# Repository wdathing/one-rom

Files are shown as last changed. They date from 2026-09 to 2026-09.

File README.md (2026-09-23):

# One ROM






**[One ROM](https://onerom.org) - One ROM To Rule Them All**

The most flexible and powerful ROM replacement for your retro computer.  A single Raspberry Pi
RP2350-base board in the footprint of the original chip emulates 24, 28, 32 and
40 pin mask ROMs, EPROMs, EEPROMs, bipolar PROMs and some SRAM — and then does
things the original never could.  It serves several ROM sockets at once, switches
images at runtime, reprograms over USB without leaving the socket, talks back to
the machine it is installed in, and runs your own code as plugins.

Thousands of One ROMs are installed in Commodore 64s, VIC-20s, PETs, Amigas, BBCs, Ataris, TIs, Apple IIs,
disk drives, IBM PCs, pinball machines, drum machines, synthesizers and more.  It is
open source hardware and software, it is cheap to make, and it is actively
maintained and developed.

## New to One ROM?

**Start at [onerom.org](https://onerom.org).**  That is where the project is
explained and supported:

- [What One ROM is and why](https://onerom.org) — the overview, with pictures
- [Getting started](https://onerom.org/start/) — install it, program it, use it
- [Buy one](https://onerom.org/buy) — known vendors, if you'd rather not fab
  your own
- [Program from your browser](https://onerom.org/web) — no software to install

**The rest of this README is for people who want to build One ROM, hack on it,
or build things on top of it.**  If you just want a working ROM replacement, [onerom.org](https://onerom.org) will get you there faster.

## Ways in

One ROM is designed to be extended in many different ways.

| I want to… | Start here | Steps |
|---|---|---|
| Drive a device from scripts or my own tooling | [Programming a One ROM](#programming-a-one-rom), [CLI manual](docs/CLI-MANUAL.md) | Install and run the CLI |
| Fab and assemble existing boards | [hardware/pcb](hardware/pcb/README.md) | Upload gerbers and BOM/POS files to a fab |
| Build the firmware myself | [Building from source](#building-from-source) | Use `make` or the build container |
| Use the header pins as GPIOs — reset the host, drive a line | [Driving the host](#driving-the-host--gpio-and-reset) | One command, plus a wire for host reset |
| Add support for a chip type One ROM doesn't know | [Adding a chip type](docs/ADDING-CHIP-TYPES.md) | A JSON entry plus one line of Rust or a firmware and tooling update if no existing serving algorithm fits |
| Add support for a new board revision | [rust/config/json](rust/config/json/README.md) | A new JSON file once the board is designed |
| Write a plugin — from scratch, or from a working one | [Plugins](#plugins), [firmware/ora/examples](firmware/ora/examples) | C, against a stable API |
| Talk to the retro machine from the ROM socket | [RBCP](#rbcp--talking-to-the-host-system) | 6502 and 68000 host code provided |
| Build host-side tools of my own | [Rust crates](#rust-crates) | Rust, on published crates |
| Read and test real ROM chips | [One ROM Lab](#one-rom-lab) | Flash Lab to a spare Fire board |
| Add a serving algorithm, or change how serving works | [How the firmware works](#how-the-firmware-works) | Bare metal C, PIO and DMA, plus Rust tooling |
| Design a new board | [hardware/pcb](hardware/pcb/README.md) | KiCad |

## Hardware

One ROM comes in two families:

- **Fire** — RP2350, in 24, 28, 32 and 40 pin variants, latest boards include an
  RGB NeoPixel.  All development happens for these boards.
- **Ice** — STM32F4, 24 pin only.  Legacy: still supported with 0.6.x firmware,
  but it is not being enhanced.  The 0.7.x firmware and the CLI do not
  support it.

<div align="center">
    One ROM Fire 24, 28, 32 and 40 pin boards side by side
</div>

<div align="center">
    One ROM Fire 28 with its RGB NeoPixel lit
</div>

All the design files needed to manufacture your own are in
[hardware/pcb](hardware/pcb).  Start with the
[recommended revisions](hardware/pcb/README.md#recommended-revisions) and
read the fabrication notes in the same file before you order.  Boards can be
fabbed and assembled at JLCPCB and other manufacturers cheaply.

<div align="center">
    Three One ROM Fire 24 boards serving BASIC, KERNAL and character ROMs in a Commodore 64
</div>

<p align="center"><em>Three One ROM Fire 24s in a Commodore 64, serving BASIC,
KERNAL and the character ROM.</em></p>

## Programming a One ROM

There are three tools, all doing the same job over USB:

- **[One ROM Web](https://onerom.org/web)** — browser based, nothing to install,
  the best choice for most people.
- **[One ROM CLI](https://onerom.org/cli)** — the full device tool, and what the
  examples below use ([rust/cli](rust/cli)).
- **[One ROM Studio](https://onerom.org/studio)** — native desktop GUI for
  Windows, macOS and Linux ([rust/studio](rust/studio)).

The CLI is the complete interface: everything the device can do is reachable from
it.  Full reference in the [CLI manual](docs/CLI-MANUAL.md).

Find what is connected:

```bash
onerom scan
```

Build an image from a config file and flash it:

```bash
onerom program --config onerom-config/vic20-pal.json
```

Program chips straight from the command line, without a config file, adding the
USB plugin so the device stays on the bus while it serves:

```bash
onerom program --slot file=kernal.901227-03.bin,type=2364,cs1=active-low --plugin usb
```

Build a firmware binary without touching a device, and look inside one:

```bash
onerom firmware build --config onerom-config/vic20-pal.json --board fire-24-e --output /tmp/onerom.bin
onerom firmware inspect --firmware /tmp/onerom.bin
```

Read and write the ROM image live, while the host is running from it:

```bash
onerom peek live --address 0x100 --length 64
onerom poke live --address 0x100 --byte 0xEA
```

## Driving the host — GPIO and reset

The image select and X pads are not just jumpers.  They are GPIOs, and
One ROM will drive them for you — which means the ROM socket becomes a way to
manipulate the machine it is plugged into.

Run a wire from a pad to the host's reset line and you can reset the machine
after flashing a new image:

```bash
onerom control reset --pin sel_c
```

`sel_c` is the usual choice — more boards have it than have X pads, and it is 5V
tolerant where it exists.  Any pad works, named with `--pin`.

<div align="center">
    One ROM Fire 40 in an Amiga A500 ROM socket, with a wire from its Sel_C pad to the 68000's reset line
</div>

<p align="center"><em>A One ROM Fire 40 in an Amiga A500, with <code>Sel_C</code>
wired to the 68000's reset line.</em></p>

You can see what every pin is and what it is currently doing:

```bash
onerom inspect gpio --all
onerom inspect socket --chip-type 2364 --gpio
```

The same GPIOs are available to plugins, so a plugin can drive them
autonomously — hold the host in reset until something is ready, blink an
external LED on ROM activity, or drive whatever you have wired up.

## Plugins

Serving runs entirely on PIO and DMA, so both CPU cores are free.  Plugins are
separate binaries, written in C against a stable API in
[firmware/ora](firmware/ora), that run on those cores *while serving continues*.
Two run at once.  This is how One ROM gains functionality without needing to
fork the core firmware.

There are two types, **system** and **user**.  The difference is resources, not
authorship — each is built for a different flash slot with a different RAM and
stack allocation, and you can write either.  System is intended for official One
ROM plugins such as the USB stack, but nothing stops you replacing it with your
own.

| Plugin | Type | What it does |
|---|---|---|
| [usb](plugins/system/usb) | system | The device's own USB stack, so a running One ROM stays on the bus.  Exposes the ROM being served for live read and write, and the `picobootx` extended PICOBOOT interface. |
| [host-control](plugins/user/host-control) | user | A full [RBCP](#rbcp--talking-to-the-host-system) implementation. |
| [rgb](plugins/user/rgb) | user | Cycles the NeoPixel on RGB boards.  Superseded by the USB plugin's RGB support, reached with `onerom control rgb`. |
| [activity](plugins/user/activity) | user | Blinks the status LED when the host is reading the ROM. |
| [blink](plugins/user/blink) | user | Minimal example. |

The firmware passes each plugin a lookup function at startup.  The plugin calls
it with the ID of the facility it wants, and gets back a function pointer.
Available that way: status LED and GPIO control, device and firmware metadata,
logging, memory allocation, the ROM and RAM slots being served, and the address
monitor that reports what the host is reading — which is what RBCP is built on.
New IDs are only ever added, never changed, and each plugin declares the minimum
firmware version it needs, which the firmware enforces before launching it.

Start with [plugins/README.md](plugins/README.md) for how plugins are built and
configured, [firmware/ora/api.h](firmware/ora/api.h) for the API, and
[firmware/ora/examples](firmware/ora/examples) for worked examples — including
one that patches the C64 kernal live and one that drives an LED from character
ROM accesses.

## RBCP — talking to the host system

The [ROM Bus Control Protocol](https://github.com/piersfinlayson/rom-bus-control-protocol)
is bidirectional communication between a retro machine and the ROM emulator
installed in it, carried over nothing but the ROM's own address and data buses.
No extra wiring.  The machine reads and writes ROM addresses, and One ROM
interprets them.

That opens up things a ROM socket has no business being able to do:

- remote debugging of code running on real hardware
- ROM-based bootloaders — `grub` for the C64
- dynamic patching of games and demos as they run

The device side is the [host-control](plugins/user/host-control) plugin.  The
specification lives in the RBCP repository, along with reference host
implementations for 6502 and 68000 — generic routines plus sample C64 kernal and
Amiga Kickstart bootloaders.

## One ROM Lab

[One ROM Lab](rust/lab/README.md) is alternate firmware for a spare Fire board that turns
its ROM socket into a bus reader and tester.  Flash it, connect over USB, and you
get an interactive shell.

Read a real chip in the socket, as a checksum, a hexdump or Intel HEX.  Verify
that a One ROM under test serves the right bytes and tristates its data lines
when deselected.  Auto-detect chip select polarity on an unmarked mask ROM by
brute-forcing the combinations.  Dump the board's pin map, socket pin to signal
to GPIO.  It is what Fire 40 boards are tested with before they ship.

```bash
cd rust/lab && scripts/flash.sh
```
## Building from source

Dependencies are listed in [INSTALL.md](INSTALL.md), or use the
[build container](ci/docker/README.md).  The ARM and
Emscripten toolchain versions are pinned (`ci/arm-toolchain-version`,
`ci/emscripten-version`), as are the documentation tools that render the PDF
editions (`ci/pandoc-version`, `ci/weasyprint-version`), so a firmware binary is byte-identical wherever it is
built.

Build the base firmware:

```bash
make
```

That produces `firmware/build/onerom-rp235x.bin` — one binary, for every Fire
board.  The ROM images, chip configuration and plugins are composed onto it by
the host-side tools.  To flash *your* build rather than a downloaded release,
pass it explicitly:

```bash
onerom program --config onerom-config/vic20-pal.json --base-firmware firmware/build/onerom-rp235x.bin
```

## How the firmware works

Worth knowing before you go digging in [firmware/](firmware):

**It is fully bare metal.**  No SDK, no HAL — not pico-sdk, not a vendor library.
C with its own startup code and its own linker scripts to keep it lean.

**Serving runs on PIO and DMA.**  The RP2350's PIO state machines watch the
address and chip select lines and DMA the right byte onto the data pins.  The CPU
is not in the critical path, which is what leaves both cores free for plugins.

**The chip type is not compiled in.**  The firmware knows nothing about a 2364 or
a 27C400.  It has a small set of parameterised serving algorithms, and the
host-side generator works out which algorithm and what arguments a given chip on
a given board needs, then writes that into the firmware metadata.

**It is one binary for all boards.**  Board differences are metadata too.

**Bad configuration is visible, not silent.**  An image the firmware cannot make
sense of drops it into limp mode, with an special LED blink pattern.

**The PIO programs are assembled on the device, at boot.**  Which program is
needed depends on the chip, the board's pin mapping and the configuration in
flash, none of which are known at build time.
[apio](https://github.com/piersfinlayson/apio) assembles them in C at runtime,
and disassembles them so a generated program can be read back and checked.

## Regression tested off-hardware

Every push runs the **real firmware C** — the source that ships on devices, not a
model of it — compiled for the host and linked against
[epio](https://github.com/piersfinlayson/epio), a cycle-exact RP2350 PIO
emulator, then driven over emulated bus cycles.

The sweep is hundreds of test runs covering all Fire board revisions, all supported
chip types, every configuration shape the firmware offers — single, banked,
multi-chip, 16-bit — and every chip select polarity combination.  Every address
of every image is compared against an independent copy, which is 10s of
millions of byte-level comparisons, plus checks that the data bus tristates for every
non-selected control line combination.

The plugin API is covered down to all API IDs, and the host-control plugin's own C source is run against a full suite of
conformance tests whose basis is the protocol specification rather than the
implementation.

CS-to-data latency is asserted to the exact cycle in **both**
directions, so serving getting a cycle slower — or a cycle faster, which would
mean the check had stopped discriminating — fails the build.

What it does not do today is anything analogue — voltage levels, bus loading,
propagation delay at a real pin — or USB.  Those need a board, which is what
[One ROM Lab](#one-rom-lab) is for.

## Rust crates

The host-side tooling is a Cargo workspace in [rust/](rust).  The crates marked
published are on crates.io, for host-side Rust development.

| Crate | Published | What it is for |
|---|:---:|---|
| [`onerom-gen`](rust/gen) | ✓ | Generates ROM images and firmware metadata.  The heart of the toolchain — turns a config plus some ROM files into something flashable. |
| [`onerom-config`](rust/config) | ✓ | The config model: chip types, board definitions, pin maps, JSON schema. |
| [`onerom-fw`](rust/fw) | ✓ | Composes a complete firmware image, resolving and fetching base firmware from the release manifest. |
| [`onerom-fw-parser`](rust/fw-parser) | ✓ | Reads metadata back out of a firmware binary — what chips, what board, what version. |
| [`onerom-metadata`](rust/metadata) | ✓ | The embedded metadata schema itself. |
| [`onerom-cli`](rust/cli) | ✓ | Everything the CLI does, minus the command line parsing.  Build on it rather than reimplementing USB device logic. The CLI binary is released at [onerom.org/cli](https://onerom.org/cli). |
| [`onerom-app`](rust/app) | ✓ | Transport-free logic shared by the CLI, Studio and the web tools. |
| [`onerom-studio`](rust/studio) | | The desktop GUI, released at [onerom.org/studio](https://onerom.org/studio). |
| [`onerom-lab`](rust/lab) | | One ROM Lab, above. |
| [`onerom-lens`](rust/lens) | | One ROM Lens — compiles the firmware emulator to WebAssembly and draws PIO and DMA activity as waveforms in a browser, cycle by cycle. |
| [`onerom-fw-emulator`](rust/fw-emulator) | | Compiles and runs the real firmware C on a host, PIOs and all. |
| [`onerom-fw-tester`](rust/fw-tester) | | Drives the emulator with generated configurations and checks the results. |
| [`onerom-plugin-tester`](rust/plugin-tester) | | The harness a plugin tester is built from — runs a plugin's own C against the emulated firmware. |
| [`onerom-rbcp-tester`](rust/rbcp-tester) | | Drives the host-control plugin over emulated ROM bus cycles, as an RBCP host would. |
| [`onerom-usb-tester`](rust/usb-tester) | | Drives the USB system plugin's commands, log forwarding and GPIO control. |
| [`onerom-fw-driver`](rust/fw-driver), [`onerom-fw-geometry`](rust/fw-geometry) | | Pin geometry and GPIO bitmask helpers, shared and dependency-free by design. |
| [`fw-config-gen`](rust/fw-config-gen), [`schema-gen`](rust/schema-gen) | | Code and schema generators. |
| [`doc-gen`](rust/doc-gen) | | Checks the values `docs/` states against the sources that own them, assembles the markdown a multi-part PDF is rendered from, and fills in the fragment regions of the documents in `docs/`. |

For in-browser use, [one-rom-wasm](https://github.com/piersfinlayson/one-rom-wasm)
wraps `onerom-gen` as WASM, and is what the
[browser programmer](https://onerom.org/web) in
[one-rom-site](https://github.com/piersfinlayson/one-rom-site) is built on.

## What is in this repository

| Directory | Contents |
|---|---|
| [`firmware/`](firmware) | The core firmware: C and Thumb assembly, bare metal.  `ora/` is the plugin API. |
| [`plugins/`](plugins) | System and user plugins. |
| [`rust/`](rust) | The Cargo workspace — CLI, Studio, generators, emulator, Lab, Lens. |
| [`hardware/pcb/`](hardware/pcb) | KiCad designs, per board revision, verified and unverified. |
| [`onerom-config/`](onerom-config) | Ready-made JSON configs for some common systems, and the config schema. |
| [`docs/`](docs) | Documentation, including the generated chip and compatibility references. |
| [`ci/`](ci) | Build, test and lint scripts, and the reproducible build container. |
| [`images/`](images) | Test ROM images. |
| [`demo/`](demo) | Demonstration programs for the retro side. |

## Documentation

| Topic | Description |
|---|---|
| [CLI Manual](docs/CLI-MANUAL.md) | Complete reference for the `onerom` command line tool. |
| [Chip Types](docs/CHIP-TYPES.md) | Every chip type One ROM knows about, with pinouts and control lines. |
| [Compatibility](docs/COMPATIBILITY.md) | Which chips each hardware variant can emulate, and at what flash cost. |
| [Adding a Chip Type](docs/ADDING-CHIP-TYPES.md) | Teaching One ROM to emulate a chip it does not yet know. |
| [Image Selection](docs/IMAGE-SELECTION.md) | Telling One ROM which installed image to serve. |
| [Logging](docs/LOGGING.md) | Reading One ROM's log, over USB or with a debug probe. |
| [Image Sets](docs/MULTI-ROM-SETS.md) | Serving several ROMs at once, and dynamic bank switching. |
| [Plugins](plugins/README.md) | Building, configuring and writing plugins. |
| [Build Container](ci/docker/README.md) | Building the firmware reproducibly in Docker. |
| [ROMs Glorious ROMs](docs/ROMS-GLORIOUS-ROMS.md) | Everything you wanted to know about 23/27 series ROMs but were afraid to ask. |
| [Changelog](CHANGELOG.md) | What changed, and when. |

The CLI manual, chip type and compatibility references are also published as
PDFs, in A4 and US Letter, at [onerom.org/docs](https://onerom.org/docs/).

More in [docs/](docs) — flash layout, voltage levels, using a Pi Pico as
an SWD programmer — plus [INSTALL.md](INSTALL.md) for build dependencies and
[LICENSE.md](LICENSE.md).

## Videos

Why use One ROM:

10 reasons to use One ROM (https://www.youtube.com/watch?v=LjKZ0uKzLO4)

The hardware family:

One ROM hardware family (https://www.youtube.com/watch?v=GAh021jgGgs)

## Related repositories

| Repository | What it is |
|---|---|
| [rom-bus-control-protocol](https://github.com/piersfinlayson/rom-bus-control-protocol) | The RBCP specification, and 6502/68000 reference host implementations. |
| [one-rom-site](https://github.com/piersfinlayson/one-rom-site) | onerom.org, including the browser programmer. |
| [one-rom-images](https://github.com/piersfinlayson/one-rom-images) | images.onerom.org — firmware images, configs, plugin manifests. |
| [one-rom-wasm](https://github.com/piersfinlayson/one-rom-wasm) | WASM build of `onerom-gen`, for in-browser firmware generation. |
| [picoboot](https://github.com/piersfinlayson/picoboot) | Host-side Rust crate for the RP2350 PICOBOOT USB interface. |
| [picobootx](https://github.com/piersfinlayson/picobootx) | Device-side PICOBOOT extension, exposed by the USB plugin. |
| [apio](https://github.com/piersfinlayson/apio) | Runtime RP2350 PIO assembler and disassembler. |
| [epio](https://github.com/piersfinlayson/epio) | Cycle-exact RP2350 PIO emulator. |

## Problems

Raise an issue at the [project issues page](https://github.com/piersfinlayson/one-rom/issues)
or start a thread at [GitHub Discussions](https://github.com/piersfinlayson/one-rom/discussions).
Please include:

- your One ROM PCB type and revision (or a photo if you're unsure)
- the retro system you are using it with
- details of the problem.

## Contributing

Pull requests are welcome — firmware, tools, hardware and documentation.  If you
write a plugin you think others would want to use, consider contributing it
so it can be published.  The plugins publishing process is documented in
[plugins/CONTRIBUTIONS](plugins/CONTRIBUTIONS.md)

## License

See [LICENSE](LICENSE.md) for software and hardware licensing information, and
[ACKNOWLEDGEMENTS](ACKNOWLEDGEMENTS.md) for third party work One ROM builds on
or is compatible with.

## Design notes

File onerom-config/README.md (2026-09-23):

# ROM Configs

A config is a JSON file naming the ROM images a One ROM serves and, per set, any firmware settings that differ from the defaults.  Studio and the CLI build a complete flashable image from it, and the CLI and Web programmer use it internally to create firmware from per-slot configuration.

| Reader | Use |
| --- | --- |
| [One ROM Studio](https://onerom.org/studio) | Pick a published config or local config file, build, flash |
| `onerom` CLI | `onerom program --config <file>` and `onerom firmware build --config <file>`, see [CLI-MANUAL.md](/docs/CLI-MANUAL.md) |

The format is defined by [schema.json](schema.json), also published at https://images.onerom.org/configs/schema.json.  [json-schema.app](https://json-schema.app/view/%23?url=https%3A%2F%2Fimages.onerom.org%2Fconfigs%2Fschema.json) renders it readably.

## What is here

| Path | Contents |
| --- | --- |
| `*.json` | Published configs.  `set-` holds several jumper-selected sets, `bank-` bank-switched sets, `28-` targets 28-pin boards. |
| `blank.json` | No ROMs.  Flashes a One ROM that ships empty. |
| `test/` | Configs CI builds and tests on hardware (`ci/test-emu.sh`). |
| `user/` | Your own configs.  Git-ignored. |

## A config

```json
{
    "$schema": "https://images.onerom.org/configs/schema.json",
    "version": 1,
    "name": "Simple Config",
    "description": "Two 2364 ROMs, selected by jumper",
    "chip_sets": [
        {
            "type": "single",
            "chips": [
                {
                    "description": "ROM 1",
                    "file": "http://example.com/rom1.bin",
                    "type": "2364",
                    "cs1": "active_low"
                }
            ]
        },
        {
            "type": "single",
            "chips": [
                {
                    "description": "ROM 2",
                    "file": "http://example.com/rom2.bin",
                    "type": "2364",
                    "cs1": "active_low"
                }
            ]
        }
    ]
}
```

- Each set is one image-select jumper position, the first with all jumpers open: [IMAGE-SELECTION.md](/docs/IMAGE-SELECTION.md).
- `multi` and `banked` sets serve several chips at once: [MULTI-ROM-SETS.md](/docs/MULTI-ROM-SETS.md).  [set-vic20-pal.json](set-vic20-pal.json) and [bank-c64-char.json](bank-c64-char.json) are real examples.
- Chip types, 24 to 40 pins and RAM, and the select lines each takes: [CHIP-TYPES.md](/docs/CHIP-TYPES.md).  27-series EPROMs need no select lines.
- The older `rom_sets` and `roms` keys still parse.

### Top-level keys

| Key | Meaning |
| --- | --- |
| `version` | Format version, `1`. |
| `description` | Required.  Shown by the builder after `name`. |
| `name`, `detail`, `notes` | Optional text shown by the builder, `notes` after the set list. |
| `categories` | Tags Studio groups and searches on. |
| `instance_name` | A name for this One ROM. |
| `serial_override` | Replaces the USB serial number. |
| `turbo_boot` | Skip reading the jumpers and serve the first image. |
| `boot_logging` | Log boot over USB (with the USB plugin) or RTT. |
| `swd_enabled` | `false` shuts SWD off as ROM serving starts, so debug-port reads cannot steal cycles from the serving DMAs.  BOOTSEL and PICOBOOT are unaffected. |

### Per-set keys

| Key | Meaning |
| --- | --- |
| `type` | `single`, `multi` or `banked`. |
| `description` | Shown by the builder. |
| `chips` | The chips in the set.  Order sets the X-pin assignment in a `multi` set. |
| `firmware_overrides` | Firmware settings for this set, below. |

### Per-chip keys

| Key | Meaning |
| --- | --- |
| `file` | Path or URL. |
| `type` | Chip type, e.g. `2364`, `27256`, `6116`. |
| `cs1`..`cs4`, `ce`, `oe` | `active_low`, `active_high` or `ignore`, for the lines the chip type has.  `allow_cs_ignore: true` permits `ignore` where the chip type does not explicitly allow it. |
| `description`, `label` | `label` replaces the filename in the device metadata. |
| `license` | URL the builder asks the user to accept first. |
| `extract` | Path inside the archive when `file` is a zip or tar. |
| `location` | `start` and `length` of the image inside a larger file. |
| `format`, `load_address` | `ihex` decodes Intel HEX, `load_address` mapping to byte 0. |
| `transform` | Byte transforms applied in order, see [Image transforms](/docs/CLI-MANUAL.md#image-transforms). |
| `size_handling` | `duplicate`, `pad` or `truncate` when the image is not the chip's size. |

Windows paths take doubled backslashes (`"C:\\roms\\kernal.bin"`) or forward slashes.

## Firmware overrides

Fire (RP2350) boards only.  Each set carries its own, and a set without one uses the firmware defaults.

| Key | Meaning |
| --- | --- |
| `fire.cpu_freq` | Default `150MHz`.  Above that, set `overclock: true`. |
| `fire.overclock` | Permits a frequency above the rated maximum. |
| `fire.vreg` | Core voltage, e.g. `1.20V`.  Left out, the firmware picks a conservative value for the frequency. |
| `fire.force_16_bit` | Combined 8/16 bit ROM types.  Ignores `/BYTE` and serves 16 bits always, which reads the address lines a third more often. |
| `led.enabled` | `false` turns the status LED off while serving.  Limp mode still blinks it. |
| `swd.swd_enabled` | As the top-level key, for this set. |

```json
"firmware_overrides": {
    "fire": {
        "cpu_freq": "200MHz",
        "overclock": true,
        "vreg": "1.15V"
    },
    "led": {
        "enabled": false
    }
}
```

A frequency the PLL cannot hit is rounded to the nearest it can.  A setting the firmware cannot recover from puts the device in limp mode, blinking the status LED.  Change the setting and reflash, or read the boot log: [LOGGING.md](/docs/LOGGING.md).

## Checking a config

Build the image without a device attached:

```bash
onerom firmware build --config user/mine.json --board fire-24-e --out /tmp/onerom.bin
```

## Publishing a config

Studio lists every config in `configs.json` at [one-rom-images](https://github.com/piersfinlayson/one-rom-images), sorted by name with Blank first.

1. Add the file here and commit.
2. Copy it to `one-rom-images/configs/`.
3. Add `"configs/<name>.json"` to the `configs` list in `one-rom-images/configs.json`.
4. Push `one-rom-images` main.  GitHub Pages deploys it.

When `schema.json` changes, the copy in `one-rom-images/configs/` goes with the release.

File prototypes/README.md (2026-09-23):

# Prototypes

Apps built to answer a specific question. Nothing here is expected to ship, and
nothing in the tree depends on it.

Each is excluded from the `rust/` workspace by an empty `[workspace]` table in
its own `Cargo.toml`, so a workspace-wide `cargo` command does not build it.

- [`studiov2/`](studiov2) — Tackle One ROM Studio v2 on Iced questions.

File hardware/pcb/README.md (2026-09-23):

# PCB Files

Contains One ROM PCB design files.  These are organised into two directories:

- [`verified/`](verified/README.md) - Verified designs that have been tested and work.
- [`unverified/`](unverified/README.md) - Unverified designs that have not been tested.

Before using any of the designs, review the hardware [LICENSE](/LICENSE.md#cern-ohl-w-20-license) and [NOTICE](/hardware/NOTICE) files.

## Recommended Revisions

Last Updated 8th September 2026.

The following table lists the recommended verified designs.  Each design has been manufactured and assembled using JLCPCB's PCB assembly service, and verified to work correctly.

| Model | MCU | Pins | USB | SWD | Image Select Pins | X Pins | RGB | PCB |
|---|-----|---|-----|-----|---|---|-----|---|
| Fire  | RP2354A | 24 | C | ✓ | 4 | 2 | ✓ | [fire-24-f](./verified/fire-24-f/README.md) |
| Fire  | RP2354A | 24 | C (upright) | ✓ | 4 | 2 | ✓ | [fire-24-g](./verified/fire-24-g/README.md) |
| Fire  | RP2354B | 28 | C | ✓ | 4 | 2 | ✓ | [fire-28-c](./verified/fire-28-c/README.md) |
| Fire  | RP2354B | 28 | C (upright) | ✓ | 4 | 2 | ✓ | [fire-28-d](./verified/fire-28-d/README.md) |
| Fire  | RP2354B | 32 | C | ✓ | 4 | n/a | ✓ | [fire-32-b2](./verified/fire-32-b2/README.md) |
| Fire  | RP2354B | 32 | C (upright) | ✓ | 4 | n/a | ✓ | [fire-32-c](./verified/fire-32-c/README.md) |
| Fire  | RP2354B | 40 | C | ✓ | 4 | n/a | ✓ | [fire-40-b](./verified/fire-40-b/README.md) |
| Fire  | RP2354B | 40 | C (upright) | ✓ | 4 | n/a | ✓ | [fire-40-c](./verified/fire-40-c/README.md) |

**One ROM 28C onwards, 32 and 40 require components on the top and bottom of the PCB**

There may be later, unverified, revisions not in the list above.  These may have improvements over the recommended revisions, but they have not been verified to work.  If you want to use one of these later revisions, read the relevant README before ordering.

## Alternative Components

Sometimes your PCB manufacturer/assembler may be out of stock of a particular component.  This section lists some reasonable alternatives, using LCSC/JLC part numbers.

| Original Component | Original LCSC/JLC Part Number | Alternative Component | Alternative LCSC/JLC Part Number | Verified? | Notes |
|-|-|-|-|-|-|
| Diodes Inc AP2112K-3.3TRG1 | C51118 | Tech Public AP2112K-3.3TRG1 | C23380830 | Yes | Jelly bean part, same specs |
| Uniroyal 0201WMF1002TEE | C473048 | Yageo RC0201FR-0710KL | C106225 | No | Jelly bean part, same specs |
| Samsung CL03A104KO3NNNC | C307380 | Murata GRM033Z71C104KE14D | C668346 | Yes | 0.1uF decoupler.  X7R rather than X5R - this is the part used on all boards fabbed to date. |

The RP2354B can be replaced with the RP2350B _if the design supports external flash and it is populated with the correct resistors present/missing_.

Some designs, such as fire-40-c, have hardware support for both external flash plus an RP2354B, so two lots of flash.  Fabricating this option requires the correct 0R resistors to be populated/not populated.  See the board schematic for more details.

**The external flash option has not been tested on the current recommended designs.**

In some cases, alternative BOM/POS files are already provided for some alternative components.  In other cases, you may need to edit the BOM/POS files yourself to substitute the alternative component.  _Always_ double check component values, part numbers and placement before ordering.

## Notes on Fabrication

All recommended designs have been manufactured and assembled using JLCPCB's PCB assembly service.  The gerbers and BOM/POS files in each revision's `fab/` directory are compatible with JLCPCB's requirements.

Some variants offer multiple sets of BOM/POS files or different combinations of components.  Read the relevant revision's README for details.

You need to exercise care when submitting the order to ensure the correct options are selected.  In particular:

- Select economic assembly, not standard assembly, for cost reasons, if available for your choice of board.
- Use standard 1.6mm PCB thickness.  You probably want HASL with lead finish for cost reasons.
- You have to select the desired PCB colour as part of the PCB ordering process.  Red is recommended for Fire and blue for Ice.
- As of late 2025 you no longer need to remove JLC's order ID from the PCBs, but it is worth checking this is still the case when you place your order.
- When selecting assembly choose either top or top + bottom depending on whether your chosen design has parts on the bottom.
- After uploading the BOM and position files for assembly, you need to ensure all parts are available and checked.
- You must ensure JLC is showing the correct orientation for all components.  There are silkscreen markings for pin 1 on all ICs and polarized components - ensure this matches the pink dot of the component in the viewer.  Also ensure the USB connector is the correct orientation.
- ** Make sure you check the bottom if components are supposed to be there. **

Occasionally, some chosen parts are out of stock on JLCPCB.  One ROM has been designed with extremely common parts where possible, which JLC tend to hold large stocks of.  However, if a part is unavailable you may need to select an alternative part.  Ensure the alternative part has the same footprint and electrical characteristics (e.g. capacitance, voltage rating, etc) as the original part.  If in doubt, query within github discussions for advice. 

JLC may raise an issue with you after submitting your order.  Common issues include:
- JLC may ask to add side rails with stamp holes, to help with the PCB assembly process.  While One ROM has been successfully fabbed without these, if JLC recommends them it is best to accept this change, as otherwise they may not warrant the assembled boards.  The side rails can be snapped off using the "mouse bites" (stamp holes) after assembly.  JLC may or may not accept replacing stamp holes with v-score - as v-score is not available on their economic service.

If in doubt, query within github discussions for advice.

Assembly errors:
- Ice boards have rarely, if ever, experienced assembly errors.
- The first few batches of Fire boards experienced some assembly issues, particularly with respect to the RP2350 MCU solder pad fillets.  More recent boards and orders have been without issue.  It is unclear whether differences in the later PCBs or improvements in JLC's assembly process are responsible for this improvement.  If you do experience assembly issues, raise with JLC support.  It would also be interesting to hear on github discussions what issues you experienced, so others can be aware.

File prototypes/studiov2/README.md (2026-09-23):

# Studio v2 prototypes

Iced prototypes for a One ROM Studio v2: whether it would look right, whether
it can handle device log output, and how a growing app should be laid out.
They build against this tree's crates.

- [`slot-builder/`](slot-builder) — the website's multi-slot ROM image builder,
  rebuilt in Iced. Answers whether the design survives the toolkit.
- [`log-viewer/`](log-viewer) — log and console panes. Answers whether text can
  be selected and copied, and what a long log session costs.
- [`shell/`](shell) — both of the above in one window. Answers what state two
  screens genuinely share and what it costs where they meet.
- [`shared/`](shared) — the log store, the palette and the shared state types.
  Everything more than one screen reads.

[`REPORT.md`](REPORT.md) is the investigation these came out of — why Iced, what
each prototype proved, and what is still open.

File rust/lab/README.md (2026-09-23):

# One ROM Lab

Alternate firmware for a One ROM **Fire** (RP2350) board that turns its ROM
socket into a parallel bus reader and tester.  Flash it to a spare board, connect
over USB, and drive it from an interactive shell.

Two things it is used for:

- **Reading real chips** — mask ROMs, EPROMs and EEPROMs sitting in the socket,
  output as a checksum, a hex dump or Intel HEX.
- **Testing a One ROM under test** — checking it serves the right bytes at speed
  and tristates its data lines when deselected.  This is how Fire 40 boards are
  tested before shipping.

Fire only.  Lab refuses any board whose MCU is not an RP2350.

## Build and flash

The board is put into BOOTSEL, then `picotool` loads over USB:

```bash
scripts/flash.sh                # board set at runtime, with B:<board>
scripts/flash.sh fire-40-a      # bake in a default board
```

The argument is a **board** name, not a chip type.  A single binary reads every
chip type the board supports, so the only reason to bake in a board is
convenience.

The `z` command reboots back into BOOTSEL, so reflashing never needs the button.

## picotool

A running Lab answers `picotool`, so you can ask a board what it is and put it
where you want it without opening a terminal or touching the button.  Lab keeps
One ROM's vendor and product id, which picotool takes as arguments:

```bash
picotool info -a --vid 0x1209 --pid 0xf542
```

**Which board is this?**  On a bench with more than one, `info` names the
firmware and its version, and prints the chip id, package and revision of the
board you are pointed at, while Lab carries on running:

```text
Program Information
 name:          One ROM Lab
 version:       0.3.0
 description:   Use the One ROM hardware to read ROMs
```

**Reflash it.**  Two commands, no jumper and no button, and they work whether or
not the shell is answering:

```bash
picotool reboot -u --vid 0x1209 --pid 0xf542
picotool load -t elf ../target/thumbv8m.main-none-eabihf/release/onerom-lab-fire
```

The first drops the board into its bootloader, where the second finds it as a
stock RP2350 and needs no arguments.  This is the way back from a Lab whose
shell has stopped answering, where `z` cannot help.

A reboot asked for this way says so on the terminal before the board goes, so a
session that ends mid-sentence is explained rather than looking like a fault.

**Read what is on it.**  `picotool save` copies flash, SRAM or boot ROM off the
board — the same three regions its own bootloader serves — which is how you look
at what a running Lab is holding.

Writing flash, erasing flash and OTP are refused while Lab runs, so a host
pointed at the wrong board cannot overwrite it mid-measurement.  That is a guard
against accident, not against intent: the reboot above leaves the board in a
bootloader that serves all three.

## Connect

Lab presents a USB CDC serial port.  Connect at 115200:

```bash
scripts/serial.sh /dev/cu.usbmodem1103
```

Lab greets you as your terminal opens the port:

```text
----- One ROM Lab -----
One ROM Lab fire-40-a v0.3.0
Serial: 62CD9AE3C0771A7E
-----------------------
Type ? for help.
```

The board line appears once a board is set.  You then get a `> ` prompt, with
line editing, arrow keys and a 16 entry command history.

Any keystroke stops a running command, as does a break from your terminal.

Closing the terminal ends the session, and reopening it starts a new one and
greets you again — with the board, chip type and output format you had set still
in place.

A terminal configured not to raise DTR sees nothing on opening the port.  Press
Enter and the greeting follows.

## Commands

Each command is a single letter, optionally followed by colon-separated
arguments.  Give the command alone and it prompts for what it needs, remembering
your last answer.

```text
  B   Set One ROM Lab board type            B:<board>
  r   Read ROM                              r[:<chip>[:<start>[:<len>[:<fmt>[:<cs1>[:<cs2>[:<cs3>]]]]]]]
  b   Batch ROM read                        b[:<chip>[:<start>[:<len>[:<fmt>[:<secs>[:<cs1>[:<cs2>[:<cs3>]]]]]]]]
  i   Chip type information                 i[:<chip>]
  c   Set or change chip type               c:<chip>[:<cs1>[:<cs2>[:<cs3>]]]
  f   Set or change output format
  t   Toggle tri-state testing during checksum mode on and off
  q   Quick read (uses default chip, range and format)
  l   List chips supported by this board type
  v   Display One ROM Lab version and hardware information
  s   Display settings
  p   Show board pin map (socket pin -> GPIO)   p[:<chip>]
  T   List supported board types
  z   Reset to bootloader
  ?/h This help
```

Formats are `cs` (checksum and SHA1, the default), `hex` (hex dump), `ihex`
(Intel HEX) and `srec` (Motorola S-record).  Addresses are decimal unless
prefixed `0x`, `0X` or `$`, and `len=0` means to the end of the ROM.

Commands are case sensitive — `B` sets the board, `b` starts a batch read.

## Chip select polarity

Mask ROM chip selects are mask-programmed, so an unmarked chip may need any
combination.  Pass `0` for active low, `1` for active high, or **`?` to
auto-detect**:

```text
r:2364:0:0:cs:?
```

Lab then reads the chip once per combination and flags the ones that produced
something other than all `0x00` or all `0xFF` as `*** candidate ***`.

## Tri-state testing

In checksum mode, with `t` enabled, Lab drives each of `/OE` and `/CE` high
independently and checks the data lines float — detected via the reader board's
internal pull-downs.  The timing here is deliberately relaxed, to cope with weak
pulls and the capacitance of the test setup.  Failures should be zero.

For a 16-bit capable chip, Lab reads in both 8-bit and 16-bit modes and both the
SHA1 and the 32-bit summing checksum should match.

## Pin map

`p` prints the board's socket pin to signal to GPIO mapping, including the X
header, which is the fastest way to work out what is wired where when debugging
hardware.  On Fire 32 and 40 boards, where socket pins are twinned across two
GPIOs, `p` deliberately shows both even though the reader drives only the first.

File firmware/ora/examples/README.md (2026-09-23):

# Plugin Examples

This directory contains some simple example One ROM plugins.

| Example | What it does |
| --- | --- |
| [blink](blink) | Blinks One ROM's status LED |
| [hello](hello) | Logs a message in a loop |
| [log-write](log-write) | Claims a log channel and writes raw bytes to it |
| [c64-char-led](c64-char-led) | Watches C64 character ROM accesses and drives the status LED |
| [c64-kernal-mod](c64-kernal-mod) | Rewrites the C64 kernal boot banner in response to a knock sequence |

Plugins written to test the plugin API on a device, rather than to show how it
is used, live in [tests](../tests/README.md).

## Pre-requisites

### Linux

For Ubuntu/Debian:

```bash
sudo apt -y install build-essential gcc-arm-none-eabi
```

### macOS

Using [Homebrew](https://brew.sh/):

```zsh
brew install --cask gcc-arm-embedded
```

## Building

To build the examples as user plugins:

```bash
make
```

To build them as system plugins:

```bash
make PLUGIN_TYPE=SYSTEM
```

## Using

Once built, configure the plugins as One ROM slots.  For example:

```bash
onerom program --slot file=examples/hello/build/plugin_system.bin,type=system_plugin \
               --slot file=examples/blink/build/plugin_user.bin,type=user_plugin \
               --slot file=some-rom.bin,type=27128
```

The first plugin prints "Hello One ROM" to RTT logging once the system has booted, and the other blinks One ROM's status LED.

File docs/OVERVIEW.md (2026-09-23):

# One ROM Overview

## Background - ROM Replacements

ROM (Read-Only Memory) chips are used in a huge assortment of electronic
devices to supply those systems with pre-programmed data - Operating System
and BIOS images, character sets, programming languages, games, etc.  On old
systems these sometimes fail and need replacing, or users would like to
upgrade their system, by replacing with a ROM with newer data.  The original
ROM chip is removed from the system and a replacement is installed in its place.

Traditional ROM replacements are built around EPROMs, EEPROMs and flash chips.
Those are similar devices to the ROM being replaced - that is dumb devices
that have a persistent memory store and some control lines - but with higher capacity
than the original ROM and/or different chip select behaviour.  The chip
select logic is typically fixed with additional on-board logic.

## Introduction to One ROM

One ROM takes a different approach - it consists of a microcontroller paired
with flash and RAM, physically laid out on a PCB so that the original ROM's
address, data and chip select lines connect to the MCU's general-purpose
input/output (GPIO) pins.  This makes One ROM a ROM emulator, also known as a
Software Defined ROM.

Firmware is loaded to One ROM's flash, along with the ROM image(s) to be
served.  One ROM is installed in the system.  On power on, it boots and first
loads and runs its firmware, and then loads the ROM image(s) to be served into
RAM, and serves them from there.

Because One ROM is microcontroller based, it is controlled by software rather
than by hardwired, hardware-based logic.  This makes One ROM the most powerful
and flexible ROM replacement available.   Nearly any original ROM of a
particular form factor can be replaced by an equivalent One ROM.

One ROM's software is open source and has a modular architecture with a rich
plugin API.  This means One ROM is a platform that can be extended with new
capabilities, not just a ROM replacement.  Some examples of ways in which
people have extended One ROM include:

- A comprehensive USB stack and interface to allow One ROM to be managed
  while running, built on the public plugin API.
- Communication between a retro system and a PC using One ROM's USB port.
- A retro system controlling its own reset line using one of One ROM's header
  pins.
- Reprogramming One ROM dynamically as part of a car's ECU tuning process.

## Hardware

One ROM comes in multiple physical variants to support each supported ROM package
size - 24, 28, 32 and 40 pin.  All One ROMs replace original 600 mil (15.24mm)
wide DIP packages.  The supported ROM types are listed in
[COMPATIBILITY](/docs/COMPATIBILITY.md).  Each pin variant has multiple hardware
revisions, marked on the board.

One ROM Fire, based on the RP2350 microcontroller, is the current family and is
available in all four sizes.

One ROM Ice is a deprecated 24 pin only family based on an STM32F4.  It is
supported on Base Firmware v0.6.x.  New feature releases for One ROM Ice are not
anticipated.

## Important concepts

- **Base Firmware** - a binary including the core code that causes a One ROM to
  serve ROM images.  Does not include any information about the One ROM hardware
  variant or the ROM images to serve.  Should not be used on its own to program
  a One ROM device.

- **ROM image** - a binary blob that is the contents of a ROM to be served.  Can
  be supplied to the programming tool as a raw binary file, or in other formats,
  including Intel HEX and Motorola S-record.  The programming tool converts the
  ROM image to the format One ROM requires.

- **Slot** - a region of One ROM's flash holding a single ROM image, set of ROM
  images, or plugin.

- **Image selection** - the choice of which ROM image a One ROM serves.  A One
  ROM can hold multiple images, selected at boot using the image select jumpers
  on the board.

- **Configuration** - the description of what a One ROM should do, provided to
  the programmer.  It names the ROM images to serve, the chip type and chip
  select behaviour of each, and any settings.

- **Programmer** - a tool that composes ROM images, configuration, Base Firmware
  and metadata into a complete image, and flashes it to the device.  There are
  three - the [web programmer](https://onerom.org/web), the
  [CLI](https://onerom.org/cli) and [Studio](https://onerom.org/studio).

- **Metadata** - a binary block that describes the hardware properties of a
  physical One ROM device, and the properties of the ROM images to be served.
  The programmer generates this metadata from the configuration provided, and
  it is included in the firmware that is flashed to the device.

- **Bootloader** - a small program contained in One ROM's own read-only memory
  that allows One ROM to be reflashed with new firmware and metadata.  The
  bootloader is always accessible, even if the firmware and metadata are
  corrupted or missing and, because it is ROM based itself, it cannot be
  corrupted or erased.

- **Header pins** - pins on the One ROM board exposing power, ground, the image
  select lines, the debug interface and spare pins for expansion.  They allow
  One ROM to be wired to the system it is installed in, or to external hardware.

- **Plugin** - a binary blob consisting of code that extends One ROM's
  capabilities beyond those provided by the core firmware.  The most common
  plugin is the System Plugin.  A user chooses which plugins to include in
  their firmware (if any) at programming time.  Up to two plugins can be
  included with a single One ROM firmware image - the System Plugin, and a
  User Plugin.

- **System Plugin** - a plugin that provides a USB stack and other capabilities
  to One ROM.  One ROM's System Plugin is shipped alongside One ROM's Base
  Firmware.  Its use is recommended for all users, except those who want to
  replace it with their own custom, replacement plugin.

- **User Plugin** - a plugin installed alongside the System Plugin providing
  additional capabilities to One ROM.  User Plugins can be developed by anyone,
  and a number of them are shipped alongside Base Firmware and System Plugin.
  User Plugins require a System Plugin to be included.  An example User Plugin
  is One ROM's Host Control plugin, which allows One ROM to be controlled by the
  system it is installed in, with no extra wiring using the ROM Bus Control
  Protocol (RBCP).

- **Setting** - a named value that changes how a One ROM behaves rather than
  what it serves.  Settings are configured by the user and written by the
  programmer.  The status LED and the CPU frequency are example settings
  supported by the Base Firmware.  Plugins may have their own settings.

- **ROM Bus Control Protocol (RBCP)** - a
  [protocol](https://github.com/piersfinlayson/rom-bus-control-protocol) that
  allows ROM emulators like One ROM to be controlled by a system it is
  installed in, with no extra wiring.  Supported by One ROM's Host Control plugin.

- **Bricked One ROM** - a One ROM device that is non-functional because it has
  been flashed with corrupted firmware or metadata, metadata for a different
  physical One ROM device, no metadata, or firmware or metadata with some other
  issue.  Bricked One ROMs can be recovered by entering One ROM's bootloader
  and reflashing them with valid firmware and metadata.  It is very unlikely
  that a bricked One ROM cannot be recovered.

## Types of One ROM Deployments

### Minimal

Consists of:

- Base Firmware
- Metadata
- At least one ROM image

Contains no plugins.  Serves the ROM image(s) to the system it is installed in,
but cannot be managed while running.

In this deployment type, when One ROM is plugged in via USB it drops
automatically into its bootloader, allowing the device to be reprogrammed, and
simultaneously stops serving the ROM image(s) to the system it is installed in.

### Standard

A Minimal Deployment plus One ROM's System Plugin, which includes a USB stack
enabling comprehensive management of the device while it is running.

This is the recommended deployment type for most users.

### Extended

A Standard Deployment plus a User Plugin.  The User Plugin may be One ROM's own,
or one written by a third party.

### Custom

A Custom Deployment is one where one or more of the following holds:

- The physical One ROM device is not manufactured from a
  [published design](/hardware/pcb/README.md).  It may be a derivative, or a
  fully custom design.

- The Base Firmware is a fork of or replacement for One ROM's Base Firmware.

- The System Plugin is replaced with a fork of or replacement for One ROM's
  System Plugin.

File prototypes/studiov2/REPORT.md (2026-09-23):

# One ROM Studio v2 — decision and plan

Investigation of the CLI, Studio, Web and the desktop GUI toolkits, plus two
working prototypes. August 2026.

**Decision: build on Iced.** Native desktop, Mac/Windows/Linux with Linux first
class, offline, Rust throughout, signed and notarised as today. Day one replaces
what Studio does now over Fire USB — no Ice, no SWD — and adds a multi-slot
builder UI as the main programming path.

---

## H. What the investigation found

**H1. Studio does less than it appears, so day one is a small target.** Its whole
device vocabulary is three verbs: read flash words, flash an image, reboot.
Nothing in `rust/studio/src/` mentions picobootx, LEDs, GPIO, memory writes,
erase or CDC. The in-app config builder is unreachable — the entry that opens it
is commented out at `src/config.rs:150` — and its emitter writes
`"cs0" = "active_low"`, an `=` where JSON needs a `:` (`config.rs:401-418`).
Three screens work: analyse a device or file, build from someone else's config
JSON, view the log.

**H2. Studio's trouble was its own code, not Iced.** It calls `Task::none` 68
times and `Task::then`/`and_then` zero times — Iced's async composition goes
unused, and the app hand-builds state machines through the message loop. 31
functions, including the lowest-level USB reads, return the GUI's `AppMessage`,
so no device code is callable outside Iced. The whole model, up to a `Vec<u8>`
flash image, is deep-cloned on every message (`app/mod.rs:156`). The prototypes
avoided all three without fighting the framework.

**H3. The CLI's library already covers the device surface. The orchestration is
missing.** `onerom_cli`'s library is 7.3 kLOC across 18 modules and gives a GUI
`enumerate_devices`, `read_device_info`, `read_memory`, `write_memory`,
`flash_program`, `flash_program_read`, `flash_erase`, `reboot`, `set_led`,
`set_rgb`, `gpio_set`, `gpio_query`, `pulse`, CDC log streaming, the `--slot`
grammar with config-JSON generation, and plugin logic via `onerom-app`. Welded
into the binary: the compose-and-program pipeline (`src/firmware.rs`,
`src/program.rs`) and every interactive confirmation, which reads stdin inside
functions a GUI would call. Studio has this library and uses three items from it.

**H4. Sharing a frontend with Web buys little.** Of the site programmer's 4,033
lines of JS, about 10% survives as-is, 35% is deleted because Rust already does
it, and 40% is rewritten because it is `alert()`-and-DOM orchestration with no
state model. What survives is the CSS and markup. WebUSB does not port to any
webview except Electron's.

---

## K. Why the other toolkits are out

- **K2 Tauri.** WebKitGTK composites the whole webview through DMABUF/GBM/EGL, so
  when that path fails against a driver it renders nothing. Failures cluster by
  NVIDIA driver and Wayland, not by what the app draws. Tauri's own maintainer
  says he cannot recommend it for Linux. Closed on Linux risk.
- **K3 Electron.** Bundled Chromium removes the Linux problem and costs a Node
  tree, 150-200 MB idle, a packaging rewrite and a rebuild obligation driven by
  other people's OS releases. Closed on prior experience.
- **K4 Slint.** Own renderer, real accessibility, declarative markup. Closed on
  its licence lanes — GPLv3 binaries or royalty-free with attribution — and on
  adding a third language.
- **K5 cef-rs.** The only Rust-owns-the-process option with one engine
  everywhere. A binding, not a framework: no IPC, no updater, no installer
  generation, and macOS signing rewritten for CEF's helper-process bundles.
  Nobody ships a conventional desktop app on it.
- **Ruled out earlier.** egui, on a documented full re-layout of large scroll
  areas every frame. Dioxus, mid-migration to a beta renderer with no
  notarisation story. GTK4, no Windows accessibility. CXX-Qt, pre-1.0 with QML as
  a fourth language. Verso and Blitz, not ready. Sciter and Ultralight, closed
  source.

**Iced's own costs, accepted.** No accessibility at all, issue #552 open since
2020. No stylesheet, so every widget carries its style explicitly. No
letter-spacing. Upstream is effectively one maintainer, though the sub-crates do
get patches — `iced_widget` is at 0.14.2 against the facade's 0.14.0.

---

## Q. The two prototypes, and how to run them

Both live under `prototypes/studiov2/`, each kept out of the `rust/` workspace by
an empty `[workspace]` table in its own `Cargo.toml`. No tracked file was
changed to add them. Each carries a short README.

**Q1. Slot builder — `prototypes/studiov2/slot-builder/`**

```
cd prototypes/studiov2/slot-builder && cargo run
```

Reproduces the site's One ROM Builder tab: board picker, firmware version, the
board wireframe and jumper legend drawn on a canvas, slot cards with per-chip
control lines, the live flash usage bar, plugin pickers, build and save.

It is not a mock. Board list, jumper header geometry, chip types, chip sizes,
how many chip-select dropdowns each chip type gets, file formats and the flash
total all come from `onerom-config` and `onerom-gen`. Build runs through
`Builder::from_json` and produces metadata and ROM images with the real USB
plugin binary embedded.

Two gaps worth carrying forward. **Build output is metadata and ROM images — a
flashable image also needs the base firmware downloaded and padded to 48KB on
the front.** **ROM types come out in the crates' order, not the website's**,
because the website sorts them in `js/site/utils.js` with a hand-written size
table. That sort belongs in Rust, reachable from the apps and from WASM. It is
one visible case of a wider question — how much of that JS is logic that should
sit in Rust.

Also faked: firmware versions are a hardcoded list rather than a manifest fetch,
the plugin catalogue is read off disk so no `min_fw_version` check runs, and
there is no licence-acceptance step. No device I/O at all.

About 1,200 lines of UI and drawing, 300 of them the wireframe. The JS
equivalent is roughly 1,100 lines of JS plus 90 of HTML and 480 of CSS. Clean
build 58s, incremental 2.6s.

Against the HTML: Iced has no letter-spacing, so the small-caps group titles are
untracked, and there are no tooltips or transitions. Dropdowns and scrollbars are
Iced's rather than the platform's. Fonts are close but not exact.

For review without a screen-recording grant: `ONEROM_SPIKE_SHOT` is a path to
write a screenshot to, `ONEROM_SPIKE_SIZE` is `WIDTHxHEIGHT`, and
`ONEROM_SPIKE_SETUP` is a comma-separated script (`board:fire-28-d`, `add`,
`chip:0:23128`, `file:0:/path`, `nohelp`).

**Q2. Log and console panes — `prototypes/studiov2/log-viewer/`**

```
cd prototypes/studiov2/log-viewer && cargo run --release
```

`--help` lists the switches. `--selftest --quit-when-done` proves selection and
copy against the real system clipboard, and **overwrites the clipboard**.
`--console-demo` runs a scripted device session. `--bench 1000,9000,90000
--chunk 500` reproduces the append timings. `cargo test --release` runs seven
tests that drive the widget with real mouse and keyboard events and a recording
clipboard.

A drag selects exactly the right lines, Cmd+C puts them on the clipboard
byte-for-byte, and edits are refused without corrupting the buffer. The console
pane is a read-only editor for scrollback plus a text box for input, with
command history.

Two things it found. `iced_term` cannot serve a serial console — it hardcodes
spawning a PTY and its backend type is private, so feeding it device bytes means
forking 576 lines. And async tasks returned from separate updates have no
ordering between them, so several commands in flight reply out of order. One
command in flight fixes it, which is what a device shell wants anyway.

---

## R. Log output

**R1. The log keeps everything the device sends**, for the whole session, no cap.
The widget shows a window of about 120 lines over it. Its cost does not grow
with the log.

**R2. The log is not bounded by what the widget can hold.** How many lines fit
inside Iced's text widget before it stutters is a question about the widget, and
has no bearing on how much log a session keeps.

**R3. The windowed design works, on stock widgets, with no custom text widget.**
Built and measured in the prototype. The scrollbar represents the whole log and
its position is exact. Selection and copy work across ranges far larger than the
window — select-all on 120,000 lines while the widget holds 120, answered from
storage. Live tail slides correctly, and scrolling up holds position while the
log grows behind you. Search runs over the whole log off the update thread and
scrolls to the hit.

**R4. What a million lines costs.** On a 32GB M5 MacBook Air: about 20 MB of
memory over an empty app, jump anywhere in 15-18 ms, search the whole log in
51 ms. The same million lines held in the widget instead reaches 699 MB with
121 ms stalls, and can neither search nor jump.

**R5. Two things to know before building on it.** Every window move costs about
7 ms, nearly all of it Iced rebuilding text it is about to rebuild — comfortable
today with no headroom, and removable either by appending rather than rebuilding
or by a small addition to Iced itself. And Iced publishes no drag event once the
pointer leaves the widget, so dragging a selection past the edge needs its own
auto-scroll. That is 30 lines, and the prototype has it.

---

## T. How the app is structured

A shared crate at the bottom holds the shared state objects and the styling.
Each screen is a crate above it, independently buildable, with a small binary
that runs it standalone. The app orchestrates the screens and holds the shared
state. Built, not designed on paper: four crates (`shared`, `slot-builder`,
`log-viewer`, `shell`), three binaries, 24 passing tests, under
`prototypes/studiov2/`.

**T1. The shared crate exists for the palette.** One window has one theme, so a
palette owned by one screen is one the other cannot have. Screens-only means
duplicating it, or a sideways dependency.

**T2. The crate split buys compiler enforcement and costs almost nothing.** A
reach from the log screen into the builder is `E0433`, a hard error. In one
crate with several binaries it compiles with an unused-import warning. The split
cost 73 changed lines, every one a `use` statement. Clean build 41.1s against
34.2s, incremental 1.1s against 1.7s.

**T3. What turned out to be shared.** The log. The device selection, but not the
attached-device list. The built image, cut to a name, a description and bytes.
And, on nobody's list beforehand, 280 lines of styling. Nothing else wanted
sharing.

**T4. One `&Shared` per call, not a borrow per shared thing.** Studio's
`Create::view` takes four borrows and worsens as more is shared, because it
passes pieces. One `Shared` does not grow with what is in it.

**T5. Some work appears only at composition time.** Under one window the log
screen's stock buttons rendered gold against the One ROM palette. 11 buttons,
4 text inputs and a pick list needed explicit styles. Compose early.

**T6. Sharing the log forces a refactor, in any structure.** The log view owned
its store and can no longer, so 16 methods grew a `store: &Store` parameter,
across about 50 call sites.

**T7. Plumbing is per screen, not per message.** Two screens cost about 63 lines
of it, against 297 lines of shell and ~5,700 of screens. A standalone runner is
a miniature app owning the shared state, about 50 lines a screen.

**T8. Iced specifics.** Iced's `Component` trait is deprecated and was not
needed. Subscriptions map cleanly, but the app must keep a hidden screen's
subscription running or the log stops with no sign. Fonts and the window title
are application-level. A screen can call `iced::exit()`, so a screen can kill
the app.

**T9. Where these results hold.** They were measured with two screens. At twelve
the orchestrating `update` carries twelve arms and the shared state perhaps
fifteen fields, which is worth measuring again when it gets there. Every screen
sees the whole shared state, and the compiler guarantees one thing about it —
that a screen cannot reach another screen's code (T2). Which parts of the shared
state a screen reads is left to whoever writes it. Giving each screen a smaller
object holding only what that screen needs would let the compiler police that
too, at the price of the long parameter lists T4 avoids.

**T10. The shared crate stays dependency-light** — `iced` and `thiserror`. That
is what forced the image down to bytes rather than `onerom_gen::Built`, and the
board down to a string.

---

## J. Do this first

**Lift the compose-and-program pipeline out of the CLI binary into the library**,
with decisions separated from the asking, and a progress channel in place of
`println!`. Size: **M, ~2-3 kLOC**, mostly from `firmware.rs` and `program.rs`.
Its log-streaming interface should not assume USB, since SWD may return for
logging.

Its absence is why Studio and Web each grew their own half-built pipeline, and
why neither supports firmware overrides or licence acceptance. It makes CLI/GUI
parity structural rather than a discipline — both drive one library, so a new
capability lands once.

**Size of the rest: L, ~6-8 kLOC** on top of J.

---

## P. Generating the GUI from the CLI

**P1. Across all 44 shipping commands: 27% generate well, 61% generate badly,
11% cannot.** Judged, not measured. Section V built them and counted 49 leaf
commands and 173 options, and V1 has the real split. clap does not carry what a
good pane needs — of the options, five have a value set clap can see, and
`--board` is a bare string on fourteen commands. Colour, pin, chip type and
firmware version all sit behind opaque parsers, and the legal pin set depends on
the connected board.

The finding that decides this: **generation is strongest where a GUI adds least,
and weakest where it adds most.** It handles file-in, file-out image conversion
well — a command anyone would keep doing from the CLI. It handles pin control,
the socket and header drawings, LED colour and anything reading device state
badly, and those are the panes that justify a GUI existing.

**P2c. Generating from clap plus an annotation file pays for about a dozen
commands, and not for the rest.** clap can walk its own command tree, which is
how `clap_complete` and `clap_mangen` work, so a hidden `--dump-schema` could
feed the GUI's build script. For two-thirds of the commands the annotation
needed to rescue a generated pane would be longer than the clap definition it
annotates, which makes it a hand-written schema in disguise. Worse, the ranges
and defaults it would carry already live in `metadata_schema.toml`, so it would
be the second copy that the project's cross-project-constants rule exists to
prevent.

**P3. The gate is worth more than the generation, costs less, and does not
depend on it.** A build
failure when the CLI grows a capability the GUI does not expose delivers most of
the value on its own. `cli_assert` in `rust/cli/src/main.rs` already walks the
whole clap tree and already fails the build on a rule breach, so this is another
assertion in a mechanism that exists. Hand-written screens declare which commands
they cover, so the gate covers everything. One fork inside it stays open: whether
the gate is satisfied per command or per option. Per command lets a pane expose a
command while missing half its flags. Per option is real pressure and noisy at
first.

**P4. Wherever generation is used, hold the line deliberately.** `onerom-metadata` works because a struct
and a parser are right or wrong, never ugly. GUI panes have aesthetics, and the
failure mode is the first pane that must look different: either an escape hatch,
and the generator stops being the source of truth, or a schema contorted into a
worse GUI toolkit. Every individual exception will look reasonable.

---

## U. Possible next steps

Each is a prototype in the same style as the two that exist — small, runnable,
and built to answer one question that would otherwise be argued about.

**U1. Lift the compose-and-program pipeline into the CLI library (J).** Not a
prototype. It is the first piece of product work, and it is what lets the slot
builder produce a flashable image and put it on a device, the gap named in its
own README. It improves the CLI on its own.

**U2. A device screen, against real hardware.** Both prototypes are offline. The
builder does no I/O and the log viewer runs off a synthetic generator. Talking
to hardware is the app's reason for existing, and it is the part the existing
Studio got worst. Its device calls returned the GUI's message type, its
multi-step operations were hand-built state machines, and it waited for a
rebooting device with a fixed one-second sleep.

The screen does what `onerom scan --slots` does — every attached device with its
board, MCU, firmware version, state and serial, and each slot's chip type, size,
chip-select configuration, source and plugin name. It adds the full parse from
`onerom-fw-parser`, the whole metadata and runtime tree that `inspect info`
dumps as JSON.

That last part is where a GUI beats the CLI rather than matching it. Every byte
of device state is reachable by design, and today it arrives as a JSON dump few
people read. The same data as a tree a user can expand, search and copy out of
is usable.

What it tests beyond how it looks: enumeration while devices are plugged and
unplugged, the reboot where a device returns at a different USB address, a real
log stream rather than a generated one, and what a device in the wrong state
does to the screen. It fails if the async plumbing pushes the design back
towards Studio's shape.

**U3. Generated panes across the whole CLI. Built — section V has the answer.**
It asked for the real split rather than the judged one, what the generator costs
to write, and what an annotation file has to carry measured against the whole
surface. All three came back, along with a fourth thing nobody asked for: what it
would take to make a generated pane actually run its command.

**Order.** U2 does not need U1 — the device surface it wants is already in the
CLI library. U1 is the first piece of product work rather than a dependency.

---

## V. Generated panes across the whole CLI

The third prototype, answering U3. Two crates and a third tab in the shell.
`commands/`'s build script reads `rust/cli/src/args/` with `syn` and emits plain
data — 49 leaf commands, 167 command options, 6 globals — as `no_std` with
`alloc`, no clap and no iced, so a browser through WASM could read the same
description. `generated/` is an Iced screen that draws a pane from that data and
nothing else. **No line of GUI code names a command.**

```
cargo run -p studiov2-generated   # the panes alone, --list names them
cargo run -p studiov2-shell       # beside the builder and the log panes
```

fmt, clippy, tests and docs are all green. 103 tests across the workspace, 78 of
them here.

**V1. All 49 panes generate, and 45 of them have no field a user must type into
blind.** A command added to the CLI gets a pane on the next build with nobody
writing GUI code. 62 of the 173 options carry a value set, and every one of them
was a bare box before: 28 files and directories, 14 boards, 5 firmware versions,
5 colours, 4 pins, 3 chip types, a plugin type, a serial and a CLI release. 15
options stay a bare box, 6 of those genuinely free text — names and
descriptions. The four panes with a blind field are `program`, `firmware build`,
`image convert` and `self download`.

**V2. The annotation costs 38 lines, against about 330 lines of clap
definition.** P2c expected the opposite. Two tables, neither holding a value —
both name the crate to ask. 10 lines derive 36 options from the CLI's own
placeholders, and 28 lines name the other 26 one at a time.

`BOARD`, `COLOUR`, `PIN` and `CHIP` already say what the values are, because the
CLI author wrote the placeholder for a user. 25 of the 26 hand-named options are
`FILE`, the one placeholder covering two different things — a file to read has
to exist and a file to write must not. Only 5 of the 173 options have a value
set clap itself advertises, which is P1's point, and the placeholder recovers
most of what P1 thought was lost.

**V3. clap carries argument relationships, which was not expected.** 4 commands
declare an `ArgGroup`, and 16 say something of the kind once `conflicts_with`
and `requires` are counted, across 92 conflict names and 9 requirements. It is
the only grouping written down anywhere. `control erase` is the case to look at:
exactly one of `--all`, `--offset` and `--address` is required, `--offset` needs
`--length`, and `--stopped` and `--running` exclude each other. The pane draws
that as two labelled groups, and enforces it.

**V4. The three commands U3 named.**

| command | expected | came out |
| --- | --- | --- |
| `image convert` | well | two real value sets, two file pickers, runs for real — `--load-address` is the bare box |
| `control rgb on` | badly | swatch yes, brightness slider no, because no bound is written down |
| `inspect gpio` | decides it | pin, board and flag all real. The table it prints is guessed |

The pattern across all three: the **input** half of a pane generates well, and
the **output** half is where the description runs out.

**V5. Nothing outside the CLI binary can run a CLI command.** Four commands run
for real — the three under `image`, plus `firmware chips` — and they are **454
lines of re-implementation inside the GUI crate** calling `onerom-gen` and
`onerom-config`, not calls into the CLI. Every `cmd_*` lives in the binary
(`rust/cli/src/image.rs` and its siblings) and the dispatch is one match from
`rust/cli/src/main.rs:59` onwards. `rust/cli/src/lib/` holds device primitives,
not commands.

That is a limit of the prototype rather than of the approach. It cannot edit the
CLI, so it re-implemented four commands and found them by matching on the
options a command takes, to avoid writing a command's name down. Studio v2 moves
that dispatch and the `cmd_*` functions into `onerom-cli`'s library behind one
entry point, and a pane hands over the command it already holds — no per-command
GUI code, no name, all 49. It is the same lift as J and belongs with it.

**V6. What the description does not carry**, found by building the panes:

- **A bound on a number.** 22 of the 46 numeric options are milliseconds and 6 a
  percentage, so none of them can be a slider. The bounds exist as named
  firmware constants.
- **Which option belongs beside which.** V3's relationships cover the
  constraint. Nothing covers the layout.
- **Whether a command needs a device.** `requires_device()` is a trait
  implementation on the parsed arguments, invisible to anything walking the
  definitions.
- **What a command prints, and the prose it prints around it.** `firmware chips`
  prints a trailing note and a plugin-type list, and the pane drops both without
  a word. `stub::shape` guesses table, tree or drawing from the first and last
  word of a command's path, which is the one placeholder that reads command
  words at all.
- **That one option scopes another.** A chip-type list could narrow to the board
  chosen in `--board`.

**V7. Costs and limits.**

- **`program` (28 options) and `firmware build` (18) are the worst panes.**
  `program --slot` takes `file=…,type=23128,cs1=active-low` — a language inside
  one option — and will not generate however much the description carries. The
  slot builder is the hand-written answer to the same command, and the shell
  shows both.
- **A pane per leaf command is not obviously right**, which is S3 in the flesh.
  Six commands are a title and a Run button. `control rgb` is seven panes, four
  of them with the same four options.
- **Faked, and the screen says so.** Browse fills in a sample path rather than
  opening a dialog, the version lists are written out rather than fetched, and
  the device list is invented. 45 panes are stubbed, and every pane says which
  it is.

**V8. A pane is generated or hand-written, never both.** A generated pane is a
fair starting point for a hand-written one. Editing it moves that command onto
the list P3 already needs — the commands a hand-written screen declares it
covers — and it stops being generated.

That answers the first half of P4, the escape hatch that quietly stops the
generator being the source of truth. There is no half-generated pane to patch,
so an exception has to be a whole pane and is visible as one. P4's other half, a
description contorted to suit a GUI, is untouched by this, and V6 is where it
would show.

The cost is that a hand-written pane stops picking up a new CLI option for free,
where a generated one has it on the next build. P3's gate is what catches that.

**V9. A command should return its output rather than print it.** V6 records that
the description says nothing about what a command prints, so `stub::shape`
guesses from the words in a command's path. This is the answer to that bullet.

Today a `cmd_*` writes to stdout, so what it produced exists only as text on a
terminal. Return a value instead, and the CLI binary formats it for a terminal
while a GUI renders the same value its own way. The prototype's own model took
real output without changing:

```rust
enum Output {
    Line(String),
    Table { headers, body },   // body is flat rows, or rows under headings
    Drawing(String),           // fixed-pitch, a socket or a jumper header
    Tree(Node),                // a parsed firmware image
    Nothing,
}
```

Those five carried the four commands V5 runs for real. They do not carry the
prose a command prints around a table — `firmware chips` prints a trailing note
and a plugin-type list, and both are lost.

It is not annotation. It falls out of the signature, `cmd_chips(...) ->
Result<Output, Error>`, so the compiler holds it to what the command does. It is
the same lift V5 describes rather than work beside it, because a `cmd_*` cannot
move into the library while it prints and prompts. The CLI gains on its own too:
every command could answer in JSON, where `inspect telemetry` is the only one
that does today.

Two of the design questions below moved during this work. **S2** was answered by
running these panes in the shell, and **S4** was found here.

---

## Design questions found, not answered

Recorded so they are not lost. P2c and S2 have since been answered and say
where. The rest still stand.

- **P2c** — answered by V2. The annotation is 38 lines against about 330 lines
  of clap definition, and it covers the whole CLI rather than the dozen commands
  this expected. Most of it derives from the placeholders the CLI already
  writes, so the file names a source and never carries a value.
- **P3** — whether the CI gate is satisfied per command or per option. Per
  command lets a pane expose a command while missing half its flags.
- **S1** — the ROM-type sort order belongs in Rust, reachable from the apps and
  from WASM, rather than in `js/site/utils.js`. It is the visible end of a wider
  question: what else in that JS is logic that should sit in Rust.
- **S2** — answered, and it was worse than stated. The log pane rebuilt its
  whole 120-line window on every tick, and the slot builder its 200-line tail,
  each shaping every line twice. That cost the same at 20 lines a second as at
  5,000, and left no headroom for macOS App Nap, which demotes a background
  window to an efficiency core after about 30 seconds and runs it four times
  slower. The shell pinned a core and stopped drawing. Sliding the window
  instead of rebuilding it holds 22% where it used to pin at 99%, and the cost
  now tracks the lines arriving.
- **S3** — whether the twelve LED and RGB commands become two panes with a mode
  selector. They are twelve of the CLI's 49 leaves, so the answer generalises.
  V7 has them on screen.
- **S4** — 11 of the CLI's 173 help texts name another option in CLI spelling,
  e.g. `--length` reads "paired with --offset or --address". A generated pane
  labels its controls `Offset` and `Address`, so the pane shows two spellings
  of the same thing. Closing it means rewording those doc comments in
  `rust/cli/src/args/`, which changes what `--help` prints — and a CLI reader
  may want the dashes. Not all 11 are the same case: one quotes a whole command
  line a user would type, where the spelling is right. Production needs this
  settled. The U3 prototype carries it as a known rough edge.

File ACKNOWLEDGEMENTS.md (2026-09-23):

# Acknowledgements

Third party work One ROM builds on, or is compatible with, where the code
itself is not part of this repository. Dependencies vendored into the tree
carry their own licence files alongside their sources; this file covers work
that has shaped One ROM without being redistributed here.

For One ROM's own licensing, see [LICENSE.md](LICENSE.md).

## SEGGER RTT

One ROM's real time transfer logging — [`firmware/src/rtt.c`](firmware/src/rtt.c)
and [`firmware/include/rtt.h`](firmware/include/rtt.h) — is a One ROM
implementation that is **binary compatible** with SEGGER RTT, so that
probe-rs, OpenOCD, pyOCD and Black Magic Probe can find and drain One ROM's
log with no host side change.

The implementation is One ROM's own. What is retained from SEGGER is the
interface a debug probe expects: the control block and channel descriptor
layouts, the `_SEGGER_RTT` symbol name a probe resolves, and the
`"SEGGER RTT"` identifier string a probe scans memory for. Earlier releases
built against SEGGER's own `SEGGER_RTT.c` and `SEGGER_RTT_printf.c`, which
were cloned at build time; they are no longer part of the build.

    Copyright (c) 2026 SEGGER Microcontroller GmbH
    All rights reserved.

    Redistribution and use in source and binary forms, with or without
    modification, are permitted provided that the following condition is met:

    1. Redistributions of source code must retain the above copyright notice,
       this condition and the following disclaimer.

    THIS SOFTWARE IS PROVIDED BY THE COPYRIGHT HOLDERS AND CONTRIBUTORS "AS
    IS" AND ANY EXPRESS OR IMPLIED WARRANTIES, INCLUDING, BUT NOT LIMITED TO,
    THE IMPLIED WARRANTIES OF MERCHANTABILITY AND FITNESS FOR A PARTICULAR
    PURPOSE ARE DISCLAIMED. IN NO EVENT SHALL THE COPYRIGHT HOLDERS AND
    CONTRIBUTORS BE LIABLE FOR ANY DIRECT, INDIRECT, INCIDENTAL, SPECIAL,
    EXEMPLARY, OR CONSEQUENTIAL DAMAGES (INCLUDING, BUT NOT LIMITED TO,
    PROCUREMENT OF SUBSTITUTE GOODS OR SERVICES; LOSS OF USE, DATA, OR
    PROFITS; OR BUSINESS INTERRUPTION) HOWEVER CAUSED AND ON ANY THEORY OF
    LIABILITY, WHETHER IN CONTRACT, STRICT LIABILITY, OR TORT (INCLUDING
    NEGLIGENCE OR OTHERWISE) ARISING IN ANY WAY OUT OF THE USE OF THIS
    SOFTWARE, EVEN IF ADVISED OF THE POSSIBILITY OF SUCH DAMAGE.

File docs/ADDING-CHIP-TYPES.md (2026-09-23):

# Adding a Chip Type

How to teach One ROM to emulate a chip it does not yet know about.

This describes the **v2** path — firmware v0.7.0 and later, which is Fire
(RP2350) hardware.  V2 derives how to serve a chip from the chip's pinout and
the board's routing, so a new chip type is usually a data change plus a one-line
declaration.  The pre-v0.7.0 (v1) path is closed to new chip types, and its
per-chip code in [`rust/gen/src/image.rs`](/rust/gen/src/image.rs)
(`chip_type_c_enum_val`, `handle_snowflake_chip_types`) is not part of this.

## The short version

1. Add the chip to [`rust/config/json/chip-types.json`](/rust/config/json/chip-types.json).
2. Add its `ChipType` to `SUPPORTED_CHIP_TYPES` in [`rust/gen/src/v2/builder.rs`](/rust/gen/src/v2/builder.rs).
3. Run the generators.
4. Look for the chip in [`docs/COMPATIBILITY.md`](/docs/COMPATIBILITY.md).  If it is there, it serves.
5. If it is not, find out why with the `layout` tool — and only then consider firmware work.
6. Add it to the emulator test sweep, so it stays working.

## 1. The JSON entry

Everything One ROM knows about a chip comes from this one file.  The
`onerom-config` build script reads it, validates it, and generates the
`ChipType` enum and [`docs/CHIP-TYPES.md`](/docs/CHIP-TYPES.md).  The
`onerom-metadata` build script generates the firmware's `onerom_rom_type_t` C
enum and chip-size array from the same data.  Nothing is written twice.

Here is the 2364 entry — about as simple as an entry gets — with its arrays
compacted onto single lines:

```json
"2364": {
    "description": "8KB mask ROM with 1 configurable CS line",
    "function": "ROM",
    "rbcp_chip_type": 2,
    "supported": "0.4.4",
    "aliases": ["4764", "MCM68764", "MCM68A764", "MM52164", "MK36000"],
    "bit_modes": [8],
    "pins": 24,
    "size": 8192,
    "address": [8, 7, 6, 5, 4, 3, 2, 1, 23, 22, 19, 18, 21],
    "data": [9, 10, 11, 13, 14, 15, 16, 17],
    "control": {
        "cs1": { "pin": 20, "type": "configurable" }
    },
    "power": [
        { "name": "VCC", "pin": 24, "voltage": "+5V" },
        { "name": "GND", "pin": 12, "voltage": "0V" }
    ]
}
```

- **The key** is the chip's primary name.  Unless the chip is RAM it must start
  with `23`, `27`, `28`, `SST39SF` or `HM76`, or the build panics with
  `Unsupported chip type X - needs adding to chip_family()`.  A part number
  outside those conventions needs an arm in
  [`rust/config/build/chip/mod.rs`](/rust/config/build/chip/mod.rs).
- **`rbcp_chip_type`** is the wire value: unique, and permanent once shipped.
  Take the next free number.  The firmware's C enum and chip-size array are
  generated from it.  It is also part of the
  [ROM Bus Control Protocol](https://github.com/piersfinlayson/rom-bus-control-protocol),
  so a new chip type needs a matching pull request against that repository — the
  value has to mean the same thing on both sides of the bus.
- **`supported`** is the firmware version the chip first ships in — the
  in-development version from the [`Makefile`](/Makefile).  Omit it and the chip
  is known but unsupported: absent from `COMPATIBILITY.md` and from
  `onerom firmware chips`, and marked `✗` in `CHIP-TYPES.md`.
- **`aliases`** are other names for the same silicon.  Every alias becomes
  selectable everywhere a chip type can be named — the CLI, the web programmer
  and Studio, as well as its own row in `COMPATIBILITY.md` — so a user can pick
  the number actually stamped on their chip rather than having to know it is the
  same part as something else.  Be generous with them.
- **`address`** lists the address lines in bit order, lowest first, as physical
  pin numbers, and **`data`** does the same for the data lines from D0.  `size`
  must equal `2^address.len()` (the 48KB 23QL384 is the sole exception).
- **`bit_modes`** is `[8]`, `[8, 16]` for a 16-bit part with a `/BYTE` line,
  or `[16]` for one without a `/BYTE` line, always served 16-bit.
  On a 16-bit part the lowest address line is **A-1**, not A0 — it selects which
  half of the word a byte-mode read returns, and it shares a pin with the top
  data line.  So the 27C400's 19 entries are A-1 to A18, and `2^19` is still its
  512KB.  Nothing keys off the chip name: anything that needs to know works it
  out from `bit_modes` containing 16.
- **`control`** names the enables.  `cs1`-`cs4` may be `configurable` (polarity
  mask-programmed, so the user supplies it), `fixed_active_low` or
  `fixed_active_high`.  `ce` and `oe` carry the JEDEC convention and must be
  `fixed_active_low`.  Mixing CS with CE/OE needs `"allow_mixed_control": true`.

[`rust/config/build/chip/validation.rs`](/rust/config/build/chip/validation.rs)
enforces the pin, size and control-line rules, and fails the build on a bad
entry.

## 2. Declare it servable

`SUPPORTED_CHIP_TYPES` in
[`rust/gen/src/v2/builder.rs`](/rust/gen/src/v2/builder.rs) is the list of chip
types v2 firmware serves.  Add the variant and bump the array length together:

```rust
pub const SUPPORTED_CHIP_TYPES: &[ChipType; 36] = &[
    ...
    ChipType::Chip2532,
];
```

Nothing else in the tooling or the firmware C needs touching for an ordinary ROM
chip type.  A **RAM** type also needs an arm in `rom_slot_type`
([`rust/gen/src/v2/rom_info.rs`](/rust/gen/src/v2/rom_info.rs)) — and no v2
firmware serves RAM yet, which is why `Chip6116` sits commented out of the list.

## 3. Run the generators

From `rust/`:

```bash
cargo run -p onerom-gen --bin compat                     # docs/COMPATIBILITY.md
cargo run -p schema-gen --bin schema-gen                 # onerom-config/schema.json
cargo run -p onerom-gen --bin layout -- --write-baseline # ci/layout-baseline.txt
```

`docs/CHIP-TYPES.md` needs no command — the `onerom-config` build script
rewrites it on any build.  All four are checked in and all four are a CI gate.
`ci/rust-tests.sh` regenerates them and fails if the committed copy differs, so
commit them with the change.

## 4. Did it work?

Look for the chip in [`docs/COMPATIBILITY.md`](/docs/COMPATIBILITY.md), or ask
the CLI — `cargo run -p onerom-cli --bin onerom -- firmware chips --board
fire-24-e`.  If it is listed, that is the whole job.  Check the flash cost while
you are there with `layout --check`: an image several times the chip's own size
is normal where a board's routing puts an unrelated signal inside the chip's
address range, but it is worth knowing.

## 5. When it does not appear

`cargo run -p onerom-gen --bin layout -- --board fire-24-e` says why.  An
unservable chip has `-` in every size column and the reason in the `blocked by`
column at the end of its row.  The three you will see:

- *"physical pin N has no GPIO mapping on this board"* — the chip is bigger than
  the socket and that pin cannot be reached.  Expected, not a fault — the chip is
  still listed for boards that can reach it.
- *"does not support chip type X with this firmware version"* — step 2 was
  missed, or the chip is deliberately excluded.
- *"select/control GPIOs [10, 11, 16] are not contiguous on this board; Multi
  and Banked sets require all select, commoned, and X-pin GPIOs to form a
  contiguous range within a single PIO window"* — the chip's enables land on
  GPIOs no existing chip-select algorithm can express.

Only the last needs firmware work, and it is a serving-algorithm change rather
than a chip-type change.  A new algorithm is:

- a variant and a `NUM_*_ALGS` bump in
  [`rust/metadata/metadata_schema.toml`](/rust/metadata/metadata_schema.toml),
  with its parameter fields and `ALG_*_PARAMS_LEN` constant — that generates
  both the C header and the Rust serialiser,
- a `case` in [`firmware/src/piodma/piorom2.c`](/firmware/src/piodma/piorom2.c)
  emitting the PIO program,
- a preference variant in
  [`rust/gen/src/v2/alg_preference.rs`](/rust/gen/src/v2/alg_preference.rs), plus
  the derivation that selects it in `alg_cs.rs`, `cs_data_layout.rs` or
  `addr_layout.rs`,
- a CS-to-data cycle cost in
  [`rust/fw-tester/src/cs_timing.rs`](/rust/fw-tester/src/cs_timing.rs), which
  asserts against the firmware's own `NUM_*_ALGS` and so will not compile until
  the new algorithm has one.

That is a much bigger piece of work than adding a chip type — and it benefits
every chip that can use the new algorithm, not just the one that prompted it.

## 6. Add it to the test sweep

A chip that serves today but is not tested will break quietly later.
[`ci/test-emu.sh`](/ci/test-emu.sh) lists its chips explicitly, one line each, so
a new type is covered only once you add it.  Put it with the others for its pin
count, with a test image of the right size from [`images/test`](/images/test):

```sh
run_test   $board images/test/rand_16KB.rom  type=23128  3
run_no_cs  $board images/test/rand_8KB.rom   type=2764
```

`run_test` takes the number of configurable chip select lines and sweeps **every
polarity combination** — 3 means all 8 are tested.  `run_no_cs` is for chips
whose enables have a polarity fixed by the silicon, so there is nothing to sweep.

Run just your pin count while iterating — `ci/test-emu.sh 24` — as the full sweep
takes hours, and only one can run in a given working tree at a time.

## Folding it back in

If you want your chip type in One ROM proper rather than kept in your own tree,
please do — that is how the supported list has grown, and a chip somebody has
actually got in front of them is worth more than one added speculatively.  Open
an issue or a pull request, and talk to the maintainer early if the chip needs a
new serving algorithm, since that is a change with consequences beyond your chip
and is better designed together than reviewed after the fact.

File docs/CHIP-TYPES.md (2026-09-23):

# Chip Type Specifications

This document provides detailed specifications for the different Chip types One ROM supports, and aims to support in future, including pinouts, control lines, and programming requirements.

The document is auto-generated from the [json/chip-types.json](/rust/config/json/chip-types.json) configuration file.  That file was created by researching datasheets for the various Chip types.

Some of the pin names have been modified from the datasheet values for consistency beween Chip types:

- /OE on 2704/2408 is called Program, but serves as /OE when in read mode.  Other 27xx ROMs use /OE for that pin, hence the /OE name is used here. 
- Similarly /CE on 2704/2708 ROMs is called /CS, but is called /CE for consistency with other ROM types.
- 23256/23512 chip select lines are often called CE/OE on datasheets, but are mask programmable to be active high or low, hence these are referred to within this doc as CS lines, like the other 23xx ROMs.
- Chips whose enables have a polarity fixed by the silicon use CE/OE where every enable is active low (the JEDEC convention followed by the 27xx and 28xx families).  Where the enables are not all active low, CS lines are used instead: the HM7641 has CS1 and CS2 fixed active low, and CS3 and CS4 fixed active high.  A leading `/` in the tables below indicates an active low line.

There are also some other inconsistencies between types:

- 2332's CS2 is pin 21 and pin 18 is A11.  On the 2316, CS2 is pin 18, and CS3 pin 21.
- The 2332's A11 is pin18, but the 2732's A11 is pin 21.

## Contents

- [24-pin Mask ROM Family (23xx)](#24-pin-mask-rom-family-23xx)
- [28-pin Mask ROM Family (23xx)](#28-pin-mask-rom-family-23xx)
- [32-pin Mask ROM Family (23xx)](#32-pin-mask-rom-family-23xx)
- [24-pin EPROM Family (27xx)](#24-pin-eprom-family-27xx)
- [28-pin EPROM Family (27xx)](#28-pin-eprom-family-27xx)
- [32-pin EPROM Family (27xx)](#32-pin-eprom-family-27xx)
- [40-pin EPROM Family (27xx)](#40-pin-eprom-family-27xx)
- [24-pin EEPROM Family (28Cxx)](#24-pin-eeprom-family-28cxx)
- [28-pin EEPROM Family (28Cxx)](#28-pin-eeprom-family-28cxx)
- [32-pin EEPROM Family (28Cxx)](#32-pin-eeprom-family-28cxx)
- [24-pin Bipolar PROM Family (HM76xx)](#24-pin-bipolar-prom-family-hm76xx)
- [RAM Chips](#ram-chips)
- [Pin Function Comparison](#pin-function-comparison)
- [Detailed Pinouts](#detailed-pinouts)

## 24-pin Mask ROM Family (23xx)

| Chip Type | Aliases | Size | Address Lines | Control Lines | Programming | Supported |
|---|---|---|---|---|---|---|
| 2316 | 9316, 9316A | 2KB | 11 (A0-A10) | CS1 (pin 20), CS2 (pin 18), CS3 (pin 21) | None | ✓ |
| 2332 | 9332, 4732 | 4KB | 12 (A0-A11) | CS1 (pin 20), CS2 (pin 21) | None | ✓ |
| 2364 | 4764, MCM68764, MCM68A764, MCM68364, MCM68A364, MM52164, MK36000 | 8KB | 13 (A0-A12) | CS1 (pin 20) | None | ✓ |

## 28-pin Mask ROM Family (23xx)

| Chip Type | Aliases | Size | Address Lines | Control Lines | Programming | Supported |
|---|---|---|---|---|---|---|
| 23128 | HN613128P | 16KB | 14 (A0-A13) | CS1 (pin 20), CS2 (pin 22), CS3 (pin 27) | None | ✓ |
| 23256 |  | 32KB | 15 (A0-A14) | CS1 (pin 20), CS2 (pin 22) | None | ✓ |
| 23QL384 |  | 48KB | 16 (A0-A15) | CS1 (pin 22) | None | ✓ |
| 23512 |  | 64KB | 16 (A0-A15) | CS1 (pin 20), CS2 (pin 22) | None | ✓ |
| 23QL512 |  | 64KB | 16 (A0-A15) | CS1 (pin 22) | None | ✓ |
| 231024 | TC531000, 23C1000, 23C1000A, MX23C1000 | 128KB | 17 (A0-A16) | CS1 (pin 20) | None | ✓ |

## 32-pin Mask ROM Family (23xx)

| Chip Type | Aliases | Size | Address Lines | Control Lines | Programming | Supported |
|---|---|---|---|---|---|---|
| 23C1001 | D23C1001 | 128KB | 17 (A0-A16) | /CE (pin 22), CS1 (pin 31), CS2 (pin 30), /OE (pin 24) | None | ✓ |
| 23C1010 |  | 128KB | 17 (A0-A16) | /CE (pin 22), /OE (pin 24) | None | ✓ |

## 24-pin EPROM Family (27xx)

| Chip Type | Aliases | Size | Address Lines | Control Lines | Programming | Supported |
|---|---|---|---|---|---|---|
| 2704 |  | 512B | 9 (A0-A8) | /CE (pin 18), /OE (pin 20) | VPP: pin 18 (Low during read); PE: pin 20 (Low during read) | ✓ |
| 2708 |  | 1KB | 10 (A0-A9) | /CE (pin 18), /OE (pin 20) | VPP: pin 18 (Low during read); PE: pin 20 (Low during read) | ✓ |
| 2716 |  | 2KB | 11 (A0-A10) | /CE (pin 18), /OE (pin 20) | VPP: pin 21 (VCC during read); PE: pin 20 (Low during read) | ✓ |
| 2732 | 27C32 | 4KB | 12 (A0-A11) | /CE (pin 18), /OE (pin 20) | VPP: pin 20 (Acts as /OE); PE: pin 18 (Low during read) | ✓ |

## 28-pin EPROM Family (27xx)

| Chip Type | Aliases | Size | Address Lines | Control Lines | Programming | Supported |
|---|---|---|---|---|---|---|
| 2764 | 27C64, 27LC64 | 8KB | 13 (A0-A12) | /CE (pin 20), /OE (pin 22) | VPP: pin 1 (VCC during read); /PGM: pin 27 (High during read) | ✓ |
| 27128 | 27C128, 27LC128 | 16KB | 14 (A0-A13) | /CE (pin 20), /OE (pin 22) | VPP: pin 1 (VCC during read); /PGM: pin 27 (High during read) | ✓ |
| 27256 | 27C256, 27LC256, 27SF256 | 32KB | 15 (A0-A14) | /CE (pin 20), /OE (pin 22) | VPP: pin 1 (VCC during read); PE: pin 22 (Low during read) | ✓ |
| 27512 | 27C512, 27LC512, 27SF512 | 64KB | 16 (A0-A15) | /CE (pin 20), /OE (pin 22) | VPP: pin 22 (VCC during read); PE: pin 20 (Low during read) | ✓ |

## 32-pin EPROM Family (27xx)

| Chip Type | Aliases | Size | Address Lines | Control Lines | Programming | Supported |
|---|---|---|---|---|---|---|
| 27C010 | 27C1001, 27C1000A, 29F010, 39SF010, SST39SF010 | 128KB | 17 (A0-A16) | /CE (pin 22), /OE (pin 24) | VPP: pin 1 (Don't care during read); /PGM: pin 31 (Don't care during read) | ✓ |
| 27C301 | 27C1000, 27C100 | 128KB | 17 (A0-A16) | /CE (pin 22), /OE (pin 2) | VPP: pin 1 (Don't care during read); /PGM: pin 31 (Don't care during read) | ✓ |
| 27C020 | 27C2001, 39SF020, 29F020, SST39SF020 | 256KB | 18 (A0-A17) | /CE (pin 22), /OE (pin 24) | VPP: pin 1 (Don't care during read); /PGM: pin 31 (Don't care during read) | ✓ |
| 27C040 | 27C4001 | 512KB | 19 (A0-A18) | /CE (pin 22), /OE (pin 24) | VPP: pin 1 (Don't care during read); /PGM: pin 22 (Acts as /OE) | ✓ |
| SST39SF040 | 39SF040, 29F040 | 512KB | 19 (A0-A18) | /CE (pin 22), /OE (pin 24), /WRITE (pin 31) | None | ✓ |
| 27C080 | 27C801 | 1MB | 20 (A0-A19) | /CE (pin 22), /OE (pin 24) | VPP: pin 24 (Acts as /OE); /PGM: pin 22 (Acts as /OE) | ✓ |

## 40-pin EPROM Family (27xx)

| Chip Type | Aliases | Size | Address Lines | Control Lines | Programming | Supported |
|---|---|---|---|---|---|---|
| 27C200 | HN62402 | 256KB | 18 (A0-A17) | /BYTE (pin 31), /CE (pin 10), /OE (pin 12) | None | ✓ |
| 27C200Pin31NC |  | 256KB | 18 (A0-A17) | /CE (pin 10), /OE (pin 12) | None | ✓ |
| 27C400 | AT27C400, M27C400, 23C4100, MX23C4100, TCS534200, 27C4100, MX27C4100, HN62404, HN62424, MB834200 | 512KB | 19 (A0-A18) | /BYTE (pin 31), /CE (pin 10), /OE (pin 12) | VPP: pin 31 (Selects word size during read); /PGM: pin 10 (Acts as /OE) | ✓ |
| 27C400Pin31A17 |  | 512KB | 19 (A0-A18) | /CE (pin 10), /OE (pin 12) | None | ✓ |

## 24-pin EEPROM Family (28Cxx)

| Chip Type | Aliases | Size | Address Lines | Control Lines | Programming | Supported |
|---|---|---|---|---|---|---|
| 28C16 |  | 2KB | 11 (A0-A10) | /CE (pin 18), /OE (pin 20), /WRITE (pin 21) | None | ✓ |

## 28-pin EEPROM Family (28Cxx)

| Chip Type | Aliases | Size | Address Lines | Control Lines | Programming | Supported |
|---|---|---|---|---|---|---|
| 28C64 |  | 8KB | 13 (A0-A12) | /BUSY (pin 1), /CE (pin 20), /OE (pin 22), /WRITE (pin 27) | None | ✓ |
| 28C256 |  | 32KB | 15 (A0-A14) | /CE (pin 20), /OE (pin 22), /WRITE (pin 27) | None | ✓ |

## 32-pin EEPROM Family (28Cxx)

| Chip Type | Aliases | Size | Address Lines | Control Lines | Programming | Supported |
|---|---|---|---|---|---|---|
| 28C512 |  | 64KB | 16 (A0-A15) | /CE (pin 22), /OE (pin 24), /WRITE (pin 30) | None | ✓ |

## 24-pin Bipolar PROM Family (HM76xx)

| Chip Type | Aliases | Size | Address Lines | Control Lines | Programming | Supported |
|---|---|---|---|---|---|---|
| HM7641 |  | 512B | 9 (A0-A8) | /CS1 (pin 21), /CS2 (pin 20), CS3 (pin 19), CS4 (pin 18) | None | ✓ |

## RAM Chips

| Chip Type | Aliases | Size | Address Lines | Control Lines | Programming | Supported |
|---|---|---|---|---|---|---|
| 6116 | 2016 | 2KB | 11 (A0-A10) | /CE (pin 18), /OE (pin 20), /WRITE (pin 21) | None | ✓ |
| 62256 |  | 32KB | 15 (A0-A14) | /CE (pin 20), /OE (pin 22), /WRITE (pin 27) | None | ✗ |

## Pin Function Comparison

### 24-pin Package

| Pin | 2316 | 2332 | 2364 | 2704 | HM7641 | 2708 | 2716 | 28C16 | 6116 | 2732 |
|-----|---|---|---|---|---|---|---|---|---|---|
| 1 | A7 | A7 | A7 | A7 | A7 | A7 | A7 | A7 | A7 | A7 |
| 2 | A6 | A6 | A6 | A6 | A6 | A6 | A6 | A6 | A6 | A6 |
| 3 | A5 | A5 | A5 | A5 | A5 | A5 | A5 | A5 | A5 | A5 |
| 4 | A4 | A4 | A4 | A4 | A4 | A4 | A4 | A4 | A4 | A4 |
| 5 | A3 | A3 | A3 | A3 | A3 | A3 | A3 | A3 | A3 | A3 |
| 6 | A2 | A2 | A2 | A2 | A2 | A2 | A2 | A2 | A2 | A2 |
| 7 | A1 | A1 | A1 | A1 | A1 | A1 | A1 | A1 | A1 | A1 |
| 8 | A0 | A0 | A0 | A0 | A0 | A0 | A0 | A0 | A0 | A0 |
| 9 | D0 | D0 | D0 | D0 | D0 | D0 | D0 | D0 | D0 | D0 |
| 10 | D1 | D1 | D1 | D1 | D1 | D1 | D1 | D1 | D1 | D1 |
| 11 | D2 | D2 | D2 | D2 | D2 | D2 | D2 | D2 | D2 | D2 |
| 12 | GND | GND | GND | GND | GND | GND | GND | GND | GND | GND |
| 13 | D3 | D3 | D3 | D3 | D3 | D3 | D3 | D3 | D3 | D3 |
| 14 | D4 | D4 | D4 | D4 | D4 | D4 | D4 | D4 | D4 | D4 |
| 15 | D5 | D5 | D5 | D5 | D5 | D5 | D5 | D5 | D5 | D5 |
| 16 | D6 | D6 | D6 | D6 | D6 | D6 | D6 | D6 | D6 | D6 |
| 17 | D7 | D7 | D7 | D7 | D7 | D7 | D7 | D7 | D7 | D7 |
| 18 | CS2 | A11 | A11 | /CE+VPP | CS4 | /CE+VPP | /CE | /CE | /CE | /CE+PE |
| 19 | A10 | A10 | A10 | VDD | CS3 | VDD | A10 | A10 | A10 | A10 |
| 20 | CS1 | CS1 | CS1 | /OE+PE | /CS2 | /OE+PE | /OE+PE | /OE | /OE | /OE+VPP |
| 21 | CS3 | CS2 | A12 | VBB | /CS1 | VBB | VPP | /WRITE | /WRITE | A11 |
| 22 | A9 | A9 | A9 | GND | NC | A9 | A9 | A9 | A9 | A9 |
| 23 | A8 | A8 | A8 | A8 | A8 | A8 | A8 | A8 | A8 | A8 |
| 24 | VCC | VCC | VCC | VCC | VCC | VCC | VCC | VCC | VCC | VCC |

### 28-pin Package

| Pin | 23128 | 23256 | 23QL384 | 23512 | 23QL512 | 231024 | 2764 | 28C64 | 27128 | 27256 | 28C256 | 62256 | 27512 |
|-----|---|---|---|---|---|---|---|---|---|---|---|---|---|
| 1 | NC | NC | NC | A15 | NC | A15 | VPP | /BUSY | VPP | VPP | A14 | A14 | A15 |
| 2 | A12 | A12 | A12 | A12 | A12 | A12 | A12 | A12 | A12 | A12 | A12 | A12 | A12 |
| 3 | A7 | A7 | A7 | A7 | A7 | A7 | A7 | A7 | A7 | A7 | A7 | A7 | A7 |
| 4 | A6 | A6 | A6 | A6 | A6 | A6 | A6 | A6 | A6 | A6 | A6 | A6 | A6 |
| 5 | A5 | A5 | A5 | A5 | A5 | A5 | A5 | A5 | A5 | A5 | A5 | A5 | A5 |
| 6 | A4 | A4 | A4 | A4 | A4 | A4 | A4 | A4 | A4 | A4 | A4 | A4 | A4 |
| 7 | A3 | A3 | A3 | A3 | A3 | A3 | A3 | A3 | A3 | A3 | A3 | A3 | A3 |
| 8 | A2 | A2 | A2 | A2 | A2 | A2 | A2 | A2 | A2 | A2 | A2 | A2 | A2 |
| 9 | A1 | A1 | A1 | A1 | A1 | A1 | A1 | A1 | A1 | A1 | A1 | A1 | A1 |
| 10 | A0 | A0 | A0 | A0 | A0 | A0 | A0 | A0 | A0 | A0 | A0 | A0 | A0 |
| 11 | D0 | D0 | D0 | D0 | D0 | D0 | D0 | D0 | D0 | D0 | D0 | D0 | D0 |
| 12 | D1 | D1 | D1 | D1 | D1 | D1 | D1 | D1 | D1 | D1 | D1 | D1 | D1 |
| 13 | D2 | D2 | D2 | D2 | D2 | D2 | D2 | D2 | D2 | D2 | D2 | D2 | D2 |
| 14 | GND | GND | GND | GND | GND | GND | GND | GND | GND | GND | GND | GND | GND |
| 15 | D3 | D3 | D3 | D3 | D3 | D3 | D3 | D3 | D3 | D3 | D3 | D3 | D3 |
| 16 | D4 | D4 | D4 | D4 | D4 | D4 | D4 | D4 | D4 | D4 | D4 | D4 | D4 |
| 17 | D5 | D5 | D5 | D5 | D5 | D5 | D5 | D5 | D5 | D5 | D5 | D5 | D5 |
| 18 | D6 | D6 | D6 | D6 | D6 | D6 | D6 | D6 | D6 | D6 | D6 | D6 | D6 |
| 19 | D7 | D7 | D7 | D7 | D7 | D7 | D7 | D7 | D7 | D7 | D7 | D7 | D7 |
| 20 | CS1 | CS1 | A15 | CS1 | A15 | CS1 | /CE | /CE | /CE | /CE | /CE | /CE | /CE+PE |
| 21 | A10 | A10 | A10 | A10 | A10 | A10 | A10 | A10 | A10 | A10 | A10 | A10 | A10 |
| 22 | CS2 | CS2 | CS1 | CS2 | CS1 | A16 | /OE | /OE | /OE | /OE+PE | /OE | /OE | /OE+VPP |
| 23 | A11 | A11 | A11 | A11 | A11 | A11 | A11 | A11 | A11 | A11 | A11 | A11 | A11 |
| 24 | A9 | A9 | A9 | A9 | A9 | A9 | A9 | A9 | A9 | A9 | A9 | A9 | A9 |
| 25 | A8 | A8 | A8 | A8 | A8 | A8 | A8 | A8 | A8 | A8 | A8 | A8 | A8 |
| 26 | A13 | A13 | A13 | A13 | A13 | A13 | NC | NC | A13 | A13 | A13 | A13 | A13 |
| 27 | CS3 | A14 | A14 | A14 | A14 | A14 | /PGM | /WRITE | /PGM | A14 | /WRITE | /WRITE | A14 |
| 28 | VCC | VCC | VCC | VCC | VCC | VCC | VCC | VCC | VCC | VCC | VCC | VCC | VCC |

### 32-pin Package

| Pin | 23C1001 | 23C1010 | 28C512 | 27C010 | 27C301 | 27C020 | 27C040 | SST39SF040 | 27C080 |
|-----|---|---|---|---|---|---|---|---|---|
| 1 | NC | NC | NC | VPP | VPP | VPP | VPP | A18 | A19 |
| 2 | A16 | A16 | NC | A16 | /OE | A16 | A16 | A16 | A16 |
| 3 | A15 | A15 | A15 | A15 | A15 | A15 | A15 | A15 | A15 |
| 4 | A12 | A12 | A12 | A12 | A12 | A12 | A12 | A12 | A12 |
| 5 | A7 | A7 | A7 | A7 | A7 | A7 | A7 | A7 | A7 |
| 6 | A6 | A6 | A6 | A6 | A6 | A6 | A6 | A6 | A6 |
| 7 | A5 | A5 | A5 | A5 | A5 | A5 | A5 | A5 | A5 |
| 8 | A4 | A4 | A4 | A4 | A4 | A4 | A4 | A4 | A4 |
| 9 | A3 | A3 | A3 | A3 | A3 | A3 | A3 | A3 | A3 |
| 10 | A2 | A2 | A2 | A2 | A2 | A2 | A2 | A2 | A2 |
| 11 | A1 | A1 | A1 | A1 | A1 | A1 | A1 | A1 | A1 |
| 12 | A0 | A0 | A0 | A0 | A0 | A0 | A0 | A0 | A0 |
| 13 | D0 | D0 | D0 | D0 | D0 | D0 | D0 | D0 | D0 |
| 14 | D1 | D1 | D1 | D1 | D1 | D1 | D1 | D1 | D1 |
| 15 | D2 | D2 | D2 | D2 | D2 | D2 | D2 | D2 | D2 |
| 16 | GND | GND | GND | GND | GND | GND | GND | GND | GND |
| 17 | D3 | D3 | D3 | D3 | D3 | D3 | D3 | D3 | D3 |
| 18 | D4 | D4 | D4 | D4 | D4 | D4 | D4 | D4 | D4 |
| 19 | D5 | D5 | D5 | D5 | D5 | D5 | D5 | D5 | D5 |
| 20 | D6 | D6 | D6 | D6 | D6 | D6 | D6 | D6 | D6 |
| 21 | D7 | D7 | D7 | D7 | D7 | D7 | D7 | D7 | D7 |
| 22 | /CE | /CE | /CE | /CE | /CE | /CE | /CE+/PGM | /CE | /CE+/PGM |
| 23 | A10 | A10 | A10 | A10 | A10 | A10 | A10 | A10 | A10 |
| 24 | /OE | /OE | /OE | /OE | A16 | /OE | /OE | /OE | /OE+VPP |
| 25 | A11 | A11 | A11 | A11 | A11 | A11 | A11 | A11 | A11 |
| 26 | A9 | A9 | A9 | A9 | A9 | A9 | A9 | A9 | A9 |
| 27 | A8 | A8 | A8 | A8 | A8 | A8 | A8 | A8 | A8 |
| 28 | A13 | A13 | A13 | A13 | A13 | A13 | A13 | A13 | A13 |
| 29 | A14 | A14 | A14 | A14 | A14 | A14 | A14 | A14 | A14 |
| 30 | CS2 | NC | /WRITE | NC | NC | A17 | A17 | A17 | A17 |
| 31 | CS1 | NC | NC | /PGM | /PGM | /PGM | A18 | /WRITE | A18 |
| 32 | VCC | VCC | VCC | VCC | VCC | VCC | VCC | VCC | VCC |

### 40-pin Package

| Pin | 27C200 | 27C200Pin31NC | 27C400 | 27C400Pin31A17 |
|-----|---|---|---|---|
| 1 | NC | NC | A18 | NC |
| 2 | A8 | A8 | A8 | A8 |
| 3 | A7 | A7 | A7 | A7 |
| 4 | A6 | A6 | A6 | A6 |
| 5 | A5 | A5 | A5 | A5 |
| 6 | A4 | A4 | A4 | A4 |
| 7 | A3 | A3 | A3 | A3 |
| 8 | A2 | A2 | A2 | A2 |
| 9 | A1 | A1 | A1 | A1 |
| 10 | /CE | /CE | /CE+/PGM | /CE |
| 11 | GND | GND | GND | GND |
| 12 | /OE | /OE | /OE | /OE |
| 13 | D0 | D0 | D0 | D0 |
| 14 | D8 | D8 | D8 | D8 |
| 15 | D1 | D1 | D1 | D1 |
| 16 | D9 | D9 | D9 | D9 |
| 17 | D2 | D2 | D2 | D2 |
| 18 | D10 | D10 | D10 | D10 |
| 19 | D3 | D3 | D3 | D3 |
| 20 | D11 | D11 | D11 | D11 |
| 21 | VCC | VCC | VCC | VCC |
| 22 | D4 | D4 | D4 | D4 |
| 23 | D12 | D12 | D12 | D12 |
| 24 | D5 | D5 | D5 | D5 |
| 25 | D13 | D13 | D13 | D13 |
| 26 | D6 | D6 | D6 | D6 |
| 27 | D14 | D14 | D14 | D14 |
| 28 | D7 | D7 | D7 | D7 |
| 29 | A0+D15 | A0+D15 | A0+D15 | A0+D15 |
| 30 | GND | GND | GND | GND |
| 31 | /BYTE | NC | /BYTE+VPP | A18 |
| 32 | A17 | A17 | A17 | A17 |
| 33 | A16 | A16 | A16 | A16 |
| 34 | A15 | A15 | A15 | A15 |
| 35 | A14 | A14 | A14 | A14 |
| 36 | A13 | A13 | A13 | A13 |
| 37 | A12 | A12 | A12 | A12 |
| 38 | A11 | A11 | A11 | A11 |
| 39 | A10 | A10 | A10 | A10 |
| 40 | A9 | A9 | A9 | A9 |

## Detailed Pinouts

### 2316 - 2KB mask ROM with 3 configurable CS lines

**Package:** 24-pin DIP  
**Capacity:** 2048 bytes  
**Control:** 3 configurable CS lines  

| Function | Pins | Notes |
|---|---|---|
| Address (A0-A10) | 8,7,6,5,4,3,2,1,23,22,19 | 11 address lines |
| Data (D0-D7) | 9,10,11,13,14,15,16,17 | 8 data lines |
| CS1 | 20 | Configurable polarity |
| CS2 | 18 | Configurable polarity |
| CS3 | 21 | Configurable polarity |
| VCC | 24 | +5V |
| GND | 12 | 0V |

### 2332 - 4KB mask ROM with 2 configurable CS lines

**Package:** 24-pin DIP  
**Capacity:** 4096 bytes  
**Control:** 2 configurable CS lines  

| Function | Pins | Notes |
|---|---|---|
| Address (A0-A11) | 8,7,6,5,4,3,2,1,23,22,19,18 | 12 address lines |
| Data (D0-D7) | 9,10,11,13,14,15,16,17 | 8 data lines |
| CS1 | 20 | Configurable polarity |
| CS2 | 21 | Configurable polarity |
| VCC | 24 | +5V |
| GND | 12 | 0V |

### 2364 - 8KB mask ROM with 1 configurable CS line

**Package:** 24-pin DIP  
**Capacity:** 8192 bytes  
**Control:** 1 configurable CS line  

| Function | Pins | Notes |
|---|---|---|
| Address (A0-A12) | 8,7,6,5,4,3,2,1,23,22,19,18,21 | 13 address lines |
| Data (D0-D7) | 9,10,11,13,14,15,16,17 | 8 data lines |
| CS1 | 20 | Configurable polarity |
| VCC | 24 | +5V |
| GND | 12 | 0V |

### 23128 - 16KB mask ROM with 3 configurable CS lines

**Package:** 28-pin DIP  
**Capacity:** 16384 bytes  
**Control:** 3 configurable CS lines  

| Function | Pins | Notes |
|---|---|---|
| Address (A0-A13) | 10,9,8,7,6,5,4,3,25,24,21,23,2,26 | 14 address lines |
| Data (D0-D7) | 11,12,13,15,16,17,18,19 | 8 data lines |
| CS1 | 20 | Configurable polarity |
| CS2 | 22 | Configurable polarity |
| CS3 | 27 | Configurable polarity |
| VCC | 28 | +5V |
| GND | 14 | 0V |

### 23256 - 32KB mask ROM with 2 configurable CS lines

**Package:** 28-pin DIP  
**Capacity:** 32768 bytes  
**Control:** 2 configurable CS lines  

| Function | Pins | Notes |
|---|---|---|
| Address (A0-A14) | 10,9,8,7,6,5,4,3,25,24,21,23,2,26,27 | 15 address lines |
| Data (D0-D7) | 11,12,13,15,16,17,18,19 | 8 data lines |
| CS1 | 20 | Configurable polarity |
| CS2 | 22 | Configurable polarity |
| VCC | 28 | +5V |
| GND | 14 | 0V |

### 23QL384 - A composite ROM type, serving a combined 23256 and 23128 for the Sinclair QL, with a single configured CS line and is de-selected when A14 & A15 are both high

**Package:** 28-pin DIP  
**Capacity:** 49152 bytes  
**Control:** 1 configurable CS line  

| Function | Pins | Notes |
|---|---|---|
| Address (A0-A15) | 10,9,8,7,6,5,4,3,25,24,21,23,2,26,27,20 | 16 address lines |
| Data (D0-D7) | 11,12,13,15,16,17,18,19 | 8 data lines |
| CS1 | 22 | Configurable polarity |
| VCC | 28 | +5V |
| GND | 14 | 0V |

### 23512 - 64KB mask ROM with 2 configurable CS lines

**Package:** 28-pin DIP  
**Capacity:** 65536 bytes  
**Control:** 2 configurable CS lines  

| Function | Pins | Notes |
|---|---|---|
| Address (A0-A15) | 10,9,8,7,6,5,4,3,25,24,21,23,2,26,27,1 | 16 address lines |
| Data (D0-D7) | 11,12,13,15,16,17,18,19 | 8 data lines |
| CS1 | 20 | Configurable polarity |
| CS2 | 22 | Configurable polarity |
| VCC | 28 | +5V |
| GND | 14 | 0V |

### 23QL512 - A composite ROM type, serving two combined 23256s for the Sinclair QL, with a single configured CS line at pin 22, and A15 at pin 20 instead of pin 1

**Package:** 28-pin DIP  
**Capacity:** 65536 bytes  
**Control:** 1 configurable CS line  

| Function | Pins | Notes |
|---|---|---|
| Address (A0-A15) | 10,9,8,7,6,5,4,3,25,24,21,23,2,26,27,20 | 16 address lines |
| Data (D0-D7) | 11,12,13,15,16,17,18,19 | 8 data lines |
| CS1 | 22 | Configurable polarity |
| VCC | 28 | +5V |
| GND | 14 | 0V |

### 231024 - 128KB mask ROM with 1 configurable CS line

**Package:** 28-pin DIP  
**Capacity:** 131072 bytes  
**Control:** 1 configurable CS line  

| Function | Pins | Notes |
|---|---|---|
| Address (A0-A16) | 10,9,8,7,6,5,4,3,25,24,21,23,2,26,27,1,22 | 17 address lines |
| Data (D0-D7) | 11,12,13,15,16,17,18,19 | 8 data lines |
| CS1 | 20 | Configurable polarity |
| VCC | 28 | +5V |
| GND | 14 | 0V |

### 23C1001 - 128KB mask programmed ROM with fixed active-low CE/OE, plus 2 programmable CS lines

**Package:** 32-pin DIP  
**Capacity:** 131072 bytes  
**Control:** 2 configurable CS lines, /CE, /OE  

| Function | Pins | Notes |
|---|---|---|
| Address (A0-A16) | 12,11,10,9,8,7,6,5,27,26,23,25,4,28,29,3,2 | 17 address lines |
| Data (D0-D7) | 13,14,15,17,18,19,20,21 | 8 data lines |
| /CE | 22 | Active low |
| CS1 | 31 | Configurable polarity |
| CS2 | 30 | Configurable polarity |
| /OE | 24 | Active low |
| VCC | 32 | +5V |
| GND | 16 | 0V |

### 23C1010 - 128KB mask ROM with fixed active-low CE/OE

**Package:** 32-pin DIP  
**Capacity:** 131072 bytes  
**Control:** /CE, /OE  

| Function | Pins | Notes |
|---|---|---|
| Address (A0-A16) | 12,11,10,9,8,7,6,5,27,26,23,25,4,28,29,3,2 | 17 address lines |
| Data (D0-D7) | 13,14,15,17,18,19,20,21 | 8 data lines |
| /CE | 22 | Active low |
| /OE | 24 | Active low |
| VCC | 32 | +5V |
| GND | 16 | 0V |

### 2704 - 512B EPROM with multiple supply voltages

**Package:** 24-pin DIP  
**Capacity:** 512 bytes  
**Control:** /CE, /OE  

| Function | Pins | Notes |
|---|---|---|
| Address (A0-A8) | 8,7,6,5,4,3,2,1,23 | 9 address lines |
| Data (D0-D7) | 9,10,11,13,14,15,16,17 | 8 data lines |
| /CE | 18 | Active low |
| /OE | 20 | Active low |
| VPP | 18 | Low during read during read |
| PE | 20 | Low during read during read |
| VCC | 24 | +5V |
| VDD | 19 | +12V |
| VBB | 21 | -5V |
| GND | 12 | 0V |
| GND | 22 | 0V |

### HM7641 - 512B bipolar PROM with three-state outputs and four fixed-polarity chip selects

**Package:** 24-pin DIP  
**Capacity:** 512 bytes  
**Control:** /CS1, /CS2, CS3, CS4  

| Function | Pins | Notes |
|---|---|---|
| Address (A0-A8) | 8,7,6,5,4,3,2,1,23 | 9 address lines |
| Data (D0-D7) | 9,10,11,13,14,15,16,17 | 8 data lines |
| /CS1 | 21 | Active low |
| /CS2 | 20 | Active low |
| CS3 | 19 | Active high |
| CS4 | 18 | Active high |
| VCC | 24 | +5V |
| GND | 12 | 0V |

### 2708 - 1KB EPROM with multiple supply voltages

**Package:** 24-pin DIP  
**Capacity:** 1024 bytes  
**Control:** /CE, /OE  

| Function | Pins | Notes |
|---|---|---|
| Address (A0-A9) | 8,7,6,5,4,3,2,1,23,22 | 10 address lines |
| Data (D0-D7) | 9,10,11,13,14,15,16,17 | 8 data lines |
| /CE | 18 | Active low |
| /OE | 20 | Active low |
| VPP | 18 | Low during read during read |
| PE | 20 | Low during read during read |
| VCC | 24 | +5V |
| VDD | 19 | +12V |
| VBB | 21 | -5V |
| GND | 12 | 0V |

### 2716 - 2KB EPROM with fixed active-low CE/OE

**Package:** 24-pin DIP  
**Capacity:** 2048 bytes  
**Control:** /CE, /OE  

| Function | Pins | Notes |
|---|---|---|
| Address (A0-A10) | 8,7,6,5,4,3,2,1,23,22,19 | 11 address lines |
| Data (D0-D7) | 9,10,11,13,14,15,16,17 | 8 data lines |
| /CE | 18 | Active low |
| /OE | 20 | Active low |
| VPP | 21 | VCC during read during read |
| PE | 20 | Low during read during read |
| VCC | 24 | +5V |
| GND | 12 | 0V |

### 28C16 - 2KB EEPROM with fixed active-low CE/OE

**Package:** 24-pin DIP  
**Capacity:** 2048 bytes  
**Control:** /CE, /OE, /WRITE  

| Function | Pins | Notes |
|---|---|---|
| Address (A0-A10) | 8,7,6,5,4,3,2,1,23,22,19 | 11 address lines |
| Data (D0-D7) | 9,10,11,13,14,15,16,17 | 8 data lines |
| /CE | 18 | Active low |
| /OE | 20 | Active low |
| /WRITE | 21 | Active low |
| VCC | 24 | +5V |
| GND | 12 | 0V |

### 6116 - 2KB (2048 x 8-bit) Static RAM with fixed active-low CE/OE/WE

**Package:** 24-pin DIP  
**Capacity:** 2048 bytes  
**Control:** /CE, /OE, /WRITE  

| Function | Pins | Notes |
|---|---|---|
| Address (A0-A10) | 8,7,6,5,4,3,2,1,23,22,19 | 11 address lines |
| Data (D0-D7) | 9,10,11,13,14,15,16,17 | 8 data lines |
| /CE | 18 | Active low |
| /OE | 20 | Active low |
| /WRITE | 21 | Active low |
| VCC | 24 | +5V |
| GND | 12 | 0V |

### 2732 - 4KB EPROM with fixed active-low CE and shared OE/VPP

**Package:** 24-pin DIP  
**Capacity:** 4096 bytes  
**Control:** /CE, /OE  

| Function | Pins | Notes |
|---|---|---|
| Address (A0-A11) | 8,7,6,5,4,3,2,1,23,22,19,21 | 12 address lines |
| Data (D0-D7) | 9,10,11,13,14,15,16,17 | 8 data lines |
| /CE | 18 | Active low |
| /OE | 20 | Active low |
| VPP | 20 | Acts as /OE during read |
| PE | 18 | Low during read during read |
| VCC | 24 | +5V |
| GND | 12 | 0V |

### 2764 - 8KB EPROM with fixed active-low CE/OE

**Package:** 28-pin DIP  
**Capacity:** 8192 bytes  
**Control:** /CE, /OE  

| Function | Pins | Notes |
|---|---|---|
| Address (A0-A12) | 10,9,8,7,6,5,4,3,25,24,21,23,2 | 13 address lines |
| Data (D0-D7) | 11,12,13,15,16,17,18,19 | 8 data lines |
| /CE | 20 | Active low |
| /OE | 22 | Active low |
| VPP | 1 | VCC during read during read |
| /PGM | 27 | High during read during read |
| VCC | 28 | +5V |
| GND | 14 | 0V |

### 28C64 - 8KB EEPROM with fixed active-low CE/OE

**Package:** 28-pin DIP  
**Capacity:** 8192 bytes  
**Control:** /BUSY, /CE, /OE, /WRITE  

| Function | Pins | Notes |
|---|---|---|
| Address (A0-A12) | 10,9,8,7,6,5,4,3,25,24,21,23,2 | 13 address lines |
| Data (D0-D7) | 11,12,13,15,16,17,18,19 | 8 data lines |
| /BUSY | 1 | Active low |
| /CE | 20 | Active low |
| /OE | 22 | Active low |
| /WRITE | 27 | Active low |
| VCC | 28 | +5V |
| GND | 14 | 0V |

### 27128 - 16KB EPROM with fixed active-low CE/OE

**Package:** 28-pin DIP  
**Capacity:** 16384 bytes  
**Control:** /CE, /OE  

| Function | Pins | Notes |
|---|---|---|
| Address (A0-A13) | 10,9,8,7,6,5,4,3,25,24,21,23,2,26 | 14 address lines |
| Data (D0-D7) | 11,12,13,15,16,17,18,19 | 8 data lines |
| /CE | 20 | Active low |
| /OE | 22 | Active low |
| VPP | 1 | VCC during read during read |
| /PGM | 27 | High during read during read |
| VCC | 28 | +5V |
| GND | 14 | 0V |

### 27256 - 32KB EPROM with fixed active-low CE/OE

**Package:** 28-pin DIP  
**Capacity:** 32768 bytes  
**Control:** /CE, /OE  

| Function | Pins | Notes |
|---|---|---|
| Address (A0-A14) | 10,9,8,7,6,5,4,3,25,24,21,23,2,26,27 | 15 address lines |
| Data (D0-D7) | 11,12,13,15,16,17,18,19 | 8 data lines |
| /CE | 20 | Active low |
| /OE | 22 | Active low |
| VPP | 1 | VCC during read during read |
| PE | 22 | Low during read during read |
| VCC | 28 | +5V |
| GND | 14 | 0V |

### 28C256 - 32KB EEPROM with fixed active-low CE/OE

**Package:** 28-pin DIP  
**Capacity:** 32768 bytes  
**Control:** /CE, /OE, /WRITE  

| Function | Pins | Notes |
|---|---|---|
| Address (A0-A14) | 10,9,8,7,6,5,4,3,25,24,21,23,2,26,1 | 15 address lines |
| Data (D0-D7) | 11,12,13,15,16,17,18,19 | 8 data lines |
| /CE | 20 | Active low |
| /OE | 22 | Active low |
| /WRITE | 27 | Active low |
| VCC | 28 | +5V |
| GND | 14 | 0V |

### 62256 - 32KB (32768 x 8-bit) Static RAM with fixed active-low CE/OE/WE

**Package:** 28-pin DIP  
**Capacity:** 32768 bytes  
**Control:** /CE, /OE, /WRITE  

| Function | Pins | Notes |
|---|---|---|
| Address (A0-A14) | 10,9,8,7,6,5,4,3,25,24,21,23,2,26,1 | 15 address lines |
| Data (D0-D7) | 11,12,13,15,16,17,18,19 | 8 data lines |
| /CE | 20 | Active low |
| /OE | 22 | Active low |
| /WRITE | 27 | Active low |
| VCC | 28 | +5V |
| GND | 14 | 0V |

### 27512 - 64KB EPROM with fixed active-low CE/OE

**Package:** 28-pin DIP  
**Capacity:** 65536 bytes  
**Control:** /CE, /OE  

| Function | Pins | Notes |
|---|---|---|
| Address (A0-A15) | 10,9,8,7,6,5,4,3,25,24,21,23,2,26,27,1 | 16 address lines |
| Data (D0-D7) | 11,12,13,15,16,17,18,19 | 8 data lines |
| /CE | 20 | Active low |
| /OE | 22 | Active low |
| VPP | 22 | VCC during read during read |
| PE | 20 | Low during read during read |
| VCC | 28 | +5V |
| GND | 14 | 0V |

### 28C512 - 64KB EEPROM with fixed active-low CE/OE

**Package:** 32-pin DIP  
**Capacity:** 65536 bytes  
**Control:** /CE, /OE, /WRITE  

| Function | Pins | Notes |
|---|---|---|
| Address (A0-A15) | 12,11,10,9,8,7,6,5,27,26,23,25,4,28,29,3 | 16 address lines |
| Data (D0-D7) | 13,14,15,17,18,19,20,21 | 8 data lines |
| /CE | 22 | Active low |
| /OE | 24 | Active low |
| /WRITE | 30 | Active low |
| VCC | 32 | +5V |
| GND | 16 | 0V |

### 27C010 - 128KB EPROM with fixed active-low CE/OE

**Package:** 32-pin DIP  
**Capacity:** 131072 bytes  
**Control:** /CE, /OE  

| Function | Pins | Notes |
|---|---|---|
| Address (A0-A16) | 12,11,10,9,8,7,6,5,27,26,23,25,4,28,29,3,2 | 17 address lines |
| Data (D0-D7) | 13,14,15,17,18,19,20,21 | 8 data lines |
| /CE | 22 | Active low |
| /OE | 24 | Active low |
| VPP | 1 | Don't care during read during read |
| /PGM | 31 | Don't care during read during read |
| VCC | 32 | +5V |
| GND | 16 | 0V |

### 27C301 - 128KB EPROM with fixed active-low CE/OE

**Package:** 32-pin DIP  
**Capacity:** 131072 bytes  
**Control:** /CE, /OE  

| Function | Pins | Notes |
|---|---|---|
| Address (A0-A16) | 12,11,10,9,8,7,6,5,27,26,23,25,4,28,29,3,24 | 17 address lines |
| Data (D0-D7) | 13,14,15,17,18,19,20,21 | 8 data lines |
| /CE | 22 | Active low |
| /OE | 2 | Active low |
| VPP | 1 | Don't care during read during read |
| /PGM | 31 | Don't care during read during read |
| VCC | 32 | +5V |
| GND | 16 | 0V |
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

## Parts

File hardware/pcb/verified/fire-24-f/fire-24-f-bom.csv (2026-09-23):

Reference | Qty | Value | DNP | Exclude from BOM | Exclude from Board | Footprint | Datasheet | LCSC
C1,C2,C7,C13,C15,C16,C17 | 7 | 4.7uF |  |  |  | Capacitor_SMD:C_0402_1005Metric | ~ | C23733
C3,C4,C5,C6,C8,C9,C10,C11,C12,C14 | 10 | 0.1uF |  |  |  | Capacitor_SMD:C_0201_0603Metric | ~ | C307380
C18,C19 | 2 | 15pF |  |  |  | Capacitor_SMD:C_0201_0603Metric | ~ | C85891
D1 | 1 | LED_Small |  |  |  | LED_SMD:LED_0402_1005Metric | ~ | C25503345
D2,D3 | 2 | 1N5819WS |  |  |  | Diode_SMD:D_SOD-323 |  | C191023
D4 | 1 | XL-1010RGBC-WS2812B |  |  |  | piers retro:XL-1010RGBC-2812B | https://jlcpcb.com/partdetail/XINGLIGHT-XL_1010RGBC2812B/C5349953 | C5349953
J4 | 1 | USB_C_Receptacle_USB2.0_16P |  |  |  | piers retro:USB_C_connector_c2765186 | https://www.usb.org/sites/default/files/documents/usb_type-c.zip | C2765186
L1 | 1 | 3.3u |  |  |  | RP2350_60QFN_minimal:L_pol_2016 | ~ | C42411119
R1,R3,R7,R8 | 4 | 10K |  |  |  | Resistor_SMD:R_0201_0603Metric | ~ | C473048
R2,R5,R6,R11 | 4 | 1K |  |  |  | Resistor_SMD:R_0201_0603Metric | ~ | C270365
R4 | 1 | 33R |  |  |  | Resistor_SMD:R_0402_1005Metric | ~ | C25105
R9,R10 | 2 | 5K1 |  |  |  | Resistor_SMD:R_0201_0603Metric | ~ | C270344
U1 | 1 | RP2350_60QFN |  |  |  | RP2350_60QFN_minimal:RP2350-QFN-60-1EP_7x7_P0.4mm_EP3.4x3.4mm_ThermalVias |  | C41378174
U3 | 1 | AP2112K-3.3 |  |  |  | Package_TO_SOT_SMD:SOT-23-5 |  | C51118
U4 | 1 | USBLC6-2P6 |  |  |  | Package_TO_SOT_SMD:SOT-666 | https://www.st.com/resource/en/datasheet/usblc6-2.pdf | C15999
Y1 | 1 | Crystal_GND24 |  |  |  | Crystal:Crystal_SMD_Abracon_ABM8G-4Pin_3.2x2.5mm | ~ | C20625731

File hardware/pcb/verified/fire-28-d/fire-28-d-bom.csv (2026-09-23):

Reference | Qty | Value | DNP | Exclude from BOM | Exclude from Board | Footprint | Datasheet | LCSC
C1,C2,C3,C7,C13,C14,C15,C16,C17 | 9 | 4.7uF |  |  |  | Capacitor_SMD:C_0402_1005Metric | ~ | C23733
C4,C5,C6,C8,C9,C10,C11,C12,C20,C21,C22 | 11 | 0.1uF |  |  |  | Capacitor_SMD:C_0402_1005Metric | ~ | C1525
C18,C19 | 2 | 15pF |  |  |  | Capacitor_SMD:C_0402_1005Metric | ~ | C1548
D1 | 1 | LED_Small |  |  |  | LED_SMD:LED_0402_1005Metric | ~ | C25503345
D2,D3 | 2 | 1N5819WS |  |  |  | Diode_SMD:D_SOD-323 |  | C191023
D4 | 1 | XL-1010RGBC-WS2812B |  |  |  | piers retro:XL-1010RGBC-2812B | https://jlcpcb.com/partdetail/XINGLIGHT-XL_1010RGBC2812B/C5349953 | C5349953
J1 | 1 | MC-118LD-H65 |  |  |  | piers retro:USB-C-upright-C6332304-hanbo-MC-118LD-H65 | https://jlcpcb.com/api/file/downloadByFileSystemAccessId/8590905213601456128 | C6332304
L1 | 1 | 3.3u |  |  |  | RP2350_60QFN_minimal:L_pol_2016 | ~ | C42411119
R1,R7,R8 | 3 | 10K |  |  |  | Resistor_SMD:R_0402_1005Metric | ~ | C25744
R2,R3,R5,R6 | 4 | 1K |  |  |  | Resistor_SMD:R_0402_1005Metric | ~ | C11702
R4 | 1 | 33R |  |  |  | Resistor_SMD:R_0402_1005Metric | ~ | C25105
R9,R10 | 2 | 5K1 |  |  |  | Resistor_SMD:R_0402_1005Metric | ~ | C25905
U1 | 1 | RP2354B |  |  |  | RP2350B:RP2350-QFN-80-1EP_10x10_P0.4mm_EP3.4x3.4mm_ThermalVias |  | C39843328
U3 | 1 | AP2112K-3.3 |  |  |  | Package_TO_SOT_SMD:SOT-23-5 |  | C51118
U4 | 1 | USBLC6-2P6 |  |  |  | Package_TO_SOT_SMD:SOT-666 | https://www.st.com/resource/en/datasheet/usblc6-2.pdf | C15999
Y1 | 1 | Crystal_GND24 |  |  |  | Crystal:Crystal_SMD_Abracon_ABM8G-4Pin_3.2x2.5mm | ~ | C20625731

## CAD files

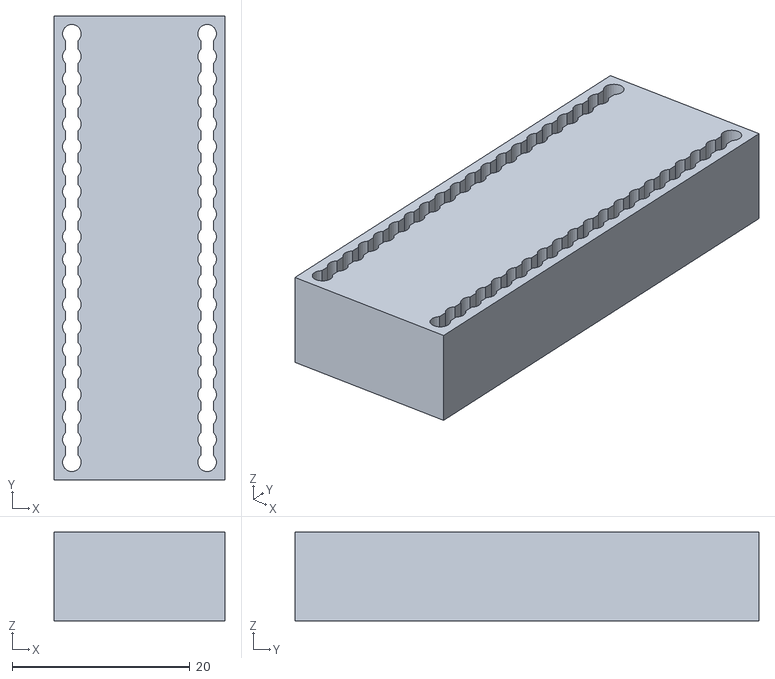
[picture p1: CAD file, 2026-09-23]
hardware/3d/tools/one-rom-pogo-pin-jig-40.stl
19.2 x 52.3 x 10.0

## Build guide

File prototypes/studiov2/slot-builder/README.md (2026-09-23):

# Slot builder prototype

The website's One ROM Builder tab, rebuilt in Iced 0.14.

**Question.** Does the web builder's design survive the move to a Rust GUI
toolkit, and how much work is it?

**Answer. Yes, at about the same size as the web version.** Roughly 1,200 lines
of UI and drawing, 300 of it the board wireframe on a canvas, against the
website's 1,100 of JS plus 90 of HTML and 480 of CSS. Clean build 58s,
incremental 2.6s.

## Run

```bash
cargo run
```

## Driven by the real crates

Board list, jumper header geometry, chip types per board, chip sizes, the number
of chip-select dropdowns each chip type needs, file formats and the flash total
all come from `onerom-config` and `onerom-gen`. Build runs the real
`onerom_gen::Builder` pipeline with the tree's own plugin binaries from
`plugins/dist/`.

## Not done

- **Build output is metadata and ROM images.** A flashable image also needs the
  base firmware downloaded and padded to 48KB on the front.
- **ROM types come out in the crates' order, not the website's.** The website
  sorts them in `js/site/utils.js`, which carries a hand-written size table.
  That sort belongs in Rust, reachable from the apps and from WASM.
- Firmware versions are a hardcoded list rather than a manifest fetch.
- The plugin catalogue is read off disk, so no `min_fw_version` check runs.
- No licence acceptance, no tooltips, no device I/O.

## Against the web original

Iced has no letter-spacing, so the small-caps group titles are untracked, and
there are no transitions. Dropdowns and scrollbars are Iced's rather than the
platform's. Fonts are the same Inter and Michroma the website uses, embedded
from copies already in this repo.

## Screenshots without a screen-recording grant

`ONEROM_PROTO_SHOT` is a path to write a PNG to, `ONEROM_PROTO_SIZE` is
`WIDTHxHEIGHT`, and `ONEROM_PROTO_SETUP` is a comma-separated script —
`nohelp`, `board:fire-28-d`, `add`, `chip:0:23128`, `file:0:/path/to.bin`.

```bash
ONEROM_PROTO_SHOT=/tmp/shot.png ONEROM_PROTO_SETUP=nohelp,board:fire-28-d cargo run
```

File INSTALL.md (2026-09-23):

# INSTALL

One ROM requires a fairly involved toolchain to build, due to the extent of the project (embedded firmware, extensive RUST tooling, desktop application, webassembly, etc).

You are _strongly_ recommended to use the [Docker container](ci/docker/README.md#building-one-rom) to build the One ROM firmware, as this contains a pre-configured build environment that works across multiple host platforms.

If you'd like to build the toolchain and dependencies locally, read on.

This document covers installing the toolchain and dependencies on linux (primarily focusing on an x86_64 Debian-based distribution, although notes are also provided for an ARM64 based host).

Other hosts (Mac, Windows) are possible, and it is recommended to use macOS for building One ROM Studio for Mac, and Windows for building Windows installers.

However, we strongly recommend sticking to a *nix based host (Linux or macOS) for building the One ROM firmware itself, and instructions for settig up a full Windows build host are not included below.

If you need to do Windows builds of the CLI or Studio, see [Setting up a Windows build machine](/docs/SETUP-WINDOWS-BUILD-MACHINE.md).

0. Install pre-requisites

    ```bash
    sudo apt -y install git build-essential curl pkg-config
    ```

1. Clone the repository:

    ```bash
    git clone https://github.com/piersfinlayson/one-rom.git
    cd one-rom
    ```

2. Install the required ARM GNU toolchain.  You have options here.

    - Install it [from ARM's website](https://developer.arm.com/downloads/-/arm-gnu-toolchain-downloads) for AArch32 bare-metal target (arm-none-eabi).

        Recommended approach - download the toolchain from ARM's developer site (this is quite large, so may take a while) - this is for x86_64 linux hosts::

        ```bash
        wget https://developer.arm.com/-/media/Files/downloads/gnu/14.3.rel1/binrel/arm-gnu-toolchain-14.3.rel1-x86_64-arm-none-eabi.tar.xz
        tar -xvf arm-gnu-toolchain-14.3.rel1-x86_64-arm-none-eabi.tar.xz
        sudo mv arm-gnu-toolchain-14.3.rel1-x86_64-arm-none-eabi /opt/
        ```

        If you are on ARM64 linux, or a Mac (Intel or ARM), select the correct version from ARM's site.  Again update TOOLCHAIN.

    - Install it via your package manager, e.g., on Debian/Ubuntu:

        ```bash
        sudo apt -y install gcc-arm-none-eabi
        ```

    Now you will need to update the `TOOLCHAIN` environment variable in your shell or variable in the [Makefile](firmware/Makefile) to point to the correct compiler binary directory.  It should probably `/usr/bin` or `/opt/arm-gnu-toolchain-14.3.rel1-darwin-arm64-arm-none-eabi/bin` or similar.

    If on an ARM64 host you will also need x86_64-linux-gnu cross tools:

    ```bash
    sudo apt -y install gcc-x86-64-linux-gnu
    ```

3. Install the following packages required for building and testing.  `vice` is optional.  (`vice` is used to build some Commodore demo programs.):

    ```bash
    sudo apt -y install jq libcurl4-openssl-dev libzip-dev libjson-c-dev vice
    ```

    If you are using a different package manager, the package name may vary slightly, e.g., `libcurl-devel` on Fedora.

    On macOS you would be using [Homebrew](https://brew.sh/).

4. Install [Rust](https://www.rust-lang.org/tools/install) - this will take a while:

    ```bash
    curl --proto '=https' --tlsv1.2 -sSf https://sh.rustup.rs | sh
    source $HOME/.cargo/env
    cargo install cross
    cargo install wasm-pack   # Only required to build one-rom-wasm
    cargo install cargo-dist  # Only required to build One ROM Studio installers
    ```

    The One ROM hardware tester (`onerom-lab`) runs on the RP2350 and is built
    with the nightly toolchain (pinned by its `rust-toolchain.toml`).  You only
    need this if you are building the tester:

    ```bash
    rustup toolchain install nightly --component clippy,rustfmt --target thumbv8m.main-none-eabihf
    ```

    If planning to build One ROM Studio for all possible targets (you likely only want to build a subset!) you will also need to install additional Rust targets and the mingw-w64 toolchain for Windows targets.  If you just want to build the One ROM firmware you do not need to do this step.
    
    ```bash
    rustup target install \
        x86_64-unknown-linux-gnu \
        aarch64-unknown-linux-gnu \
        x86_64-pc-windows-gnu \
        aarch64-pc-windows-gnullvm \
        x86_64-pc-windows-msvc \
        aarch64-pc-windows-msvc \
        x86_64-apple-darwin \
        aarch64-apple-darwin
    sudo apt -y install mingw-w64
    ```

5. Install [probe-rs](https://probe.rs/) for flashing the firmware to One ROM using an SWD programmer.  This is optional if you want to just build the firmware and use another tool to flash it.

    ```bash
    curl --proto '=https' --tlsv1.2 -LsSf https://github.com/probe-rs/probe-rs/releases/latest/download/probe-rs-tools-installer.sh | sh
    probe-rs complete install
    ```

6. Give yourself access to a One ROM over USB.  Without this the CLI and Studio
   find your device but cannot open it, reporting `could not be opened`, and
   `onerom monitor log` loses One ROM's boot log to ModemManager.

    ```bash
    sudo cp rust/cli/scripts/69-onerom-cli.rules /etc/udev/rules.d/
    sudo udevadm control --reload
    sudo usermod -aG plugdev $USER
    ```

    The rule applies to a device node as it is created, so unplug and replug the
    One ROM afterwards.  Group membership is picked up by a new login, so start
    a new session too - over SSH that means dropping any multiplexed connection
    first, or `newgrp plugdev` in the shell you have.

    The packaged Studio installs this rule for you, so this step is for building
    from source.

7. Connect up One ROM to your [programmer](README.md#programmer).

At this point you can follow the instructions below to build and flash the firmware.

## Building the Firmware

To build the base firmware, run `make` from the repo root.  Add `DEBUG_LOGGING=1` for debug logging.

To build a firmware image to flash to a One ROM, you use the CLI tool, which you can build from `rust/cli` or download from [One ROM CLI](https://onerom.org/cli).  For example:

```bash
onerom firmware build --base-firmware firmware/build/onerom-rp235x.bin --config onerom-config/vic20-pal.json /tmp/firmware.bin
```

## Programming the Firmware

### USB

USB is the simplest way to program One ROM if your hardware revision supports.

After building the firmware as above, use the binary from `firmware/build/onerom-rp235x.bin` and one of the following tools to update the firmware of your device.  You have two official One ROM options:
- [One ROM CLI](https://onerom.org/cli)
- [One ROM Studio](https://onerom.org/studio)
- [One ROM Web](https://onerom.org/web)

If all cases, you need to select the option to upload a local firmware binary, and then program it.

You also have board specific, third-party, options:

#### Fire Boards

- [pico⚡flash](https://picoflash.org) - A web based RP2040/RP2350 flash by One ROM's author. 
- [picotool](https://github.com/raspberrypi/picotool) - A command line tool from Raspberry Pi for programming Raspberry Pi RP2040/RP2350-based boards.

As well as `firmware/build/onerom-rp235x.bin`, if you have [picotool](https://github.com/raspberrypi/picotool) installed and in your path, a UF2 file is created as part of the build for Fire boards at `firmware/build/onerom-rp235x.uf2`.

For a factory fresh Fire board, you can copy this UF2 to the RP2350 filesystem that mounts when you plug in the Fire board to program it.

Note that the RP2350 filesystem is not automatically mounted when plugged into USB once you have One ROM firmware v0.6.0+ installed, but you can access it by pulling BOOT to GND on power up to enter this mode.

### SWD Programmer

Using SWD has an advantage over USB of being able to view debug logs from One ROM after re-programming.

However, you will need to find some way to power One ROM while programming, as, unlike USB, SWD does not provide power.  You can power One ROM by installing it in your retro system and powering that on, or by providing 5V and GND to the appropriate pins on One ROM directly.  ⚠️ If you are powering One ROM directly, **do not** install it in a retro system at the same time, as this may damage your One ROM, programmer, or retro system.

There are many tools that can be used to program One ROM via an SWD programmer.  We use [probe-rs](https://probe.rs/), which you may have installed already.

If you installed `probe-rs`, you can a command like this to build and flash the firmware using an SWD programmer in a single step - replace XXX with the appropriate build config for your hardware revision, MCU and ROM set configuration:

```bash
XXX make run
```

Note that as well as `firmware/build/onerom-rp235x.bin`, an ELF file is created at `firmware/build/onerom-rp235x.elf` which can be used with other SWD programming tools, as it contains build symbols.  This is particularly useful for attaching to One ROM with the programmer, after it has been programmed, to view logs. 

See [Pi-PICO-PROGRAMMER](/docs/PI-PICO-PROGRAMMER.md) for details of using a Raspberry Pi Pico as an inexpensive SWD programmer.  Many other SWD programmers are available, like the Raspberry Pi Debug Probe, generic DAPLink, ST-Link, etc. 

If you cannot detect your One ROM, it may be bricked.  See [Recovering a bricked One ROM](/docs/CLI-MANUAL.md#recovering-a-bricked-one-rom).

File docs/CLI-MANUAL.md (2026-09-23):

<!--
Conventions of this manual, for whoever edits it.  These are invisible to a
reader: HTML comments survive pandoc into the PDF unrendered.

* Example output is a verbatim run, pasted from the command.  Hand-written
  examples drift and quietly become wrong.

* A value this manual states that something else owns sits inside a marker
  naming that source, rather than bare:

      The device's own limit is <!==[const:GPIO_MAX_HOLD_MS:seconds]==>60 seconds<!==[/]==>.

  (written there with `=` in place of `-`, so this note is not itself a
  marker).  `cargo run -p doc-gen` checks every one of them and fails naming
  the file, line, expected and found.  It writes nothing.  The sources, the
  formats and the syntax for naming several constants at once are documented in
  `rust/doc-gen/src/main.rs` and its `marker` and `format` modules.

  A number inside a quoted run is the exception and stays a plain literal: it
  records what the command printed rather than claiming what is true today.  A
  marker inside a fenced code block is refused for that reason.

* Breaking changes are carried in two sections, and a change that breaks an
  existing command line updates both.  `# New Breaking Changes`, near the top,
  lists the release in development alone.  `# Appendix: Breaking Change
  History`, at the end, keeps every release, newest first.  At release time the
  top section's entries move down under a new version heading in the appendix,
  and the top section empties for the next cycle.

* Both sections are present in every release.  Where a release has no breaking
  changes, `# New Breaking Changes` says so, so a reader who has learned to
  look there finds an answer.

* Every top-level section is preceded by `---`, which `docs/pdf/docs.css`
  renders as a page break.  A new section needs one.
-->

# One ROM CLI Manual

# Introduction

`onerom` (`onerom.exe` on Windows) is the command-line tool for managing One ROM
ROM emulators: discovering connected devices, building and flashing firmware,
inspecting device state, and manipulating ROM image files.

## About This Document

This One ROM CLI manual covers:

- **One ROM Overview** — what One ROM is, its hardware, and the vocabulary the
  rest of this manual uses.
- **CLI Guide** — installation and the common workflows.
- **CLI Reference** — every command, subcommand and option.
- **Problems** — symptoms and their fixes, including [recovering a bricked One
  ROM](#recovering-a-bricked-one-rom).

> This manual documents the `onerom` CLI as of release v<!--[version:cli]-->0.4.1<!--[/]-->. Board,
> chip and plugin lists shown in examples are illustrative — the set your build
> supports may differ. Run `onerom --version` to check your version, and
> `onerom board list` / `onerom chips` for the definitive lists your build knows
> about. Commands marked **(not yet supported)** are present in the CLI surface
> but not yet functional.

---

# New Breaking Changes

These change what an existing command line does, so a script written against an
earlier release is worth checking before upgrading.

The CLI is versioned `MAJOR.MINOR.PATCH`. While it is pre-v1.0.0, a change that
breaks an existing command line lands in a minor release — v0.3.0 to v0.4.0 —
and never in a patch. From v1.0.0 onwards such a change lands in a major
release, and never in a minor or a patch.

- **`--name` now names the One ROM, not the configuration.** It is an alias for
  `--instance-name` on `program` and `firmware build`, where it was an alias for
  `--config-name`. A command line using `--name` still runs, and names the
  device instead of the configuration it is building. Spell `--config-name` in
  full for the old meaning.

Every release's breaking changes are collected in
[Appendix: Breaking Change History](#appendix-breaking-change-history), at the
end of this manual.

---

<!--[fragment:docs/OVERVIEW.md:peer]-->
# One ROM Overview

## Background - ROM Replacements

ROM (Read-Only Memory) chips are used in a huge assortment of electronic
devices to supply those systems with pre-programmed data - Operating System
and BIOS images, character sets, programming languages, games, etc.  On old
systems these sometimes fail and need replacing, or users would like to
upgrade their system, by replacing with a ROM with newer data.  The original
ROM chip is removed from the system and a replacement is installed in its place.

Traditional ROM replacements are built around EPROMs, EEPROMs and flash chips.
Those are similar devices to the ROM being replaced - that is dumb devices
that have a persistent memory store and some control lines - but with higher capacity
than the original ROM and/or different chip select behaviour.  The chip
select logic is typically fixed with additional on-board logic.

## Introduction to One ROM

One ROM takes a different approach - it consists of a microcontroller paired
with flash and RAM, physically laid out on a PCB so that the original ROM's
address, data and chip select lines connect to the MCU's general-purpose
input/output (GPIO) pins.  This makes One ROM a ROM emulator, also known as a
Software Defined ROM.

Firmware is loaded to One ROM's flash, along with the ROM image(s) to be
served.  One ROM is installed in the system.  On power on, it boots and first
loads and runs its firmware, and then loads the ROM image(s) to be served into
RAM, and serves them from there.

Because One ROM is microcontroller based, it is controlled by software rather
than by hardwired, hardware-based logic.  This makes One ROM the most powerful
and flexible ROM replacement available.   Nearly any original ROM of a
particular form factor can be replaced by an equivalent One ROM.

One ROM's software is open source and has a modular architecture with a rich
plugin API.  This means One ROM is a platform that can be extended with new
capabilities, not just a ROM replacement.  Some examples of ways in which
people have extended One ROM include:

- A comprehensive USB stack and interface to allow One ROM to be managed
  while running, built on the public plugin API.
- Communication between a retro system and a PC using One ROM's USB port.
- A retro system controlling its own reset line using one of One ROM's header
  pins.
- Reprogramming One ROM dynamically as part of a car's ECU tuning process.

## Hardware

One ROM comes in multiple physical variants to support each supported ROM package
size - 24, 28, 32 and 40 pin.  All One ROMs replace original 600 mil (15.24mm)
wide DIP packages.  The supported ROM types are listed in
[COMPATIBILITY](/docs/COMPATIBILITY.md).  Each pin variant has multiple hardware
revisions, marked on the board.

One ROM Fire, based on the RP2350 microcontroller, is the current family and is
available in all four sizes.

One ROM Ice is a deprecated 24 pin only family based on an STM32F4.  It is
supported on Base Firmware v0.6.x.  New feature releases for One ROM Ice are not
anticipated.

## Important concepts

- **Base Firmware** - a binary including the core code that causes a One ROM to
  serve ROM images.  Does not include any information about the One ROM hardware
  variant or the ROM images to serve.  Should not be used on its own to program
  a One ROM device.

- **ROM image** - a binary blob that is the contents of a ROM to be served.  Can
  be supplied to the programming tool as a raw binary file, or in other formats,
  including Intel HEX and Motorola S-record.  The programming tool converts the
  ROM image to the format One ROM requires.

- **Slot** - a region of One ROM's flash holding a single ROM image, set of ROM
  images, or plugin.

- **Image selection** - the choice of which ROM image a One ROM serves.  A One
  ROM can hold multiple images, selected at boot using the image select jumpers
  on the board.

- **Configuration** - the description of what a One ROM should do, provided to
  the programmer.  It names the ROM images to serve, the chip type and chip
  select behaviour of each, and any settings.

- **Programmer** - a tool that composes ROM images, configuration, Base Firmware
  and metadata into a complete image, and flashes it to the device.  There are
  three - the [web programmer](https://onerom.org/web), the
  [CLI](https://onerom.org/cli) and [Studio](https://onerom.org/studio).

- **Metadata** - a binary block that describes the hardware properties of a
  physical One ROM device, and the properties of the ROM images to be served.
  The programmer generates this metadata from the configuration provided, and
  it is included in the firmware that is flashed to the device.

- **Bootloader** - a small program contained in One ROM's own read-only memory
  that allows One ROM to be reflashed with new firmware and metadata.  The
  bootloader is always accessible, even if the firmware and metadata are
  corrupted or missing and, because it is ROM based itself, it cannot be
  corrupted or erased.

- **Header pins** - pins on the One ROM board exposing power, ground, the image
  select lines, the debug interface and spare pins for expansion.  They allow
  One ROM to be wired to the system it is installed in, or to external hardware.

- **Plugin** - a binary blob consisting of code that extends One ROM's
  capabilities beyond those provided by the core firmware.  The most common
  plugin is the System Plugin.  A user chooses which plugins to include in
  their firmware (if any) at programming time.  Up to two plugins can be
  included with a single One ROM firmware image - the System Plugin, and a
  User Plugin.

- **System Plugin** - a plugin that provides a USB stack and other capabilities
  to One ROM.  One ROM's System Plugin is shipped alongside One ROM's Base
  Firmware.  Its use is recommended for all users, except those who want to
  replace it with their own custom, replacement plugin.

- **User Plugin** - a plugin installed alongside the System Plugin providing
  additional capabilities to One ROM.  User Plugins can be developed by anyone,
  and a number of them are shipped alongside Base Firmware and System Plugin.
  User Plugins require a System Plugin to be included.  An example User Plugin
  is One ROM's Host Control plugin, which allows One ROM to be controlled by the
  system it is installed in, with no extra wiring using the ROM Bus Control
  Protocol (RBCP).

- **Setting** - a named value that changes how a One ROM behaves rather than
  what it serves.  Settings are configured by the user and written by the
  programmer.  The status LED and the CPU frequency are example settings
  supported by the Base Firmware.  Plugins may have their own settings.

- **ROM Bus Control Protocol (RBCP)** - a
  [protocol](https://github.com/piersfinlayson/rom-bus-control-protocol) that
  allows ROM emulators like One ROM to be controlled by a system it is
  installed in, with no extra wiring.  Supported by One ROM's Host Control plugin.

- **Bricked One ROM** - a One ROM device that is non-functional because it has
  been flashed with corrupted firmware or metadata, metadata for a different
  physical One ROM device, no metadata, or firmware or metadata with some other
  issue.  Bricked One ROMs can be recovered by entering One ROM's bootloader
  and reflashing them with valid firmware and metadata.  It is very unlikely
  that a bricked One ROM cannot be recovered.

## Types of One ROM Deployments

### Minimal

Consists of:

- Base Firmware
- Metadata
- At least one ROM image

Contains no plugins.  Serves the ROM image(s) to the system it is installed in,
but cannot be managed while running.

In this deployment type, when One ROM is plugged in via USB it drops
automatically into its bootloader, allowing the device to be reprogrammed, and
simultaneously stops serving the ROM image(s) to the system it is installed in.

### Standard

A Minimal Deployment plus One ROM's System Plugin, which includes a USB stack
enabling comprehensive management of the device while it is running.

This is the recommended deployment type for most users.

### Extended

A Standard Deployment plus a User Plugin.  The User Plugin may be One ROM's own,
or one written by a third party.

### Custom

A Custom Deployment is one where one or more of the following holds:

- The physical One ROM device is not manufactured from a
  [published design](/hardware/pcb/README.md).  It may be a derivative, or a
  fully custom design.

- The Base Firmware is a fork of or replacement for One ROM's Base Firmware.

- The System Plugin is replaced with a fork of or replacement for One ROM's
  System Plugin.
<!--[/]-->

---

# CLI Guide

## Installation

Download the CLI from **<https://onerom.org/cli>**. Builds are provided for:

- Windows — x86 64-bit and ARM 64-bit
- macOS - a single universal build for Intel and Apple Silicon
- Ubuntu/Debian — x86 64-bit, and ARM 64-bit (also for Raspberry Pi)

The Windows and macOS builds are digitally signed. A sha256 checksum is published
alongside every download so you can verify what you fetched.

**Windows / macOS** — unzip the archive and place the `onerom` (`onerom.exe`)
executable in a folder on your `PATH`.

**Linux** — install the `.deb` as usual, which places `onerom` on your `PATH`:

```
sudo dpkg -i onerom-cli-x.y.z-1_amd64.deb
```

(replace `x.y.z` with the version, e.g. `0.1.10`, and `amd64` with `arm64` for
the ARM/Pi build).

**Windows SmartScreen** — as a relatively new publisher, the first run may raise
a *"Windows protected your PC"* dialog. Click **More info**, confirm the
publisher reads *"Open Source Developer, Piers Finlayson"*, then **Run anyway**.

Verify it runs:

```
onerom --version
```

## Keeping the CLI up to date

The CLI does not check for updates on its own.
[`onerom self check`](#self-check) compares the current build
against the newest release published for your platform, and
[`onerom self download`](#self-download) fetches it:

```
onerom self check
onerom self download
```

`self download` saves the same artifact you would get from
<https://onerom.org/cli> — a `.deb` on Linux, a zip on Windows and macOS —
verifies it against the SHA-256 published alongside it, and prints the install
step for what it downloaded. You must install the new version.

## How One ROM talks to the CLI

The CLI communicates with a One ROM over USB using picoboot (the Raspberry Pi
bootloader protocol, extended by
[picobootx](https://github.com/piersfinlayson/picobootx)). A One ROM is reachable in two
situations:

- **Running** — normal firmware is running and serving ROMs; its USB stack
  (provided by the system USB plugin) exposes the picobootx interface.
- **Stopped** — the device is in One ROM's bootloader (BOOTSEL). A bare RP2350
  bootloader is also reachable here, which is how unprogrammed or bricked units
  are [recovered](#recovering-a-bricked-one-rom).

Some commands work in either state; some require one specifically. Each
reference entry notes when a device connection is required, and the state model
is summarised under [Device states](#device-states).

## Identifying your device

With **exactly one** One ROM connected that the CLI recognises, you don't need
to identify it — commands find it automatically, and the board type is inferred
from the device.

With **multiple** devices connected, select one with `--serial` (`-s`). It
accepts `*` and `?` wildcards:

```
onerom --serial 'A1B2*' inspect info
```

`--serial` is **global**: it can appear at any level of the command line.

A device programmed with a serial override (`program --serial-override`) reports
and is matched by that overridden serial while **Running**. When **Stopped** its
USB stack comes from the RP2350 bootrom, so it falls back to reporting its chip
ID — match it by chip ID (or reboot it to running) in that state.

Discover what's attached:

```
onerom scan
onerom scan --slots        # also list each device's ROM slots
```

Two situations need extra flags:

- **Unrecognised / unprogrammed / bricked** units: add `--unrecognised` (`-u`)
  and supply `--board`, since the board type can't be inferred. The unit must
  still answer on its picoboot USB interface — one that answers nothing is
  ignored either way, since it cannot be programmed. It reports no serial at
  all, so `--serial` cannot pick between two of them — attach one at a time,
  and see [Recovering a bricked One ROM](#recovering-a-bricked-one-rom).
- **Non-standard USB IDs**: add `--vid-pid <VID:PID>` (hex), repeatable. When
  supplied, only the given VID/PID pairs are matched.

`--board` (`-b`) can also be given on most commands to **override** the detected
board type.

## Common workflows

### Program a device from a config file

The primary workflow. Build firmware from a JSON config and flash it in one
step:

```
onerom program --config c64.json
```

`program` builds *and* flashes. To build a firmware binary **without** flashing,
use [`firmware build`](#firmware-build) instead. To build and also keep the
binary while flashing, add `--output`:

```
onerom program --config c64.json --out firmware.bin
```

### Program from `--slot` specifications

Instead of a config file, describe each ROM slot inline. Repeat `--slot` per
slot. The required chip-select lines depend on the chip type (e.g. a 2332 needs
`cs1` and `cs2`):

```
onerom program --board fire-24-e \
    --slot file=kernal.bin,type=2364,cs1=active-low \
    --slot file=basic.bin,type=2364,cs1=active-low
```

The full slot spec grammar is documented under [ROM slot
specification](#rom-slot-specification) — it covers CS polarity, size handling,
per-slot CPU frequency/voltage, the status LED and 16-bit forcing.

### Program with a plugin

Plugins masquerade as ROMs. At most one system plugin and one user plugin are
supported; a user plugin requires a system plugin. The system plugin lands in
slot 0, the user plugin in slot 1:

```
onerom program --board fire-24-e \
    --slot file=kernal.bin,type=2364,cs1=active-low \
    --plugin usb
```

`--plugin` may also be combined with `--config`. The plugins are inserted
ahead of the config's ROM slots (which shift up accordingly), so you can add a
plugin to a stock config without editing it:

```
onerom program --config c64.json --plugin usb
```

It is an error if the config already defines a plugin of its own — remove it
from the config, or drop `--plugin`.

Plugin spec forms are listed under [Plugin
specification](#plugin-specification).

### Plugin compatibility

Every plugin going into an image is checked against the compatibility window
published on the images server, whether it arrived via `--plugin` or was named
by the config's own slots. A plugin the target firmware falls outside the
window of is refused, and no image is written or flashed:

```
$ onerom firmware build --config usb-0.1.2.json --board fire-24-a --output fw.bin
Failed to execute command.
Plugin 'usb' version '0.1.2' is not compatible with firmware 0.7.0 or later.
  The selected firmware version is 0.7.1.
  Plugin version 0.2.1 supports it: https://images.onerom.org/plugins/system/usb/v0.2.1/plugin.bin
```

The last line names the newest release that does support the firmware being
built for, and the URL to point the config's plugin slot at. If no release of
that plugin supports it, the message says so instead. A pinned `--plugin
usb,version=0.1.2` is refused the same way, with the same suggestion.

The check is worth having because a plugin binary declares only the *minimum*
firmware it needs. A release withdrawn for some *newer* firmware — One ROM USB
v0.1.2, which hard faults on firmware v0.7.0 — is recorded only in the manifest,
so this is the one place it can be caught before the device stops booting.

`--verbose` reports a plugin that passed:

```
Plugin 'usb' v0.2.1 is compatible with firmware
```

A plugin loaded from a local path, or from any URL that is not an official
images-server one, has no published compatibility to check against and is built
in as-is. Under `--verbose`:

```
Plugin /home/me/my-plugin.bin is not an official One ROM plugin - no published compatibility to check
```

If the images server cannot be reached the build is not blocked — an offline
build of an otherwise valid config still works — but a `Warning:` line naming
the plugin says the check was skipped.

### Build firmware without flashing

```
onerom firmware build --config c64.json --board fire-24-e --out firmware.bin
```

### Inspect a device

```
onerom inspect info      # serial, name, board, MCU, firmware version, hw revision
onerom inspect slots     # ROM slots, with the active one marked
```

### Read the live ROM image

Read what the device would serve for a given logical ROM address (device must be
running). The top-level `peek` is an alias for `inspect peek live`:

```
onerom peek --address 0x100 --length 64
onerom peek --address 0 --length 8192 --output rom-image.bin
```

### Patch a running image

`poke live` writes to the ROM image currently being served, at a logical ROM
offset. Changes are transient — lost on reboot. The top-level `poke` is an alias
for `control poke live`:

```
onerom poke --address 0x100 --byte 0xEA
onerom poke --address 0 --input patch.bin
```

For file patches you can write only the differing bytes, and preview first:

```
onerom poke --input patch.bin --delta --dry-run
onerom poke --input patch.bin --delta
```

### Identify a physical unit

Make the status LED beacon so you can spot which board is which:

```
onerom control led beacon
```

### Reset the host system after programming

If you have run a wire from a One ROM header pad to the reset line of the
machine One ROM is installed in, One ROM can pulse that pad low and then release
it — resetting the host so it picks up the image you just flashed. Name the pad,
or the MCU GPIO behind it — `onerom inspect header` shows which that is:

```
onerom program --config c64.json --reset-host sel_c
```

`--reset-host` waits for the One ROM to come back on the USB bus and then sends
the pulse, so programming and resetting are one command. To reset a host without
programming it, or to choose the length of the pulse, use `control reset`:

```
onerom control reset --pin sel_c
onerom control reset --pin sel_c --hold 500
```

The pad is typically an image-select pad whose jumper you have removed, usually
`sel_c`, or an `X1`/`X2` pad. The device times the pulse, so an interrupted CLI
cannot leave the host held in reset. See [`control reset`](#control-reset), and
[`control pin`](#control-pin) for driving a GPIO to an arbitrary state.

### See what One ROM is doing with its GPIOs

```
onerom inspect gpio
```

One row per MCU GPIO: everything that GPIO is — its ROM socket signal under the
image being served, the board peripheral it drives, the header pad it surfaces
on — plus direction, level, 5V tolerance, and what One ROM itself is using it
for. GPIOs connected to nothing are omitted unless you pass `--all`. Useful
before driving a pin — see [`inspect gpio`](#inspect-gpio).

### Watch a device's log

```
onerom monitor log
```

Prints the One ROM's firmware and plugin logging as it is written, and starts
with whatever it has logged since anything last listened — so the boot log is
still there when you attach. Needs a running One ROM with the USB system
plugin. Add `--output <FILE>` to keep a transcript, or use
`onerom program --config c64.json --follow` to go straight from programming to
watching. See [`monitor log`](#monitor-log).

### Erase a device

Erase flash. This is best done while stopped; by default the command reboots the
device into the required state first. A fully erased unit falls back to One
ROM's bootloader and is then reprogrammed with `--unrecognised` + `--board`, as
[Recovering a bricked One ROM](#recovering-a-bricked-one-rom) describes:

```
onerom control erase --all
onerom control erase --offset 0x20000 --length 0x1000
```

Read [`control erase`](#control-erase) before using it while the device is
running — erasing the core firmware or system plugin will take down the USB
stack.

### Prepare a 16-bit ROM image

16-bit ROM types (e.g. 27C400) may need their byte pairs swapped to match the
order One ROM expects. Either rewrite the file first:

```
onerom image swap-bytes --input kick.bin --output kick-swapped.bin
```

or let the build do it, leaving the source file untouched:

```
onerom program --slot file=kick.bin,type=27C400,transform=swap_bytes
```

If your image interleaves several devices in one file — a 32-bit ROM set, say —
`deinterleave` extracts a single lane. See
[Image transforms](#image-transforms) for the full set and how they compose.

## Device states

Many commands reboot the device and, by default, pause briefly afterwards to let
it re-enumerate on the USB bus.

- **Running** (default reboot target) — firmware active, serving ROMs.
- **Stopped** — One ROM/RP2350 bootloader (BOOTSEL), required for some flash
  operations.

Common controls, where a command supports them:

- `--running` (`-r`) / `--stopped` (`-p`) — choose the post-operation state.
- `--no-reboot` — leave the device as-is.
- `--fast` — skip the re-enumeration pause.
- `--msd` (`-m`) — mount the mass-storage device when rebooting into stopped
  mode.

## Global behaviour worth knowing

- `--yes` (`-y`) auto-confirms all prompts (non-interactive use). It also
  suppresses the confirmation otherwise required for CPU frequencies above
  150 MHz and voltages above 1.10 V in slot specs. Use with care.
- `--verbose` (`-v`) prints device-selection progress and other detail.
- `--log-level <LEVEL>` sets log verbosity; defaults to `warn`. Run
  `onerom --help` for the accepted levels.

---

# CLI Reference

## Synopsis

```
onerom [GLOBAL OPTIONS] <COMMAND> [ARGS]
```

## Global options

Available on every command (they are `global` in clap terms and may appear at
any level).

| Option | Description |
|---|---|
| `--serial, -s <DEVICE>` | Select a One ROM by serial number. Required when multiple are connected; auto-selected when exactly one is present. Accepts `*` and `?` wildcards. |
| `--vid-pid <VID:PID>` (alias `--id`) | USB vendor/product ID pair in hex (e.g. `1234:abcd`). Repeatable; when given, only these pairs are matched. Use with `--unrecognised`. |
| `--unrecognised, -u` (alias `--unrecognized`) | Allow management of unrecognised/unprogrammed/bricked RP2350 boards. The unit must still answer on its picoboot USB interface — a device that answers nothing is ignored either way. Use with caution — permits programming any attached RP2350 board. See [Recovering a bricked One ROM](#recovering-a-bricked-one-rom). |
| `--yes, -y` | Auto-confirm all prompts. Also suppresses the over-limit CPU frequency/voltage confirmations. |
| `--verbose, -v` | Enable verbose output. |
| `--log-level <LEVEL>` | Set log level. Defaults to `warn`. |
| `--version, -V` | Print version. |
| `--help, -h` | Print help. Works on any subcommand. |

Most commands accept `--board` (`-b`) to identify or override the board type,
and rely on `--serial` (global) to pick a specific device.

Ice (STM32) boards are recognised, but the CLI cannot scan, program or build
firmware for them. Where `--board` reaches a device or builds an image, naming
an Ice board is an error rather than a later failure. Commands that only report
hardware take them; each command's own entry below states what it accepts, and
[`board list`](#board-list) shows which boards are which.

## Command summary

| Command | Purpose | Device required |
|---|---|---|
| [`scan`](#scan) | Discover connected One ROMs | No |
| [`program`](#program) | Build and flash firmware to a One ROM | Yes |
| [`inspect`](#inspect) | Read-only device state and information | Yes |
| [`monitor`](#monitor) | Watch a running One ROM as it works | Yes |
| [`console`](#console) | Send data to and receive data from the machine One ROM is fitted in | Yes |
| [`control`](#control) | Transient (non-persistent) device actions | Yes |
| [`update`](#update) | Persistent device modifications | Yes |
| [`image`](#image) | ROM image file manipulation | No |
| [`firmware`](#firmware) | Build, inspect and manage firmware binaries | Varies |
| [`plugin`](#plugin) | List available plugins | No |
| [`chips`](#chips) | List supported chip types and their flash usage | No |
| [`board`](#board) | List board types, or draw a board's pin header / socket | No |
| [`self`](#self) | Check for and download new releases of the CLI itself | No |
| [`peek`](#peek-top-level-alias) | Alias for `inspect peek live` | Yes |
| [`poke`](#poke-top-level-alias) | Alias for `control poke live` | Yes |
| [`reboot`](#reboot-top-level-alias) | Alias for `control reboot` | Yes |

---

## scan

Discover and list connected One ROMs — serial, USB location, name, board type,
MCU and loaded firmware version. With `--verbose` (`-v`), each device also
shows its MCU variant and chip ID.

```
onerom scan
onerom scan --board fire-24-e
onerom scan --slots
```

| Option | Description |
|---|---|
| `--board <BOARD>` | Only show devices matching this board type. Conflicts with `--list-boards`. Must be a Fire board — a scan cannot find an Ice board. |
| `--list-boards` | List the known board types, the same listing as [`board list`](#board-list). |
| `--slots` (alias `--slot`) | Also show the ROM slot contents for each device found. Conflicts with `--list-boards`. |

Example output:

```
Scanning ... 
found 1 connected device:
  One ROM Fire 28 C - Firmware: v0.7.2 State: Running Serial: FC9D67248E8E8023
```

Device required: no.

---

## program

Build a firmware image (from a config file, inline `--slot` specs, or a supplied
binary) and flash it to a connected One ROM. This is the primary workflow.
`onerom firmware program` is an alias for this command.

```
onerom program --config c64.json
onerom program --serial '5*' --config c64.json
onerom program --board fire-24-e \
    --slot file=kernal.bin,type=2364,cs1=active-low \
    --slot file=basic.bin,type=2364,cs1=active-low
onerom program --firmware firmware.bin
onerom program --config c64.json --out firmware.bin
```

### Source of the firmware (mutually exclusive groups)

| Option | Description |
|---|---|
| `--config, -j <FILE>` (aliases `--config-file`, `--config-json`, `--json`) | ROM configuration JSON file. Conflicts with `--slot`, `--config-name`, `--config-description`, `--save-config`, `--no-config`, `--firmware`. |
| `--slot <SPEC>` (alias `--rom`) | ROM slot specification; repeatable. See [ROM slot specification](#rom-slot-specification). Conflicts with `--config`, `--no-config`, `--firmware`. |
| `--firmware <FILE>` (alias `--fw`) | Flash a pre-built complete firmware binary directly. Conflicts with `--config`, `--slot`, `--base-firmware` and `--plugin` because a pre-built firmware already contains all ROMs/plugins. Also conflicts with `--version`. |
| `--base-firmware <FILE>` | Use a local minimal firmware instead of downloading. With `--slot`, ROMs are built into it; alone, requires `--no-config`. Must be built with `EXCLUDE_METADATA=1` and `ROM_CONFIGS=`. Conflicts with `--firmware`, `--version`. |
| `--no-config` | Confirm flashing a base firmware with no ROM configuration. Only valid with `--config-name` and/or `--config-description`. Conflicts with `--config`, `--slot`, `--firmware`, and the config-override options below. |

### Configuration metadata

| Option | Description |
|---|---|
| `--plugin <SPEC>` | Plugin specification; repeatable. See [Plugin specification](#plugin-specification). May be combined with `--config`: the plugins are inserted ahead of the config's ROM slots (which shift up), and it is an error if the config already defines a plugin of its own. Conflicts with `--firmware`. |
| `--config-name <NAME>` | Name for the generated ROM configuration. Conflicts with `--config`. |
| `--config-description <DESC>` (aliases `--desc`, `--description`) | Description for the generated configuration. Defaults to *"Created by the One ROM CLI"*. Conflicts with `--config`. |
| `--save-config <FILE>` | Save the generated configuration to JSON. Only valid with `--slot` or `--no-config`. Conflicts with `--config`. |

### Per-device overrides

These are rejected with `--no-config`.

| Option | Description |
|---|---|
| `--instance-name <NAME>` (aliases `--name`, `--onerom`, `--one-rom`, `--onerom-name`, `--one-rom-name`, `--instance_name`) | Give this One ROM a name. |
| `--serial-override <SERIAL>` | Override the device's reported serial number. |
| `--logging [BOOL]` (aliases `--boot-logging`) | Enable boot logging. Takes an optional boolean; bare flag means `true`. |
| `--disable-swd [BOOL]` (aliases `--swd-disable`) | Shut SWD down before ROM serving starts, so debug port accesses to SRAM don't steal cycles from the serving DMAs. SWD is available for the whole of boot — including boot logging — and goes off until the next reset. Nothing is logged past that point, and plugins get no logging. This is not a debug lockout: the boot ROM runs before the One ROM firmware does, and BOOTSEL/PICOBOOT are unaffected. Optional boolean; bare flag means `true`. |
| `--turbo-boot [BOOL]` | Enable turbo boot — starts serving faster by not reading the image select jumpers, so the first non-plugin slot is always the one served. More than one non-plugin slot is refused unless `--force` is given. Optional boolean; bare flag means `true`. |

### Board, version and output

| Option | Description |
|---|---|
| `--board, -b <BOARD>` | Target board type. Inferred from the connected device if omitted. |
| `--version <VERSION>` | Firmware version to build against. Defaults to the latest release. Conflicts with `--firmware`, `--base-firmware`. |
| `--output, -o <FILE>` (alias `--out`) | Also write the built firmware to this file while flashing. |

### Reboot and flashing behaviour

| Option | Description |
|---|---|
| `--stopped, -p` | After flashing, reboot into stopped (bootloader) mode. Conflicts with `--running`. |
| `--running, -r` | After flashing, reboot into running mode (the default). Conflicts with `--stopped`. |
| `--no-reboot` | Do not reboot after flashing. Conflicts with `--stopped`. |
| `--fast` | Skip the re-enumeration pause after the final reboot. Conflicts with `--no-reboot`. |
| `--msd, -m` | Mount mass storage when rebooting into stopped mode. |
| `--verify` | Verify flash by reading back after programming. |
| `--force, -f` | Continue despite non-fatal problems: assembled firmware parse errors, a board type mismatch, and config warnings such as turbo boot with more than one non-plugin ROM slot. Each is reported as a warning instead. |
| `--batch` (aliases `--multiple`, `--multi`) | Program multiple devices, pausing for confirmation between each. Every board is programmed with the same configuration as the first. |
| `--scan-slots` | After programming, run `onerom scan --slots` to show the result. Conflicts with `--fast`. |
| `--follow` | After programming, monitor the One ROM's log, as [`monitor log`](#monitor-log) does. Runs after `--scan-slots`, and only once the One ROM is back on the USB bus, so it shows the boot log of the firmware just flashed. Refused before anything is flashed if the image has no USB system plugin, since such a One ROM leaves the bus as soon as it serves. Conflicts with `--fast`, `--stopped`, `--no-reboot` and `--batch`. |
| `--reset-host <PIN>` (alias `--host-reset`) | After programming, pulse this pin low to reset the host system, as [`control reset`](#control-reset) does. Named as `gpio<N>` or as a header pad (see [Pin values](#pin-values)). Runs after `--scan-slots` and before `--follow`, once the One ROM is back on the USB bus, and for each device in a `--batch`. The pulse is <!--[const:GPIO_RESET_DEFAULT_HOLD_MS:ms]-->100ms<!--[/]-->; use `control reset` for a different hold. Conflicts with `--fast`, `--stopped` and `--no-reboot`. |

Device required: yes.

---

## inspect

Read-only inspection of a connected One ROM.

```
onerom inspect <COMMAND>
```

| Subcommand | Purpose | Device required |
|---|---|---|
| [`info`](#inspect-info) | Identity and configuration | Yes |
| [`telemetry`](#inspect-telemetry) | Runtime telemetry **(not yet supported)** | Yes |
| [`slots`](#inspect-slots) | List ROM slots | Yes |
| [`image`](#inspect-image) | Read a slot's ROM image **(not yet supported)** | Yes |
| [`peek`](#inspect-peek) | Read SRAM or the live ROM image | Yes |
| [`gpio`](#inspect-gpio) | Show what each GPIO is and what it is doing | Yes (running) |
| [`header`](#inspect-header) | Draw the device board's pin header | Yes |
| [`socket`](#inspect-socket) | Draw the device board's ROM socket pinout | Yes |

### inspect info

Show the device's serial number, user-assigned name, board type, MCU, firmware
version and hardware revision. With `--verbose` (`-v`), also shows the MCU
variant and chip ID.

```
onerom inspect info
onerom --serial 1234abcd inspect info
```

### inspect telemetry

Access counts, timing statistics and other runtime metrics. **(not yet
supported)**

| Option | Description |
|---|---|
| `--json` | Output telemetry as JSON. |

### inspect slots

List the ROM image slots stored on the device — index, ROM type, size and
description — marking the active slot. No options.

### inspect image

Read (or save) the ROM image from a slot. **(not yet supported)**

| Option | Description |
|---|---|
| `--slot <INDEX>` | Slot index to read. Reads the active slot if omitted. |
| `--output, -o <FILE>` (alias `--out`) | Save the image data to this file. |

### inspect peek

Read device memory. `peek memory` reads SRAM (and, in stopped state,
page-aligned flash); `peek live` reads the ROM image currently being served.

```
onerom inspect peek <COMMAND>
```

#### inspect peek live

Read from the live ROM image at a **logical** ROM offset (starting at 0). The
device must be running. Also reachable as the top-level [`peek`](#peek-top-level-alias).

```
onerom inspect peek live --address 0x100 --length 64
onerom inspect peek live --address 0 --length 8192 --output rom-image.bin
```

| Option | Description |
|---|---|
| `--address, -a <ADDRESS>` (alias `--addr`) | Logical ROM address to read from, starting at 0. Decimal or `0x` hex. Default `0`. |
| `--length, -l <LENGTH>` (aliases `--len`, `--size`) | Number of bytes to read. Decimal or hex. If omitted, reads to the end of the live image. |
| `--output, -o <FILE>` (alias `--out`) | Save the data to this file. |

#### inspect peek memory

Read One ROM's SRAM. Most addresses reachable via PICOBOOT can be queried. In
stopped state, SRAM holds no meaningful data, and flash reads must be aligned to
flash page boundaries.

```
onerom inspect peek memory --address 0x20000000 --length 128
onerom inspect peek memory --address 0x10000000 --length 8192 --output flash-start.bin
```

| Option | Description |
|---|---|
| `--address, -a <ADDRESS>` (alias `--addr`) | Address to read from. Decimal or `0x` hex. |
| `--length, -l <LENGTH>` (aliases `--len`, `--size`) | Number of bytes to read. Decimal or hex. |
| `--output, -o <FILE>` (alias `--out`) | Save the data to this file. |

### inspect gpio

Show, one row per MCU GPIO, what that GPIO is on this board and what One ROM is
currently doing with it.

The device must be **running** with the USB system plugin: One ROM's own
command handler lives in that plugin, and a stopped device is in the RP2350
bootloader where it does not exist. See [Device states](#device-states).

```
onerom inspect gpio
onerom inspect gpio --all
onerom inspect gpio --pin gpio9
onerom inspect gpio --pin x1
```

| Option | Description |
|---|---|
| `--pin <PIN>` | Show only this pin, named as `gpio<N>` or as a header pad (see [Pin values](#pin-values)). Conflicts with `--all`. |
| `--board <BOARD>` | Board type, overriding what the device reports. Only needed to resolve a `--pin` pad name on a board this build does not recognise. |
| `--all` | Also list GPIOs with no function at all. By default only GPIOs connected to something are shown. |

By default the table lists only the GPIOs connected to **something** — a ROM
socket signal, a board peripheral or a header pad. On a 48-GPIO board a quarter
of the GPIOs are connected to nothing, and listing them buries the rows worth
reading; a line beneath the table says how many were omitted. `--all` lists
every GPIO. Note the filter is on what the GPIO *is*, not on what the device
reports using it for: the `X1`/`X2` and image-select pads report `free` and are
exactly what you read this table to find, so they always appear.

The number of GPIOs the device has is its own — 30 on an RP2350A, 48 on an
RP2350B.

Columns:

| Column | Meaning |
|---|---|
| `GPIO` | MCU GPIO number. |
| `Function` | Everything this GPIO is, comma-separated in a fixed order: its ROM socket signal under the image being served (`A5`, `D3`, `CS1`, `BYTE/VPP`), then the board peripheral (`Status LED`, `RGB LED`, `USB VBUS`, `ext flash CS`), then the header pad (`X1`, `X2`, `SEL_A`). `-` if the GPIO is connected to nothing. |
| `Dir` | `out` if the pin's output driver is enabled, `in` if not. |
| `Level` | The GPIO's level, `0` or `1`: what an `out` pin is driving, what an `in` pin reads. |
| `Max V` | `5V` if the GPIO is 5V-tolerant, `3V3` if it is an RP2350 ADC pin and therefore 3.3V-only, `?` if the board is not characterised. |
| `One ROM use` | What One ROM itself is using the GPIO for: `free`, `serving (read)`, `serving (driven)` or `system`. |

`Function` lists everything that applies rather than stopping at the first
match, so a GPIO that is genuinely two things says so: on a `fire-24-f` the
Status LED and the RGB LED are the same GPIO, and it reads `Status LED,
RGB LED`. Names that would repeat are shown once — on a 32-pin board a high
address line is both the socket's `A17` and the `A17` header pad, which is one
net.

`Function` names only what a **GPIO** is. A header pad may carry more than the
GPIO behind it — on a Fire 24/28 board the `SEL_C` and `SEL_D` pads sit on the
SWCLK and SWDIO nets — but SWCLK and SWDIO are dedicated RP2350 pins with no
GPIO of their own, so they do not appear here. Run
[`inspect header`](#inspect-header) for the pad-by-pad view, which shows every
role each pad carries.

Only `Dir`, `Level` and `One ROM use` come from the device. `Function` is
derived by the CLI from the board's pin map and the chip type being served: the
device deliberately reports what taking a pin over would *cost*, never what the
pin *is*. `serving (read)` pins (address, chip-select, `/BYTE`) can be driven and
released; `serving (driven)` pins (the data pins) cannot be given back without a
reboot — see [`control pin`](#control-pin).

With `--verbose` (`-v`) the table is followed by a legend restating where each
column comes from, what `Dir` and `Level` mean and what the `3V3`/`5V` tags
mean. Nothing is lost without it: the cost of taking a serving pin over is
stated at the point of action by `control pin` itself.

A board revision or ROM type this build does not recognise costs the derived
names, not the listing: `Function` falls back to `-` (or, for a socket pin whose
chip type is unknown, `socket pin <N>`), and with no recognised board at all
nothing is filtered out, since nothing can be ruled out. On a board with no
pin-header descriptor, pad names come from the board's pin assignments alone and
`--verbose` says so beneath the table.

On a Fire 28 (rev C) serving a 27512:

```
One ROM Fire 28 C - Firmware: v0.7.2 State: Running Serial: 2E4A671D1C92AE5C

GPIO state  ·  One ROM Fire 28 (rev C)  ·  RP235xB  ·  serving 27512

  GPIO  Function    Dir  Level  Max V  Current use
  ----  ----------  ---  -----  -----  ----------------
  0     D0          out  0      5V     serving (driven)
  1     D1          out  0      5V     serving (driven)
  2     D2          out  1      5V     serving (driven)
  3     D3          out  1      5V     serving (driven)
  4     D4          out  1      5V     serving (driven)
  5     D5          out  1      5V     serving (driven)
  6     D6          out  1      5V     serving (driven)
  7     D7          out  0      5V     serving (driven)
  8     X2          in   0      5V     free
  9     X1          in   0      5V     free
  10    CE/PE       in   0      5V     serving (read)
  11    OE/VPP      in   0      5V     serving (read)
  12    A14         in   0      5V     serving (read)
  13    A10         in   0      5V     serving (read)
  14    A11         in   0      5V     serving (read)
  15    A9          in   0      5V     serving (read)
  16    A8          in   0      5V     serving (read)
  17    A13         in   0      5V     serving (read)
  18    A15         in   0      5V     serving (read)
  19    A12         in   0      5V     serving (read)
  20    A7          in   0      5V     serving (read)
  21    A6          in   0      5V     serving (read)
  22    A5          in   0      5V     serving (read)
  23    A4          in   0      5V     serving (read)
  24    A3          in   0      5V     serving (read)
  25    A2          in   0      5V     serving (read)
  26    A1          in   0      5V     serving (read)
  27    A0          in   0      5V     serving (read)
  38    SEL_C       in   1      5V     free
  39    SEL_D       in   1      5V     free
  40    SEL_A       in   0      3V3    free
  41    SEL_B       in   0      3V3    free
  44    RGB LED     out  0      3V3    system
  45    Status LED  out  0      3V3    system
  46    USB VBUS    in   1      3V3    system

  13 GPIOs with no function are hidden - use --all to show them.
```

### inspect led

Show what the status LED is doing now — the mode it is in, how fast it is
running, and which GPIO it is on. Use [`inspect rgb`](#inspect-rgb) for the RGB
LED some models carry.

```
onerom inspect led
```

On a `fire-28-c` running `onerom control led flame --period 900`:

```
Status LED:
  Mode:       flame
  Period:     900ms
```

`Period` appears only for the modes that repeat.

`--verbose` adds the GPIO the LED is on, and says so where the board wires both
LEDs to one pin — a `fire-24-f` does, a `fire-28-c` does not.

No options. Device required: yes, and it must be running with the USB system
plugin.

Needs One ROM firmware v0.7.2 or later with the v0.2.2 or later USB system
plugin. An older One ROM says so rather than reporting something invented.

### inspect rgb

Show what the RGB LED is doing now — the mode, the colour, the brightness, how
fast it is running, and which GPIO it is on.

```
onerom inspect rgb
```

On a `fire-28-c` running
`onerom control rgb breathe --colour cyan --brightness 60 --period 4000`:

```
RGB LED:
  Mode:       breathe
  Colour:     #00FFFF (cyan)
  Brightness: 60%
  Period:     4000ms
```

A colour is named where it is one of the names `--colour` accepts. One that is
not prints as hex alone — `#7F3C22`.

Each repeating mode has a shortest period it can run at, and a shorter one is
refused rather than quietly run at the minimum:

| Mode | Shortest period |
|---|---|
| `cycle`, `breathe` | <!--[const:LED_CYCLE_MIN_PERIOD_MS+LED_BREATHE_MIN_PERIOD_MS:ms]-->1000ms<!--[/]--> |
| `flame` | <!--[const:LED_FLAME_MIN_PERIOD_MS:ms]-->500ms<!--[/]--> |
| `beacon`, `blink` | <!--[const:LED_BEACON_MIN_PERIOD_MS+LED_BLINK_MIN_PERIOD_MS:ms]-->50ms<!--[/]--> |

`cycle` walks the hues itself rather than showing a colour you set, so no
`Colour` is reported while it runs:

```
RGB LED:
  Mode:       cycle
  Brightness: 25%
  Period:     3000ms
```

`--verbose` adds the GPIO:

```
RGB LED:
  Mode:       cycle
  Brightness: 25%
  Period:     3000ms
  GPIO:       44
```

Only some One ROM models have an RGB LED. On a board without one this reports:

```
RGB LED: this board does not have one
```

Where the RGB LED and the status LED share a GPIO — as they do on a
`fire-24-f` — both commands report the same pin and say that it is shared. Both
LEDs still work, and no mode is restricted.

No options. Device required: yes, and it must be running with the USB system
plugin.

Needs One ROM firmware v0.7.2 or later with the v0.2.2 or later USB system
plugin.

### inspect header

Draw the connected device's pin (jumper / programming) header as ASCII. The
board is inferred from the device. This is the device-oriented form of
[`board header`](#board-header); see there for what the diagram shows.

```
onerom inspect header [--board <board>]
```

| Option | Description |
|---|---|
| `--board`, `-b` | Board type, overriding what the connected One ROM reports. Only needed on a One ROM whose board type this build does not recognise. |

`--board` is an override, not a substitute for the device: this command draws
the board of a *connected* One ROM, so one must still be present. To draw a
board by name with nothing connected, use
[`board header`](#board-header).

### inspect socket

Draw the connected device's ROM socket pinout as ASCII. The board is inferred
from the device. This is the device-oriented form of
[`board socket`](#board-socket).

```
onerom inspect socket [--board <board>] [--chip-type <chip>] [--gpio]
```

| Option | Description |
|---|---|
| `--board`, `-b` | Board type, overriding what the connected One ROM reports. |
| `--chip-type <chip>`, `-c` | Label pins with this ROM type's functions instead of GPIOs, and report the chip's image size on this board. |
| `--gpio` | Overlay the GPIO(s) onto the `--chip-type` function view (requires `--chip-type`). |

As with [`inspect header`](#inspect-header), `--board` overrides the connected
One ROM's reported board type rather than standing in for the device.

---

## monitor

Watch a running One ROM as it works.

```
onerom monitor <COMMAND>
```

| Subcommand | Purpose | Device required |
|---|---|---|
| [`log`](#monitor-log) | Show the One ROM's log as it is written | Yes |

### monitor log

Attach to the One ROM's USB serial port and print the firmware and plugin
logging it sends, until the One ROM is disconnected, rebooted or stopped, or you
press Ctrl-C.

Every attach opens with the One ROM naming itself, in a block headed
`----- One ROM USB log -----`. What it has logged since anything last listened
arrives after that, so attaching after a reboot still shows the boot log, which
opens with a `-----` divider of its own:

```
Monitoring log - press Ctrl-C to stop
----- One ROM USB log -----
One ROM fire-28-c v0.7.2
Serial: 2E4A671D1C92AE5C
Logging: boot, plugin-internal, error, plugin-application
---------------------------
-----
One ROM v0.7.2.1 https://onerom.org
Copyright (c) 2026 Piers Finlayson <piers@piers.rocks>
Built: Aug 15 2026 14:09:53
Commit: 5db495a
-----
RP235XB
RAM: 520KB
Flash: 2048KB
Freq: 150MHz
```

`Name:` appears only when the One ROM has an instance name set, and `Logging:`
lists the kinds of output switched on — see
[Logging](/docs/LOGGING.md#over-usb). A One ROM that cannot forward its log says
so there, rather than leaving you watching a silent port.

```
onerom monitor log
onerom --serial 1234abcd monitor log
onerom monitor log --output boot.txt
```

| Option | Description |
|---|---|
| `--output, -o <FILE>` (alias `--out`) | Also write the One ROM's output to this file, replacing its contents. The file receives what the One ROM sends and nothing else, so it is a transcript of the device rather than of this command. The output still appears on screen as well. |

The One ROM's output goes to stdout and everything this command says about
itself goes to stderr, so `onerom monitor log > boot.txt` captures the log on
its own. `--verbose` adds a line naming the serial port, for when you want to
point another tool at it.

What this command needs, and what it cannot do:

- The One ROM must be **running**, and must have been programmed with the USB
  system plugin. That plugin provides the serial port and forwards the log into
  it.
- Nothing is forwarded until this command — or another terminal — opens the
  port. A One ROM nothing is listening to accumulates its log rather than
  discarding it, which is why the boot log is still there when you attach.
- A debug probe reading the log over SWD consumes the same bytes. With both
  running the stream is split arbitrarily between them and neither sees all of
  it, so use one at a time.
- If nothing arrives within two seconds the command fails. Since every attach
  begins with the banner above, a One ROM with a current USB plugin always sends
  something — so a timeout points at a plugin too old to forward the log at all.

Device required: yes.

---

## console

Talk to the host system through One ROM's USB port.

```
onerom console [OPTIONS]
```

This command displays what One ROM sends, like [`monitor log`](#monitor-log),
and additionally sends what you type to the retro system. Whether and how the
retro system receives the input depends on the plugin(s) used.

By default you type a line, edit it, and press Enter to send it.  `--raw` sends
each key as you press it, for programs that read single keys.  Ctrl-C exits and
is never sent to the retro system.

```
onerom console
onerom console --raw
onerom console --line-ending crlf --output session.txt
echo 'LOAD "*",8' | onerom console
```

| Option | Description |
|---|---|
| `--output, -o <FILE>` (alias `--out`) | Also write One ROM's output to this file, replacing its contents.  The file contains only what One ROM sends.  Output is still displayed. |
| `--line-ending <ENDING>` | What Enter sends: `cr`, `lf` or `crlf`.  Default `cr`, which retro systems expect. |
| `--raw` | Send each key as you press it, not a line at a time.  No line editing.  Enter sends the line ending.  Ctrl-C exits. |
| `--no-echo` | Don't display what you type.  Use when the retro system echoes what it receives back.  Only applies with `--raw`.  In line mode the terminal displays the line as you edit it. |

If stdin is not a terminal, its contents are sent unchanged, and the command
then keeps displaying output until One ROM disconnects or you press Ctrl-C.
This can be used to send a file.

If the retro system is not reading the input pipe, typed input waits.  Once One ROM's
buffer is full, the command reports this on stderr after a second:

```
One ROM is not reading the input data
```

Input is sent, in order, once the retro system reads, and the command reports `Input resumed`.

Requirements:

- Firmware v0.7.3 or later.
- One ROM running, with both the USB and host-control plugins.
- The notes under [`monitor log`](#monitor-log) about the port, the banner,
  debug probes and the silence timeout also apply.

Device required: yes.

---

## control

Transient actions on a connected One ROM. These affect current state but do not
persist across power cycles.

```
onerom control <COMMAND>
```

| Subcommand | Purpose | Device required |
|---|---|---|
| [`reboot`](#control-reboot) | Reboot the device | Yes |
| [`led`](#control-led) | Control the status LED | Yes |
| [`poke`](#control-poke) | Write to SRAM or the live ROM image | Yes |
| [`reset`](#control-reset) | Pulse a GPIO low to reset the host system | Yes (running) |
| [`select`](#control-select) | Select the active ROM slot **(not yet supported)** | Yes |
| [`pin`](#control-pin) | Drive a pin high, low or high-impedance | Yes (running) |
| [`erase`](#control-erase) | Erase flash memory | Yes |

### control reboot

Restart the firmware; the device re-initialises and resumes serving. By default
pauses afterwards for re-enumeration. Also reachable as the top-level
[`reboot`](#reboot-top-level-alias).

```
onerom control reboot
```

| Option | Description |
|---|---|
| `--stopped, -p` | Reboot into stopped (bootloader) state. |
| `--running, -r` | Reboot into running (serving) state. Default. |
| `--fast` | Don't pause for re-enumeration. |
| `--msd, -m` | Mount mass storage when rebooting into stopped mode. Conflicts with `--running`. |

`--stopped` and `--running` are mutually exclusive.

### control led

Control the status LED — the single-colour LED every One ROM has. The RGB LED
that some models carry is driven by `control rgb` instead.

```
onerom control led on
onerom control led off
onerom control led beacon --hold 10000
onerom control led flame --period 1200
onerom control led blink
```

| Subcommand | Description |
|---|---|
| `on` | Turn the status LED on. |
| `off` | Turn the status LED off. |
| `beacon` | Beacon the LED to identify a physical unit. |
| `flame` | Flame effect on the LED. |
| `blink` | Blink the LED on and off until something changes it. |

| Option | Description | Subcommands |
|---|---|---|
| `--hold <MS>` | Stay in this mode for this many milliseconds, then go back to what the LED was doing before. The device times it, so it completes even if the command does not. Maximum <!--[const:LED_MAX_HOLD_MS]-->60000<!--[/]-->. | all |
| `--period <MS>` | Milliseconds for one repetition — one blink for `beacon` and `blink`, one pass of the flicker for `flame`. Defaults to <!--[const:LED_BEACON_DEFAULT_PERIOD_MS]-->100<!--[/]-->, <!--[const:LED_BLINK_DEFAULT_PERIOD_MS]-->1000<!--[/]--> and <!--[const:LED_FLAME_DEFAULT_PERIOD_MS]-->575<!--[/]--> respectively. Minimum <!--[const:LED_BEACON_MIN_PERIOD_MS+LED_BLINK_MIN_PERIOD_MS]-->50<!--[/]--> for `beacon` and `blink`, <!--[const:LED_FLAME_MIN_PERIOD_MS]-->500<!--[/]--> for `flame`. | `beacon`, `blink`, `flame` |

`beacon` ends by itself after <!--[const:LED_BEACON_DEFAULT_DURATION_MS:ms]-->2500ms<!--[/]--> unless `--hold` says otherwise. `blink` is
the same on-and-off toggle but slower and unbounded — it runs until something
changes it, or until a `--hold` you give it expires.

The status LED is lit or dark, so it takes no colour and no brightness. `cycle`
and `breathe` are built out of a colour and are the two modes it cannot do.

`--hold` and `--period` need One ROM firmware v0.7.2 or later with the v0.2.2 or
later USB system plugin. The CLI checks before sending, and says so rather than
reporting success on a device that would ignore them. A plain `on`, `off`,
`beacon` or `flame` works on any One ROM and costs no extra exchange with the
device.

Device required: yes.

### control rgb

Control the RGB LED that some One ROM models carry. For the single-colour status
LED every model has, see [`control led`](#control-led).

```
onerom control rgb on --colour red
onerom control rgb on --colour #FF8000 --brightness 40
onerom control rgb cycle --period 3000
onerom control rgb off
```

| Subcommand | Description |
|---|---|
| `on` | Light the LED at a colour. |
| `off` | Turn the LED off. |
| `beacon` | Beacon the LED to identify a physical unit. Ends by itself after <!--[const:LED_BEACON_DEFAULT_DURATION_MS:ms]-->2500ms<!--[/]-->. |
| `flame` | Flame effect on the LED. |
| `cycle` | Rotate through the hues. |
| `breathe` | Fade the colour up and down. |
| `blink` | Alternate the colour with dark. |

| Option | Description | Subcommands |
|---|---|---|
| `--colour <COLOUR>` (alias `--color`) | A name, or hex written `#RRGGBB` or `0xRRGGBB`. Defaults to red. | all but `off` and `cycle` |
| `--brightness <PERCENT>` | 1 to 100. Omit for the device's default, which is deliberately modest — an RGB LED at full output is uncomfortable at desk distance. | all but `off` |
| `--period <MS>` | Milliseconds for one repetition. | `beacon`, `flame`, `cycle`, `breathe`, `blink` |
| `--hold <MS>` | Stay in this mode for this many milliseconds, then go back to what the LED was doing before. The device times it, so it completes even if the command does not. Maximum <!--[const:LED_MAX_HOLD_MS]-->60000<!--[/]-->. | all |

The named colours are `red`, `green`, `blue`, `white`, `yellow`, `cyan`,
`magenta`, `orange`, `purple` and `pink`.

`cycle` chooses its own colours, so it takes no `--colour`.

Each repeating mode has a shortest period it can run at, and a shorter one is
refused rather than quietly run at the minimum:

| Mode | Default period | Shortest period |
|---|---|---|
| `cycle`, `breathe` | <!--[const:LED_CYCLE_DEFAULT_PERIOD_MS+LED_BREATHE_DEFAULT_PERIOD_MS:ms]-->5000ms<!--[/]--> | <!--[const:LED_CYCLE_MIN_PERIOD_MS+LED_BREATHE_MIN_PERIOD_MS:ms]-->1000ms<!--[/]--> |
| `flame` | <!--[const:LED_FLAME_DEFAULT_PERIOD_MS:ms]-->575ms<!--[/]--> | <!--[const:LED_FLAME_MIN_PERIOD_MS:ms]-->500ms<!--[/]--> |
| `blink` | <!--[const:LED_BLINK_DEFAULT_PERIOD_MS:ms]-->1000ms<!--[/]--> | <!--[const:LED_BLINK_MIN_PERIOD_MS:ms]-->50ms<!--[/]--> |
| `beacon` | <!--[const:LED_BEACON_DEFAULT_PERIOD_MS:ms]-->100ms<!--[/]--> | <!--[const:LED_BEACON_MIN_PERIOD_MS:ms]-->50ms<!--[/]--> |

Nothing is printed unless the CLI is verbose:

```
$ onerom --verbose control rgb on --colour orange --brightness 40
RGB LED on
```

Read back what the LED is doing with [`inspect rgb`](#inspect-rgb):

```
RGB LED:
  Mode:       on
  Colour:     #FF6000 (orange)
  Brightness: 40%
```

Only some One ROM models have an RGB LED. On a board without one, these commands
say so rather than appearing to work. Needs One ROM firmware v0.7.2 or later
with the v0.2.2 or later USB system plugin.

Device required: yes, and it must be running with the USB system plugin.

### control poke

Transient writes to device memory — changes are lost on reboot. Use
[`update`](#update) for persistent flash writes.

```
onerom control poke <COMMAND>
```

#### control poke memory

Write a single byte or a binary file to SRAM at a given address. When the device
is running, virtual addresses are available (e.g. `0x90000000` is the start of
the live ROM image — though prefer `poke live` for that). Writing arbitrary SRAM
can corrupt firmware state.

```
onerom control poke memory --address 0x20000010 --byte 0xFF
onerom control poke memory --address 0x20000000 --input patch.bin
```

| Option | Description |
|---|---|
| `--address, -a <ADDRESS>` (alias `--addr`) | Address to write to. Decimal or `0x` hex. |
| `--byte <BYTE>` (alias `--value`) | Single byte value to write. Decimal or hex. |
| `--input, -i <FILE>` (alias `--in`) | Write the contents of this binary file. |

Exactly one of `--byte` / `--input` is required.

#### control poke live

Write a single byte or a binary file to the live ROM image at a **logical** ROM
offset (starting at 0). Useful for patching a running ROM without reflashing.
Also reachable as the top-level [`poke`](#poke-top-level-alias).

```
onerom control poke live --address 0x100 --byte 0xEA
onerom control poke live --address 0 --input patch.bin
```

| Option | Description |
|---|---|
| `--address, -a <ADDRESS>` (alias `--addr`) | Logical ROM address, starting at 0. Decimal or `0x` hex. Default `0`. |
| `--byte <BYTE>` (alias `--value`) | Single byte value to write. Decimal or hex. |
| `--input, -i <FILE>` (alias `--in`) | Write the contents of this binary file. |
| `--delta` (alias `--deltas`) | Only write bytes that differ from current device content. Requires `--input`. |
| `--dry-run` (alias `--dryrun`) | Show what would be written without writing. Requires `--delta`. |

Exactly one of `--byte` / `--input` is required.

### control reset

Pulse a GPIO low, then release it, to reset the host system One ROM is installed
in — useful in scripted workflows after programming a new image.
[`program --reset-host`](#program) does the same thing as the last step of
programming, and is the shorter way to say it.

`--pin` is the pin your reset wire is soldered to, typically an image-select pad
whose jumper has been removed — `sel_c` is the usual choice, as more boards have
it than have X pads and it is 5V tolerant where it exists — or an `X1`/`X2` pad.
Name it by pad (`sel_c`, `x1`) or by MCU GPIO (`gpio9`) — see
[Pin values](#pin-values). [`inspect header`](#inspect-header) shows which GPIO
is behind each pad.

The line is only ever **driven low and then released to high impedance**. A reset
net has its own pull-up and may have other drivers on it, so there is
deliberately no way to drive it high. Use [`control pin`](#control-pin) if you
need arbitrary states.

The **device** times the pulse, not the CLI: if this command is interrupted, the
terminal closes or the cable is pulled mid-pulse, the device still releases the
pin. The device's own limit is <!--[const:GPIO_MAX_HOLD_MS:seconds]-->60 seconds<!--[/]-->.

The device must be **running** with the USB system plugin — see
[Device states](#device-states).

```
onerom control reset --pin sel_c
onerom control reset --pin gpio9
onerom control reset --pin gpio9 --hold 500
```

| Option | Description |
|---|---|
| `--pin <PIN>` | Pin the reset wire is connected to, named as `gpio<N>` or as a header pad (see [Pin values](#pin-values)). Required. |
| `--board <BOARD>` | Board type, overriding what the device reports. Only needed to resolve a `--pin` pad name on a board this build does not recognise. |
| `--hold <MS>` | Milliseconds to hold reset asserted. Decimal or `0x` hex. Default <!--[const:GPIO_RESET_DEFAULT_HOLD_MS:code]-->`100`<!--[/]-->; `0` is rejected, because a reset pulse with no end is not a reset. |

If One ROM is itself using the GPIO the command is refused, naming what it is
doing; `control reset` has no `--force` of its own, and the message points at
`control pin --force` for the case where that is genuinely what you want. If the
GPIO is not 5V-tolerant the command warns and asks for confirmation, which
`--yes` answers.

The pulse counts toward the device's limit on pins under a timed hold at once —
see [`control pin`](#control-pin).

```
$ onerom control reset --pin x1
Asserted reset on x1 (gpio9) for 100ms - the device times the pulse and releases the pin
```

### control select

Switch the device to serving the specified slot immediately (not persistent).
**(not yet supported)**

| Option | Description |
|---|---|
| `--slot <INDEX>` | Slot index to activate. Required. |

### control pin

Drive a One ROM pin high, low or high-impedance, optionally for a bounded
period.

`--pin` names an MCU GPIO or a header pad (see [Pin values](#pin-values)); the
command is named for what is being addressed rather than for any one spelling.

Without `--hold` the state is latched until something else changes it. With
`--hold` the **device** holds the state for that many milliseconds and then
applies `--then` — high impedance unless you say otherwise. As with
[`control reset`](#control-reset), the hold is timed on the device, so an
interrupted CLI cannot leave a pin latched.

A limited number of pins can have a timed `--hold` at once. A pin driven without
`--hold` is latched indefinitely and is not included in that limit. One ROM
rejects a hold on a further pin once the limit is reached.

The device must be **running** with the USB system plugin — see
[Device states](#device-states). [`inspect gpio`](#inspect-gpio) shows what each
GPIO is and what One ROM is using it for.

```
onerom control pin --pin gpio9 --state high
onerom control pin --pin gpio9 --state low --hold 250
onerom control pin --pin gpio9 --state low --hold 250 --then high
onerom control pin --pin x1 --state 0 --hold 250
onerom control pin --pin sel_a --state z
```

| Option | Description |
|---|---|
| `--pin <PIN>` | Pin to drive, named as `gpio<N>` or as a header pad (see [Pin values](#pin-values)). Required. |
| `--board <BOARD>` | Board type, overriding what the device reports. Only needed to resolve a `--pin` pad name on a board this build does not recognise. |
| `--state <STATE>` | `high`, `low`, or `z` (high-impedance). `1` and `0` are accepted for `high` and `low`. Required. |
| `--hold <MS>` | Hold `--state` for this many milliseconds, then apply `--then`. Decimal or `0x` hex. Omit to latch indefinitely. The device's own limit is <!--[const:GPIO_MAX_HOLD_MS:seconds]-->60 seconds<!--[/]-->. |
| `--then <STATE>` | State to apply when `--hold` expires: `high`, `low` or `z` (or `1`/`0`). Default `z`. Requires `--hold`. |
| `--force` | Drive the GPIO even though One ROM is using it for serving. |

**Refusals and warnings.** If One ROM is itself using the GPIO, the command is
refused and names what it is doing. `--force` overrides, and prints what that
costs:

- a pin serving **reads** (address, chip-select, `/BYTE`) is reversible — serving
  keeps reading it, and `--state z` puts it back;
- a pin serving **drives** (a data pin) is not — forcing it takes the pin away
  from the PIO that drives it, and serving stays broken until the device is
  rebooted.

If the GPIO is not 5V-tolerant — an RP2350 ADC pin, per the board metadata, not
a measurement — the command warns and asks for confirmation, which `--yes` or
`--force` answers. Nothing else about the pad is checked: what is wired to it,
whether a jumper is fitted and what voltage the far end sits at are yours to
know.

```
$ onerom control pin --pin x1 --state low --hold 2000
Set x1 (gpio9) low for 2000ms - the device times the hold and then sets it high impedance
```

### control erase

Permanently erase flash contents — firmware, metadata and ROM images. A fully
erased unit boots into One ROM's bootloader and is reprogrammed with
`--unrecognised` + `--board`.

Best performed while stopped; by default the command reboots into the required
state first. Erasing the core firmware or the system plugin while **running**
takes down the USB stack (requiring
[manual BOOTSEL](#recovering-a-bricked-one-rom)), and large erases
may cause a temporary USB drop and re-enumerate — in which case the erase likely
succeeded and can be checked with `inspect peek memory`. Anything
else running from flash (e.g. a user plugin) may crash during an erase.

Offsets are relative to the flash base `0x10000000`. Ranges must be 4096-aligned.
Multiple ranges may be erased in one operation.

```
onerom control erase --all
onerom control erase --offset 0x20000 --length 0x1000
```

| Option | Description |
|---|---|
| `--all, -a` | Erase all flash contents. |
| `--offset <OFFSET>` | Erase at offset(s) from the flash base. 4096-aligned; pair each with a `--length`; repeatable. Conflicts with `--address`. |
| `--address <ADDRESS>` (alias `--addr`) | Erase at absolute address(es). 4096-aligned; pair each with a `--length`; repeatable. Conflicts with `--offset`. |
| `--length <LENGTH>` (aliases `--len`, `--size`) | Length of each range. 4096-aligned; specify once per `--offset`/`--address`; repeatable. Conflicts with `--all`. |
| `--no-reboot, -n` | Don't reboot before or after erasing. Risky if One ROM is accessing the range. |
| `--stopped, -p` | Reboot into stopped mode after erasing. |
| `--running, -r` | Reboot into running mode after erasing. |
| `--msd, -m` | Mount mass storage when rebooting into stopped mode. Requires `--stopped`. |
| `--fast` | Don't pause for re-enumeration. Requires a reboot mode. |

One of `--all` / `--offset` / `--address` is required. `--stopped` and
`--running` are mutually exclusive, and both conflict with `--no-reboot`.

---

## update

Persistent modifications — these write to flash and survive power cycles.

```
onerom update <COMMAND>
```

| Subcommand | Purpose | Device required |
|---|---|---|
| [`slot`](#update-slot) | Write a ROM image to a flash slot **(not yet supported)** | Yes |
| [`commit`](#update-commit) | Commit the live image to flash **(not yet supported)** | Yes |
| [`otp`](#update-otp) | Read/write OTP memory **(not yet supported, hidden)** | Yes |

### update slot

Write a ROM image to a flash slot; persists across power cycles. The ROM type
and chip-select configuration must match the slot's existing configuration, or
the slot must be empty. **(not yet supported)**

```
onerom update slot --slot 2 --image kernal.bin
```

| Option | Description |
|---|---|
| `--slot <INDEX>` | Flash slot index to write. Required. |
| `--image <FILE>` | ROM image file to write. Required. |

### update commit

Persist the currently active RAM image to its corresponding flash slot. **(not
yet supported)**

```
onerom update commit
onerom update commit --slot 2
```

| Option | Description |
|---|---|
| `--slot <INDEX>` | Slot to commit. Commits the active slot if omitted. |

### update otp

Read or write RP2350 OTP memory, including One ROM-specific USB configuration and
identity data. Hidden, advanced. **OTP writes are irreversible.** **(not yet
supported)**

| Option | Description |
|---|---|
| `--read` | Read and display OTP contents. Conflicts with `--write`. |
| `--write <ROW=VALUE>` | Write a value to an OTP row. Conflicts with `--read`. |

---

## image

ROM image file manipulation. No device connection required.

```
onerom image <COMMAND>
```

### image swap-bytes

Swap adjacent byte pairs — reverses byte order within each 16-bit word
throughout the image. Required for 16-bit ROM types (e.g. 27C400) when the source
has the opposite byte order to what One ROM expects. The input must have an even
number of bytes.

```
onerom image swap-bytes --input kick.bin --output kick-swapped.bin
```

| Option | Description |
|---|---|
| `--input, -i <FILE>` (alias `--in`) | Input ROM image file. |
| `--output, -o <FILE>` (alias `--out`) | Output file path. |

The same operation is available during a build as
`--slot transform=swap_bytes`; see [Image transforms](#image-transforms).

Before writing, the input is checked against a list of known 16-bit ROM
headers. Where it is recognised and swapping it would be incorrect to program
with One ROM, a warning is printed and the swap still goes ahead:

```
$ onerom image swap-bytes --input kick-swapped.bin --output out.bin
Warning: kick-swapped.bin starts with an Amiga ROM header, low byte of each pair first.
  It is already the way One ROM needs it, and swapping the bytes will stop it
  working with One ROM.
Written to out.bin
```

See [16-bit ROM image byte ordering](#16-bit-rom-image-byte-ordering).

Device required: no.

### image deinterleave

Extract one lane from an interleaved ROM image. The image contains `--stride`
interleaved lanes of `--bytes` bytes each; lane `--offset` is kept and the rest
discarded. Used to split a wide ROM image, distributed as a single interleaved
file, into the narrower images each device needs.

The input length must be a multiple of `--bytes × --stride`; the output is
`1/--stride` of the input length.

```
# odd bytes of a 16-bit interleaved image
onerom image deinterleave --input rom16.bin --output odd.bin --offset 1 --stride 2

# byte 2 of a 32-bit interleaved image
onerom image deinterleave --input rom32.bin --output b2.bin --offset 2 --stride 4

# the upper 16-bit half of each 32-bit word
onerom image deinterleave --input rom32.bin --output hi.bin --offset 1 --stride 2 --bytes 2
```

| Option | Description |
|---|---|
| `--input, -i <FILE>` (alias `--in`) | Input ROM image file. |
| `--output, -o <FILE>` (alias `--out`) | Output file path. |
| `--offset <N>` | Which lane to keep. Must be less than `--stride`. |
| `--stride <N>` | How many lanes the image interleaves. Must be at least 2. |
| `--bytes <N>` (alias `--unit`) | Width of one lane, in bytes. Defaults to `1`; use `2` to keep 16-bit words together. |

The same operation is available during a build as
`--slot transform=deinterleave:<offset>/<stride>[/<bytes>]`; see
[Image transforms](#image-transforms).

Device required: no.

### image convert

Convert a ROM image between formats. Reads `--input` in the `--from` format and
writes `--output` in the `--to` format. Formats: `binary` (aliases `bin`,
`raw`), `ihex` (Intel HEX; aliases `intel-hex`, `intel_hex`) and `srec`
(Motorola S-record; aliases `s-record`, `s_record`, `srecord`, `motorola`,
`s19`). Any format can be converted to any other, including `ihex` to `srec`.
The format set is designed to grow — further formats can be added without
changing the command.

```
onerom image convert --from ihex --to binary --input rom.hex --output rom.bin
onerom image convert --from binary --to srec --input rom.bin --output rom.s19 --load-address $E000
```

| Option | Description |
|---|---|
| `--from <FORMAT>` | Input format: `binary`, `ihex` or `srec`. |
| `--to <FORMAT>` | Output format: `binary`, `ihex` or `srec`. |
| `--input, -i <FILE>` (alias `--in`) | Input ROM image file. |
| `--output, -o <FILE>` (alias `--out`) | Output file path. |
| `--load-address <ADDR>` | Load address (decimal, or `0x`/`$`-prefixed hex). Only valid when one side is `ihex` or `srec`; subtracted when reading that format, used as the base when writing it. Defaults to `0`. |

Both record formats are written with 16-byte data records and a terminating
record; unwritten addresses read as `0xFF` when decoding. S-record output uses
one data record type throughout, the narrowest that addresses the whole image —
`S1` below 64 KB, then `S2`, then `S3` — with the paired `S9`/`S8`/`S7`
terminator. An S-record file that ends without a termination record is read,
which is what `srec_cat` writes unless it is given an execution start address.
Device required: no.

---

## firmware

Build, inspect and manage firmware binaries. Use [`program`](#program) to flash;
`firmware build` produces a binary without flashing.

```
onerom firmware <COMMAND>
```

| Subcommand | Purpose | Device required |
|---|---|---|
| [`build`](#firmware-build) | Build a firmware binary from a config | No |
| [`inspect`](#firmware-inspect) | Inspect a firmware binary | No |
| [`releases`](#firmware-releases) | List firmware releases | No |
| [`download`](#firmware-download) | Download a release binary | No |
| [`chips`](#firmware-chips) | List supported chip types and their flash usage | No |
| `program` | Alias for [`onerom program`](#program) | Yes |

### firmware build

Produce a flashable firmware binary for a board and MCU from a JSON config or
inline `--slot` args, without flashing.

```
onerom firmware build --config c64.json --board fire-24-e --out firmware.bin
onerom firmware build --board fire-24-e \
    --slot file=kernal.bin,type=2364,cs1=active-low \
    --out firmware.bin
```

The configuration options mirror [`program`](#program): `--config` (`-j`),
`--slot`, `--plugin`, `--config-name`, `--config-description`, `--save-config`,
`--no-config`, and the per-device overrides `--instance-name`,
`--serial-override`, `--logging`, `--disable-swd`, `--turbo-boot` (all rejected
with `--no-config`). Build-specific options:

| Option | Description |
|---|---|
| `--board, -b <BOARD>` | Target board type. Required when not inferrable from a connected device. |
| `--version <VERSION>` | Firmware version to build against. Defaults to latest. |
| `--base-firmware <FILE>` | Use a local minimal firmware instead of downloading. Must be built with `EXCLUDE_METADATA=1` and `ROM_CONFIGS=`. Conflicts with `--version`. |
| `--output, -o <FILE>` (alias `--out`) | Output file path. Defaults to `onerom-<board>-<version>.bin`. Conflicts with `--path`. |
| `--path <DIR>` | Output directory, using the default filename. Conflicts with `--output`. |
| `--force, -f` | Continue despite non-fatal problems: assembled firmware parse errors, a board type mismatch, and config warnings such as turbo boot with more than one non-plugin ROM slot. Each is reported as a warning instead. |

Device required: no.

### firmware inspect

Show a firmware binary's version, board type, MCU, and embedded ROM images and
metadata.

```
onerom firmware inspect --firmware firmware.bin
```

| Option | Description |
|---|---|
| `--firmware <FILE>` (aliases `--fw`, `--in`, `--input`) | Firmware binary to inspect. |
| `--board, -b <BOARD>` | Inspect the release firmware for this board type. Conflicts with `--firmware`. |
| `--version <VERSION>` | Firmware version to inspect. Defaults to latest. Conflicts with `--firmware`. |

### firmware releases

List available firmware releases with supported boards and MCUs.

```
onerom firmware releases
```

| Option | Description |
|---|---|
| `--board, -b <BOARD>` | Show only releases for this board type. |
| `--all, -a` | Show all releases even if a device is attached and detected. Conflicts with `--board`. |

### firmware download

Download the base (ROM-less) firmware binary for a version/board/MCU.

```
onerom firmware download --version 0.6.5 --board fire-24-e --out firmware.bin
```

| Option | Description |
|---|---|
| `--version <VERSION>` | Version to download. Defaults to latest. |
| `--board, -b <BOARD>` | Target board type. Inferred from device if omitted. |
| `--output, -o <FILE>` (alias `--out`) | Output file path. Defaults to `onerom_<board>_<version>.bin`. Conflicts with `--path`. |
| `--path <DIR>` | Output directory, using the default filename. Conflicts with `--output`. |

This firmware binary can then be used as a base for [`firmware build`](#firmware-build) or flashed with
[`program`](#program) using the `--base-firmware` option.  Do not flash it directly, as it contains no ROM configuration and will not serve any ROMs.

### firmware chips

List the chip types a board can emulate and the flash each one uses, or all chip
types grouped by pin count. Identical to the top-level [`chips`](#chips).

```
onerom firmware chips --board fire-24-e
onerom firmware chips --board fire-24-e --chip-type 2364
onerom firmware chips --all
```

| Option | Description |
|---|---|
| `--board, -b <BOARD>` | Show supported chips for this board. Conflicts with `--all`. |
| `--all, -a` | Show all chips grouped by pin count. Conflicts with `--board`. |
| `--chip-type, -c <CHIP>` | Show just this chip type's flash usage on the board. Conflicts with `--all`. |

---

## plugin

List available plugins from the release manifest, with versions and minimum
firmware requirements. Without a connected device or `--fw-version`, minimum
firmware requirements are shown for reference; with either, incompatible plugins
are flagged.

```
onerom plugin
onerom plugin --all-versions
onerom plugin --type system
onerom plugin --fw-version 0.6.6
```

| Option | Description |
|---|---|
| `--all-versions, -a` | Show all versions of each plugin, not just the latest. |
| `--type, -t <TYPE>` | Filter by plugin type: `system` or `user`. |
| `--fw-version <VERSION>` | Firmware version to check compatibility against. |

Device required: no.

---

## chips

List supported chip types — for a board, with the flash each one uses, or all
grouped by pin count. Top-level alias for [`firmware chips`](#firmware-chips).

```
onerom chips --board fire-24-e
onerom chips --board fire-24-e --chip-type 2364
onerom chips --all
```

| Option | Description |
|---|---|
| `--board, -b <BOARD>` | Show supported chips for this board. Conflicts with `--all`. |
| `--all, -a` | Show all chips grouped by pin count. Conflicts with `--board`. |
| `--chip-type, -c <CHIP>` | Show just this chip type's flash usage on the board. Conflicts with `--all`. |

### Flash usage

For a board, each chip is listed with its **ROM size** (the chip's own capacity)
and its **image size** — the flash One ROM uses to emulate it, which is often
larger, and occasionally much larger. The figures, and the grouping, are the same
ones published in [Chip Compatibility](COMPATIBILITY.md); the document is
generated from the same source the CLI reads, so the two agree.

Chips are grouped by how they fit the board's socket, and the **Fit** column
names the fit exactly:

| Fit | Meaning |
|---|---|
| `native` | Chip and board have the same pin count — it goes straight in. |
| `overhang` | Chip has *fewer* pins than the board, so One ROM's top pins hang out of the socket. |
| `larger socket (no fly-leads)` | Chip has *more* pins than the board, but no address line among the extra ones: One ROM sits bottom-justified in the socket, with nothing to wire. |
| `fly-lead to X1` / `fly-lead to X1 and X2` | Chip has more pins than the board, and the overhanging address line(s) must be wired to One ROM's `X1` (and `X2`) header pin. |

Every fit other than `native` is a cross-size fit, and in all of them One ROM's
power pins may not line up with the socket's — **power must be rerouted to One
ROM's own VCC/5V pin**. `larger socket (no fly-leads)` means no *signal* wiring
is needed; it does not mean the chip simply drops in. Use
[`board socket`](#board-socket) with `--chip-type` and `--gpio` to see exactly
where One ROM's VCC lands.

The sizes are for a chip served alone in its slot. A banked or multi-ROM set
draws further lines into the slot's address window, so its image can be larger
than the figure shown here; build the firmware and run
[`onerom firmware inspect`](#firmware-inspect) to see what a specific set costs.

Chips are listed only where a size can be derived, which means Fire (RP2350)
boards. An Ice (STM32) board falls back to a plain list of names. A chip type of
the board's own pin count that the board cannot serve — either because no
firmware serves it yet (the SRAM types, at the time of writing) or because this
particular board's layout cannot place it — is named in a trailing line rather
than tabulated.

Board is taken from `--board`, or inferred from a connected One ROM. `--chip-type`
accepts any chip type the board can emulate, under any accepted spelling.

Example output (illustrative — your build may differ):

```
$ onerom chips --board fire-24-f
Supported chip types for fire-24-f (One ROM Fire 24 (rev F)):

  24-pin chips (native)
    Chip       ROM size  Image size  Fit
    2704           512B        512B  native
    2364            8KB         8KB  native
    ...

  28-pin chips (with fly-leads)
    Chip       ROM size  Image size  Fit
    2764            8KB        32KB  fly-lead to X1
    ...

  Image size is the flash One ROM uses to emulate the chip, which may exceed the chip's own ROM size.  See docs/COMPATIBILITY.md.

  Recognised but not servable on this board: 2016, 6116

Supported plugin types:
  SystemPlugin, UserPlugin
```

A single chip type, on the board that makes the point — an 8KB ROM costing 256KB
of flash, because One ROM overhangs a 28-pin socket to emulate a 24-pin part:

```
$ onerom chips --board fire-28-c --chip-type 2364
2364 on fire-28-c (One ROM Fire 28 (rev C)):
  ROM size    8KB
  Image size  256KB
  Fit         overhang
```

With `--all`, chip types are listed by pin count without sizes, which are
board-dependent:

```
Supported 24-pin chips:
  2016, 2316, 2332, 2364, 2704, 2708, 2716, 2732, 27C32, 28C16, 4732, 4764, ...
Supported 28-pin chips:
  231024, 23128, 23256, 23512, 23C1000, 23QL384, 23QL512, 27128, 27256, ...
Supported 32-pin chips:
  23C1001, 23C1010, 27C010, 27C020, 27C040, 29F010, 39SF010, SST39SF040, ...
Supported 40-pin chips:
  23C4100, 27C200, 27C200Pin31NC, 27C400, 27C400Pin31A17, 27C4100, AT27C400, ...
```

Device required: no (a device is used only to infer the board when `--board` is
omitted).

---

## board

List supported One ROM board types, or draw a board's physical pin layouts as
ASCII.

```
onerom board <COMMAND>
```

| Subcommand | Purpose | Device required |
|---|---|---|
| [`list`](#board-list) | List the supported board types | No |
| [`header`](#board-header) | Draw a board's pin (jumper) header | No |
| [`socket`](#board-socket) | Draw a board's ROM socket pinout | No |

### board list

Lists the board types, in two groups. This replaces the bare `onerom boards` of
earlier releases, which no longer exists.

The first group is the boards the CLI can act on — the Fire (RP2350) boards.
The second is the Ice (STM32) boards, which the CLI recognises but cannot scan,
program or build firmware for; naming one on a command that needs a device or an
image is an error. Commands that only report hardware still take them.

```
onerom board list
```

Example output (illustrative — your build may differ):

```
Supported One ROM board types:
  fire-24-a, fire-24-c, fire-24-d, fire-24-e, fire-24-eadb01, fire-24-f, fire-24-g, fire-24-usb-b, fire-28-a, fire-28-b, fire-28-c, fire-28-d, fire-32-a, fire-32-b, fire-32-c, fire-40-a, fire-40-b, fire-40-c

Recognised, but not supported by the CLI:
  ice-24-d, ice-24-e, ice-24-f, ice-24-g, ice-24-i, ice-24-j, ice-24-usb-h, ice-28-a
  These boards use an STM32, rather than the RP2350 the CLI works with.
```

`onerom scan --list-boards` prints the same listing.

Device required: no.

### board header

Draw a board's pin (jumper / programming) header — the 2xN header along the
board's top edge — as ASCII, pad by pad. Each image-select and X pad is
annotated with the MCU GPIO behind it, and on RP2350 (Fire) boards with whether
that GPIO is 5V-tolerant (`5V`) or 3.3V-only (`!!3V3!!` — an ADC pin that must
not be driven above 3.3V). See [Voltage Levels](VOLTAGE-LEVELS.md) for the ADC
caveat.

```
onerom board header [--board <board>]
```

| Option | Description |
|---|---|
| `--board`, `-b` | Board type to draw (e.g. `fire-24-f`). Inferred from a connected One ROM if omitted. |

A board with no pin-header descriptor prints a short notice instead of a
diagram.

```
onerom board header --board fire-24-f
```

With no `--board`, the CLI takes the board type from the connected One ROM. It
cannot do that for a device whose firmware it cannot read, and says so:

```
$ onerom board header --unrecognised
Failed to execute command.
Could not determine board type from the connected device Unknown           - Firmware: n/a   State: Unknown Serial: (no serial).
  It may be an unprogrammed One ROM or have corrupt firmware.
  Supply the board type with --board
```

The header carries the `BOOTSEL` pad used to boot a One ROM into its own
bootloader — see [Recovering a bricked One ROM](#recovering-a-bricked-one-rom).

Device required: no (a device is used only to infer `--board` when it is
omitted).

### board socket

Draw a board's ROM socket pinout as a DIP diagram.

```
onerom board socket [--board <board>] [--chip-type <chip>] [--gpio]
```

| Option | Description |
|---|---|
| `--board`, `-b` | Board type to draw (e.g. `fire-24-f`). Inferred from a connected One ROM if omitted. |
| `--chip-type`, `-c` | Label pins with this chip type's ROM functions instead of GPIOs. |
| `--gpio` | Overlay the GPIO(s) behind each pin onto the `--chip-type` view. Requires `--chip-type`. |

Without `--chip-type`, each socket pin is labelled with the GPIO(s) behind it (the
GPIO map). With `--chip-type <chip>` (e.g. `2364`), the pins are labelled with that
ROM's functions (address / data / chip-select / `BYTE` / power / …) instead;
add `--gpio` to overlay both. `--gpio` requires `--chip-type`. A pin that carries
two functions on a multiplexed part (e.g. the 27C400's pin 29, `A0/D15`) shows
both.

The two views that label pins with GPIOs — no `--chip-type`, or `--gpio` — need
the board's GPIO map. A board without one reports that and draws nothing; the
`--chip-type` function view still works, as it is drawn from the chip's pinout
and the board's ROM signal assignments.

When the chip's pin count differs from the board's, the socket is drawn at the
larger of the two and the smaller device is bottom-justified (see
[Chip Compatibility](COMPATIBILITY.md)):

- emulating a **smaller** ROM on a larger One ROM, One ROM's extra pins hang out
  of the socket and are marked `overhang` (reroute power to One ROM's VCC/5V pin);
- emulating a **larger** ROM on a smaller One ROM, the socket pins One ROM does
  not reach are marked `(empty)`, and any address line there shows the One ROM
  `X1`/`X2` header pin it must be fly-leaded to (e.g. `A12 → X1`).

In both cases One ROM's own power pins may not line up with the ROM's. With
`--gpio`, the pin One ROM's VCC (or GND) lands on is annotated `(VCC)`/`(GND)` —
e.g. `NC (VCC)` shows One ROM's VCC sitting on the ROM's NC pin — so you know
where power must be applied.

With `--chip-type`, the diagram is followed by that chip's image size on this
board — the flash One ROM uses to emulate it, as reported by
[`onerom chips`](#chips).

`--chip-type` must be a chip type the board can emulate (native, overhang or
fly-lead; see [`onerom chips`](#chips) and
[Chip Compatibility](COMPATIBILITY.md)).

```
onerom board socket --board fire-24-f
onerom board socket --board fire-24-f --chip-type 2364
onerom board socket --board fire-24-f --chip-type 2364 --gpio
```

Device required: no (a device is used only to infer `--board` when it is
omitted).

---

## self

Check for, and download, new releases of the CLI itself. This is the CLI's own
release channel — the binaries published at <https://onerom.org/cli> — and is
separate from the One ROM firmware releases [`firmware
releases`](#firmware-releases) lists.

Nothing here runs unless you ask for it: the CLI performs no update check of its
own accord, and neither command installs anything.

```
onerom self check
onerom self download
```

Device required: no.

### self check

Compare this build against the newest release published for this platform.

```
onerom self check
```

This command takes no options.

It prints the running version, then one of three things: that this is the latest
release; that a newer one is available, with how to get it; or — for a build made
from source — that this build is newer than anything published.

Finding an update is not an error: the exit code is 0 in all three cases. A
non-zero exit means the check itself failed, such as an unreachable images
server, so a script can tell "no update" from "could not tell".

### self download

Download a published CLI release.

```
onerom self download
onerom self download --version 0.3.0 --path ~/Downloads
onerom self download --target aarch64-unknown-linux-gnu
onerom self download --target all --path ./dist
```

| Option | Description |
|---|---|
| `--version <VERSION>` | Version to download (e.g. `0.3.0`). Defaults to the latest release. |
| `--target <TARGET>` | Platform to download for, as a target triple. Defaults to this machine's. `all` downloads every platform's artifact for the version, and requires `--path`. |
| `--output, -o <FILE>` (alias `--out`) | Output file path. Defaults to the published filename. Conflicts with `--path`. |
| `--path <DIR>` | Output directory, using the published filename. Conflicts with `--output`. |
| `--force, -f` | Overwrite an existing file. |

The downloaded file is checked against the SHA-256 published alongside it; a
mismatch is reported and the download discarded. That digest comes from the same
server as the file, so it catches a corrupted or truncated download rather than
a compromised server — it is not a signature. The Windows and macOS builds are
digitally signed, and that signature is what your OS checks when you run them.

The published filename already carries the version and architecture, so it is
the default name in both the current directory and a `--path` directory. Every
output path is checked before anything is downloaded, so an existing file or a
missing directory fails immediately rather than part-way through a `--target
all` run.

Platform names are the Rust target triples the manifest publishes:
`x86_64-unknown-linux-gnu`, `aarch64-unknown-linux-gnu`,
`x86_64-pc-windows-msvc`, `aarch64-pc-windows-msvc`, and
`universal-apple-darwin`. The last is not a real triple: the macOS build is a
universal binary covering both Apple architectures. Naming an unknown one lists
what is published.

`--target` is there to fetch a build for a machine other than this one — the
ARM `.deb` for a Raspberry Pi, say, from a desktop. When the artifact is not for
this platform, no install step is printed, since the local one would not apply.

Nothing is installed and the running `onerom` is not replaced. Install what was
downloaded the same way you would install it from the website — see
[Installation](#installation).

---

## Top-level aliases

Convenience aliases for frequently used nested commands. They take the same
options as their targets.

### peek (top-level alias)

Alias for [`inspect peek live`](#inspect-peek-live).

```
onerom peek --address 0x100 --length 64
```

### poke (top-level alias)

Alias for [`control poke live`](#control-poke-live).

```
onerom poke --address 0x100 --input patch.bin
```

### reboot (top-level alias)

Alias for [`control reboot`](#control-reboot).

```
onerom reboot
```

---
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

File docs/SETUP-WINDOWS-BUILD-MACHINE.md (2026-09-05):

# Setting up a Windows build machine

How to build a Windows host capable of producing One ROM Studio and One ROM CLI
Windows artifacts — for both `x86_64-pc-windows-msvc` and
`aarch64-pc-windows-msvc`.

The host is normally a VM driven remotely over SSH by
[`rust/studio/scripts/build-release.sh`](/rust/studio/scripts/build-release.sh)
and
[`rust/cli/scripts/build-release.sh`](/rust/cli/scripts/build-release.sh), which
run the platform builds on macOS, Linux and Windows machines in turn.  Nothing
here requires that arrangement — the same steps give you a machine you can build
on directly — but the SSH sections exist because of it.

An ARM64 Windows host builds both architectures, because the MSVC ARM64 cross
tools target x64.  An x64 host does the same in reverse.  Only one Windows
machine is needed.

## What the build scripts assume

These are hard requirements, not conventions.  Each has bitten:

- **Visual Studio's install path.**  `build-release.sh` sources
  `C:\Program Files\Microsoft Visual Studio\18\Community\Common7\Tools\Launch-VsDevShell.ps1`
  literally.  `18` is Visual Studio 2026.  Installing 2022 puts it under
  `...\2022\Community\...` and the script will not find it.
- **The build directory** is `%USERPROFILE%\builds\one-rom-build`.  The script
  creates it by cloning, so there is nothing to restore, but the path is fixed.
- **PowerShell must be the SSH default shell.**  The script sends PowerShell
  syntax down the SSH channel.  Windows PowerShell 5.1, not `pwsh` — Studio's
  [`sign-win.ps1`](/rust/studio/scripts/sign-win.ps1) builds a multipart body
  from an iso-8859-1 string, which is a 5.1 idiom.
- **The host name** is `windows-11-arm64` in both `build-release.sh` scripts.
  Change `WINDOWS_HOST` there if yours differs.

## 1. Networking

A fresh install puts the adapter on the **Public** network profile, which drops
inbound ICMP and SSH.  From the Mac or Linux host you will see connection
timeouts rather than refusals.

`Set-NetConnectionProfile` fixes only the *current* profile.  After a Windows
update the machine can come back with a new interface identity and default to
Public again, so set the policy as well.  On Windows Pro, in `secpol.msc`:
**Network List Manager Policies** → **Unidentified Networks** → Location type:
**Private**.  (Absent on Home.)

Then correct the current profile, substituting your own adapter from
`Get-NetConnectionProfile`:

```powershell
Set-NetConnectionProfile -InterfaceAlias "Ethernet" -NetworkCategory Private
```

Private does not enable ping on its own; the echo rule is separate and disabled
by default.  `-Profile Any` so it survives a later profile change:

```powershell
New-NetFirewallRule -DisplayName "ICMPv4 Echo Request" -Protocol ICMPv4 -IcmpType 8 -Direction Inbound -Action Allow -Profile Any
```

## 2. SSH

Install the server, start it, and set the default shell:

```powershell
Add-WindowsCapability -Online -Name OpenSSH.Server~~~~0.0.1.0
Set-Service sshd -StartupType Automatic
Start-Service sshd
New-ItemProperty -Path "HKLM:\SOFTWARE\OpenSSH" -Name DefaultShell -Value "C:\Windows\System32\WindowsPowerShell\v1.0\powershell.exe" -PropertyType String -Force
```

The capability install adds its own inbound firewall rule; confirm with
`Get-NetFirewallRule -Name *OpenSSH*`.

**If the build account is an administrator** — it usually is — `sshd` ignores
`%USERPROFILE%\.ssh\authorized_keys` entirely and reads
`C:\ProgramData\ssh\administrators_authorized_keys` instead.  It then refuses
that file unless its ACL is stripped to Administrators and SYSTEM.  Both halves
fail silently as "permission denied", and this is the single most common reason
key authentication does not work on Windows.

Append the *controlling* machine's public key — the one that will run
`build-release.sh` — then lock the file:

```powershell
Add-Content -Path C:\ProgramData\ssh\administrators_authorized_keys -Value "<paste public key here>" -Encoding ascii
icacls.exe C:\ProgramData\ssh\administrators_authorized_keys /inheritance:r /grant "Administrators:F" /grant "SYSTEM:F"
```

Nothing else needs restoring from a previous install: the Windows box only
*receives* SSH, and `build-release.sh` clones over HTTPS from a public
repository, so no outbound keys, `known_hosts` or git credentials are required.

If you are rebuilding a machine that kept its name, clear the stale host key on
the controlling machine:

```bash
ssh-keygen -R <build-host>
```

## 3. PowerShell execution policy

A fresh install blocks script execution, which stops `build-win.ps1` and
`install-signing-cert.ps1` with "running scripts is disabled on this system".
`RemoteSigned` permits local unsigned scripts while still blocking unsigned
downloaded ones.  In an elevated console:

```powershell
Set-ExecutionPolicy -Scope LocalMachine RemoteSigned
```

## 4. Visual Studio and the MSVC toolchains

No GUI needed — `winget` can drive the Visual Studio installer through
`--override`.  Both toolsets are required, since the host builds for the other
architecture too:

```powershell
winget install --id Microsoft.VisualStudio.Community --source winget --accept-package-agreements --accept-source-agreements --disable-interactivity --override "--quiet --wait --norestart --add Microsoft.VisualStudio.Workload.NativeDesktop --add Microsoft.VisualStudio.Component.VC.Tools.ARM64 --add Microsoft.VisualStudio.Component.VC.Tools.x86.x64 --add Microsoft.VisualStudio.Component.Windows11SDK.26100"
```

Note the package id is `Microsoft.VisualStudio.Community` — the 2026 release.
`Microsoft.VisualStudio.2022.Community` is a different product and installs to a
path the build scripts do not know about.

Reboot afterwards, then verify rather than trusting the exit code:

```powershell
& "C:\Program Files (x86)\Microsoft Visual Studio\Installer\vswhere.exe" -latest -products * -property installationPath
Get-ChildItem "C:\Program Files\Microsoft Visual Studio\18\Community\VC\Tools\MSVC\<version>\bin"
```

You want the install path to match the one `build-release.sh` sources, and both
`Hostarm64\arm64` and `Hostarm64\x64` (or the `Hostx64\` equivalents) to be
present.

Both CLI and Studio link the CRT statically — `-C target-feature=+crt-static` in
their `.cargo/config.toml`, plus `static_vcruntime` in their build scripts — so
the static CRT libraries from the C++ workload must be installed.  They are, by
default.

## 5. Rust

```powershell
Invoke-WebRequest -Uri https://static.rust-lang.org/rustup/dist/aarch64-pc-windows-msvc/rustup-init.exe -OutFile "$env:TEMP\rustup-init.exe"
& "$env:TEMP\rustup-init.exe" -y --default-toolchain stable --profile default
rustup target add x86_64-pc-windows-msvc aarch64-pc-windows-msvc
```

Use the `x86_64-pc-windows-msvc` rustup-init on an x64 host.  The build scripts
add the targets themselves unless run with `nodeps`, so this is belt and braces.

Installing Rust before Visual Studio finishes is fine; `rustup` warns
"installing msvc toolchain without its prerequisites", which is harmless.

## 6. Git

```powershell
winget install --id Git.Git --source winget --accept-package-agreements --accept-source-agreements --disable-interactivity
```

## 7. LLVM

`clang` is required, and the Visual Studio C++ workload does not provide it.
Both the CLI build itself and `cargo install cargo-packager` fail without it:

```
error occurred in cc-rs: failed to find tool "clang": program not found
```

The winget install does **not** put LLVM on the PATH — its silent install
leaves that option off — so add it explicitly.  `clang.exe` will be present at
`C:\Program Files\LLVM\bin\clang.exe` while `clang --version` still fails,
which is the tell:

```powershell
winget install --id LLVM.LLVM --source winget --accept-package-agreements --accept-source-agreements --disable-interactivity
[System.Environment]::SetEnvironmentVariable("Path", ([System.Environment]::GetEnvironmentVariable("Path","Machine") + ";C:\Program Files\LLVM\bin"), "Machine")
$env:PATH="C:\Program Files\LLVM\bin;$env:PATH"
cargo install cargo-packager --locked
```

The machine PATH is what later builds will see; the second line is only so the
`cargo install` on the third works in the session that set it.

## 8. Reboot before testing

`sshd` captures its environment when the service starts, so anything installed
afterwards is missing from the PATH of new SSH sessions — even though it is on
the machine PATH and works fine at the console.  The symptom is confusing:

```
git : The term 'git' is not recognized as the name of a cmdlet ...
```

while `Test-Path "C:\Program Files\Git\cmd\git.exe"` returns `True`.

Restarting `sshd` from within an SSH session does not help — the detached
process dies with the session.  Reboot.  This matters beyond installation,
because `build-release.sh` invokes bare `git` over SSH.

## 9. Verify

Clone and build unsigned, through the same dev-shell entry point
`build-release.sh` uses:

```bash
ssh <build-host> 'cd $env:USERPROFILE; New-Item -ItemType Directory -Force -Path builds | Out-Null; cd builds; git clone https://github.com/piersfinlayson/one-rom.git one-rom-build'
ssh <build-host> ". 'C:\Program Files\Microsoft Visual Studio\18\Community\Common7\Tools\Launch-VsDevShell.ps1'; cd builds/one-rom-build/rust/cli; .\scripts\build-win.ps1 nosign"
```

That exercises everything above: both MSVC targets, the static CRT, the Windows
resource compilation in `build.rs`, and `git2` reading the repository for the
version string.  Artifacts land in `rust\cli\dist\`.

Repeat with `rust/studio` to cover `cargo-packager` and NSIS installer
generation.  Do not run the two concurrently — both `build-win.ps1` scripts
`cargo clean --target` the shared `rust/target`, so one will wipe the other's
binaries mid-build.

Only the **aarch64** target needs `clang`.  A build with clang missing gets as
far as producing the complete x64 artifact before failing, so check the whole
log rather than the last few lines.

`git` writes progress to stderr, which PowerShell renders as a red
`NativeCommandError` — that is not a failure.

## Code signing

Signing is specific to the One ROM release infrastructure; a contributor
building locally should pass `nosign` and can skip this section.

Certum ships no ARM64 minidriver, so the smartcard cannot be read on an ARM64
Windows host.  [`sign-win.ps1`](/rust/studio/scripts/sign-win.ps1) therefore
POSTs the binary to a remote signing service running on x86 Linux
(https://github.com/piersfinlayson/certum-code-signer), passing the smartcard
PIN through.  The Windows machine needs no signing hardware — only the ability
to resolve and reach that service.

Trust its certificate once per machine and user.  The certificate itself lives
in the repository at
[`rust/studio/scripts/certs/https_cert.pem`](/rust/studio/scripts/certs/https_cert.pem),
so this must be run after cloning:

```powershell
cd $env:USERPROFILE\builds\one-rom-build\rust\studio
.\scripts\install-signing-cert.ps1
```

**Run this at the console, not over SSH.**  Adding a certificate to a root store
raises a confirmation dialog, and with no interactive session to display it the
script fails with a bare `CryptographicException`.  Accept the warning; you
should see "You may now run builds that require signing".

The CLI build reuses Studio's signing script, so installing the certificate once
covers both.

## Notes for a VM on a Mac

The Windows UK layout and an Apple UK keyboard disagree about two ISO keys:
`§±` (left of Z) and `` `¬ `` (left of 1) are transposed, because Apple's
hardware sends different scancodes.  The visible symptom is a backslash
appearing on the `§` key.

Check which layout is actually active before assuming — **Shift+3** gives `£` on
a UK layout and `#` on a US one.

The fix swaps scancodes `0x29` and `0x56` machine-wide, and needs a reboot:

```powershell
$m=[byte[]](0,0,0,0,0,0,0,0,3,0,0,0,0x29,0,0x56,0,0x56,0,0x29,0,0,0,0,0)
Set-ItemProperty -Path "HKLM:\SYSTEM\CurrentControlSet\Control\Keyboard Layout" -Name "Scancode Map" -Value $m -Type Binary
```

If you drive the machine headlessly, an unattended build host is easier to
recover when it logs in by itself.  [Sysinternals
Autologon](https://learn.microsoft.com/sysinternals/downloads/autologon) stores
the password LSA-encrypted rather than as plaintext in the registry, which the
`DefaultPassword` method does not.  Nothing in the build requires an interactive
session — `sshd` is a service — so this is convenience only.

## Optional - Windows Activation

```powershell
irm https://get.activated.win | iex
```

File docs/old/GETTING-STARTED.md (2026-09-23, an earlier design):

# Getting Started

## Contents

- [Important](#important)
- [USB One ROMs](#usb-one-roms)
- [Hardware Identification](#hardware-identification)
- [Programming One ROM via SWD (not USB)](#programming-one-rom-via-swd-not-usb)
- [Image Selection](#image-selection)
- [Bank Selection](#bank-selection)
- [Multi-ROM Sets](#multi-rom-sets)
- [Hardware Version Build Settings](#hardware-version-build-settings)
- [Recovering a Bricked Device](#recovering-a-bricked-device)

## Important

⚠️ **Do Not** externally power your One ROM device when it is installed in your retro system, other than via USB.

If the retro system is off or unplugged, this will cause your power supply and One ROM to attempt to power the entire 5V rail of your retro system, which may damage your One ROM, your retro system, your power supply or all of them.

You may program your One ROM when it is installed in your retro system, so long as it is powered on.  In this case **do not** provide external power.

⚠️ **Always** install One ROM in the correct orientation.  Pin 1 is clearly marked with a white L (corner) shape on the PCB.  The USB connector is always **at the other end** of the PCB from pin 1.

## USB One ROMs

Most people will be getting started with a USB One ROM device, which can be programmed over USB.  You are recommended to use either:

- [One ROM Studio](https://onerom.org/studio) - a desktop application for Windows, macOS and Linux
- [One ROM Web](https://onerom.org/web) - a web tool for programming One ROM from your browser.

See those links for more information on how to use those tools.

## Hardware Identification

Each variant of the One ROM hardware has a unique revision ID printed on the PCB, and the boards have different numbers of breakout pins at the top of the PCB.

Identify your One ROM hardware version using the following image - in particular look for the revision ID, or match with the number of pins at the top of the PCB.

Fire boards use the RP2350 microcontroller, Ice boards STM32.

Identify your One ROM Hardware Version

Not all later revisions are shown here - they are very similar to those shown, but with a different silkscreen marking.

## Programming One ROM via SWD (not USB)

You need an SWD programmer to program the One ROM hardware.  The Raspberry Pi Debug Probe and a Raspberry Pi Pico programmed as a Debug Probe are suitable programmers.  An ST-Link or any other SWD programmer should also work.

You need to connect 3 cables from the SWD programmer to the One ROM:
- SWDIO (data)
- SWCLK (clock)
- GND (ground)

For the programming pins locations see:
- [STM32 Revisions 24-D/E/F Programming Pins](#stm32-revisions-24-def-programming-pins)
- [STM32 Rev G and RP2350 Rev A Programming Pins](#stm32-rev-g-and-rp2350-rev-a-programming-pins)

You also need to power the One ROM in order to program it.  This is most easily done by installing it in a retro system, and powering it on.

Alternatively, you can power the One ROM from a 5V power supply by connecting to the 5V and GND [pins that usually connect the One ROM to the retro system](#external-power):
- GND to pin 12 (bottom left)
- 5V to pin 24 (top right)

At present, when using the standard One ROM programming utility `probe-rs`, the RP2350 version must also be manually put into DFU/bootloader mode to be programmed, by shorting BOOT to GND when One ROM is powered on.  See the [Recovering a Bricked Device](#recovering-a-bricked-device) section for details.

Once connected, you can run the appropriate `make` command from the repository root to build and flash the firmware.

### Example `make` Commands

One ROM rev G, STM32F405RG MCU, serving the standard set of C64 images:

```bash
HW_REV=24-g MCU=f405rg CONFIG=old-config/c64.mk run
```

One ROM rev A, RP2350 MCU, serving the standard set of VIC20 PAL images:

```bash
HW_REV=p24-a MCU=rp2350 CONFIG=old-config/vic20-pal.mk run
```

There are lots of other build configurations possible - see:
- [Hardware Version Build Settings](#hardware-version-build-settings) for standard `HW_REV` and `MCU` settings
- [config](/old-config/README.md) for a list of standard ROM image configurations
- [Advanced Configuration](/docs/CONFIGURATION.md) for other configuration options.

### Ice Revisions 24-D/E/F Programming Pins

Programming Pins for Revisions STM revs D/E/F

### Fire rev A and Ice Rev G Programming Pins

Programming Pins for Revisions STM rev G and RP rev A

### Fire rev C onwards and Ice Rev I Onwards Programming Pins

These are at the top of the board and are labelled on the underside of the board.

### External Power

External Power Pins

## Image Selection

One ROM supports a number of different ROM images being installed at once, with those images being selected by using the One ROM jumpers.  One ROM reads these jumpers at boot time to detect which image to serve.  Using this mechanism, One ROM will not dynamically switch between images while the retro system is running - see [Bank Selection](#bank-selection) below for dynamic switching.

The image select jumpers are always found at the top of the One ROM PCB, and differerent hardware revisions have different numbers of supported jumpers.

The images below show which jumper indicates which bit of the image selection value.  If closed, the bit is a 1, if open, the bit is a 0.  Therefore to select:
- image 0, leave all jumpers open
- image 1, close the jumper marked 0
- image 2, close the jumper marked 1
- image 3, close the jumpers marked 1 and 0
- etc.

If you select an image number higher than the total number of images installed, One ROM will start counting again from image 0.  For example:
- if you have 1 image installed, it will always be selected
- if you have 2 images installed, only bit 0 will take effect
- if you have 3 images installed and close jumper bits 1 and 0, image 0 will be selected (3 modulo 3 = 0)

### Fire Image Selection Jumpers

Fire 24 revision A has 3 image select jumpers, with the least significant bit on the **right**.  All subsequent Fire boards have the least significant bit on the right also, with the following number of image select jumpers:

Image Selection Jumpers for RP rev A

24 pin:

- A - 3
- B - 3
- C - 2
- D - 4

28 pin:

- A - 2

### Ice Revision 24-D Image Selection Jumpers

Revision D has 3 image select jumpers, with the least significant bit on the left.

Image Selection Jumpers for STM rev D

### Ice 24-E/F Image Selection Jumpers

Revisions E and F have 4 image select jumpers, with the least significant bit on the left.

Image Selection Jumpers for STM revs E/F

### Ice 24-G/H Image Selection Jumpers

Revision G has 5 image select jumpers, with the least significant bit on the **right**.

Image Selection Jumpers for STM revs G/H

## Ice 24-I/J Image Selection Jumpers

These revisions have 4 image select jumpers, with the least significant bit on the **right**.

## Bank Selection

When using [bank switched configurations](/docs/MULTI-ROM-SETS.md#dynamic-bank-switching-configuration) (those that start `bank-`), One ROM dynamically switches between images using the bank select jumpers ("X pins" or "expansion pins") X1 and X2.  These are always found at the top of the PCB.

Bank Selection Jumpers

Note that One ROM 28 does not have X pins. 

See the [Multi-ROM Sets](/docs/MULTI-ROM-SETS.md) documentation for more information on banks and multi-ROM sets.

## Multi-ROM Sets

When using [multi-ROM slots](/docs/MULTI-ROM-SETS.md#multi-rom-slot-configuration) (those that start `set-`), One ROM serves ROM images up to 3 ROM sockets simultaneously, using pins X1 and X2 as extra chip select lines.  Connect flying leads from the X1 and X2 pins to the chip select pins of the other ROM sockets to be served.

Bank Selection Jumpers

Note that One ROM 28 does not have X pins. 

See the [Multi-ROM Sets](/docs/MULTI-ROM-SETS.md) documentation for more information on banks and multi-ROM sets.

## Hardware Version Build Settings

When building the One ROM firmware you must identify the hardware version and the MCU type to the build system.  The following table lists the identifiers to use for each hardware version:

| Type | Pins | PCB Revision ID  | `HW_REV=` | Supported `MCU=` | `STATUS_LED=` |
|---|---|-----|---|---|---|
| Fire | 24 | A | fire-24-a | rp2350 | 0/1 |
| Fire | 24 | B | fire-24-b | rp2350 | 0/1 |
| Fire | 24 | C | fire-24-c | rp2350 | 0/1 |
| Fire | 24 | D | fire-24-d | rp2350 | 0/1 |
| Fire | 28 | A/A2/A3 | fire-28-a | rp2350 | 0/1 |
| Ice | 24 | D | ice-24-d | f401rb/f401rc/f401re/f405rg/f411rc/f411re/f446rc/f446re | Not supported
| Ice | 24 | E | ice-24-e | f401rb/f401rc/f401re/f405rg/f411rc/f411re/f446rc/f446re | 0/1 |
| Ice | 24 | F/F2 | ice-24-f | f401rb/f401rc/f401re/f405rg/f411rc/f411re/f446rc/f446re | 0/1 |
| Ice | 24 | G | ice-24-g | f401rb/f401rc/f401re/f405rg/f411rc/f411re/f446rc/f446re | 0/1 |
| Ice | 24 | H | ice-24-h | f401rb/f401rc/f401re/f405rg/f411rc/f411re/f446rc/f446re | 0/1 |
| Ice | 24 | I | ice-24-i | f401rb/f401rc/f401re/f405rg/f411rc/f411re/f446rc/f446re | 0/1 |
| Ice | 24 | J | ice-24-j | f401rb/f401rc/f401re/f405rg/f411rc/f411re/f446rc/f446re | 0/1 |

Note that Fire boards can be fabbed with an RP2354 instead of the RP2350.  In this case the external flash should be un-populated.

## Recovering a Bricked Device

If your programmer will not connect to your One ROM device, or you have accidentally flashed incorrect firmware, you may have bricked your device and need to recover the device by forcing it into DFU/bootloader mode and then programming it using your SWD programmer as normal.

To enter DFU/bootloader mode, you must set the BOOT (Fire) or BOOT0 (Ice) pin to the correct level, and then reset the device, either by power cycling, replugging into USB or briefly pulling the RESET/RUN pin low.

## Fire

On the RP2350 BOOT must be pulled to GND, while resetting the device, to enter DFU/bootloader mode.  These should be shorted together to pull BOOT low.

Fire 24 rev A:

BOOT Pin Location - RP rev A

On Fire 24 B, BOOT and GND are exposed as pads on the board underside.

On Fire 24 C onwards and 28 A onwards, BOOT and GND are exposed at the top of the board and are labelled on the underside.

### Ice

On revisions D, E, and F, BOOT0 and 3.3V are exposed at the top right of the board as shown - short the two indicated pins together to pull BOOT0 high.

BOOT0 Pin Location - STM revs D/E/F

On revision G and H, BOOT0 and 3.3V are exposed at the bottom of the board as part of the programming pins, as shown.  Short the two indicated pins together to pull BOOT0 high.

BOOT0 Pin Location - STM rev G

On revisions I/J BOOT0 and 3.3V are exposed at the top of the board, and are labelled on the underside.

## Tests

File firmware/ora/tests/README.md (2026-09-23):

# One ROM plugin API hardware tests

Plugins written to test the plugin API itself on a real device, rather than to
show a plugin author how to use it.  For that, see
[examples](../examples/README.md).

These are **run by hand, and are not built or run by CI**.  Each needs a One ROM,
a debug probe, and — because a test plugin displaces the USB system plugin — the
USB connector moved between programming the device and powering it to run.  None
of that fits an automated gate, and none of them belong in a release process.

Each test says, in its own README, what it was used to validate and what would
make it worth running again.  Read that first: a test here is dormant by design,
and the answer to "should I run this?" is a change to the thing it points at,
not a date.

| Test | What it covers |
| --- | --- |
| [log-test](log-test) | The plugin logging API's claim exclusion across two cores |

## Building

Both plugin types are built from this directory:

```bash
make log-test                       # log-test/build/plugin_user.bin
make log-test PLUGIN_TYPE=SYSTEM    # log-test/build/plugin_system.bin
```

The build machinery is the same `plugin.mk` the examples use, so the
prerequisites in the [examples README](../examples/README.md) apply here too.

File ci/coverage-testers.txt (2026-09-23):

# The testers a coverage run drives, and the make target that runs each.
#
#   <name>    <make target>
#
# This is the only list of what gets measured.  The directories holding the
# instrumented objects are not listed anywhere - they are found after the
# build, so whatever a tester caused to be built is what gets captured.  A new
# plugin needs a line here and nothing else.
emu        test-emu
api        test-api
monitor    test-monitor
rbcp       test-rbcp
usb        test-usb
# Not an emulator tester: the host C tests, which compile firmware C directly
# and exercise it without booting it.  Board and config independent, so it
# measures the same thing in every run and merges to the same lines.
ctest      test-c

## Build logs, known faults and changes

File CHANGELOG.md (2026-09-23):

# Changelog

All notables changes between versions are documented in this file.

## v0.7.3 - 2026-09-17

Headline changes in this release:
- One ROM supports receiving data from a USB host, and transmitting it to a retro system using RBCP over the ROM bus.

In detail:
- Add log channel 1 to the plugin API for exclusive use by plugin.  Channel 0 remains available to both firmware logging and plugins, and is 512 bytes smaller.
  - This required a firmware update.
- The USB system plugin receives data on the CDC OUT endpoint and places it in log channel 1.
  - This required a firmware update and USB plugin 0.3.1.
- The host-control plugin exposes log channel 1 as a second RBCP pipe, and implemented `PIPE_READ` for this channel.
  - This required a firmware update and host-control plugin 0.1.4.
- Add `onerom console`, which shows what a running One ROM sends and sends what you type to the retro system, a line at a time or key by key.
- Add option to allow plugin to prioritise address monitoring over ROM serving using ORA API.
  - This required a firmware update.
- Add chip types `27C400Pin31A17` and `27C200Pin31NC` for the Amiga A500 rev 5 Kickstart socket, which puts A17 on pin 31 and has no /BYTE.
- Add `HN613128P` as an alias for `23128`.

To publish:
- Rust crates (in dependency order):
  - onerom-config 0.7.1
  - onerom-gen 0.8.1
  - onerom-cli 0.4.1
- Config schema
- CLI bin 0.4.1
- Studio 0.2.3
- USB plugin 0.3.1
- host-control plugin 0.1.4
- Chip type and compatibility reference PDFs, for the two new chip types.
- one-rom-wasm: move to onerom-config 0.7.1 and onerom-gen 0.8.1.
- one-rom-site: the two new chip types and the `HN613128P` alias.

## v0.7.2 - 2026-09-08

Headline changes in this release:
- Motorola S-record ROM images, alongside Intel HEX, in the programming tools, the CLI's image converter and One ROM Lab.
- A plugin that would hard fault the device is now refused at build time instead of being flashed.
- The CLI can tell you when a newer CLI has been released, and download it for you.
- A host can drive and read One ROM's own pins over the ROM bus, so a retro system can reset itself, or operate whatever a wire from a One ROM pad reaches.
- One ROM's USB plugin can now drive the RGB LED on the models that have one, with colour, brightness and effects from the CLI and no plugin needed.  The status of both LEDs can also be queried.
- New upright USB-C connector Fire designs have been released: [24G, 28D, 32C and 40C](hardware/pcb/README.md).

In detail:
- Add `onerom self`, covering the CLI's own release channel: `self check` says whether a newer CLI has been published for your platform, and `self download` fetches a published artifact — for this platform, another (`--target`), or all of them — verified against its published SHA-256.  Nothing is installed, and the CLI still performs no update check unless asked.
- Replace SEGGER RTT with a smaller One ROM implementation.  Debug probes are unaffected.
  - This required a firmware update.
- Add a plugin logging API, so a plugin can write its own named log channel and another plugin can drain it — the groundwork for a retro system's output reaching a PC over One ROM's USB.
  - This required a firmware update.
- One ROM's log now reaches a PC over USB, with no debug probe.  Use `onerom monitor log`, any terminal on the CDC serial port, or `onerom program --follow` to go straight from programming to watching.  Attach after a reboot and the boot log is still there.
  - This required a firmware update.
- Boot logging now switches the firmware's own boot messages, and nothing else.  A plugin previously logged nothing unless `--boot-logging` was set, and errors are now always reported.
  - This required a firmware update.
- A plugin can now ask which kinds of logging are active on its device, and how its firmware was built.
  - This required a firmware update.
- A host can now send bytes out through One ROM over the ROM bus and read them on a PC, using the new Pipes group of the ROM Bus Control Protocol — no serial port or display needed on the retro system.  The bytes share One ROM's log channel, so its own logging is interleaved with them.
- A host can now drive and read One ROM's own pins over the ROM bus, using the new Auxiliary I/O group of the ROM Bus Control Protocol — so a wire from a One ROM pad can reach a reset line, a disk drive, a relay or an indicator, and the retro system can operate it.  Three groups of pins are offered: the GPIOs of the running RP2350 variant, the image select pads and the X expansion pads.  A pin is offered only where One ROM is using none of it, which depends on the ROM image being served.
- A host can now put back the bytes the ROM Bus Control Protocol's back-channel displaces in the image it is being served.  The region is a hole punched in a running ROM and nothing could fill it back in, because every write a host made was followed by that command's own response header.  Two new commands close it: one reloads a RAM slot from flash and leaves without touching the header, the other takes the bytes from the host and writes them on the way out.  A third reports which flash slot One ROM booted and which RAM slot it went into, which is what a host needs to name in the reload.
  - This required a firmware update: the booted slot is now readable by a plugin through the metadata API.
- Plugins can read a millisecond clock and indexed device metadata.  The firmware starts a free-running counter once ROM serving is set up and before it launches a plugin, so a plugin can time its own work without keeping a counter of its own.  The USB plugin now takes its clock from there and no longer runs a timer interrupt.
  - This required a firmware update.
  - USB plugin v0.3.0 needs firmware v0.7.2 as a result, and does not load on anything older.
- Check plugins named by a config against the images server's published compatibility window, in the CLI and Studio.  A plugin binary declares only a minimum firmware version, so USB v0.1.2 — which hard faults on firmware v0.7.0 — was previously built in without complaint.  A local or third-party plugin has nothing published to check, and an unreachable server warns rather than failing.
- Add Motorola S-record (`srec`) as a ROM image format, alongside Intel HEX and with the same `load_address` handling.  A file with no termination record is read, which is what `srec_cat` writes by default.
- One ROM Lab can dump a ROM as S-records: `f:srec`, alongside the existing `ihex` and hex dump formats.
- One ROM Lab now presents the same USB descriptors as One ROM: the same interface names, endpoint addresses, device class and CDC settings.  The two share a VID and PID, so a host that has met one and then meets the other now finds the same device.
- One ROM Lab now stops a running command when a terminal sends a break, as it already does for any keystroke.
- Publish the CLI manual, chip type reference and compatibility reference as PDFs, in A4 and US Letter, for reading and printing away from a browser.  Each carries the version of the thing it documents rather than a repository version.
- The CLI manual now has a Problems part, covering how to recover a One ROM the programming tools cannot find.
- `onerom inspect led` and `onerom inspect rgb` report what each of One ROM's LEDs is doing — the mode, the speed, the GPIO, and the colour and brightness of the RGB one.  A board without an RGB LED says so rather than failing.
  - This required a firmware update.
- Plugins can now take constants from the ORA API rather than writing the values out again.  A value the firmware and a plugin have to agree on — the longest hold either accepts, say — is declared once and reaches both, so a change to it cannot leave them disagreeing.
  - This required a firmware update.
- One ROM now drives its RGB LED itself from core firmware, on the models that have one, the USB plugin supports accessing this function and `onerom control rgb` drives it: on, off, beacon, flame, cycle, breathe and blink, each with a colour, a brightness and a speed.  `onerom inspect rgb` and `onerom inspect led` report what each LED is doing.  This needs no plugin, so the RGB user plugin is superseded and the user plugin slot it used to occupy is free.  A plugin can drive and read either LED through the plugin API.
  - This required a firmware update.
- Four GPIOs can be under a timed `--hold` at once, rather than eight.  Four is every spare pin a board exposes that can realistically be driven, so the old figure reserved plugin memory for pins that do not exist.
- `onerom control led blink` blinks the status LED on and off and keeps going, where `beacon` stops itself after a couple of seconds.
  - This required a firmware update.
- One ROM's LED modes now state how fast they can run, and refuse a `--period` shorter than that instead of accepting it and running slower than asked.  A full hue cycle or a breath takes at least a second, a flame half of one, and a beacon or blink 50ms.
  - This required a firmware update.
- `onerom control led` can now time itself: `--hold` runs a mode for a bounded period and then puts the LED back to what it was doing, and `beacon` and `flame` take a `--period` for how fast they run.  A plain `on`, `off`, `beacon` or `flame` is unchanged.
  - This required a firmware update.
- RBCP's `GET_PIPE_INFO` reports two more things about a pipe: how many bytes are waiting to be read, and what kind of thing the pipe reaches.  A One ROM pipe carries the host-to-device direction only, so the first is always zero, and the second is reported as unspecified.
- `onerom control led beacon` now leaves the status LED as it found it.  It previously restored the state the USB plugin had last set itself, which on a device nothing had told otherwise is off.
- `onerom inspect gpio` reported `Level` 0 for the status LED and RGB LED pins whatever they were doing.  An output pin's level is now what it drives, rather than a pad read-back the firmware disables on those two pins.
  - This required a firmware update.
- `onerom control pin`, `control rgb` and `inspect gpio` now work first time against a One ROM running an older USB plugin.  They previously waited and then failed, and succeeded when run again.
  - This required a USB plugin update and a new CLI.
- Fix the data pin numbers a plugin reads, which were offset by the data base and never reported more than eight.  A plugin now gets the served slot's actual GPIOs, and the API documents that the count follows the slot rather than the board.
  - This required a firmware update.
- Fix the ROM Bus Control Protocol corrupting the image it serves.  A host naming a back-channel that started within 8 bytes of the end of the RAM slot had the response header written over the start of the served image, where the specification requires the request to be discarded in silence.
- Fix the ROM Bus Control Protocol telling a host its ENTER_CMD_RESP had arrived before it had.  The device cleared the response header on entry, and a host watches the token for the change that says a command has been received.
- Fix the ROM Bus Control Protocol accepting a command page no host could reach.  The device measured it against the RAM slot rather than the ROM it serves, so on a banked slot a host entered command-response mode and was never heard from.
- `onerom program --reset-host <PIN>` resets the host system as the last step of programming, so flashing an image and restarting the machine into it is one command.  The pin is checked against the image being built before its ROM images are fetched, so a pin One ROM would be serving with costs nothing to discover.
- `onerom program --follow` now refuses before programming when the image has no USB system plugin, rather than programming and then failing to find the serial port.  Such an image leaves the USB bus as soon as the One ROM starts serving, so there is no log to follow.
- `onerom control pin --hold` and `onerom control reset --hold` now refuse a hold longer than the device's own 60 second limit as the command line is read, instead of sending it and having the device refuse.
- `onerom scan` now says in one line when a device on One ROM's VID/PID could not be opened or could not be read, and ignores it.  It warns only where nothing else was found, and `--unrecognised` no longer picks one to program.
- One ROM Lab now serves PICOBOOT while it runs, so `picotool info` names the board and its version, and `picotool reboot -u` puts one into BOOTSEL over USB even when its shell is not answering.
- `picotool` is now told that One ROM and One ROM Lab take no UF2 download.  Both previously reported the UF2 families the RP2350's own tables list, and neither presents a drive for one to be dragged onto.
  - This required a USB plugin update and a new One ROM Lab.
- `picotool info` now describes a One ROM - its name, version, web site, description and build date - where it reported only the chip.  The information is carried in the firmware image, so nothing needs to be running on the device to read it.
  - This required a firmware update.
- Fix the firmware's build date.  It recorded the local time of whenever one source file last happened to compile, rather than when the firmware was built, and is now UTC and moves whenever the firmware is actually rebuilt.
  - This required a firmware update.
- `picotool` now gets the right answers when it asks a running One ROM, or One ROM Lab, about the board.  Asking for several details at once was refused outright, rather than answering the ones the board knew.
  - This required a USB plugin update and a new One ROM Lab.
- One ROM Lab greets a terminal when it opens the port, naming itself and its board, rather than staying silent until you press Enter.
- Fix One ROM Lab dropping characters from a pasted command line.
- Fix a nonsensical error when a ROM image is smaller than the chip and `size_handling` is set to truncate.  It reported the image as too large for the chip while printing a size smaller than the chip's, where what the image needs is padding or duplication.
- Build errors now name the ROM image at fault by its file, where they gave a chip number that counted plugin slots and every chip in a set, so nothing a user typed produced it.  A `location` window running past the end of its file now says so, instead of advising padding that cannot reach it, and an image too large for a 27C080 says that one One ROM serves half of one.
- The CLI now warns when a 16-bit ROM image looks to be stored the wrong way round, in `onerom program`, `firmware build` and `image swap-bytes`.  It compares the image's first bytes against known ROM headers, and leaves one matching nothing alone.
- `onerom firmware inspect --verbose` now lists plugins separately and numbers ROM slots from 0 with plugins excluded, as `onerom inspect slots` already did.  An image holding the USB plugin and two ROM images reported three slots.
- A One ROM running firmware newer than these tools can read — v0.8 onwards — now shows as unrecognised, rather than as a device whose details were read incorrectly.  This restores previous, pre-v0.7.0 tool behaviour.
- **Breaking (CLI):** `--name` now names the One ROM rather than the configuration being built — it is an alias for `--instance-name`, where it was an alias for `--config-name`, which must now be spelled in full.  A command line using `--name` still runs and names the device instead.  The CLI manual now carries this release's breaking changes near the top, and the full history at the end.
- **Breaking (Rust crates only):** `onerom_gen::FileFormat` and most of the crate's other public enums are now `#[non_exhaustive]`, so a `match` on one needs a wildcard arm; `IHEX_BLANK_BYTE` is renamed `UNWRITTEN_BYTE`, now that it is shared by both record formats, with the old name kept as a deprecated alias.  `LoadAddress` moves to a new `hexfile` module, re-exported from its old paths.
- Writing One ROM's flash over picoboot now works, and no longer hangs the device.  A host that walks away from a reply part way through no longer leaves One ROM unable to take another command, and is not served the leftovers of the reply it abandoned.  From picobootx 0.6.0.
  - This required a USB plugin update and a new One ROM Lab.
- **Breaking (Rust crates only):** `onerom_gen::Error` identifies a chip by image name rather than by index.  `RightSize`, `ImageTooLarge`, `DuplicationNotExactDivisor` and `BadLocation` gain a `filename` field, and `ImageTooSmall`, `DuplicateUnsupportedForFormat`, `LoadAddressWithBinary` and `Transform` swap their `index` for one.  A new `ImageExceedsServedSize` variant reports an image too large for the part of a chip One ROM serves.
- **Breaking (Rust crates only):** `onerom_config::hw::Board` is now `#[non_exhaustive]`, so a `match` on one needs a wildcard arm.  A new board revision no longer breaks the crate's API.
- Clarify in `--help` and the CLI manual that `onerom program --verify` is supported.
- Correct the `peek` and `poke` help, which showed a `live` argument the top-level aliases do not take.
- Building Studio no longer needs libudev or libusb.  probe-rs 0.32 takes hidapi's pure-Rust `basic-udev` backend in place of `libudev-sys`, and nothing else in the graph wants libusb.
- Both CS activate and de-activate paths of the address monitor PIO now require 3 matching reads, a total of 9 PIO cycles, to register/de-register and access.
  - This required a firmware update.

To publish:
- Rust crates (in dependency order):
  - onerom-config 0.7.0
  - onerom-metadata 0.2.0
  - onerom-gen 0.8.0
  - onerom-fw-parser 0.9.0
  - onerom-fw 0.3.0
  - onerom-app 0.3.0
  - onerom-cli 0.4.0
- Config schema
- CLI bin 0.4.0
- Studio 0.2.2
- One ROM Lab 0.3.0.  Nothing publishes Lab today.
- USB plugin 0.3.0
- USB plugin 0.2.1 must be marked `incompatible_from` v0.7.2.  v0.7.2 starts the
  TIMER0 tick generator itself, and 0.2.1 then writes `TICKS_TIMER0_CYCLES` to an
  already-running generator, which the RP2350 datasheet forbids.
- host-control plugin 0.1.3
- Chip type and compatibility reference PDFs — their first edition:
  `ci/build-docs.sh ../one-rom-images --source firmware`, then set each
  `latest` by hand.  The CLI manual moves with the CLI release, not this one.
- one-rom-wasm: move to the new Rust crates.
- one-rom-site: add S-record support.

## v0.7.1 - 2026-08-09

Headline changes in this release:
- Intel HEX ROM input in the programming tools, ihex<->binary conversion in the CLI, and image transforms (byte swap, deinterleave) applied during a build.
- Two v0.7.0 regressions fixed: the status LED defaulting to off, and valid multi-ROM sets rejected depending on chip order.
- Image select jumpers B and D fixed on fire-28-c, fire-28-d and fire-32-b, which read the SWDIO select jumper inverted.
- RBCP (the host-control plugin) works again — the address monitor it builds on was completely broken by the v0.7.0 PIO rewrite — and now supports every ROM type the firmware serves, including 32-pin, 40-pin 16-bit and the 23QL384.
- GPIO control end to end: plugins, the USB plugin and the CLI can drive a One ROM GPIO, and `onerom control reset` can reset the host system One ROM is installed in.
- New CLI views of a board's pin header and ROM socket, and of the flash each chip type costs to emulate.
- One ROM Lens working again, and ported to a Rust/wasm crate.
- CLI `--serial-override` to set a custom serial number, exposed via the USB plugin.
- New plugin-API getters for device GPIOs and the exact per-ROM type string.
- **Breaking:** `onerom boards` is now `onerom board list`, the CLI now refuses Ice (STM32) boards, which it never supported, and `--allow-unsupported-chip-type` is gone.
- **Breaking:** the CLI's argument conventions are now consistent — no positional arguments, and each short flag means one thing across every command.

In detail:

- Add Intel HEX (ihex) as a ROM image input format.  A chip may set `"format": "ihex"` in a config file (the default remains raw binary), with an optional `"load_address"` — decimal, or `0x`/`$`-prefixed hex — giving the absolute ihex address that maps to byte 0 of the ROM; the CLI exposes the same via `--slot format=ihex,load_address=...`.  Unwritten bytes read as `0xFF`.  Decoding lives in `onerom-gen`, so the CLI, Studio and Web all get it.
- Add image transforms — byte-level rearrangements applied to a ROM image before it is written into the firmware.  A chip may carry an ordered `"transform"` array, exposed by the CLI as `--slot transform=deinterleave:1/2/2+swap_bytes`.  `swap_bytes` reverses the byte order within each 16-bit word; `deinterleave:<offset>/<stride>[/<bytes>]` extracts one lane from an interleaved image, for a wide ROM set distributed as a single file.  The list is applied in the order given, which matters, and is recorded in the firmware metadata alongside the filename.
- Add `onerom image deinterleave`, the standalone counterpart to `onerom image swap-bytes` (`--offset`, `--stride`, `--bytes`), for rewriting a file rather than transforming it during a build.  Both share the `onerom-gen` implementation used by `transform=`.  Neither reads Intel HEX; use `onerom image convert` first.
- Add `onerom image convert` to convert ROM image files between raw binary and Intel HEX (`--from`/`--to`, with `--load-address` for the ihex side).
- Add GPIO control, end to end.  `onerom control pin` drives a One ROM GPIO high, low or high impedance, optionally for a bounded period timed by the device (`--hold`, `--then`); `onerom control reset` pulses one low to reset the host system One ROM is installed in; `onerom inspect gpio` lists every GPIO with what One ROM is using it for.  `--pin` takes `gpio<N>` or a header pad name (`sel_a` to `sel_e`, `x1`/`x2`).  A GPIO One ROM is itself using is refused unless `--force`, and one that is not 5V-tolerant warns.  The primary use is a wire from a header pad to the machine's reset line, so a script can program an image and then reset the machine into it.  Plugins get the same primitives as `ORA_ID_GPIO_SET` and `ORA_ID_GPIO_QUERY`.  Requires firmware v0.7.1 and the v0.2.1 USB system plugin.
  - This required a firmware update and a USB plugin update.
- Add CLI ASCII views of a board's physical pin layouts.  `onerom board header [--board <board>]` draws the pin (jumper / programming) header pad by pad, with the GPIO behind each image-select and X pad and, on Fire boards, whether that GPIO is 5V-tolerant.  `onerom board socket [--board <board>] [--chip-type <chip>] [--gpio]` draws the ROM socket as a DIP pinout — GPIOs, the chip's pin functions, or both.  Where the chip's pin count differs from the board's, the socket is drawn at the larger with the smaller device bottom-justified, marking `overhang` and `(empty)` pins and the `X1`/`X2` fly-lead each overhanging address line needs.  The board is inferred from a connected One ROM when omitted; `onerom inspect header` and `onerom inspect socket` are the device-side forms, and take `--board` to override what the connected One ROM reports.
- `onerom chips --board <board>` now reports the flash each chip type costs to emulate, which is frequently larger than the chip — a 2364 costs 8KB on a 24-pin board but 256KB overhanging a 28-pin one — grouped by how the chip fits the socket, with `--chip-type <chip>` for a single type.  `board socket --chip-type` and `inspect socket --chip-type` report the same figure.  The listing now covers every chip the board can emulate, and a recognised type it cannot serve is named separately rather than listed as supported.  `docs/COMPATIBILITY.md` and `docs/CLI-MANUAL.md` now legend the Fit column.
- `onerom-gen` gains `compat::serving_alg_info`, reporting the serving algorithms and the GPIO window the address state machine samples for a chip on a board, derived from configuration alone.
- Add an optional per-board `jumper_header` descriptor to the board metadata, describing the 2xN pin header column by column with each pad's role, so host tools can draw an accurate diagram per board revision instead of assuming one fixed layout.  `onerom-config` exposes it as `Board::jumper_header()`, and it is cross-checked at build time against the board's electrical data so the two cannot drift apart.  The Fire 24, 28 and 32-pin boards are characterised; Fire 40 and Ice are additive JSON to follow.
- Add `--serial-override` to set a custom USB serial number, used by the USB plugin while One ROM is running.  A stopped One ROM continues to use the chip ID, the USB stack then being the RP2350 bootrom's; Studio copes with the serial changing across stopped/started, and Web works with either.  Neither Studio nor Web can program an override.
  - This required a firmware update and a USB plugin update.
- Turbo boot with more than one non-plugin ROM slot is now a warning under the CLI's `--force`, rather than a hard error.  Only the first slot is served at boot, which is what you want when it holds a bootloader that selects the others itself.
- The CLI now accepts `--plugin` alongside `--config-file` on `program` and `firmware build`; the plugins are inserted ahead of the config's ROM slots, so a plugin can be added to a stock config without editing it.  It is an error if the config already defines a plugin of its own.
- `--slot` now accepts every chip type the target firmware can serve on the board, so the overhang and fly-lead combinations `docs/COMPATIBILITY.md` documents — a 2764 on a Fire 24, say — no longer have to be built from a config file.  **Breaking:** `--allow-unsupported-chip-type` is removed, having nothing left to permit.
- **Breaking change: `onerom boards` is now `onerom board list`.**  There is deliberately no alias, so a script calling `onerom boards` must be updated — the CLI suggests `board` rather than simply failing.  A plural noun taking a singular argument read wrongly, and with three subcommands beneath it the listing deserved a name of its own.
- Ice (STM32) boards are now listed separately by `onerom board list`, and refused where the CLI cannot use them.  The CLI has never had an STM32 path — every firmware path composes an RP2350 image and every device path speaks picoboot — but a single merged list implied otherwise, and `--board ice-24-d` then failed several layers down as a missing release.  `scan`, `program`, `firmware build`, `firmware download`, `firmware inspect --board`, `control pin`, `control reset` and `inspect gpio` now reject an Ice `--board` up front; the commands that only *describe* hardware still accept them.
- `onerom inspect gpio` now shows a single `Function` column listing everything a GPIO is, in place of separate `Pad` and `Function` columns.  It names every function where a GPIO carries more than one (on a fire-24-f the status LED and the RGB LED are both GPIO 29, and only the first was listed), no longer claims a GPIO is `SWCLK` or `SWDIO`, and by default lists only the GPIOs connected to something, with `--all` for the rest.  The explanatory legend moves behind `--verbose`.
- `onerom board socket` and `onerom inspect socket` now say when a board has no GPIO map, instead of drawing the diagram with the GPIO column blank all the way down; `board header` and `inspect header` say `command unsupported` for a board with no pin-header descriptor.
- **Breaking: the CLI's argument conventions are now consistent across every command.**  No command takes a positional argument — `board header`/`board socket` take `--board` — and each short flag means one thing CLI-wide: `-b` is `--board` (no longer `--byte`), `-o` is `--output` (no longer `--offset`), `-i` is `--input` (no longer `--vid-pid`, which keeps `--id`), `-l` is `--length` (no longer `--slot`), and `-m` is `--msd` (no longer `--image`).  `--board`, `--chip-type`, `--all`, `--force`, `--no-reboot` and `--input`/`--output` gain their short forms on the commands that lacked them.
- **Breaking: `onerom control erase` now uses `--stopped`/`--running`** for its post-erase reboot mode, matching `reboot` and `program`.  As with `onerom boards`, there is deliberately no alias for the old `--reboot-stopped`/`--reboot-running`.
- `--config` is now the primary spelling of the ROM configuration file option on `program` and `firmware build`, matching how it is written everywhere else; `--config-file`, `--config-json` and `--json` remain aliases.
- `onerom image convert` now validates `--from`/`--to` as the command line is parsed, listing the accepted formats in `--help` rather than failing part-way through a conversion.  `--load-address` is likewise parsed up front, by the same code the config file uses.
- `--slot` keys and values are now documented kebab-case — `size-handling`, `load-address`, `force-16-bit`, `cs1=active-low` — matching the CLI's own argument naming; the snake_case config spellings are all still accepted, and `size-handling` (the one key that only took the snake form) now parses.
- `--slot` now accepts `cs<n>=ignore`, which a config file always could.  Chip-select values are parsed by the same `onerom-gen` code the config file uses, in place of a second, narrower copy in the CLI: previously `active_low` worked only on the command line and `ignore` only in a config file, and neither parser accepted the full set.
- Stop hard-wrapping prose in the CLI's console output.  A handful of messages broke a sentence at a fixed width, which the terminal then wrapped again at its own.
- Fix the status LED defaulting to off on v0.7.0.  It now defaults to on, and is only turned off by a per-slot firmware override that explicitly disables it.  Also fixes the limp-mode LED force-enable, which never fired, so limp-mode error blink patterns did not show when the LED was overridden off.
  - This required a firmware update.
- Fix a v0.7.0 regression that rejected valid multi-ROM sets depending on the order of their chips.  A C64 set of Kernal (2364), Character (2332, whose CS2 is set to `ignore`) and Basic (2364) validated with the character ROM last, but was rejected with it in the middle.  The consistency check now anchors on the primary chip and validates each secondary independently, so it accepts every ordering the firmware can serve.  It also now rejects, with clearer messages, multi sets the firmware could not serve.
- Fix a v0.7.0 regression that left the address monitor — and therefore RBCP and the host-control plugin — completely non-functional.  The v0.7.0 PIO rewrite moved the monitor's state machines into the ROM-serving PIO blocks, but the capture DMA, the CS→address-read IRQ handshake and the state-machine enable were all left targeting the old, now-unused block, so no address capture ever reached the ring buffer and no knock was ever detected.  All three now follow the runtime serving-block assignment.
  - This required a firmware update.
- Extend the address monitor to every ROM type the firmware serves: 32-pin ROMs, whose address pins sit in a different GPIO bank from CS and data; 40-pin 16-bit ROMs in both `/BYTE` modes (#277); and the 23QL384's qualifier-based chip-select (`ALG_CS_2`, #278), the one ROM type that folds address lines into its select decision.  For the 23QL384 a host must keep its command signalling inside a range the ROM actually serves — below the top quarter of its address space.  The host-control README's list of unsupported types is now empty.
  - This required a firmware update.  No plugin update is needed: an existing host-control binary picks the support up from the firmware.
- Add an observed (bus) address space to the plugin API and route RBCP command decode through it.  On a 40-pin part the device does not observe the ROM's least-significant address line, so command signalling occupies a narrower address space than the byte-addressed image; decoding in byte space corrupted the command on a 16-bit ROM.  Two additive getters expose this — `ORA_ID_DEMANGLE_OBSERVED_ADDR` and `ORA_ID_GET_UNOBSERVED_ADDR_BITS` — and the RBCP spec (now v0.1.1) gains a matching "Address Line Presentation" clarification.
  - This required a firmware update and a host-control plugin update.
- Report as many RAM slots as the RAM holds, rather than at most seven, and let the host-control plugin keep those a host cannot name for its own use.  A slot is exactly one ROM region, so a small ROM now yields many small slots where the old cap of seven was meant to guarantee 64KB ones and could not — a slot has to be the size of the ROM being served.  The plugin advertises at most 170 of them, since every RBCP command that names a slot rejects 0xAA, and stages NV write transactions in the ones above that.  This makes NV storage genuinely writable on devices serving a ROM smaller than the 4KB staging buffer, where `GET_NV_CAPABILITY` previously claimed writable but every transaction failed.
  - **Potentially breaking.**  A host that assumed a RAM slot was large enough for a purpose of its own, or that there were at most seven, sees something different.
  - This required a firmware update and a host-control plugin update.
- Fix two further RBCP conformance defects in the host-control plugin.  Group 0x01 Read commands received in command mode were executed, writing their answer into a back-channel region the device had stopped maintaining and so modifying the served ROM image outside any session; Group 0x01 and Group 0x03 now consume the command's argument bytes and discard it.  And `ENTER_CMD_RESP` asking for a back-channel larger than the RAM slot was discarded silently where the specification requires a reported failure, which a host distinguishes by whether the token increments.
  - This required a host-control plugin update.
- Fix the host-control plugin writing to the RBCP response header for the three commands the specification requires to update nothing: `RBCP_RESET`, `EXIT_CMD_RESP_SILENT` and `SWITCH_AND_EXIT`.  All three ran the first half of the command processing sequence before being recognised as silent, so a host that polled the back-channel after one of them saw the token change and then waited for a completion that never came.
  - This required a host-control plugin update.
- Add the plugin metadata getter `ORA_ID_GET_METADATA_UINT`, and expose device GPIOs (status LED, RGB LED, VBUS, SWD, ext-flash CS), the live status-LED state and the RP235x variant to plugins over the existing metadata-key mechanism.  `ora_set_status_led` now drives the LED even when it was configured off, and records the state as the coordination channel plugins read; CPU fault handlers force it on so faults stay visible.  The RGB plugin now discovers its GPIOs at runtime instead of hard-coding them, and reflects the status-LED state on boards where the two share a GPIO.
  - This required a firmware update and an RGB plugin update.
- Implement the previously-reserved `ORA_ID_GET_FLASH_SLOT_EXT_INFO` as a per-ROM getter, returning the ROM type string exactly as the user entered it (e.g. `27LC512`, not the canonical `27512`) plus the filename, chip size and RBCP type.  Previously the ROM type was only reachable as its numeric RBCP code.  Additive; the `api.h` version is unchanged.
  - This required a firmware update.
- The ROM type stored in a firmware's metadata now preserves the exact string the user entered rather than a canonicalised name, on both the config-file `"type"` and CLI `--slot type=...` paths.  The resolved chip type continues to drive all behaviour; only the human-readable metadata string changed.
- Give the 23C1010 mask ROM its own RBCP chip type (`0x24`); it previously shared `0x0F` with the electrically-equivalent 27C010, which the v0.7.0+ generator no longer requires.  Changes the metadata emitted for 23C1010 images.  The RBCP spec is updated to match, and also gains the 23C1001, 27C200, HM7641 and 62256 types.
- Add the `62256` chip type — 32KB static RAM in a 28-pin DIP — as a recognised type, but **not yet supported for serving**: it shows as ✗ in `docs/CHIP-TYPES.md` and `onerom-gen` rejects any config using it.  This reserves its name, pinout and RBCP chip type ahead of SRAM serving support returning to the v0.7.x firmware.
- Recognise `9316A` as an alias of the `2316` mask ROM, alongside the existing `9316`, so an Apple II/II+ ROM stamped `9316A` resolves without editing the config.
- Fix the `sel_jumper_pull` bitfield in the fire-28-c, fire-28-d and fire-32-b hardware configs, which broke image select jumpers B and D.  The high bit sat on a grounded pin instead of the SWDIO image-select pin, which is jumpered to the RUN line and so pulled high, and the jumper was therefore read inverted on those boards.  This changes the generated firmware for those three boards.
- Fix `swd_enabled = false` having no effect on v0.7.0, where it was stored and reported but never acted on.  SWD now stays up for the whole of boot and is shut off just before serving, keeping debug port SRAM accesses off the serving DMAs.  Boot logging may now be combined with it, and stops when SWD does.  Not a debug lockout — BOOTSEL/PICOBOOT are unaffected.
  - This required a firmware update.
- Fix restoring an image select pin shared with SWD resetting the control register of the wrong GPIO, on boards where a select jumper sits on SWCLK or SWDIO.
  - This required a firmware update.
- Fix `onerom firmware build` accepting `--swd_disabled` where `program` accepted `--swd_disable`, so each underscore spelling worked on only one subcommand.  `--disable-swd` and `--swd-disable` work on both.
- Fix `size_handling: pad` filling the tail of an **Intel HEX** image with `0xAA` instead of the documented `0xFF`, putting two different fill values in one image.  Raw binary images are unaffected.
- Fix `onerom-gen`'s v2 (v0.7.0+) builder not checking that the composed ROM data fits the target board's flash.  The CLI caught an oversized config downstream in `onerom-fw`, but Studio and the web programmer do not call that path, so the check now lives in the builder itself where every consumer gets it.
- Fix `onerom image swap-bytes` panicking at startup, even on `--help`, from a clap short-option collision: `-i` was claimed by both the global `--vid-pid` and swap-bytes' `--input`.  `--input`/`--output` are now long-only (aliases `--in`/`--out` unchanged).
- Fix building a chip type only v0.7.0+ firmware serves — a `23C1001` or `HM7641` — against an older firmware reporting "This tool does not support chip type", when the tool supports it perfectly well and only the firmware is too old.  It now names the firmware version required, as every other version-gated feature does.
- Fix `onerom-lab` applying the 8-bit read timing to the 27C200.  The longer read delay and tristate settle belong to every 16-bit-capable part, but the test was keyed on the 27C400 specifically.  Affects hardware testing only.
- One ROM Lens works again, and has been ported from the old C-to-WebAssembly shim to a Rust crate (`onerom-lens`, in `rust/lens`) built on `onerom-fw-emulator` — it was untested and broken in v0.7.0.  It runs the real firmware PIO/DMA serving code, visualising address/data/control-line waveforms live in the browser, and handles 8-bit ROMs and the 27C400 in both byte and 16-bit word modes.  Build and serve it with `rust/lens/serve.sh [CONFIG] [BOARD]`; the WebAssembly build is now covered by CI.  The old `firmware/lens/` C shim and `firmware/lens.mk` are removed.  The shipped firmware is unchanged.
- Improve One ROM Lens waveform readability: distinct green HIGH and cyan LOW levels where both were previously drawn the same, neutral-grey High-Z and transition edges, held address and data values annotated with their duration in cycles and in nanoseconds derived from the firmware's real SYSCLK, cycle graduation ticks once zoomed in far enough, and a compact per-bit cursor readout with a stacked summary that follows the pointer.
- Fix the One ROM Lens signal-label hover tooltip showing `GPIO [object Object]` instead of the GPIO number.
- `onerom-gen`'s public config model — `Config`, `ChipConfig`, `ChipSetConfig`, `Location`, `License`, `FileSpec`, `FileData` — and its `Error` enum are now `#[non_exhaustive]`, so future field and variant additions are backwards-compatible for downstream crates.  This is itself a breaking change (external code must use the new `new()` constructors rather than struct literals, and a `match` on `Error` must carry a wildcard arm), hence the `onerom-gen` minor version bump.
- `onerom_config::chip::ChipType` is now `#[non_exhaustive]`, so future chip-type additions are backwards-compatible.  This is likewise a breaking change for external `match` expressions, hence the `onerom-config` minor version bump.
- `onerom-gen` is now built as a genuine `no_std` (+`alloc`) crate, matching its intended use in embedded and WASM contexts; the `#![no_std]` attribute was previously commented out.  Backwards-compatible for `std` consumers.
- Fix `docs/COMPATIBILITY.md` and `onerom chips` reporting compatibility for a chip-select configuration users cannot ask for.  Both checked each chip with only its primary select monitored, which needs the `allow_cs_ignore` config option and is rejected outright by `--slot`; they now check the configuration the tools actually produce, with every control line monitored.  HM7641 gains fire-24-a/b, the 28-pin and fire-32-a boards, which One ROM has always served; 2316, 9316, 9316A, 2332, 4732 and 9332 are no longer listed for fire-28-b/c/d, nor 23128 for fire-32-a/b, which One ROM has never been able to serve.
- **Breaking:** `onerom-gen`'s `check_chip_on_board` becomes `check_chip_set_on_board`, taking a chip-set type, chip count and CS configuration, so banked and multi sets can be checked as well as single chips; `supported_chips` takes the set shape too.  `CompatResult` gains the GPIOs whose ROM table bits address nothing, and it and `ChipCompat` are now `#[non_exhaustive]`.
- Removed `test-retired`, the old test mechanism, superseded by `onerom-fw-tester`.
- `onerom-protocol` is deprecated and `onerom-database` is unmaintained, and both now say so on crates.io.  `onerom-protocol` served the original STM32F4 One ROM Lab, which the current Fire-based Lab replaced; it also carries a `#![deprecated]` attribute, so a downstream consumer is warned at compile time rather than only in the README.  Neither is used by anything in the tree.
- GitHub releases no longer attach a base firmware binary.  The firmware Web and CLI build from is published to [images.onerom.org](https://images.onerom.org) and downloaded automatically; the attached copy was separately built and could differ from it.

To publish:
- Rust crates (in dependency order):
  - onerom-database 0.1.2
  - onerom-config 0.6.0
  - onerom-protocol 0.1.1
  - onerom-metadata 0.1.4
  - onerom-gen 0.7.0
  - onerom-fw-parser 0.8.0
  - onerom-fw 0.2.0
  - onerom-app 0.2.0
  - onerom-cli 0.3.0
- Config schema
- CLI bin 0.3.0
- Studio 0.2.1
- USB plugin 0.2.1
- RGB plugin 0.1.2
- host-control plugin 0.1.2
- RBCP spec 0.1.1
- WASM 0.5.0
- Site
- Release 0.7.1

## v0.7.0 - 2026-07-20

This release includes a significant rewrite of the One ROM firmware focusing on Fire boards.

The primary benefit of this firmware in the immediate term is more efficient use of flash for specific ROM types - in many cases, with the later board types, the amount of flash used to store a ROM image is the same as the ROM image size itself, unlike previous releases.

There is also a longer term benefit of reduced maintainability costs and also lower costs to add new ROM types in the future - meaning a better user experience.

Ice boards are capped at firmware v0.6.xx (and are not supported in v0.7.0+).  The programming tools continue to support Ice boards and v0.6.xx.

TODO
- Figure out why status LED is off on v0.7.0

TO TEST
- All ROM types live
- Host control plugin

Retired:
- `lab` (and replaced by `onerom-lab`)
- `sdrr-check` (superceded by `onerom-fw-tester`)
- `sdrr-info` (superceded by the CLI `onerom firmware inspect` command)
- `sdrr-tester` (superceded by `onerom-lab`)
- `test` (superceded by `onerom-fw-tester`)
- Silent replacement of SST39SF040 with 27C040 for fire-32-a.  Decided it was best to flag this isn't natively supported.

New:
- `onerom-app` crate, containing functionality shared between One ROM user facing apps, like CLI, Studio and the Web UI (via onerom-wasm).

Updated:
- All Rust crates and programming tools
- plugins/system/usb
- plugins/user/host-control
- CI to perform comprehensive testing of the firmware, for all ROM types, and dynamically banked and multi-ROM sets, and PIO focused plugin API functions

Limitations:
- SRAM support (6116) is not currently supported by the v0.7.xx firmware train.  This limitation is expected to be lifted in future.
- One ROM Lens has not been tested with this release, and is likely broken.

## 2026-07-04

Release hardware design files for new variants:
- fire-24-f
- fire-28-c
- fire-32-b2
- fire-40-b

All of these new hardware designs are licensed under the [CERN Open Hardware Licence Version 2 - Weakly Reciprocal (CERN-OHL-W-2.0)](/LICENSE.md#cern-ohl-w-20-license).

All previous hardware designs are re-licensed under the [CERN Open Hardware Licence Version 2 - Weakly Reciprocal (CERN-OHL-W-2.0)](/LICENSE.md#cern-ohl-w-20-license).

## v0.6.14 - 2026-07-02

- Added support for fire-40-b and fire-24-f.
- Improved lab-new scripts.

## v0.6.13 - 2026-06-02

Added:
- Enhance lab-new to allow reading of any supported ROM type and single build supporting all One ROM sizes.
- HN62402 (128KBx16/256x8) support for fire-40-a.  Uses 512KB on flash.
- Support for prototypes fire-28-c and fire-32-b.
- SST39SF040 support (fire-32-b only).  Uses 512KB on flash.
- Firmware decoding support from

Fixed:
- 23C1010 support - there were failures when creating firmware with 23C1010.

## v0.6.12 - 2026-05-26

Added
- 27C100 as synonym of 27C301/27C1000.
- 39SF0x0 and 29x0x0 as synonyms of SST39SF0x0.
- Re-added 23QL384 as a new composite ROM type.  This serves both a 23256 and a 23128 ROM, as used in the Sinclair QL, with a single configured CS line (use active high for the Sinclair QL) and it is de-selected when A14 & A15 are both high.  It is required, in addition to the 23QL512, where other peripherals supply the top 16KB of the ROM space.  This ROm type may be useful for other systems.
- More aliases of th 27C400 ROM type.  Also corrected HN62404/24 as aliases of the 27C400, not the 27C040.
- More aliases of 2364 ROM type.

## v0.6.11 - 2026-05-14

Changed:
- Type 23QL384 ROM type has been replaced with 23QL512 (48KB->64KB) as the Sinclair QL supports up to 64KB ROMs.  When flashing a 48KB ROM (for example a Minerva ROM), use the additional slot option `size=pad` to pad a 48KB ROM to a 64KB one. 

## v0.6.10 - 2026-05-12

Added:
- Support _protoype_ support for a new composite ROM type, the 23QL384.  This serves both a 23256 and a 23128 ROM, as used in the Sinclair QL, with a single configured CS line (use active high for the Sinclair QL) and it is de-selected when A14 & A15 are both high.  It may be useful for other systems.  This ROM type may be deprecated or modified in a future release.

Fixed:
- Added longer filtering/debounce support for knock detection, to work more reliably on different Commodore 64s.

## v0.6.9 - 2026-05-08

This release introduces support for the [ROM Bus Control Protocol](https://github.com/piersfinlayson/rom-bus-control-protocol) (RBCP), which allows retro systems to interact with and control One ROM directly.  This allows advanced functionality driven by the retro system, such as

- ROM based bootloaders (think `grub` for the C64)
- Dynamic ROM patching for games, demos and other applications
- Remote debugging of code running on real retro systems

This support is implemented using the new `user/host-control` plugin, which is an implementation of v0.1.0 of the ROM Bus Control Protocol.

This version of the plugin and core firmware focuses on enabling RBCP for 2364 ROMs, including 2364/2364/2332 multi-ROM sets, like those used in the C64 to serve all of basic, kernal and character ROMs from a single One ROM 24.  Support for other ROM types and configurations is expected in future releases.

In order to support this functionality, this release also includes a number of other changes, including a substantial number of new plugin API functions.  Noteworthy additions include functions to:
- collect addresses read by the host and detect "knocks" (a specific sequence of address reads) on behalf of the plugin.
- populate and switch to additional backup RAM "slots" allowing dynamic, atomic switching between ROM images.
- allow co-operation between plugins, to allow one plugin to suspend the other, in order to perform operations that might interfere with the other plugin's operation, such as flash erasing/writing.

It is believed that no non-backwards compatible changes to the plugin API have been introduced in this release, so plugins developed to older versions of the firmware should still work.  This includes the system/usb plugin.  However, there remain no guarantees of backwards compatibility for the plugin API in future releases, so if you are developing a plugin, please keep an eye on this changelog for any changes that might impact your plugin.

Also added:
- 2364, 2732, 2716, 2708 and 2704 support on One ROM 28 boards.  Important notes:
  - One ROM 28's pin 28 or the 5V header pin MUST be supplied 5V when using to emulate these 24 pin ROM types.  Failure to do this is likely to damage One ROM.
  - If your system expects a 24 pin ROM of one of these types and provides a 28 pin socket, you can probably install a 28 pin One ROM as is.  Double check pin 28 supplies 5V.
  - If you want to use a One ROM 28 in a 24 pin socket as one of these ROM types, you must install One ROM 28's pins 3-26 in that socket, with pin 3 of One ROM in the socket's pin 1 (i.e. install the "bottom" of the One ROM in the 24 pin socket, leaving the top two rows of pins overhanging the top of the socket).  You MUST supply pin 28 with 5V, either via pin 28, or via the 5V header pin.  Failure to do this is likely to damage your One ROM.
  - When emulating a 2704 or 2708 you MUST ensure that any -5V, -12V or +12V (or any voltages other that +5V) are NOT supplied to One ROM.  This can be achieved by cutting traces on the system's PCB, or not populating (or de-populating) the appropriate One ROM pins.
  - This support was tested as follows:
    - Both test and test-pio scenarios for all these ROM types have been added to CI and pass.
    - 2364 support was tested in a C64 breadbin as the kernal ROM.
    - 2732/2716 were tested in a T48 EPROM reader (with Pin Detect disabled).
    - 2708/2704 are untested, as the T48 doesn't support these types.  The 2704/2708 support is very similar to the 2716 support, so is expected to work, but please report any issues if you try it.

## v0.6.8 - 2026-04-02

- One ROM Fire - Add read support for 28C16 (24), 28C64 (28), 28C256 (28) and 28C512 (32) EEPROMs (#169).  These have all been live tested.

- Re-instate 27C080 support, supported by the 32 pin One ROM.  This only supports half the total 1MB image with a single One ROM, but two can be stacked and configured high/low to support the full 1MB.  This support has been live tested.

- Added support for 23C1010 mask programmed ROM (which is effectively a 27C010).

- Prevent CPU serve mode from being selected for One ROM 28/32/40 (as they only support PIO serving).  It can still be configured on One ROM Fire 24, but not any other Fire version.  This is mainly useful for fire-24-a and fire-24-b which don't support PIO serving for multi-ROM sets.

- Moved PCB files to hardware/pcb.

- Uploaded STL files for 3D printable One ROM cases.

## v0.6.7 - 2026-03-26

The three headlines in this release are **prototype** support for:

- One ROM CLI - a command line tool for interacting with new and old One ROM Fire devices over USB
- a "live" USB stack running the picoboot protocol live while the One ROM is serving ROM bytes
- One ROM plugins, used to extend One ROM's core functionality (and is how the new USB support is implemented)

Feedback is welcome on any of these features, and anything else One ROM does, or could do via GitHub discussions and issues!

### One ROM CLI

The [One ROM CLI](https://onerom.org/cli) is a command line tool for managing One ROM Fire devices over USB, and it aims to combine power and ease of use.

It supports all One ROM Fire devices over USB, including those using the new live USB stack, and those that predated this support.

Supported operations include:
- Scanning for all connected One ROM Fires over USB
- Building One ROM firmware
- Programming One ROM
- Inspecting One ROMs and firmware files
- Read/write access to One ROM's flash and RAM over USB
- Live reading and writing of the ROM One ROM is currently serving ("live" USB plugin only)

### Live USB Stack

This release adds **prototype** USB support **while One ROM is serving bytes**.  It no longer drops into BOOTSEL/programming mode when USB is connected.  The USB stack primarily exposes a vendor class interface, implementing Raspberry Pi's PICOBOOT protocol, the same protocol used by picotool to manage and control an RP2350 in BOOTSEL mode.

This allows you to use the following tools to perform RAM and flash operations on One ROM while One ROM is serving bytes:

- [One ROM CLI](https://onerom.org/cli) - Comprehensive command line tool for managing One ROM Fire devices over USB.
- `picotool` - Raspberry Pi's command line tool for managing RP2350 devices in BOOTSEL mode.  It can be used to read and write flash and RAM, and to reset the device.
- [pico⚡flash](https://picoflash.org) - a WebUSB PICOBOOT implementation offering the same primary primitives as picotool.

Some notes on this support:

- The plugin must be explicitly included in the config.  You can do this with a JSON config file One ROM Studio and the CLI, or, most easily with the `--plugin usb` flag when using the CLI to build firmware or program One ROM.

- There is currently no guarantee that the USB interface will be stable or remain the same in future releases.  In fact, the USB stack, as a plugin, has its own versioning and release train, may change VID/PID (the current value of 1209:f542 has not yet been approved by pid.codes).

- SRAM is directly available via PICOBOOT at 0x2000_0000.  The ROM image being served is located at this address.  However, both address bytes and data bits are mangled for ROM serving.  A "logical" image of the ROM being served is available for reading **and writing** live at 0x9000_0000.  For example, for an 8KB 2364 ROM, the actualy ROM image byte 0 is available at 0x9000_0000, byte 1 at 0x9000_0001, etc.  This allows reading **and changing** the ROM image almost instantly at runtime.  Bytes are updated in the ROM image being served in the order they come in over the PICOBOOT protocol.

  - `picotool` has a limitation that it does not support reading/writing addresses that it thinks are invalid, such as 0x9000_0000.  You will probably need to use picoflash for the time being if you don't want to use One ROM tools.

- Flash erase is **not** supported in this release.  While the ROM byte serving is entirely autonomous, erasing the flash that the plugins execute from would cause the MCU cores to fault, and break the USB stack.  Some thought needs to be applied before implementing live flash erase (and hence flash write).

- Reprogramming the image(s) stored on flash is currently only supported as part of a full firmware update, which causes One ROM to stop serving bytes while it is updated.  Updatig stored ROM images on flash is expected in a future release.

- The USB stack includes a CDC interface, which is currently unused, but may be used in the future for debugging, logging and other purposes.

- More USB functionality is expected in future releases - including live flash erase/writing, controling the image select pins (for example, to drive external devices).

### Plugins

This release adds **prototype** support for One ROM plugins, which are custom binary modules, separately built and then added to One ROM's configuration.  One ROM executes the plugins once ROM serving has been started.

Plugins can provide a massive variety of functionality and are hugely flexible - as they are effectively full microprocessor firmware in their own right.

While the RAM available to plugins varies between copious and extremely limited depending on the One ROM model, a plugin gets a full RP2350 core at its disposal, clocked at the current RP2350 clock speed, and full hardware access.  With great power comes great responsibility, and plugins can interfere with ROM serving if they do not avoid operations that might conflict - in particularly PIO/DMA operations and GPIO usage.

There is currently **no** guarantee of the [One ROM plugin API](sdrr/ora/api.h) remaining backwards compatible in any future One ROM release.  However, the general plugin concept is expected to be here to stay.

Limited stack space and static RAM is available to each plugin type - each core is allocated 1KB of stack, including the stack used to launch the plugin.  The system stack gets static RAM in addition to this whereas the user plugin has to allocate static RAM out of its 1KB stack.  There is no policing of the stack, nor any other sandboxes of plugins.

The only supported IRQs for plugins in this release are TIMER0_IRQ_0 and USBCTRL_IRQ, both of which are used by the USB system plugin.

A future concept of PIO plugin is under consideration, which would allow an optional third plugin type which would replace the main firmware's loading of its PIO and DMA byte serving algorithm - allowing the plugin to substitue its own.  This could be combined with a custom user (or system) plugin with the two operating in tandem to provide some very powerful capabilities.

### Other Changes

- A new version of [One ROM Lab](rust/lab-new/README.md) has been started and is used to test One ROM Fire 40 boards prior to shipping.  This is expected to replace other testers soon, and completely supercede the old version of One ROM Lab over time.

- Introduced fire-24-eadb01 as a possibly temporary workaround for a single fire-24-e board, as featured on Adrian's Digital Basement.  Do not rely on this hardware version, as it may be removed without warning in future.

### Fixes

- Disabling the status LED using firmware overrides didn't work for CPU serving mode for fire-24-a and fire-24-usb-b.  This has been fixed.

## v0.6.6 - 2026-02-25

The headline for this release is "bug fixes and other improvements".

There are also a significant number of fixes and improvements to the remainder of the One ROM fold, including some changes to existing behaviour, listed first:

- Improved regular (not 16 bit forced) /BYTE serving algorithm for 40 pin ROM, #153.

  This algorithm is marginally slower than previously but more robust.  If a faster algorithm is required, sacrifice /BYTE low handling with firmware_overrides->fire->force_16_bit = true in the ROM config.

- Resolved deficiencies in fire-24-a and fire-24-b PIO serving modes, #94.  All function is now supported on these boards, except for dynamic bank switching, which will likely remain unimplemented on these boards due to the lack of contiguity between X1/X2 and the CS pins.

  As a result fire-24-a and fire-24-b now default to PIO serving.  If CPU is desired (for example, for dynamic bank switching support), use firmware_overrides in the JSON config file.

- Changed default HW_REV/MCU in Makefile to fire-24-e/rp2350 (from ice-24-f/f401rc).  This only impacts using the old style `make` builds, not `scripts/onerom.sh` builds.

- All supported ROM types and CS configurations are now fully PIO tested as part of automated (CI) regression testing, for all Fire hardware revisions, #149.

- Fixed support for 2 ROM multi-ROM sets, for Fire boards in PIO mode, #110.  This impacted all Fire revisions in PIO mode - in particular the provided 1541 multi-ROM config did not work (and now does). 

- Forced unused address lines to appear driven low to the MCU for appropriate ROM types, to fix #154.

  This probably doesn't have any external impact, but if so it would be to 27 series ROMs and/or 2 set multi-ROM sets (24 pin only).  All supported 27 series ROM types have been tested manually with this change, as has 2 ROM multi-ROM sets on 24 pin boards.

- Implemented 2704 and 2708 ROM support on all existing Ice and Fire 24 pin boards, #156.

  2704/2708 support was tested on a T48 EPROM reader (with Pin Detect disabled), as a 2716 (as the T48 software doesn't support 2704/2708).  The 2704 image was correctly duplicaetd 4 times in the 2716 space and the 2708 twice.  Support for 2704/2708/2716 and 2732 was tested on fire-24-a and fire-24-e, both with PIO serving, and ice-24-j.

- This releases adds _prototype_ support for One ROM 32 #131 including:
  - Hardware revision fire-32-a
  - EPROM types 27C010, 27C020, 27C040 and 27C301
  - Support for 27C080 is included allowing two physically stacked One ROMs to be configured, each to serve half of the 27C080.  The one serving the lower 512KB should have cs1 set active low and the other one should have cs1 active high in their respective ROM configs.
  This support has been tested using the PIO emulator, but has not been tested with real hardware.  It is expected that bug fixes will be required when testing is done with real hardware, and One ROM 32 will be formally supported in a later release.

## v0.6.5 - 2026-02-22

The big new feature in this release is support for One ROM 40, hardware revision fire-40-a.  This emulates a 27C400 found in the Amiga A500, and other 16-bit systems.  I have successfully tested it on my Amiga, serving Kickstart ROM 1.3 and [DiagROMV2](https://www.diagrom.com/).

One ROM Lens is also included.  This is a web-based tool that runs the real One ROM serving algorithm within your web browser using a cycle exact PIO emulator.  It emulates One ROM's operation, allowing you to inspecting the GPIOs on a cycle by cycle basis using the logic analyzer style interface.  This is a great tool for understanding how One ROM (or any parallel ROM) works, for debugging firmware issues and interatively testing algorithm changes. To use, there are two steps:

1. Build the One ROM firmware, using an "old-style" config, with the emulated hardware type and image you want One ROM to serve: e.g. `HW_REV=fire-40-a MCU=rp2350 CONFIG=old-config/test/40-random.mk make`.
2. Build and run One ROM Lens: `make -C sdrr -f lens.mk serve`.

    Then point a browser at http://localhost:8000/index.html.

    It is likely that simpler commands will be added to the future to make this easier.

This release also introduces extensive automated regression testing for the Fire PIO serving algorithm (#134), for 24 and 28 pin boards.  As a result, a number of Fire PIO serving bugs have been fixed, including #110 and #94.

## v0.6.4 - 2026-02-07

- Fixed [#133](https://github.com/piersfinlayson/one-rom/issues/133), a complex issue where Studio v0.10 and earlier fail to build 28 pin v0.6.3 firmware images correctly.  This stemmed from 0.6.3 incorrectly including a non-backwards compatible change in order to support 231024 ROM types. As part of this:
  - v0.6.4 reverts that non-backwards compatible change, but retains 231024 support.  Specifically non-231204 ROM images use 64KB on flash, with only 231024 requiring 256KB.
  - v0.6.4 also introduces checking that the ROM image type is as expected and enters limp mode if not - rather than pretending to be OK and serving garbage.
  - Studio has been enhanced so it can be configured at runtime (via the manifest) with a maximum firmware version it can support - which overrides onerom-gen's maximum version, if the version Studio is allowed to build is lower.  Had this been in place earlier it could have been used to prevent pre-v0.1.11 version of Studio building bugged v0.6.3 firmwares, when #133 was found.

## v0.6.3 - 2026-02-03

- Added 231024 mask programmed ROM support.  Used by BBC Master and Apple IIgs.  (Only tested on BBC Master.)
- Add some Studio keyboard shortcuts (r for rescan, f for flash).

## v0.6.2 - 2026-01-27

This release of One ROM introduces RAM support - for 6116 and 2016 2KB 24-pin static RAM chips, using Fire 24 C and onwards hardware revisions.

For a demonstation of RAM support, and an explanation of how it works, see: https://youtu.be/o7dMY6p6OJU

One ROM's JSON [config file format](onerom-config/README.md) now uses "chip_sets" instead of "rom_sets" and "chips" instead of "roms".  However, the old strings will continue to work for backwards compatibility.

Other changes:
- The ability to execute the main loop from RAM has been removed, to allow 512KB to be used for ROM RAM image on RP2350.  It would be possible to add this back where the image size to be held in RAM is under 512KB, and for Ice boards, but as executing from RAM is currently unused, it has been removed for now to save development and test effort.
- fire-24-e revision added as **unverified**.  This adds USB-C, and is intended for production quantities of Fire 24 - as it required JLC's standard assembly service to be used, rather than economic, due to the use of 0201 passives.  The MCU has also been changed to the RP235A, to take advantage of the on-board flash, saving on cost (and space).
- Rename directories `config/` -> `old-config` and `rom-config` -> `onerom-config`.
- The new recommended by to build One ROM firmware is using [`scripts/onerom.sh`](scripts/onerom.sh).  This builds an empty firmware image, adds the chip metadata, and adds the ROM/RAM images in one command.  It even flashes the firmware if desired.  Images are output to [`builds/fw`](builds/fw).

## v0.6.1 - 2026-01-22

### Added

- Prototype RAM support for 24 pin RAM chips, which use the same pin-out as the 6116/2016 RAM.  See PR #98 and discussion #70. Requires building from command line using make and EXTRA_C_FLAGS=-DONE_RAM
- Support for Fire boards (fire-24-d specifically) to use image select pins that are shared with SWD pins.  Note that this means that having an SWD programmer connected at boot will tend to change the image select value to an unexpected one, as the pins will be pulled by the programmer.  In v0.6.0 only 2 image select jumpers were supported on fire-24-d.
- Support for Ice boards (ice-24-j specifically) to use image select pins that are shared with SWD pins.  Note that this means that having an SWD programmer connected at boot may change the image select value to an unexpected one, as the pins will be pulled by the programmer.  In v0.6.0 only 2 image select jumpers were supported on ice-24-j.  Also, unlike the Fire boards, the ice-24-j (and similar) boards will disconnect from the debug probe during boot because of this function, so reconnecting will be necessary.
- Check in Studio/onerom-gen that firmware version is not too new (next major release) when building firmware images.
- Promote fire-24-d and ice-24-j to verified hardware revisions.

### Fixed

- Fixed #90 in v0.6.0 when older (pre v0.1.8) versions of One ROM Studio are used to build firmware images with more than one ROM set, One ROM will not boot on any ROM set other than ROM set 0.
- 2732 ROM type serving was broken - the top 2K replicated the bottom 2K.  Fixed (#103).  This included fixing the testing, which had also not caught this issue.

### Fixed

- 2732 ROM type serving was broken - the top 2K replicated the bottom 2K.  Fixed (#103).  This included fixing the testing, which had also not caught this issue.

## v0.6.0 - 2026-01-14

**EXPERIMENTAL RELEASE** - may contain bugs, use with caution.  If you hit problems, report them as issues and revert to v0.5.10 or earlier.  See [#87](https://github.com/piersfinlayson/one-rom/pull/87) for details of testing done.

This major release of the One ROM firmware adds support for low-level One ROM firmware configuration from the ROM config files, allowing per-ROM image configuration of processor clock speed, status LED behaviour, and other low-level capabilities from One ROM Studio, and other tools.

As a major firmware release, there are some non-backwards compatible changes in this release:

- The ROM config JSON schema has changed - `sel_jumper_pull` is now a Vec<u8>, to allow per-pin SEL jumper pull direction.
- The default PIO configuration is now SLOW_CHAR_CHAR, to improve ROM serving compatibility.  PIO configuration can be overriden on a per ROM set basis using `serve_alg_params` firmware overrides.

### Added

- Support for per-ROM image low-level configuration, including processor clock speed, status LED behaviour, and other low-level capabilities.  See the ROM Config [README](rom-config/README.md) for details.
- Support for fire-24-d and ice-24-j hardware revisions.
- Enhanced onerom-fw CLI tool to receive a local firmware file.
- One ROM Studio v0.1.8.
- Firmware v0.6.0.

### Changed

- ROM config JSON schema change - `sel_jumper_pull` is now a Vec<u8>, to allow per-pin SEL jumper pull direction.
- PIO support is now built into all RP2350 firmwares, and is enabled/disabled by default using RP_PIO build flag.
- RP2350 no longer enters filesystem mode when USB connected - only PICOBOOT protocol supported.

### Known Limitations

- The firmware does not support image select pins shared with SWD pins.  At present image select pins shared with SWD pins are ignored.
  - This is expected to be added in a future release.
  - It is relevant for `fire-24-d` and `ice-24-j` hardware revisions.
  In additon, the configurable per-pin jumper sel behaviour has not been explicitly tested.
- `swd_enabled`: false is not yet functional.  (It is not clear that this is a good idea anyway, as it would make a non-USB board more difficult to reprogram.)  This setting may be removed in a future release.

## v0.5.10 - 2026-01-03

Promote fire-24-c to verified and recommended 24-pin Fire version.

### Added

- issue #77 - Support for serving multi-ROM sets using Fire PIO algorithm.
- ROM types for 32 and 40 pin ROMs

### Changed

- issue #78 - Move RAM ROM image to 0x2000_0000 to prepare for 40 pin versions.

### Fixes

- issue #76 - fire-24-c PIO algorithm fixes.

## v0.5.9 - 2026-01-01

This release adds new One ROM hardware revisions and ROM type support.

### Added

- 231024 (28 pin) ROM type support.
- Hardware revision ice-24-i - Combined Pro (SWD) and USB 24 pin Ice version.
- Hardware revision fire-24-c - Combined Pro (SWD) and USB 24 pin Fire version.
- Hardware revisions fire-28-a2 and fire-28-a3 - Combined Pro (SWD) and USB 28 pin Fire versions.

### Crates

- onerom-config 0.2.5, 0.2.6
- onerom-fw 0.1.5, 0.1.6
- onerom-gen 0.2.3, 0.2.4
- sdrr-fw-parser 0.5.7, 0.5.8

## v0.5.8 - 2025-12-12

This release adds 28 pin ROM support for the new One ROM Fire 28-pin version, fire-28-a.

### Added

- Support for 28 pin ROM types using fire-28-a.  23128 has been tested in a C64C. with 2764, 27128, 27256 and 27512 tested in an EEPROM reader.  It is STRONGLY recommended NOT to use an EEPROM reader to read One ROM, as it may apply 12V to pin A9.

## v0.5.7 - 2025-12-09

### Fixed

- Erroneous CE/OE pin numbers for 2716/2732 ROMs.

## v0.5.6 - 2025-12-09

### Added

- Support for 2716/2732 ROMs (2716 tested).
- PIO support for 2316/2716/2732 ROMs (untested)
- Studio 0.1.4

### Fixed

- Comment in Makefile - B is now default serving algorithm.

## v0.5.5 - 2025-11-18

This release adds support for the RP2350 One ROM serving ROMs using the RP2350's PIO/DIO peripheral, allowing fully autonomous ROM serving without any CPU involvement.  A VIC-20 kernal can be served successfully with the RP2350 clocked at just 22MHz, the C64 kernal at 41MHz and the both systems' character ROMs at 51MHz.  There are some limitations, meaning this is not yet the default Fire algorithm:
- Dynamically bank switched ROMs _are_ supported.
- Only CS lines which are contiguous are supported - hence the 2316 is _not_ supported on either rev A or USB rev B.
- Multi-ROM sets, via X1/X2, are _not_ supported, as they are not contiguous with the CS lines in current hardware.

For full support a hardware revision must order the CS lines contiguously either:
- X2/X1/CS1/A12/A11 or
- A11/A12/CS1/X1/X2

To build use `EXTRA_C_FLAGS=-DRP_PIO` when running `make`.  See `sdrr/src/piorom.c` for further details of the PIO/DMA algorithm, and configuration options.

### Fixed

- Enabled FP extensions on both Ice and Fire to avoid hard fault if floating point instructions are used by the compiler.

## v0.5.4 - 2025-11-12

This release adds support for the One ROM Fire (RP2350) USB version, via hardware revision `fire-24-usb-b`.  Current USB support is per Ice - plugging in USB disables ROM serving, and puts the RP2350 into DFU mode to allow firmware updates.  A future release is expected to add Fire USB support in parallel to ROM serving. 

### Added

- Added first RP2350 USB version, [Fire 24 USB B](sdrr-pcb/unverified/fire-24-24-b/README.md), as unverified.
- Added [Ice 24 USB H3](sdrr-pcb/unverified/one-rom-ice-usb-h3-24-pin/README.md) as unverified.
- Moved [Ice 24 USB H2](sdrr-pcb/verified/one-rom-ice-usb-h2-24-pin/README.md) to verified.

### Added

- `onerom-config` 0.2.2 - Added method to query ROM power pins.
- Studio:
    - See [rust/studio/CHANGELOG.md](rust/studio/CHANGELOG.md) for details.
    - Studio is released independently of firmware - see `studio-*` github tags.
- ROM Configs:
    - Blank ROM config (for manufacturing/testing) - /rom-configs/blank.json
    - Added pincoder 2021 version system 3, 5, 6 and 7 ROM configs (2332 ROMs)
- Allow `sdrr-fw-parser` to parse up to v0.5.999 firmware versions. 

### Fixes

- [#43](https://github.com/piersfinlayson/one-rom/issues/43) - Let sdrr-fw-parser parse later versions of fw. Supports up to v0.5.999 with no code/wasm/site changes required.
- Allow multi-ROM sets to be built in One ROM Studio.  Unsure when this was regressed

## v0.5.3 - 2025-10-24

The major addition in this release is the companion desktop application, One ROM Studio, which provides a native GUI for creating One ROM firmware images, and analysing and flashing One ROM devices.

One ROM Studio on Windows

Features include:
- Supported platforms: Windows, Mac, Linux (Ubuntu, Debian and Raspberry Pi OS)
- Supported One ROMs: all variants including Ice/Fire and Pro/USB
- Program One ROMs with a choice of ROM images
- Generate and save One ROM firmware files
- Analyse One ROM devices and firmware files
- Automatic debug probe and One ROM USB detection

One ROM Studio can be downloaded from https://onerom.org/studio/.

### Added

- Added "limp mode" support to detect when an incompatible firmware has been flashed to an Ice One ROM.  It blinks fast in this state and, if it is a USB model, allows the device to drop into DFU mode when USB is connected, to allow flashing of a compatible firmware.  Note that "slower" MCU firmwares are permitted by "faster" MCUs - but not the other way around.  See #37 for details.

### Fixes

## v0.5.2 - 2025-10-14

New in this release is a command line firmware image creation tool `rust/fw`.  This dynamically creates a custom One ROM firmware image from a specified:
- set of ROM images (specified as a JSON config file)
- model, board and MCU type (specified as command line arguments)
- optional firmware version (defaults to the latest version available)

To build:
```bash
cd rust/fw
cargo build --release --bin onerom-fw
# Binary is located at /rust/target/release/onerom-fw
```

This is a precursor to simplifying the CI builds to avoid having to create every combination of hardware/ROM config as build artifacts.  The hardware combinations can be pre-built with empty metadata and ROM image data, and this tool then composes a complete firmware image, ready for flashing.

As v0.5.1, and empty firmware image can also be flashed - One ROM then blinks its status LED slowly, and can have metadata and ROM images flashed to it later.

The complete list of available "empty" hardware configuration firmwares can be found at https://images.onerom.org/releases.json.

This command line tool may also be augmented with a native GUI, in parallel to the web-based tool at https://onerom.org/prog/.

### Changes

- Improved `onerom-gen` testing, and improved `onerom-config` and `onerom-gen` validation.

### Fixes

- Fix rust/gen/tests for boards with address lines all >=8.
- Fix `sdrr-info` processing of firmware from v0.5.1 onwards with detailed metadata content in a valid, but unexpected, order.

## v0.5.1 - 2025-10-13

For the average user, there are no particularly notable changes in this release, except the addition of the [Atari 800XL BASIC ROM config](/config/atari800xl.mk).

The firmware generator process underwent a major overhaul in this release:
- Support ROM types and hardware (PCB) revisions are now parsed at build time, which can be included in Web Assembly code.
- `sdrr-common` has been retired and mostly replaced with `onerom-config`
- Much of `sdrr-gen` has been moved out to `onerom-gen` crate, which can be used in other Rust projects, including Web Assembly.
- There is a new `onerom-wasm` crate at https://github.com/piersfinlayson/one-rom-wasm, which can be used to build Web Assembly code to generate One ROM firmware images in the browser.  Web Assembly packages, documentation and examples are located at https://wasm.onerom.org/.
- A metadata and ROM-less firmware can be built with `EXCLUDE_METADATA=1`.  When flashed with ths firmware, One ROM blinks its status LED slowly.  It can subsequently have metadata and ROM image fragments flashed, and, when reset, serves the newly flashed images.  This is expected to be useful for release artifacts and manufacturing, as a single firmware per hardware variant per release can be built, with metadata and ROM images added later, rather than the current need to build a firmware per hardware variant **per configuration** per release.

There is more work planned to the firmware upgrade process, including multi-stage USB device updates using the new capabilities, but this release has laid the groundwork and enabled some exciting new web-based features.

Also, the first, prototype 28 pin ROM support using hardware revision `ice-28-a` is in this release.  It successfully emulates a 27128 ROM (i.e. without the 3rd CS line on a 23128).  It has been tested successfully on a C64C, replacing the combined KERNAL/BASIC ROM with a One ROM Ice 28 A, clocked at just 55MHz using an STM32F446RCT6. This hardware revision is unlikely to be taken forwards - a different hardware layout is required to support 23128 with the 3rd CS line being used, as well as 32KB and 64KB ROMs.

Some default firmware configuration has been changed:
- BOOT_LOGGING is now disabled by default to improve boot times.

### New

- [Atari 800XL BASIC ROM config](/config/atari800xl.mk) included (and tested and working!)

### Changes

- Call out from sdrr-gen to wget to retrieve images located on sourceforge, as cloudfare seems to spot and block Rust TLS.
- Moved the PCB config/property files from `/hw-config` to `/rust/config/json`.

### Fixes

- Make "no ROMs installed" LED blink pattern slower, to be more visible.  Now on for 0.5s, off for 2.5s.  Previously flashed much too fast to be used properly.

## v0.5.0 - 2025-10-07

This release adds a bunch of hardware revisions, plus a modified flash and firmware format, to ease future device re-programming.

As a consequence of the new flash/firmware format, some of the STM32 variants (F401RB/RC, F411RC, F446RC) support 2 fewer ROM images than before.

### New

- New flash/firmware format, with firmware code, followed by ROM metadata, followed by ROM images. 
- Added One ROM Ice USB H2 (unverified).
- Added One Rom Ice USB H (verified) kicad files.
- Added One ROM Fire USB B (unverified)

### Changes

Moved USB programmer site to https://github.com/piersfinlayson/one-rom-site repo.

## v0.4.4 - 2025-09-30

This is a point release that changes the release artifact generation, to set up the One ROM USB programmer to be able to offer to flash pre-built firmware images from the release artifacts.

Release artifact change summary:
- Include additional hardware variants
- Only include .bin files (not .elf, .dis, .map) in the release artifacts.
- Remove some of the less common STM32 variants from the release artifacts (to save build time and space)
- Include a build artifact manifest JSON file. 

If the particular release artifact you want is no longer included, you can build it yourself from source.

### Changes

Updated:
- USB One ROM site (onerom.piers.rocks):
  - Added the ability to select a local file as the firmware source, in addition to a URL.
  - Add check to prevent non-USB firmware being flashed.
  - Add check to ensure the MCU the firmware was build for matches the MCU the user selected.
- CI build process, to create release artifacts:
  - Now only creates .bin files (not .elf, .dis, .map) - if you want the other types, build them yourself.
  - Creates images for multiple different hardware revisions.

## v0.4.3 - 2025-09-29

Added USB DFU support for firmware updates over USB, along with STM32 24-pin rev H hardware (24-h) which includes a micro-USB connector.  One ROM detects when USB is connected, disables ROM serving, and enters STM32 DFU mode to allow the firmware to be updated.

There is also a new web-based programmer for One ROM USB, at https://onerom.piers.rocks/.  This can be used on Chrome or Chromium based browsers on Windows, Linux, or MacOS to program an attached One ROM USB.

### Changes

Updated:
- sdrr
- sdrr-hw-config
- sdrr-pcb
- sdrr-common
- sdrr-fw-parser
- sdrr-gen
- sdrr-info

### Fixes

## v0.4.2 - 2025-09-06

Added [One ROM Lab](rust/lab/README.md) support, which allows a One ROM to be used as a ROM reader.

### Changes

- Added fw-parser for One ROM Lab
- Modify sdrr-info/parser to support Airfrog custom firmware changes

### Fixes

- Probably a few here and there.

## v0.4.1 - 2025-08-28

### Changes

- Move STM32F4 hardware rev G to verified.
- Add KiCad design files for RP2350 rev A and STM32F4 rev G.

### Fixes

- #8 - reduce severity of VOS not ready warning, as it appears to be benign.
- Include RP2350 images in github release.
- Add RP2350 build commands to README.md and generally update the docs to refer to One ROM/RP2350.

## v0.4.0 - 2025-08-24

**The RP2350 release.**

This version contains the first RP2350 PCB revision, and mostly complete firmware support.

Should you use the new RP2350 hardware revision A?  Only limited testing of the RP2350 One ROM has been done so far, but it has generally performed well.

There is one outstanding, known issue - when using the RP2350 One ROM a character ROM on a PAL VIC-20 occasionally the machine boots to a black screen background - that is the machine boots to BASIC and shows the expected text, but the screen is black, not white.  This may be a boot timing issue - that perhaps One ROM RP2350 is not booting fast enough for the VIC chip, which is getting corrupted somehow.  This issue does not appear on a C64 (which has a different video bus architecture).

You may want to order and test small quantities of RP2350 based boards for now, as there is some risk of a hardware design issue coming to light.  However, the hardware appears solid in early testing, so it is likely most issues can be overcome by firmware changes - and it is expected that the RP2350 revision A will continue to be supported in future releases, even should another variant be released.

Other notable changes:

- Instead of building with `STM=<mcu variant> make`, you now need to use `MCU`:

  ```bash
  MCU=<mcu_variant> make
  ```

### Changes

- Added RP2350 support.
  - Hardware rev A.
  - Includes single ROM images, dynamically bank switched, and multi-ROM sets.
  - Includes image select jumpers, status LED, overclocking.
  - Features not supported include: C main loop, MCO output.
  - For the gory details of supporting the RP2350, see [RP2350](docs/RP2350.md).
- Added STM32F4 24-pin PCB rev G hardware configuration.  This adds a different programming header and one more image select jumper (so 5 in total, plus X1/2).
- Added hardware and firmware configuration to specify whether the image select jumpers and X1/X2 pins are pulled high or low when the PCB jumper is closed, to allow for different PCB designs.
- Added firmware support for up to 7 image select jumpers.
- Change STM32 MCO (and MCO2) divider to be /5 (previous value was /4).  Makes it easier to measure the clock speed of an overclocked STM32F4.
- Substantially refactored platform specific code to break out platform agnostic code - significant work to `sdrr/src/main.c`, `utils.c` and `rom_impl.c`.
- Tested overclocking and various STM32 clones.

### Fixes

- It is likely that the 4th image select pin on revs E/F didn't work properly - this has been fixed.

## v0.3.1 - 2025-08-16

The project has been renamed One ROM (To Rule Them All).

This release is a few odds and ends including some hardware improvements:
- One ROM hardware revision [F2](/sdrr-pcb/verified/stm32f4-24-pin-rev-f2/README.md) is currently recommended.
- An **unverified** hardware revision [G](/sdrr-pcb/unverified/stm32f4-24-pin-rev-g/README.md) is in testing.  This brings mostly layout improvements and slightly reduced manufacturing costs.
- The fastest STM32F4 MCU, the STM32F446 has been verified to work.   This brings a max supported clock speed of 180MHz, and has run stably up to 300MHz in testing.
- The STM32F405 has provided slower than expected (more details below).  It is supported and a decent choice, but the GigaDevices GD32F405 appears to be more performant.

### Changes

- Speed up STM32F405 support:
  - The STM32F405 is under-performant vs the other devices at the same clock speed - needs around 30-40% faster clock speed.
  - Added CCM RAM support for the F405, bringing the uplift in clock speed down to around 15-20%.
  - To disable CCM RAM set `C_EXTRA_FLAGS=-DDISABLE_CCM=1` when building.
  - The STM32F405 is still a decent MCU choice for One ROM, as its max clock speed is 168MHz compared with the F411's 100MHz.  However, users may wish to use the GigaDevices clone GD32F405, which appears to have no performance penalty. 
- Hardware revision 24-f2 is now verified.  JLC have successfully fabbed using the hardware files both STM32F411 and STM32F405 variants.
- Allow more aggressive overclocking (up to 400MHz).
- Validated STM32F446RCT6 (STM32F446RET6 highly likely to work as well).  Successfully tested as C64 char ROM, and verified clock speed of 180MHz (via MCO1 showing 45MHz = SYSCLK/4).  Also overclocked to 300MHz, ran stably.
- Added **unverified** hardware revision 24-g.

### Fixes

- Explicitly prevent COUNT_ROM_ACCESS and C_MAIN_LOOP being configured together, as they are incompatible.
- Fixed ability to run main loop from RAM (this tends to be slower than from flash, so isn't recommended).

## v0.3.0 - 2025-08-12

The main user facing change in this release is the addition of support for remote analysis and co-processing alongside the SDRR device via plug-ins, such as [Airfrog](https://piers.rocks/u/airfrog) - **a tiny $3 probe for ARM devices**.  This allows you to inspect the firmware and runtime state of the SDRR device, and change its configuration and ROM data - **while it is serving ROMs**.

There is also new ROM access counting feature, which causes SDRR to count how times the CS line(s) go active.  This can be extracted and visualised using [Airfrog](https://piers.rocks/u/airfrog) and other SWD probes, to determine how often the ROMs are accessed based on host activity.

ROM Access Graph

The Rust tooling has been substantially refactored to easier to integrate SDRR support in third-party tooling, such as [Airfrog](https://piers.rocks/u/airfrog).  In particular there is [Firmware Parser](rust/sdrr-fw-parser/README.md) crate, which can be used to parse the firmware from a file or running SDRR, and extract information about the configuration, ROM images, and to extract ROM images from the firmware.

### Changes

- TI-99/4A and CoCo2 configurations have been added to the [third-party configs](config/third-party/README.md) directory.  Thanks to [@keronian](https://github.com/keronian) for contributing these.
- Added a C main loop implementation for which GCC produces the assembly/machine code.  This requires a roughly 25% faster clock speed.  Use `EXTRA_C_FLAGS=-DC_MAIN_LOOP` when running `make` to use this version.
- Stored off image files used to create the firmware in `output/images/`.  This allows post build inspection of the images used.  It also enables additional tests - `sdrr-info` can be now be used as an additional automated check (along with `test`), to ensure the images in the firmware are correct, and validate the behaviour of `sdrr-info` and `test` to be compared.
- Substantial refactoring of `sdrr-gen`, to make it more maintainable.
- Substantial refactoring of `sdrr-fw-parser` in order to make it suitable for airfrog integration.
- Added ROM access counting behind COUNT_ROM_ACCESS feature flag.  When enabled, the firmware updates a u32 counter at RAM address 0x20000008 every time the chip select line(s) go active - i.e. the ROM is selected.  This can be read by an SWD probe, such as [Airfrog](https://piers.rocks/u/sdrr). 
- Changed default Makefile configuration to HW_REV=24-f COUNT_ROM_ACCESS=1 STATUS_LED=1.
- Added a manufacturing test tool [`sdrr-check`](rust/sdrr-check/README.md).
- Changed default build config:
  - HW_REV=24-f
  - STATUS_LED=1
  - COUNT_ROM_ACCESS=1
- Added retrieval of mangled ROM images from firmware.  This can be used to compare the embedded images between different firmwares and to collect a pre-mangled ROM images in order to overwrite a running SDRR's RAM image with it.
- Added new "One ROM To Rule Them All" BASIC program for upcoming video. 

### Fixes

- Probably a few here and there.

## v0.2.1 - 2025-07-22

The main new feature in this version of SDRR is the addition of dynamic [bank switching](docs/MULTI-ROM-SETS.md#dynamic-bank-switching) of ROM images.  This allows SDRR to hold up to 4 different ROM images in RAM, and to switch between them **while the host is running** by using the X1/X2 pins (hardware revision F and later) to switch between them.  Some fun [C64](config/bank-c64-char-fun.mk) and [VIC-20](config/bank-vic20-char-fun.mk) character ROM configurations that support bank switching are included.

In other news:
- The default ROM serving algorithm has been improved, leading to better performance, and hence the ability to support more systems with lower powered STM32F4 devices than before.  Check out [STM32 Selection](docs/STM32-SELECTION.md). The current price/performance sweet spot is the F411.
- [Hardware revision E](sdrr-pcb/verified/stm32f4-24-pin-rev-e/README.md) is now fully verified, so manufacture these with confidence.
- If you'd rather use [revision F](sdrr-pcb/unverified/stm32f4-24-pin-rev-f/README.md) (required for multi-ROM and bank switching support), at least once user has reported getting these manufactured and working with his NTSC VIC-20 - although they did not testing either multi-ROM or bank switching support.

### Changes

- Added pull-up/downs to X1/X2 in multi-ROM cases, so that when a multi-set ROM is configured, but X1/X2 are not connected, the other ROMs in the set still serve properly.
- Improved serving algorithm `B` in the CS active low case.
- Moved to algorithm `B` by default.
- Measured performance of both algorithm on all targets.
- Refactor `rom_impl.c`, breaking out assembly code to `rom_asm.h` to make the main_loop easier to read, and commonalising a bunch of the code for greater maintainability.
- Added detection of hardware reported STM32F4 device and flash size at runtime, and comparison to firmware values - warning logs are produced in event of a mismatch.
- Verified [hw revision e](/sdrr-pcb/verified/stm32f4-24-pin-rev-e/) - supports STM32F4x5 variants in addition to F401/F411, all passives are now 0603, contains a status LED and a 4th image select jumper.
- Added [documentation](/docs/STM32-CLONES.md) on STM32 clones.
- Moved firmware parsing to [`rust/sdrr-fw-parser`](/rust/sdrr-fw-parser/README.md) crate, which can be used to parse the firmware and extract information about the configuration, ROM images, and to extract ROM images from the firmware.  Done in preparation for using the same code from a separate MCU.
- Moved Rust code to [`rust/`](/rust/) directory to declutter the repo a bit.
- Added experimenta; [build containers](/ci/docker/README.md) to assist with building SDRR, and doing so with the recommended build environment.
- Added dynamic [bank switchable](docs/MULTI-ROM-SETS.md#dynamic-bank-switching) ROM image support, using X1/X2 (you can use __either__ multi-ROM __or__ bank switching in a particular set).
- Added fun banked character ROM configs.
- Added VIC-20 NTSC config.
- Added retry in [ci/build.sh](ci/build.sh) to allow for intermittent network issues when downloading dependencies.
- Added [demo programs](demo/README.md) for C64 and VIC-20 to list SDRR features and other information/

### Fixes

- Fixed status LED behaviour, by placing outside of MAIN_LOOP_ONE_SHOT, and using the configured pin.
- Got `sdrr` firmware working on STM32F401RB/RC variants.  These have 64KB RAM, so can only support individual ROM images (quantity limited by flash) and do not support banked or multi-set ROMs.

## v0.2.0 - 2025-07-13

This version brings substantial improvements to the SDRR project, including:

- A single SDRR can be used to replace multiple ROM chips simultaneously.
- New [`sdrr-info`] tool to extract details and ROM images from firmware.
- Add your own hardware configurations, by adding a simple JSON file.
- New STM32F4 variants supported.
- Comprehensive testing of compiled in images to ensure veracity.

Care has been taken to avoid non-backwards compatible interface (such as CLI) changes, but some may may have been missed.  If you find any, please report them as issues.

### New Features

- Added support for ROM sets, allowing SDRR to serve multiple ROM images simultaneously, for certain combinations of ROM types.  This is done by connecting just the chip selects from other, empty sockets to be served, to pins X1/X2 (hardware revision 24-f onwards).  Currently tested only on VIC-20 (PAL) and C64 (PAL), serving kernal and BASIC ROMs simultaneously on VIC-20 and kernal/BASIC/character ROMs simultaneously on the C64.  See [Multi-ROM Sets](/docs/MULTI-ROM-SETS.md) for more details.
- Added [`sdrr-info`](/rust/sdrr-info/README.md) tool to parse the firmware and extract information about the configuration, ROM images, and to extract ROM images from the firmware.  In particular this allows
  - listing which STM32F4 device the firmware was built for
  - extraction of ROM images from the firmware, for checksumming and/or comparing with the originals.
- Moved hardware configuration to a dynamic model, where the supported hardware configurations are defined in configuration files, and the desired version is selected at build time.  Users can easily add configurations for their own PCB layouts, and either submit pull requests to include them in the main repository, or keep them locally.  For more details see [Custom Hardware](/docs/CUSTOM-HARDWARE.md).
- Added support F446 STM32F446R C/E variants - max clock speed 180 MHz (in excess of the F405's 168 MHz).  Currently untested.
- Added [`test`](/test/README.md), to verify the images source code files which are built into the firmware image, output the correct bytes, given the mangling that has taken place.

### Changes

- Updated VIC-20 PAL config to use VIC-20 dead-test v1.1.01.
- 24-pin PCB rev E/F gerbers provided (as yet unverified).
- Many previously compile time features now moved to runtime.
- Makefile produces more consistent and less verbose output.
- Added `sddr_info` struct to main firmware, containing firmware properties, for use at runtime, and later extraction.  This should also allow querying the firmware of a running system via SWD in future.

### Fixed

- Moved to fast speed outputs for data lines, instead of high speed, to ensure VOL is 0.4V, within the 6502's 0.8V requirement.  With high speed outputs, the VOL can be as high as 1.3V, which is beyond the 6502's 0.8V requirement.

## v0.1.0 - 2025-06-29

First release of SDRR.

- Supports F401, F411, and F405 STM32F4xxR variants.
- Includes configurations and pre-built firmware for C64, VIC-20 PAL, PET, 1541 disk drive, and IEEE disk drives.
- PCB rev D design included.
- Release binaries

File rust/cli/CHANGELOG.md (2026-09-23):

# CLI Changelog

## v0.4.1 - 2026-09-17

- **Add `onerom console`.**  Displays what One ROM sends, like `monitor log`,
  and sends what you type to the retro system, which reads it with RBCP
  `PIPE_READ`.  Requires firmware v0.7.3 with the USB and host-control plugins.
- **Add the `27C400Pin31A17` and `27C200Pin31NC` chip types**, for the Amiga
  A500 rev 5 Kickstart socket.

## v0.4.0 - 2026-09-08

- **`peek` and `poke` help no longer show an argument the commands reject.**
  Both gave `onerom peek live ...`, and the top-level aliases take their options
  directly.
- **A device that cannot be read is now named in one line and ignored.**
  `onerom scan` says whether it could not be opened or could not be read, warns
  only where nothing else was found, and adds the USB identity and the
  underlying error under `--verbose`. `--unrecognised` no longer picks one to
  program, since a device that will not answer cannot be programmed.
- **A ROM image smaller than the chip, with `size_handling=trunc`, no longer
  reports the image as too large.** It said the image was larger than the chip
  supported while printing a size smaller than the chip's. It now reads as too
  small, and points at padding or duplication.
- **Build errors name the ROM image at fault by its file.** They gave a chip
  number that counted plugin slots and every chip in a set, so nothing a
  `--slot` or a config entry produced it. A `location` window running past the
  end of its file now says so, instead of advising padding that cannot reach
  it, and an image too large for a 27C080 says that one One ROM serves half of
  one.
- **The CLI warns when a 16-bit ROM image looks to be stored the wrong way
  round.** A 16-bit ROM supplies two bytes at a time, an image may hold each
  pair in either order, and One ROM reads the low byte first. `program`,
  `firmware build` and `image swap-bytes` now compare the image's first bytes
  against known ROM headers and say what they recognised. An image matching
  none is left alone, and nothing is refused.
- **`onerom firmware inspect --verbose` lists plugins separately** and numbers
  ROM slots from 0 with plugins excluded, as `onerom inspect slots` already
  did. An image holding the USB plugin and two ROM images reported three slots.
- **`onerom program --reset-host <PIN>` resets the host system after
  programming.** It waits for the One ROM to come back on the USB bus and then
  pulses that pin low, as `control reset` does, so flashing an image and
  restarting the machine into it is one command. The pin is checked against the
  image being flashed - a pin One ROM will serve with, or one the board uses
  itself, is refused before its ROM images are fetched - and it runs for each device in
  a `--batch`. The pulse is 100ms; `control reset` remains the way to choose
  another. Conflicts with `--fast`, `--stopped` and `--no-reboot`.
- **`program --follow` says up front when the image cannot serve it.** An image
  with no USB system plugin leaves the bus the moment the One ROM starts
  serving, so there was never a log to follow - previously discovered after
  programming, when the port could not be found.
- **`--hold` is bounded where the device bounds it.** `control pin --hold` and
  `control reset --hold` refuse anything above the 60 second limit the device
  enforces, as the command line is read rather than after it has been sent.
- **`onerom inspect led --verbose` and `inspect rgb --verbose` now say when
  they could not reach the device**, instead of reporting that the two LEDs are
  not on the same GPIO.
- **`onerom control pin`, `control rgb` and `inspect gpio` now work first time
  against a One ROM running an older USB plugin.** They previously waited and
  then failed, and succeeded when run again.
- **`onerom control rgb` drives the RGB LED on the models that have one.**
  `on`, `off`, `beacon`, `flame`, `cycle`, `breathe` and `blink`, with
  `--colour` (ten names or `#RRGGBB`), `--brightness`, `--period` and `--hold`.
  The device times a hold, so it completes even if the command does not. A
  board without an RGB LED says so rather than appearing to work. Needs
  firmware v0.7.2 with the v0.2.2 USB plugin.
- **`onerom control led blink`** blinks the status LED on and off until
  something changes it, or for a `--hold` if you give it one. A slower,
  unbounded sibling of `beacon`.
- **Each LED mode now has a shortest period it can run at**, and a shorter one
  is refused with a message naming that mode's minimum rather than being
  accepted and quietly run slower. 1000ms for `cycle` and `breathe`, 500ms for
  `flame`, 50ms for `beacon` and `blink`.
- **`onerom inspect led` and `onerom inspect rgb` say what each LED is doing.**
  The mode it is in, how fast it is running and which GPIO it is on, plus the
  colour and brightness for the RGB LED, read from the One ROM rather than
  remembered by the CLI. A board with no RGB LED reports that rather than
  failing, and where the two LEDs share a GPIO both commands say so. Needs
  firmware v0.7.2 with the v0.2.2 USB plugin.
- **`onerom control led` gains `--hold` and `--period`.** All four
  subcommands take `--hold <MS>` to run the mode for a bounded time and then go
  back to whatever the LED was doing, and `beacon` and `flame` take
  `--period <MS>` for one blink and one pass of the flicker. The device times
  the hold, so it finishes even if the command does not. Needs firmware v0.7.2
  with the v0.2.2 USB plugin — the CLI checks first and says so, rather than
  reporting success on a device that would ignore them. A plain `on`, `off`,
  `beacon` or `flame` is unchanged and still works on any One ROM.
- **Breaking: `--name` now names the One ROM, not the configuration.** It is an
  alias for `--instance-name` on `program` and `firmware build`, where it was an
  alias for `--config-name` — a command line using `--name` still runs and names
  the device instead, except with `--no-config`, where it is now rejected.
  `docs/CLI-MANUAL.md` gains a breaking-changes section near the top and the
  full history at the end.
- **`onerom monitor log` shows a running One ROM's log as it is written.**
  It attaches to the One ROM's USB serial port and prints the firmware and
  plugin logging it sends, until the One ROM is disconnected, rebooted or
  stopped, or you press Ctrl-C. What the One ROM has logged since anything last
  listened arrives first, so the boot log is still there when you attach.
  `--output` keeps a transcript as well as showing it. Needs a running One ROM
  programmed with the USB system plugin. On Linux the packaged udev rules now
  tell ModemManager to leave One ROM alone — without that it probes the port and
  consumes the log before you get to it, so a hand-installed copy of the rules
  wants replacing.
- **`onerom program --follow`** goes straight from programming to watching the
  log, so you see the boot log of the firmware just flashed. It cannot be
  combined with `--fast`, `--stopped`, `--no-reboot` or `--batch`.
- **`onerom self` reports and downloads new releases of the CLI itself.**
  `self check` says whether a newer CLI has been published for your platform;
  `self download` fetches a published artifact — for this platform, another
  (`--target`), or all of them — and verifies it against its published SHA-256.
  Nothing is installed, and no check runs unless you ask for one.
- **A plugin named by a config is now checked for firmware compatibility**, as
  one given with `--plugin` already was. A plugin binary declares only the
  minimum firmware it needs, so a release withdrawn for a newer firmware — USB
  v0.1.2, which hard faults on v0.7.0 — was previously built in and flashed.
  A local or third-party plugin has nothing published to check against and is
  still built in as-is; an unreachable images server warns rather than failing.
  A refusal names the newest release that does support the firmware, with the
  URL to point the config at.
- **Motorola S-record images are now accepted alongside Intel HEX.**
  `--slot format=srec` decodes an S-record file to a binary image before it is
  built in, with the same optional `load-address=` giving the absolute address
  that maps to byte 0 of the ROM. Unwritten bytes read as `0xFF`.
- **`onerom image convert` gains `srec`** on either side of `--from`/`--to`, so
  it now converts between `binary`, `ihex` and `srec` in any direction,
  including `ihex` to `srec` directly. S-record output uses one data record
  type throughout — the narrowest that addresses the whole image — with the
  paired terminator.
- **`onerom program --verify` is supported**, and its help text and the CLI
  manual now say so. It reads flash back after programming and compares it
  against the image, and always did — both described it as not yet supported.
- **New 24, 32 and 40 pin boards** — `fire-24-g`, `fire-32-c` and `fire-40-c`.

## v0.3.0 - 2026-08-09

- **`--slot` now accepts every chip type the target firmware can serve on the
  board.** For v0.7.0 firmware onwards that is the served layout itself, so the
  overhang and fly-lead combinations `docs/COMPATIBILITY.md` documents — a
  `2764` on a Fire 24, a `28C16` on a Fire 28 — are accepted where they were
  previously refused as "not supported by this board". Building for v0.6.x is
  unchanged, and a rejection lists what that firmware does serve.
  - **Breaking: `--allow-unsupported-chip-type` is removed** from `program` and
    `firmware build`. It only ever bypassed the old per-board list; nothing it
    can now permit is buildable.

- **Breaking: the CLI's argument conventions are now consistent across every
  command.** No command takes a positional argument — `board header` and
  `board socket` take `--board`, where the error for omitting it already told
  you to. Each short flag means one thing CLI-wide: `-b` is `--board` (was
  `--byte` on `poke`), `-o` is `--output` (was `--offset` on `control erase`),
  `-i` is `--input` (was the global `--vid-pid`, which keeps `--id`), `-l` is
  `--length` (was `--slot`), and `-m` is `--msd` (was `--image` on
  `update slot`). `--board`, `--chip-type`, `--all`, `--force`, `--no-reboot`,
  `--input` and `--output` gain their short forms on the commands that lacked
  them. Enforced by tests that walk the whole command tree.
- **Breaking: `onerom control erase` uses `--stopped`/`--running`** for its
  post-erase reboot mode, matching `control reboot` and `program`. As with
  `onerom boards`, there is deliberately no alias for the old
  `--reboot-stopped`/`--reboot-running`.
- `--config` is now the primary spelling of the ROM configuration file option
  on `program` and `firmware build`, matching how it is written throughout the
  documentation; `--config-file`, `--config-json` and `--json` remain aliases.
- `onerom image convert` validates `--from`/`--to` as the command line is
  parsed and lists the accepted formats in `--help`, rather than failing
  part-way through a conversion. The list comes from `onerom-gen`, so a format
  added there needs no CLI change. `--load-address` is likewise parsed up
  front, by the same code the config file uses, so `$E000` and a bad value
  behave identically in both places.
- `--slot` keys and values are documented kebab-case — `size-handling`,
  `load-address`, `force-16-bit`, `cs1=active-low` — matching the CLI's own
  argument naming. The snake_case config spellings are all still accepted, and
  `size-handling`, the one key that took only the snake form, now parses.
- **`--slot` accepts `cs<n>=ignore`**, which a config file always could.
  Chip-select values now go through the same `onerom-gen` parser the config
  file uses, replacing a second, narrower copy in the CLI — between them
  `active_low` was accepted only on the command line and `ignore` only in a
  config file, and neither took the full set. `ignore` says One ROM does not
  monitor the line; whether a chip may use it is still settled by
  `allow_cs_ignore`, so a 2332 asking for it now gets that rule explained
  rather than "invalid CS logic".
- `--serial-override` now has help text and a `<SERIAL>` value name; it shipped
  with neither, from a `//` comment where clap needs `///`.
- **Breaking: `onerom boards` is now `onerom board`**, and the bare listing it
  printed is `onerom board list`. There is no alias, so scripts calling
  `onerom boards` must be updated; the CLI suggests `board` rather than simply
  failing.
- **Ice (STM32) boards are listed separately and rejected where the CLI cannot
  use them.** The CLI has never had an STM32 path — every firmware path
  composes an RP2350 image and every device path speaks picoboot — but the
  merged list implied otherwise, and `--board ice-24-d` failed several layers
  down as a missing release. `scan`, `program`, `firmware build`,
  `firmware download`, `firmware inspect --board`, `control pin`,
  `control reset` and `inspect gpio` now reject an Ice `--board` up front. The
  commands that only *describe* hardware still take them: `board header`,
  `board socket`, `chips` and `firmware releases`.
- **Add GPIO control**: `onerom control pin` drives a One ROM GPIO high, low or
  high-impedance, `onerom control reset` pulses one low to reset the host
  system One ROM is installed in, and `onerom inspect gpio` shows what every
  GPIO is and what One ROM is doing with it. All three need a *running* device
  with the USB system plugin, and say so.
  - `control pin --hold <MS>` holds the state for a bounded period and then
    applies `--then` (`z` by default); without `--hold` the state latches. The
    **device** times the hold, so an interrupted CLI cannot leave a pin
    latched. `control reset` is that with `--state low --then z` and `--hold`
    defaulting to 100ms; it never drives the line high, and rejects `--hold 0`.
  - `--pin` takes `gpio<N>` or a header pad name — `sel_a` to `sel_e` (`sel-a`
    and `sela` accepted) and `x1`/`x2`. A bare number is rejected as ambiguous,
    as are the broken-out address pads (`a<N>`), with a reason. `--state` and
    `--then` accept `1`/`0` alongside `high`/`low`.
  - A GPIO One ROM is itself using is refused, naming what it is doing, unless
    `--force`, which prints what forcing costs: a pin serving *reads* goes back
    with `--state z`, a pin serving *drives* leaves serving broken until
    reboot. A GPIO that is not 5V-tolerant warns, which `--yes` or `--force`
    answers.
  - `control pin`, `control reset` and `inspect gpio` take `--board`, needed
    only to resolve a `--pin` pad name on a board this build does not
    recognise.

  Requires One ROM firmware v0.7.1 or later and the v0.7.1 or later USB system
  plugin; against anything older the CLI says which of the two is too old
  rather than surfacing a USB stall.

- **Add ASCII views of a board's physical pin layouts.** `onerom board header
  [--board <board>]` draws the pin (jumper / programming) header, annotating each
  image-select and X pad with the GPIO behind it and — on Fire boards —
  whether that GPIO is 5V-tolerant (`5V`) or 3.3V-only (`!!3V3!!`, an ADC pin).
  `onerom board socket [--board <board>] [--chip-type <chip>] [--gpio]` draws the ROM
  socket as a DIP pinout: GPIOs by default, ROM pin functions with
  `--chip-type`, and both with `--gpio`. A chip whose pin count differs from
  the board's is drawn at the larger of the two, bottom-justified, marking
  `overhang` and `(empty)` pins and the `X1`/`X2` fly-lead each overhanging
  address line needs. The board is inferred from a connected One ROM when
  omitted; `onerom inspect header` and `onerom inspect socket` are the
  device-side forms, and take `--board` to override the board type the
  connected One ROM reports.
- **`onerom chips --board <board>` now reports how much flash each chip type
  uses.** Each chip is listed with its ROM size and its image size — often
  larger than the chip (a 2364 costs 8KB on a 24-pin board but 256KB
  overhanging a 28-pin one) — grouped by socket fit, matching
  `docs/COMPATIBILITY.md`. `--chip-type <chip>` (`-c`) answers for one type,
  and `board socket --chip-type` / `inspect socket --chip-type` report the same
  figure below the pinout. The listing now covers every chip the board can
  emulate, including the overhang and fly-lead combinations the name-only list
  omitted; a recognised type the board cannot serve is named in a trailing line
  instead. Ice boards keep the plain name list.
  - The Fit column is now legended, and the fit for a chip in a larger socket
    needing no signal wiring reads `larger socket (no fly-leads)` rather than
    `no fly-leads required`, which sat under a `(with fly-leads)` heading and
    read as a contradiction.
- **ROM images can be rearranged during a build**, via a new `transform=` key
  on `--slot`: `swap_bytes` reverses the byte order within each 16-bit word,
  and `deinterleave:<offset>/<stride>[/<bytes>]` extracts one lane from an
  interleaved image. Several may be combined with `+` and are applied in the
  order given, which matters. The same is expressible as a `"transform"` array
  in a config file. Previously the only option was `onerom image swap-bytes`,
  which rewrites the source file.
- **Add `onerom image deinterleave`** — the standalone counterpart to
  `onerom image swap-bytes` (`--offset`, `--stride`, `--bytes`). Both share
  their implementation with the `transform=` slot key. Neither reads Intel HEX;
  run `onerom image convert` first.
- Add `onerom image convert --from <fmt> --to <fmt> --input <file> --output
  <file> [--load-address <addr>]`, converting ROM images between `binary` and
  `ihex` (Intel HEX). The format set is designed to accept further formats
  later.
- Add `format` and `load_address` keys to `--slot` for Intel HEX ROM images:
  `--slot file=rom.hex,type=2364,cs1=active_low,format=ihex[,load_address=$E000]`.
  `format` accepts `binary` (default) or `ihex`; `load_address` (only valid
  with `format=ihex`) is a decimal or `0x`/`$`-prefixed address mapping to byte
  0 of the ROM. The same keys are available in config files.
- Add `--serial-override`, setting a custom USB serial number used while One
  ROM is running. A stopped One ROM continues to use its chip ID.
- Allow `--plugin` to be combined with `--config-file` on `program` and
  `firmware build`; the plugins are inserted ahead of the config's ROM slots.
  Errors if the config already defines a plugin of its own.
- Turbo boot with more than one non-plugin ROM slot is now accepted under
  `--force` rather than refused outright, for a first slot holding a bootloader
  that selects the others itself. `--force` now covers config warnings as well
  as firmware parse errors and a board type mismatch.
- The ROM type is now stored in metadata using the exact spelling the user
  entered, on both the `--config-file` (`"type"`) and `--slot type=...` paths,
  instead of a canonicalised name (`27SF512` is retained rather than normalised
  to `27512`). The resolved type still drives all behaviour.
- `onerom scan --list-boards` now prints the same listing as `onerom board
  list` rather than its own one-liner.
- `onerom inspect gpio` now shows one `Function` column instead of separate
  `Pad` and `Function` columns, listing everything the GPIO is: its ROM socket
  signal under the image being served, then the board peripheral, then the
  header pad, deduplicated.
  - This **fixes a real omission**: the lookup stopped at the first system
    function it matched, so on a `fire-24-f` — where the Status LED and the RGB
    LED are both GPIO 29 — the table named only the Status LED.
  - `Function` no longer claims a GPIO is `SWCLK` or `SWDIO`. Those are
    dedicated RP2350 pins with no GPIO of their own; the `SEL_C`/`SEL_D` pads
    merely share their nets. `onerom inspect header` remains the pad-indexed
    view.
- `onerom inspect gpio` now lists only the GPIOs connected to something, saying
  how many were omitted; `--all` lists every GPIO. The `X1`/`X2` and
  image-select pads always appear, being what the table is read to find.
- The explanatory legend under the `inspect gpio` table is now shown only with
  `--verbose`.
- `board socket` and `inspect socket` now say when a board has no GPIO map,
  instead of drawing the diagram with the GPIO column blank all the way down.
  The `--chip-type` function view is unaffected, being drawn from the chip's
  pinout rather than the socket map.
- `board header` and `inspect header` now say `command unsupported` for a board
  with no pin-header descriptor, where they said `nothing to draw` and called
  the descriptor missing "yet".
- `onerom inspect header` and `onerom inspect socket` now take `--board`,
  overriding the board type the connected One ROM reports, as `inspect gpio`
  already did. It is an override, not a substitute for the device — both still
  need a One ROM connected, and `onerom board header`/`board socket` remain the
  way to draw a board by name without one.
  - Their "cannot determine the board type" error now advises `--board`, which
    resolves it. The error only arises with a One ROM connected whose board type
    this build does not recognise, so the previous advice to connect one was
    unreachable.
- Stop hard-wrapping prose in console output. A handful of messages broke a
  sentence at a fixed width, which the terminal then wrapped again at its own.
  Multi-line messages that put a *separate* sentence on its own indented line
  are unchanged; that is structure, not wrapping.
- Fix `onerom image swap-bytes` panicking at startup (even for `--help`) with a
  clap short-option collision: `-i` was claimed by both the global `--vid-pid`
  and swap-bytes' `--input`. `-i` now belongs to `--input` throughout, and
  `--vid-pid` is long-only (alias `--id` unchanged).
- New `Error` variants: `ImageTransform`, `IceBoardUnsupported`,
  `TurboBootMultiSlot`, and the GPIO control errors (device not running, pin
  in use, no free hold slot).
- `--disable-swd` now takes effect on the device: SWD stays up for the whole of
  boot and is shut off just before serving. It may now be combined with
  `--logging`, previously rejected, and logging stops when SWD does. Its help
  text now says what it does and does not do.
- Fix `firmware build` accepting `--swd_disabled` where `program` accepted
  `--swd_disable`, so each underscore spelling worked on only one subcommand.
  `--disable-swd` and `--swd-disable` are unchanged and work on both.

## v0.2.0 - 2026-07-20

- Support firmware v0.7.x
- Move plugin handling to onerom-app crate.

## v0.1.11 - 2026-07-12

- Prevent program command from allowing --plugin and --firmware simultanesouly (as ---plugins is ignored anyway).

## v0.1.10 - 2026-07-02

- Added more help on size handling when programming or building firmware.

## v0.1.9 - 2026-06-02

- New 28 and 32 pin boards - fire-28-c and fire-32-b.

## v0.1.8 - 2026-05-26

- Re-added 23QL384.
- Add `onerom chips` to show supported chip types and their aliases.
- Fixed `onerom program --scan-slots`, to correctly re-query One ROM after programming.
- More ROM type aliases.
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

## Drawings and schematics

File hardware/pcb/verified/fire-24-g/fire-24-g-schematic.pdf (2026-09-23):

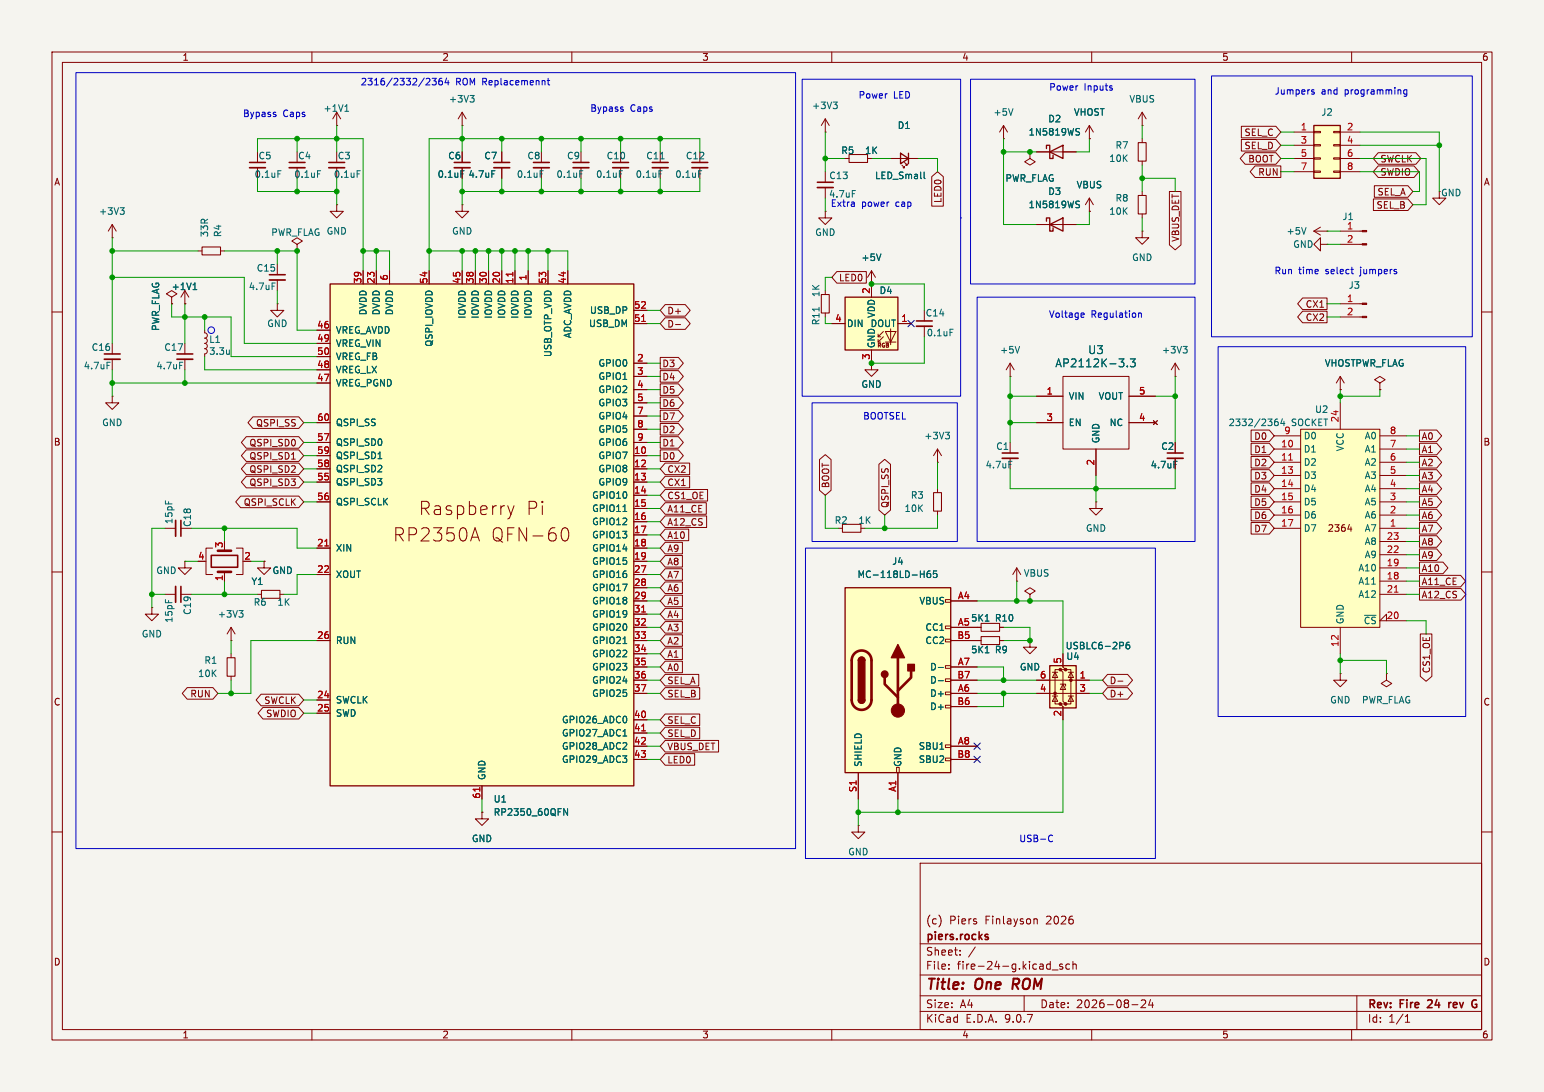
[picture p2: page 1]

6 QSPI_IOVDD 54 IOVDD 45 IOVDD 38 GND 61 IOVDD 30 IOVDD 20 IOVDD 11 IOVDD

File: fire-24-g.kicad_sch Sheet: / piers.rocks

Id: 1/1 Title: One ROM

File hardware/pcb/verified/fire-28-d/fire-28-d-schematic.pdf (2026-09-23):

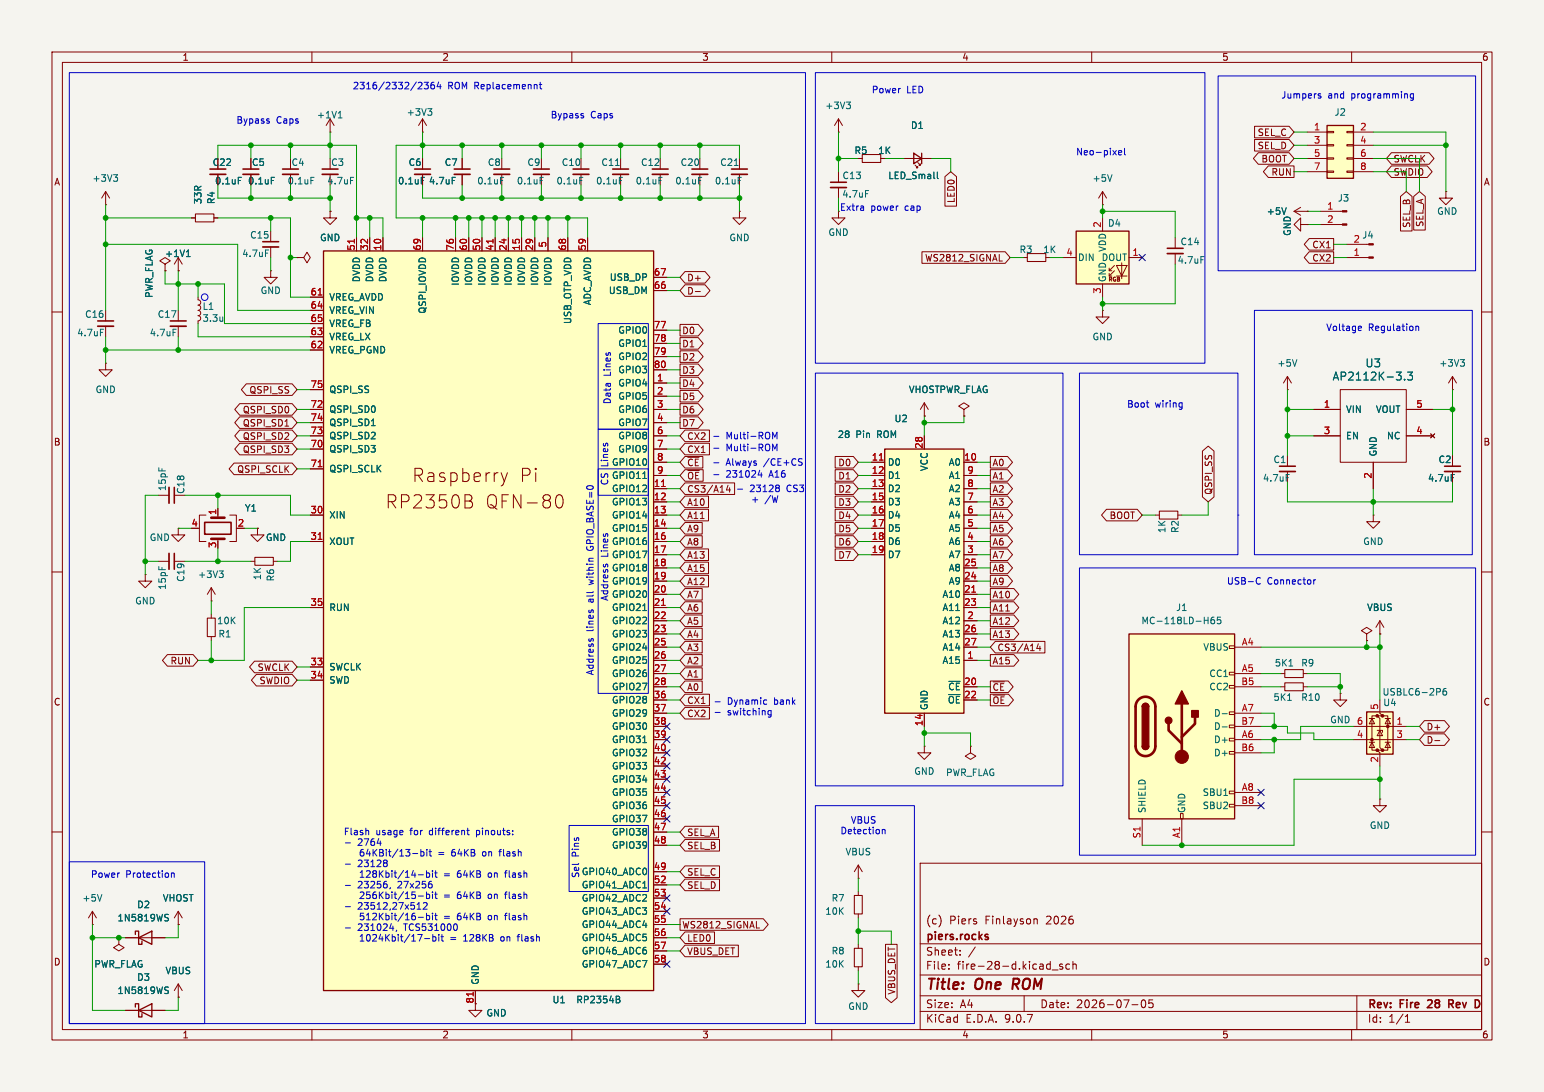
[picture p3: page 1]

Jumpers and programming Sel Pins

2 GND
A0 10 A1 9 A2 8 A3 7 A4 6 A5 5 A6 4 A7 3 A8 25 A9 24 A10 21 A11 23 A12 2 A13 26 A14 27 A15 1 ~{CE} 20 ~{OE} 22 VCC 28 GND 14 D0 11 D1 12 D2 13 D3 15 D4 16 D5 17 D6 18 D7 19 U2

J1 MC-118LD-H65 GND Raspberry Pi

File: fire-28-d.kicad_sch Sheet: / piers.rocks

Id: 1/1 Title: One ROM

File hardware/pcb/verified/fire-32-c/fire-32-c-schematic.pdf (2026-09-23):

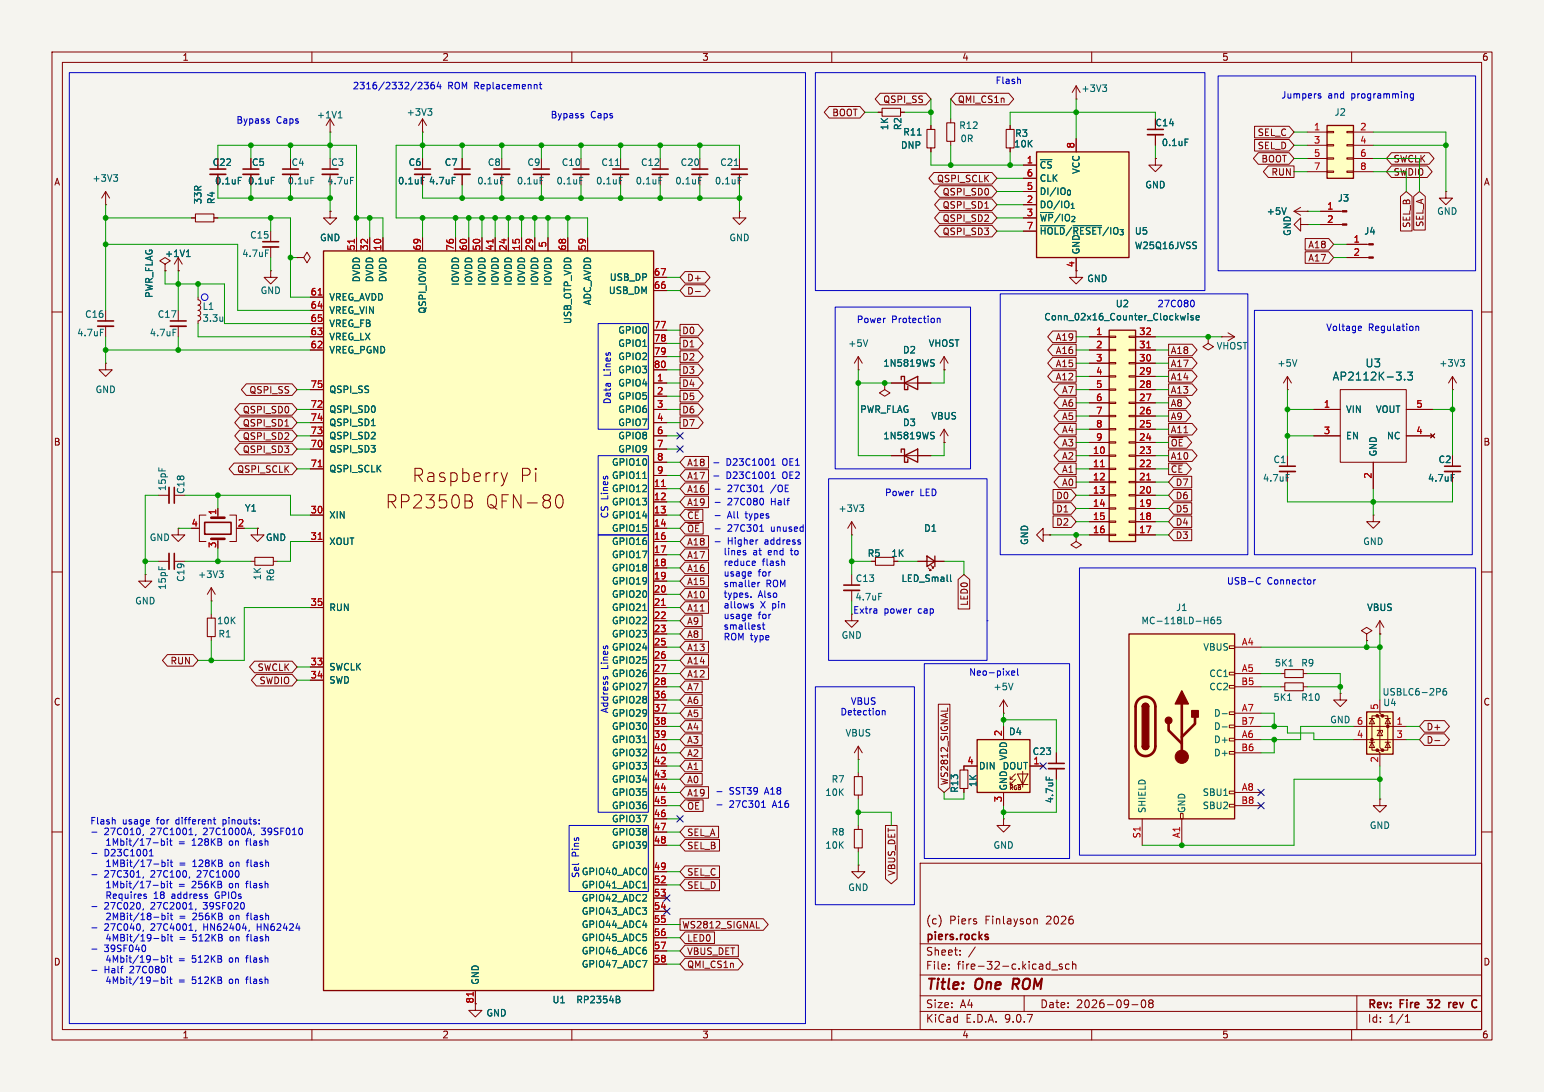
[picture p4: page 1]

Voltage Regulation Sel Pins

- Higher address
lines at end to
reduce flash

types. Also
allows X pin
usage for smallest ROM type

File: fire-32-c.kicad_sch Sheet: / piers.rocks

Id: 1/1 Title: One ROM

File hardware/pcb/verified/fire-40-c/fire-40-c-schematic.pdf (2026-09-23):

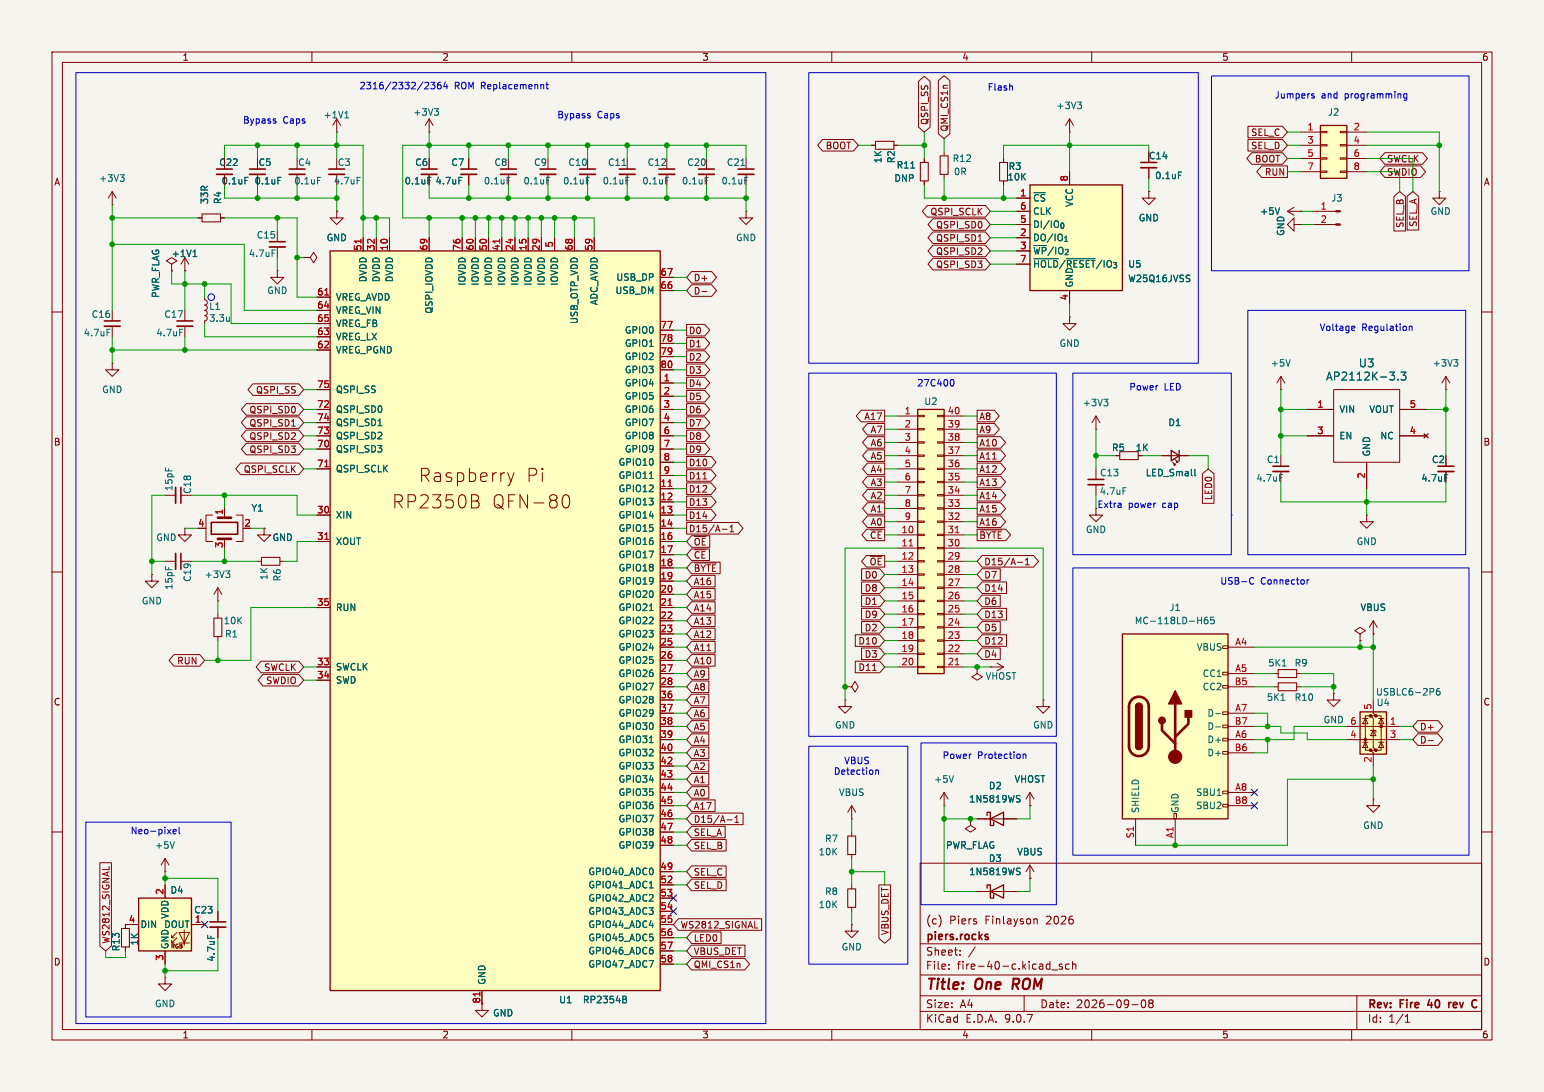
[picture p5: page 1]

File: fire-40-c.kicad_sch Sheet: / piers.rocks

Id: 1/1 Title: One ROM

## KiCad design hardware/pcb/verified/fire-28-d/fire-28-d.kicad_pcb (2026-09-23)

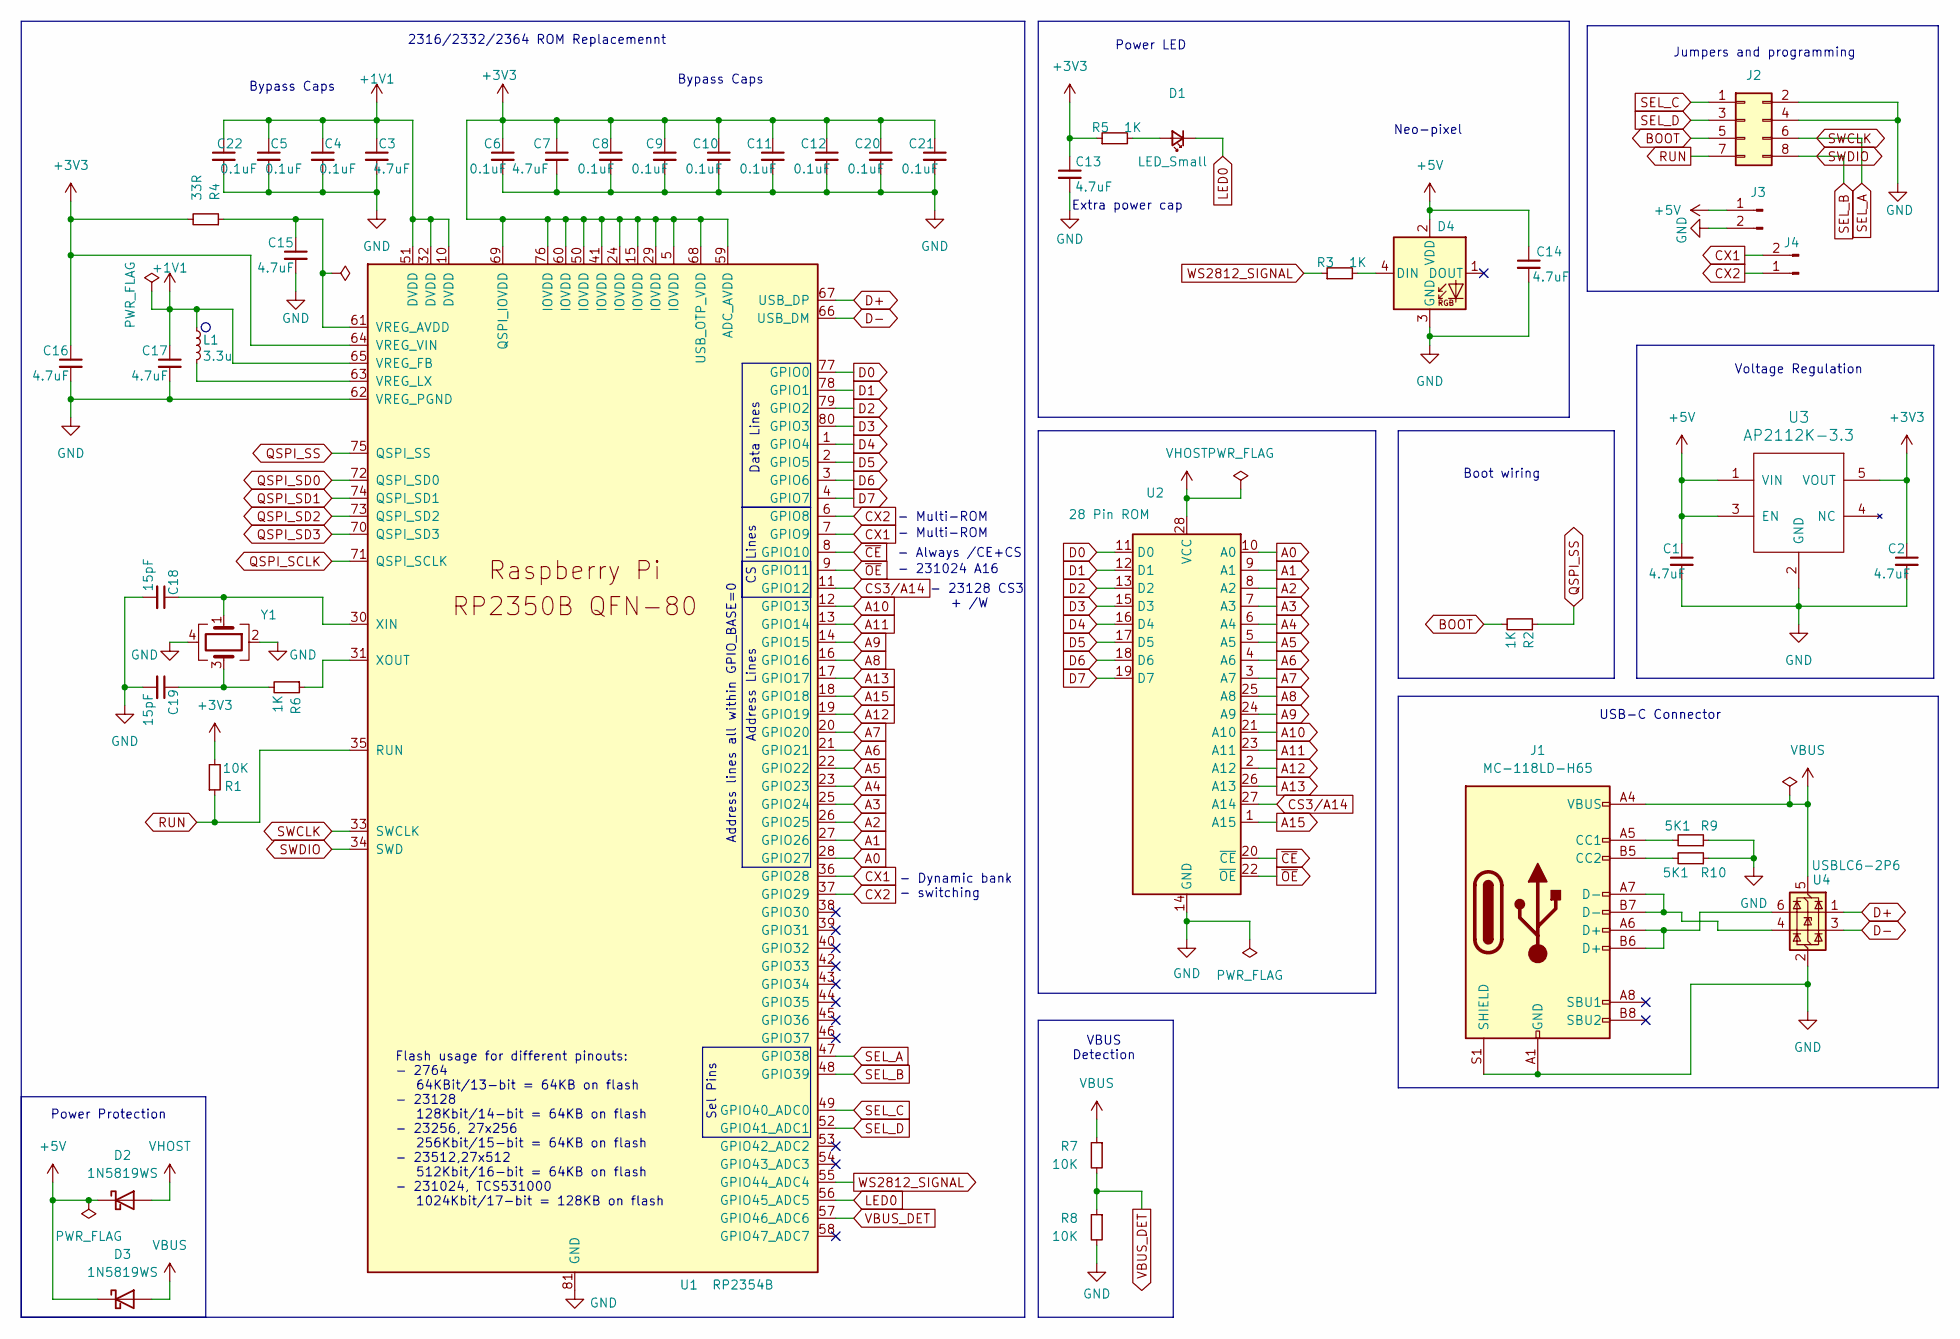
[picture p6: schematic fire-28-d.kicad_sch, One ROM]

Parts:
C1, C2, C3, C7, C13, C14, C15: 4.7uF; C_0402_1005Metric; LCSC C23733
C4, C5, C6, C8, C9, C10, C11, C12, C20, C21, C22: 0.1uF; C_0402_1005Metric; LCSC C1525
C16, C17: 4.7uF; C_0402_1005Metric_small_pads; LCSC C23733
C18, C19: 15pF; C_0402_1005Metric; LCSC C1548
D1: LED_Small; LED_0402_1005Metric; LCSC C25503345
D2, D3: 1N5819WS; D_SOD-323; LCSC C191023
D4: XL-1010RGBC-WS2812B; XL-1010RGBC-2812B; LCSC C5349953
J1: MC-118LD-H65; USB-C-upright-C6332304-hanbo-MC-118LD-H65; LCSC C6332304
J2: Conn_02x04_Odd_Even; PinHeader_2x04_P2.54mm_Vertical custom silkscreen
J3, J4: Conn_01x02_Pin; PinHeader_1x02_P2.54mm_Vertical
L1: 3.3u; L_pol_2016; LCSC C42411119
R1, R7, R8: 10K; R_0402_1005Metric; LCSC C25744
R2, R3, R5, R6: 1K; R_0402_1005Metric; LCSC C11702
R4: 33R; R_0402_1005Metric; LCSC C25105
R9, R10: 5K1; R_0402_1005Metric; LCSC C25905
U1: RP2354B; RP2350-QFN-80-1EP_10x10_P0.4mm_EP3.4x3.4mm_ThermalVias; LCSC C39843328
U2: 28 Pin ROM; 28 pin rom footprint
U3: AP2112K-3.3; SOT-23-5; LCSC C51118
U4: USBLC6-2P6; SOT-666; LCSC C15999
Y1: Crystal_GND24; Crystal_SMD_Abracon_ABM8G-4Pin_3.2x2.5mm; LCSC C20625731

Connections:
+1V1: C3.1, C4.1, C5.1, C17.1, C22.1, L1.1, U1.10 (DVDD), U1.32 (DVDD), U1.51 (DVDD), U1.65 (VREG_FB)
+3V3: C2.1, C6.1, C7.1, C8.1, C9.1, C10.1, C11.1, C12.1, C13.1, C16.1, C20.1, C21.1, R1.2, R4.2, R5.1, U1.5 (IOVDD), U1.15 (IOVDD), U1.24 (IOVDD), U1.29 (IOVDD), U1.41 (IOVDD), U1.50 (IOVDD), U1.59 (ADC_AVDD), U1.60 (IOVDD), U1.64 (VREG_VIN), U1.68 (USB_OTP_VDD), U1.69 (QSPI_IOVDD), U1.76 (IOVDD), U3.5 (VOUT)
+5V: C1.1, C14.1, D2.1 (K), D3.1 (K), D4.2 (VDD), J3.1, U3.1 (VIN), U3.3 (EN)
A0: U1.28 (GPIO27), U2.10 (A0)
A1: U1.27 (GPIO26), U2.9 (A1)
A2: U1.26 (GPIO25), U2.8 (A2)
A3: U1.25 (GPIO24), U2.7 (A3)
A4: U1.23 (GPIO23), U2.6 (A4)
A5: U1.22 (GPIO22), U2.5 (A5)
A6: U1.21 (GPIO21), U2.4 (A6)
A7: U1.20 (GPIO20), U2.3 (A7)
A8: U1.16 (GPIO16), U2.25 (A8)
A9: U1.14 (GPIO15), U2.24 (A9)
A10: U1.12 (GPIO13), U2.21 (A10)
A11: U1.13 (GPIO14), U2.23 (A11)
A12: U1.19 (GPIO19), U2.2 (A12)
A13: U1.17 (GPIO17), U2.26 (A13)
A15: U1.18 (GPIO18), U2.1 (A15)
BOOT: J2.5, R2.2
CS3/A14: U1.11 (GPIO12), U2.27 (A14)
CX1: J4.2, U1.7 (GPIO9), U1.36 (GPIO28)
CX2: J4.1, U1.6 (GPIO8), U1.37 (GPIO29)
D0: U1.77 (GPIO0), U2.11 (D0)
D1: U1.78 (GPIO1), U2.12 (D1)
D2: U1.79 (GPIO2), U2.13 (D2)
D3: U1.80 (GPIO3), U2.15 (D3)
D4: U1.1 (GPIO4), U2.16 (D4)
D5: U1.2 (GPIO5), U2.17 (D5)
D6: U1.3 (GPIO6), U2.18 (D6)
D7: U1.4 (GPIO7), U2.19 (D7)
D+: U1.67 (USB_DP), U4.1 (I/O1)
D-: U1.66 (USB_DM), U4.3 (I/O2)
GND: C1.2, C2.2, C3.2, C4.2, C5.2, C6.2, C7.2, C8.2, C9.2, C10.2, C11.2, C12.2, C13.2, C14.2, C15.2, C16.2, C17.2, C18.2, C19.2, C20.2, C21.2, C22.2, D4.3 (GND), J1.A1 (GND), J1.A12 (GND), J1.B1 (GND), J1.B12 (GND), J1.S1 (SHIELD), J2.2, J2.4, J3.2, R8.2, R9.1, R10.1, U1.62 (VREG_PGND), U1.81 (GND), U2.14 (GND), U3.2 (GND), U4.2 (GND), Y1.2, Y1.4
LED0: D1.1 (K), U1.56 (GPIO45_ADC5)
unnamed: C19.1, R6.2, Y1.3
unnamed: D1.2 (A), R5.2
unnamed: D4.4 (DIN), R3.2
unnamed: J1.A5 (CC1), R9.2
unnamed: J1.B5 (CC2), R10.2
unnamed: J1.A6 (D+), J1.B6 (D+), U4.6 (I/O1)
unnamed: J1.A7 (D-), J1.B7 (D-), U4.4 (I/O2)
unnamed: C15.1, R4.1, U1.61 (VREG_AVDD)
unnamed: L1.2, U1.63 (VREG_LX)
unnamed: C18.1, U1.30 (XIN), Y1.1
unnamed: R6.1, U1.31 (XOUT)
QSPI_SCLK: U1.71 (QSPI_SCLK)
QSPI_SD0: U1.72 (QSPI_SD0)
QSPI_SD1: U1.74 (QSPI_SD1)
QSPI_SD2: U1.73 (QSPI_SD2)
QSPI_SD3: U1.70 (QSPI_SD3)
QSPI_SS: R2.1, U1.75 (QSPI_SS)
RUN: J2.7, R1.1, U1.35 (RUN)
SEL_A: J2.6, U1.33 (SWCLK), U1.47 (GPIO38)
SEL_B: J2.8, U1.34 (SWD), U1.48 (GPIO39)
SEL_C: J2.1, U1.49 (GPIO40_ADC0)
SEL_D: J2.3, U1.52 (GPIO41_ADC1)
VBUS: D3.2 (A), J1.A4 (VBUS), J1.A9 (VBUS), J1.B4 (VBUS), J1.B9 (VBUS), R7.1, U4.5 (VBUS)
VBUS_DET: R7.2, R8.1, U1.57 (GPIO46_ADC6)
VHOST: D2.2 (A), U2.28 (VCC)
WS2812_SIGNAL: R3.1, U1.55 (GPIO44_ADC4)
~CE: U1.8 (GPIO10), U2.20 (~CE)
~OE: U1.9 (GPIO11), U2.22 (~OE)

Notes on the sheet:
- Multi-ROM
Data Lines
USB-C Connector
Address lines all within GPIO_BASE=0
Voltage Regulation
- Dynamic bank - switching
Extra power cap
Neo-pixel
CS Lines
2316/2332/2364 ROM Replacemennt
Bypass Caps
Power LED
- 23128 CS3 + /W
Power Protection
- 231024 A16
Address Lines
Boot wiring
Sel Pins
VBUS Detection
- Always /CE+CS
Flash usage for different pinouts: - 2764 64KBit/13-bit = 64KB on flash - 23128 128Kbit/14-bit = 64KB on flash - 23256, 27x256 256Kbit/15-bit = 64KB on flash - 23512,27x512 512Kbit/16-bit = 64KB on flash - 231024, TCS531000 1024Kbit/17-bit = 128KB on flash
Jumpers and programming

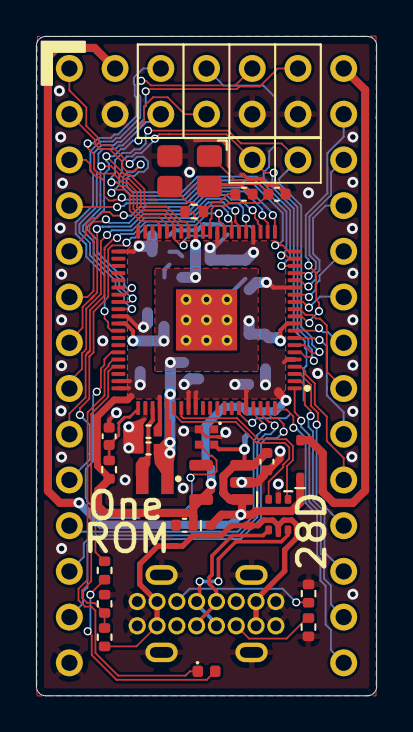
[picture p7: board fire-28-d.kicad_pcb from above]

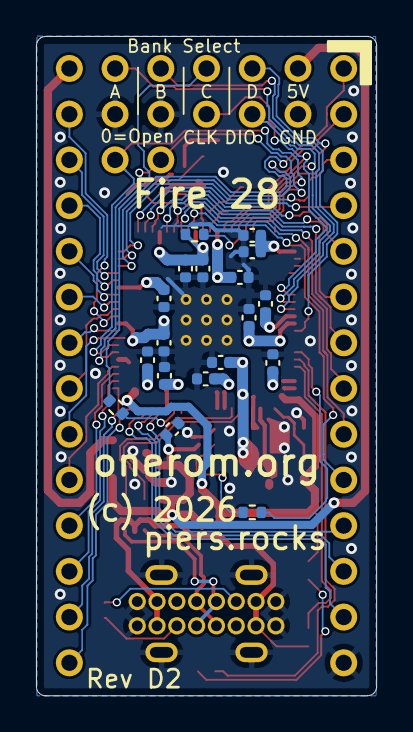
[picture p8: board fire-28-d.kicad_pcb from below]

Board: 2 copper layers, 18.9 x 36.6 mm, 46 parts (18 on the bottom side), 57 nets.

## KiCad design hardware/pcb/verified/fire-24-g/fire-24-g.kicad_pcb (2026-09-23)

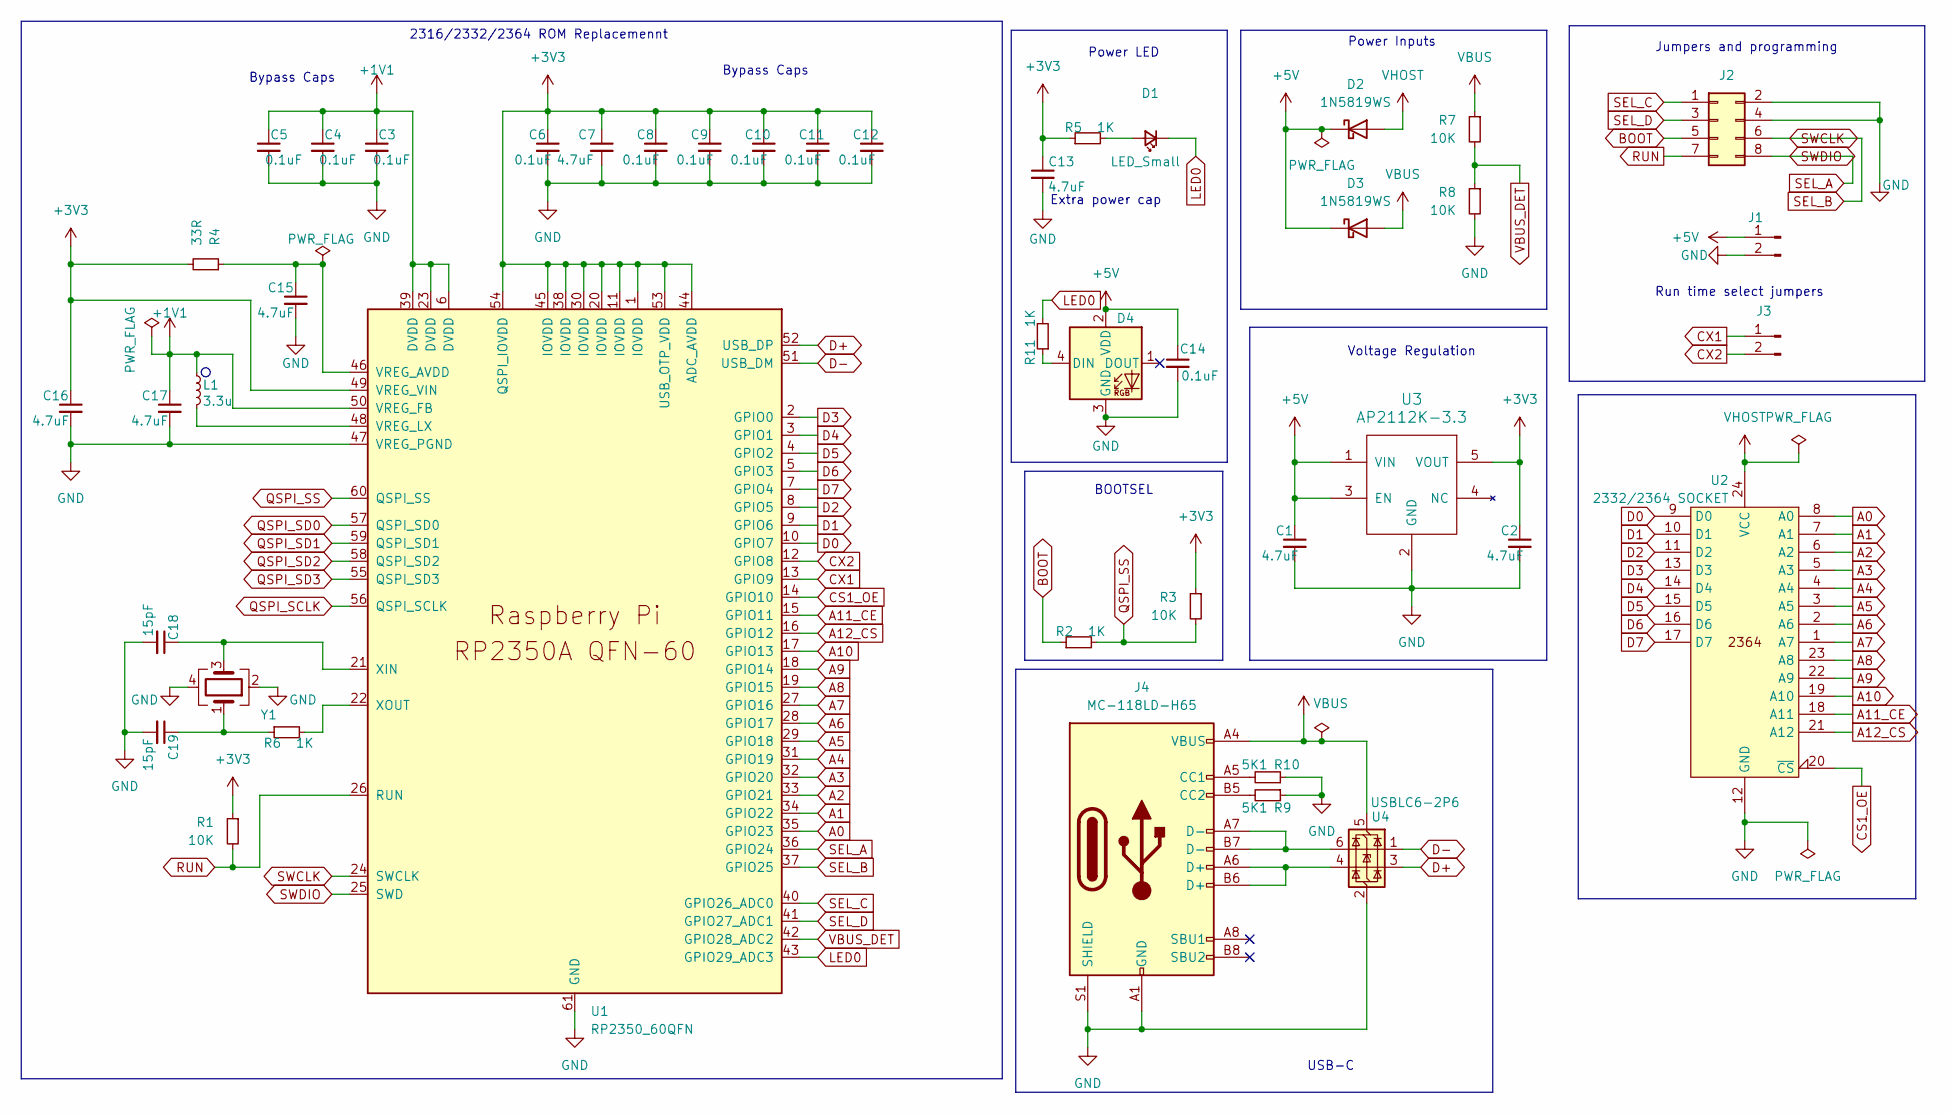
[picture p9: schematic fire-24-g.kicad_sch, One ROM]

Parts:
C1, C2, C7, C13, C15: 4.7uF; C_0402_1005Metric; LCSC C23733
C3, C4, C5, C6, C8, C9, C10, C11, C12, C14: 0.1uF; C_0201_0603Metric; LCSC C668346
C16, C17: 4.7uF; C_0402_1005Metric_small_pads; LCSC C23733
C18, C19: 15pF; C_0201_0603Metric; LCSC C85891
D1: LED_Small; LED_0402_1005Metric; LCSC C25503345
D2, D3: 1N5819WS; D_SOD-323; LCSC C191023
D4: XL-1010RGBC-WS2812B; XL-1010RGBC-2812B; LCSC C5349953
J1, J3: Conn_01x02_Pin; PinHeader_1x02_P2.54mm_Vertical
J2: Conn_02x04_Odd_Even; PinHeader_2x04_P2.54mm_Vertical custom silkscreen
J4: MC-118LD-H65; USB-C-upright-C6332304-hanbo-MC-118LD-H65; LCSC C6332304
L1: 3.3u; L_pol_2016; LCSC C42411119
R1, R3, R7, R8: 10K; R_0201_0603Metric; LCSC C473048
R2, R5, R6, R11: 1K; R_0201_0603Metric; LCSC C270365
R4: 33R; R_0402_1005Metric; LCSC C25105
R9, R10: 5K1; R_0201_0603Metric; LCSC C270344
U1: RP2350_60QFN; RP2350-QFN-60-1EP_7x7_P0.4mm_EP3.4x3.4mm_ThermalVias; LCSC C41378174
U2: 2332/2364 SOCKET; 2x12 dip pin output 600mil centres no ss
U3: AP2112K-3.3; SOT-23-5; LCSC C51118
U4: USBLC6-2P6; SOT-666; LCSC C15999
Y1: Crystal_GND24; Crystal_SMD_Abracon_ABM8G-4Pin_3.2x2.5mm; LCSC C20625731

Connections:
+1V1: C3.1, C4.1, C5.1, C17.1, L1.1, U1.6 (DVDD), U1.23 (DVDD), U1.39 (DVDD), U1.50 (VREG_FB)
+3V3: C2.1, C6.1, C7.1, C8.1, C9.1, C10.1, C11.1, C12.1, C13.1, C16.1, R1.1, R3.1, R4.2, R5.1, U1.1 (IOVDD), U1.11 (IOVDD), U1.20 (IOVDD), U1.30 (IOVDD), U1.38 (IOVDD), U1.44 (ADC_AVDD), U1.45 (IOVDD), U1.49 (VREG_VIN), U1.53 (USB_OTP_VDD), U1.54 (QSPI_IOVDD), U3.5 (VOUT)
+5V: C1.1, C14.1, D2.1 (K), D3.1 (K), D4.2 (VDD), J1.1, U3.1 (VIN), U3.3 (EN)
A0: U1.35 (GPIO23), U2.8 (A0)
A1: U1.34 (GPIO22), U2.7 (A1)
A2: U1.33 (GPIO21), U2.6 (A2)
A3: U1.32 (GPIO20), U2.5 (A3)
A4: U1.31 (GPIO19), U2.4 (A4)
A5: U1.29 (GPIO18), U2.3 (A5)
A6: U1.28 (GPIO17), U2.2 (A6)
A7: U1.27 (GPIO16), U2.1 (A7)
A8: U1.19 (GPIO15), U2.23 (A8)
A9: U1.18 (GPIO14), U2.22 (A9)
A10: U1.17 (GPIO13), U2.19 (A10)
A11_CE: U1.15 (GPIO11), U2.18 (A11)
A12_CS: U1.16 (GPIO12), U2.21 (A12)
BOOT: J2.5, R2.1
CS1_OE: U1.14 (GPIO10), U2.20 (~CS)
CX1: J3.1, U1.13 (GPIO9)
CX2: J3.2, U1.12 (GPIO8)
D0: U1.10 (GPIO7), U2.9 (D0)
D1: U1.9 (GPIO6), U2.10 (D1)
D2: U1.8 (GPIO5), U2.11 (D2)
D3: U1.2 (GPIO0), U2.13 (D3)
D4: U1.3 (GPIO1), U2.14 (D4)
D5: U1.4 (GPIO2), U2.15 (D5)
D6: U1.5 (GPIO3), U2.16 (D6)
D7: U1.7 (GPIO4), U2.17 (D7)
D+: U1.52 (USB_DP), U4.3 (I/O2)
D-: U1.51 (USB_DM), U4.1 (I/O1)
GND: C1.2, C2.2, C3.2, C4.2, C5.2, C6.2, C7.2, C8.2, C9.2, C10.2, C11.2, C12.2, C13.2, C14.2, C15.2, C16.2, C17.2, C18.2, C19.2, D4.3 (GND), J1.2, J2.2, J2.4, J4.A1 (GND), J4.A12 (GND), J4.B1 (GND), J4.B12 (GND), J4.S1 (SHIELD), R8.2, R9.1, R10.1, U1.47 (VREG_PGND), U1.61 (GND), U2.12 (GND), U3.2 (GND), U4.2 (GND), Y1.2, Y1.4
LED0: D1.1 (K), R11.2, U1.43 (GPIO29_ADC3)
unnamed: C19.1, R6.1, Y1.1
unnamed: D1.2 (A), R5.2
unnamed: D4.4 (DIN), R11.1
unnamed: J4.A5 (CC1), R10.2
unnamed: J4.B5 (CC2), R9.2
unnamed: J4.A6 (D+), J4.B6 (D+), U4.4 (I/O2)
unnamed: J4.A7 (D-), J4.B7 (D-), U4.6 (I/O1)
unnamed: C15.1, R4.1, U1.46 (VREG_AVDD)
unnamed: L1.2, U1.48 (VREG_LX)
unnamed: C18.1, U1.21 (XIN), Y1.3
unnamed: R6.2, U1.22 (XOUT)
QSPI_SCLK: U1.56 (QSPI_SCLK)
QSPI_SD0: U1.57 (QSPI_SD0)
QSPI_SD1: U1.59 (QSPI_SD1)
QSPI_SD2: U1.58 (QSPI_SD2)
QSPI_SD3: U1.55 (QSPI_SD3)
QSPI_SS: R2.2, R3.2, U1.60 (QSPI_SS)
RUN: J2.7, R1.2, U1.26 (RUN)
SEL_A: J2.8, U1.25 (SWD), U1.36 (GPIO24)
SEL_B: J2.6, U1.24 (SWCLK), U1.37 (GPIO25)
SEL_C: J2.1, U1.40 (GPIO26_ADC0)
SEL_D: J2.3, U1.41 (GPIO27_ADC1)
VBUS: D3.2 (A), J4.A4 (VBUS), J4.A9 (VBUS), J4.B4 (VBUS), J4.B9 (VBUS), R7.1, U4.5 (VBUS)
VBUS_DET: R7.2, R8.1, U1.42 (GPIO28_ADC2)
VHOST: D2.2 (A), U2.24 (VCC)

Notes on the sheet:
Run time select jumpers
Voltage Regulation
Power Inputs
USB-C
Extra power cap
2316/2332/2364 ROM Replacemennt
Bypass Caps
Power LED
BOOTSEL
Jumpers and programming

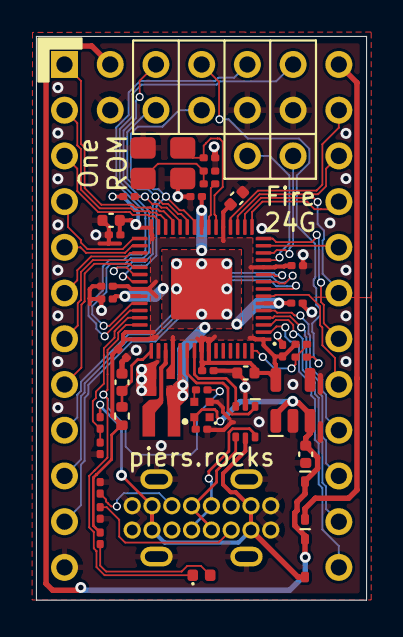
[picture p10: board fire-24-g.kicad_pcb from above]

Board: 2 copper layers, 18.3 x 31.3 mm, 44 parts (0 on the bottom side), 52 nets.

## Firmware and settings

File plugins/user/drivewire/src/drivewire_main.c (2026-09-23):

// Copyright (C) 2026 Piers Finlayson <piers@piers.rocks>
// Copyright (C) 2026 William Athing
//
// MIT License
//
// DriveWire bridge plugin for One ROM.
//
// Bridges a DriveWire session between a CoCo/Dragon disk controller ROM and
// a real DriveWire server, over One ROM's RP2350 UART1 hardware (GPIO40 TX,
// GPIO41 RX - the One ROM Fire 28 Rev C SEL_C/SEL_D pads, which must be left
// unpopulated on this board for those pins to be free - see README) rather
// than the CoCo's own bit-banger serial port.
//
// Signalling rides the ROM address bus, the same idiom the host-control
// (RBCP) plugin uses: reads at addresses whose low byte carries a value are
// how the CPU "sneaks" data out over a bus it can otherwise only read from.
// Two knock sequences pick the session direction (no RBCP-style group/cmd
// byte is needed, since the direction is the only thing to select), followed
// by a 16-bit count N, high byte first (both directions) - matching the
// 0-65535 range dw.h's dwwrite()/dwread() are themselves typed for, so a
// caller can never ask this transport for more than it can carry:
//
//   write session (CoCo -> server): knock, count N, then N further
//   address-encoded reads, forwarded byte for byte to UART1 TX.  Streamed
//   with no buffering, so N's full 16-bit range is always safe here.
//
//   read session (server -> CoCo): knock, count N, capped in practice at
//   sizeof(s_read_buf) - see the main loop's own comment on why a larger N
//   is refused rather than served.  For each of the N bytes,
//   the plugin blocks on UART1 RX, writes the byte to a fixed logical "data"
//   address, then flips a fixed logical "status" address to a ready sentinel.
//   The CoCo spin-reads status until ready, then reads data to collect the
//   byte.  The plugin does not prepare the next byte until it observes the
//   CoCo's read of the data address, which is what stops it overwriting a
//   byte the CoCo has not yet collected.
//
// The status/data addresses are ordinary ROM offsets ($C100/$C101 in CPU
// space for this 8K 2764 image) - live hdbdos code, not spare padding.  What
// makes that safe is that reprogramming them is the *only* thing that
// touches served ROM content, and it is fully reversible: the plugin reads
// and caches the real bytes once at startup and restores them the moment
// each read session ends, so outside an active session the image is exactly
// what it was assembled as.  The knock sequences themselves are pure reads
// and never touch served content at all.
//
// This plugin does not support yielding: a pause mid-knock or mid-session
// would be indistinguishable from the CoCo simply pausing, and there is no
// way to resynchronise cleanly, so DriveWire sessions must not be interrupted
// by another plugin's exclusive-mode request.
//
// Build with DRIVEWIRE_TEST_PATTERN defined (make TEST_PATTERN=1) for a
// bring-up test build that skips the real protocol - see drivewire_main().

#include <stdint.h>
#include <stdbool.h>
#include "plugin.h"

#define RP235X
#define MCU_FLASH_SIZE_KB 2048
#define MCU_RAM_SIZE_KB 520
#define RP2350A
#include "onerom_metadata.h"
#include "reg-rp235x.h"
#include "uart-rp235x.h"

// ---------------------------------------------------------------------------
// Plugin header
// ---------------------------------------------------------------------------

void drivewire_main(
    ora_lookup_fn_t ora_lookup_fn,
    ora_plugin_type_t plugin_type,
    const ora_entry_args_t *entry_args
);
ORA_SECTION(".plugin_header")
const ora_plugin_header_t ora_plugin_header = {
    .magic         = ORA_PLUGIN_MAGIC,
    .api_version   = ORA_PLUGIN_VERSION_1,
    .major_version = MAJOR_VERSION,
    .minor_version = MINOR_VERSION,
    .patch_version = PATCH_VERSION,
    .build_version = BUILD_VERSION,
    .entry         = drivewire_main,
    .plugin_type   = ORA_PLUGIN_TYPE_USER,
    .sam_usage     = 255,
    .overrides1    = 0,
    .properties1   = 0,  // does not support yielding - see file header comment
    // 0.7.3 for ora_address_monitor_options_t - see drivewire_main().
    .min_fw_major_version = 0,
    .min_fw_minor_version = 7,
    .min_fw_patch_version = 3,
    .reserved = {0},
};

// ---------------------------------------------------------------------------
// Ring buffer
// ---------------------------------------------------------------------------

#define RING_ENTRIES_LOG2   6u                               // 64 entries
#define RING_DATA_SIZE      32u                               // 32 bits per entry
#define RING_MASK           ((1u << RING_ENTRIES_LOG2) - 1u)
#define RING_BUF_TYPE        uint32_t
_Static_assert(sizeof(RING_BUF_TYPE) * 8 == RING_DATA_SIZE, "RING_BUF_TYPE must match RING_DATA_SIZE");

ORA_SECTION(".ring_buf")
ORA_RING_BUF_DECLARE_32BIT(ring_buf, RING_ENTRIES_LOG2);

#define RING_BUF_CUR_READ_INDEX()   s_read_idx
#define RING_BUF_ADV_READ_INDEX()   s_read_idx = (s_read_idx + 1u) & RING_MASK
#define RING_BUF_CUR_WRITE_INDEX() \
    ((uint32_t)((volatile RING_BUF_TYPE *)*s_write_pos_ptr - \
                (volatile RING_BUF_TYPE *)ring_buf) & RING_MASK)
#define RING_BUF_GET_ENTRY(X) ((volatile RING_BUF_TYPE *)ring_buf)[(X)]

static volatile uint32_t * volatile *s_write_pos_ptr;
static uint32_t            s_read_idx;

// ---------------------------------------------------------------------------
// Knock sequences
// ---------------------------------------------------------------------------

#define KNOCK_LEN 8u
static const uint8_t s_knock_write[KNOCK_LEN] = {'!','D','W','S','E','N','D','!'};  // "!DWSEND!" CoCo -> server
#ifndef DRIVEWIRE_TEST_PATTERN
static const uint8_t s_knock_read[KNOCK_LEN]  = {'!','D','W','R','E','C','V','!'};  // "!DWRECV!" server -> CoCo
// CoCo -> plugin: load and activate a cartridge/ROM image - see
// drivewire_do_load_cart()'s own comment for the full protocol.  Not part of
// DriveWire proper - a One-ROM-specific extension the config app's own
// knock-sending code (not fujinet-lib, not hdbdos) speaks directly.
static const uint8_t s_knock_cart[KNOCK_LEN]  = {'!','L','D','C','A','R','T','!'};  // "!LDCART!"
#endif

// ---------------------------------------------------------------------------
// Protocol constants
// ---------------------------------------------------------------------------

// Logical (chip) byte offsets used as the status/data channel - $C100/$C101
// in this 2764's CPU-visible address space.  Live hdbdos code; see the file
// header comment for why overwriting it here is safe.
#define DW_STATUS_ADDR   0x0100u
#define DW_DATA_ADDR     0x0101u

#define DW_STATUS_PENDING 0x00u
#define DW_STATUS_READY   0xFFu

// A third live ROM byte, deliberately in a different 256-byte page from
// DW_STATUS_ADDR/DW_DATA_ADDR above.  Written to DW_KNOCK_ACK_VALUE the
// instant a write-session or "!LDCART!" knock matches (see
// drivewire_wait_for_knock()), so the CoCo's own bounded poll-and-retry -
// dwonewrite.asm's DWWrite, or a "!LDCART!" caller doing the same thing -
// can tell its knock actually landed and resend, or give up gracefully, if
// it doesn't see this in time.  The read direction's own knock does not get
// this treatment: it has never been observed to go missing, unlike the
// write knock this guards.
//
// This cannot reuse DW_STATUS_ADDR/DW_DATA_ADDR themselves: the count and
// data bytes that follow a knock are sent the same way the knock is - as an
// address whose low byte IS the value, anywhere across the full $C100-$C1FF
// page (a count of 256 wire-encodes as 0, landing on $C100 exactly).  Only a
// full-address comparison against a byte outside that whole page can tell
// "the CoCo is still polling for the ack" apart from "the CoCo is now
// sending a real count/data byte that happens to have this low byte" - the
// same reason drivewire_wait_for_data_read() below compares full addresses,
// not low bytes, against DW_DATA_ADDR.
#define DW_KNOCK_ACK_ADDR  0x0200u
#define DW_KNOCK_ACK_VALUE 0xA5u

#define DW_UART_BASE     UART1_BASE
#define DW_UART_TX_GPIO  40u
#define DW_UART_RX_GPIO  41u
#ifndef DW_UART_BAUD
#define DW_UART_BAUD     921600u
#endif

// Bound on how long drivewire_uart_getc() will wait for a single RX byte -
// see its own comment for why an unbounded wait here can wedge core 1
// permanently.  A fixed iteration count, not derived from s_get_sysclk_mhz():
// getting this exactly right would need scaling by clock speed to keep the
// wall-clock duration constant, but the two failure modes are wildly
// asymmetric - too long merely delays recovery from a genuine non-response,
// while too short risks a spurious abort on a slow-but-working one (e.g.
// FujiNet's SD card access taking a while under wear-levelling GC).  Sized
// generously - tens of millions of iterations, comfortably multiple seconds
// even on an overclocked RP2350 - so it only ever fires when nothing is
// coming rather than shaving margin off any legitimately slow response.
#define DW_UART_GETC_TIMEOUT 300000000ul

typedef enum {
    SESSION_WRITE,
    SESSION_READ,
    SESSION_LOAD_CART,
} session_dir_t;

// Dedicated RAM slot "!LDCART!" loads a cartridge image into - deliberately
// never the currently-active slot (slot 0, hdbonerom.rom in this plugin's
// own build), so the transfer can never corrupt what the CoCo might still
// be executing from, and drivewire_do_load_cart() only ever needs
// allow_active=0 when reprogramming it.  See that function's own comment
// for the full handshake.
#define DW_CART_RAM_SLOT 1u

// ---------------------------------------------------------------------------
// Looked-up API functions
// ---------------------------------------------------------------------------

static ora_log_fn_t                         s_log;
static ora_err_log_fn_t                     s_err_log;
static ora_demangle_addr_fn_t               s_demangle;
static ora_reprogram_ram_rom_slot_fn_t      s_reprogram;
static ora_read_ram_rom_slot_fn_t           s_read_slot;
static ora_get_active_ram_slot_fn_t         s_get_active_slot;
static ora_set_active_ram_slot_fn_t         s_set_active_slot;
static ora_get_ram_slot_info_fn_t           s_get_ram_slot_info;
static ora_get_sysclk_mhz_fn_t              s_get_sysclk_mhz;
static ora_start_address_monitor_fn_t       s_start_monitor;
static ora_get_address_monitor_ring_write_pos_fn_t s_get_write_pos;
static ora_set_status_led_fn_t              s_set_status_led;

// ---------------------------------------------------------------------------
// State
// ---------------------------------------------------------------------------

static uint8_t s_active_slot;
static uint8_t s_orig_status_byte;
static uint8_t s_orig_data_byte;
static uint8_t s_orig_ack_byte;

// Holds a full read session's response, drained from UART1 before any of the
// CoCo handshake starts - see drivewire_do_read().  256 is the protocol's
// maximum single-session count (0 on the wire means 256).
static uint8_t s_read_buf[256];

// How many bytes at the front of s_read_buf were opportunistically drained
// from UART1 by drivewire_next_addr() before drivewire_do_read() was even
// entered - see its own comment.  Reset once a session finishes with it (a
// read session in drivewire_do_read() itself; a write session explicitly, in
// drivewire_wait_for_knock() below, before the next wait starts) so stale
// bytes from one session's window can never bleed into the next.
static uint16_t s_read_buf_filled;

// Main session loop's own state, one level up from drivewire_do_read()'s own
// variables above - these cover write sessions and knock-waiting too, so a
// stall outside drivewire_do_read() entirely (e.g. waiting for whatever
// knock is supposed to follow a just-completed session) is still visible.
// phase: 0=waiting for knock, 1=reading the count bytes, 2=in a write
// session, 3=in a read session, 4=in a "!LDCART!" load, 5=a "!LDCART!" load
// succeeded and this plugin has permanently stopped monitoring the ROM bus
// (see drivewire_do_load_cart()'s own comment) - the terminal phase, since
// nothing after it changes this again short of a power cycle.  session_count
// increments once per detected knock (so once per session of any kind - a
// full sector "block" is several of these: the request, the 256-byte data,
// the 2-byte checksum, and the 1-byte ack, each a separate session).
static volatile uint8_t  s_debug_main_phase;
static volatile uint32_t s_debug_session_count;
// Increments on every single call to drivewire_next_addr(), the most
// fundamental, frequently-hit function in the plugin - a definitive "is
// anything at all still executing" signal, independent of which higher-level
// function (do_read, do_write, wait_for_knock, wait_for_data_read) is
// currently active.  If two peeks a few seconds apart show the exact same
// value here, the plugin's core (core 0) is not merely busy-looping
// somewhere - it has genuinely stopped running any code at all.
static volatile uint32_t s_debug_heartbeat;

// Bring-up diagnostic only: every matched knock's data, for reading back via
// `onerom inspect peek memory` instead of manually transcribing UART output
// (error-prone - single-character transcription slips, e.g. a stray '9' for
// a byte that can only ever be '0' or '1', are otherwise indistinguishable
// from a genuine mismatch).  session is which session this knock started -
// same numbering as s_debug_session_count once the caller increments it.
//
// TEMPORARILY REMOVED (2026-09) to free RAM budget for the checksum-error
// investigation's own instrumentation - see s_debug_sticky_already's own
// comment and the "~20-byte margin" note on init_data_bss() for why every
// byte here is contested.  Re-add once that investigation no longer needs
// the room: static volatile uint32_t s_debug_knock_session; static volatile
// uint8_t s_debug_knock_match_write; static volatile uint8_t
// s_debug_knock_match_read; static volatile uint8_t
// s_debug_knock_window[KNOCK_LEN]; plus the write-site in
// drivewire_wait_for_knock() (removed alongside, same reason).

// Bring-up diagnostic only: the byte count of the most recently *completed*
// write or read session (s_debug_main_phase says which kind), read back via
// peek instead of a UART dump - a UART dump here previously corrupted the
// live protocol on the wire (confirmed: a checksum error of exactly 0x0D0A,
// i.e. "\r\n", turned up server-side, matching this dump's own line prefix).
static volatile uint16_t s_debug_last_count;

// Set the instant a session's count byte is known, before drivewire_do_write()
// /drivewire_do_read() is even called - unlike s_debug_last_count above,
// this is visible while a session is still stuck in progress, to see what
// count a hung read/write was actually trying to handle.
static volatile uint16_t s_debug_current_count;

// Checksum of what drivewire_do_read() actually received over UART1 into
// s_read_buf, computed right after its own initial drain completes and
// before any of it is relayed to the CoCo - same add-with-carry algorithm as
// dwoneread.asm's DWRCODE.  Compares against the DriveWire server's own
// reported checksum to tell which half of the pipeline a mismatch is in:
// matching means the bug is in how this side relays s_read_buf to the CoCo
// over the ROM bus; not matching means the bug is upstream, in what UART1
// actually received.
static volatile uint16_t s_debug_received_checksum;

// Bring-up diagnostic only: a "sticky" copy of s_debug_received_checksum
// (plus which session it belongs to), latched only when count==256 - the
// sector-read case this investigation cares about.  s_debug_received_checksum
// itself gets overwritten by *any* read session, including the small 1-byte
// "get error code" read HREAD issues immediately after a checksum mismatch -
// by the time a peek lands, that follow-up (or the next thing after it) has
// usually already clobbered the value this needs to see.  This survives
// exactly those follow-up exchanges, so a peek only has to beat the *next*
// 256-byte read, not the next read of any size - a far more generous window.
static volatile uint16_t s_debug_sticky_received_checksum;
static volatile uint32_t s_debug_sticky_session;

// Bring-up diagnostic only: how many bytes were already sitting in
// s_read_buf from drivewire_next_addr()'s opportunistic pre-drain at the
// moment this session's own top-off loop is about to run - i.e. "already"
// itself, latched before that (blocking) drivewire_uart_getc() loop can run.
// Sticky and count==256-gated for the same reason as the checksum above:
// distinguishes a shortfall that already exists before topping off even
// starts (implicating UART1 reception or the pre-drain itself) from one that
// only appears after topping off completes without blocking (implicating
// something in how the completed buffer gets summed or relayed instead).
static volatile uint16_t s_debug_sticky_already;

// Bring-up diagnostic only: UART1's own receive-status flags (RSR - framing/
// parity/break/overrun, see UART_RSR_OE and friends in reg-rp235x.h), snapshot
// right after this session's own drain finishes, latched alongside the sticky
// checksum above (same count==256 gate, same reasoning for why it needs to be
// sticky).  RSR is cumulative and sticky in the hardware too - cleared once at
// the top of the main loop, before this session's knock-wait even starts (see
// that clear's own comment) - so a non-zero value here means UART1 flagged at
// least one of these errors somewhere between this session's knock and the
// end of its drain.  drivewire_uart_getc() and the opportunistic drain in
// drivewire_next_addr() both discard the PL011's per-byte error bits by
// casting UART_DR straight to uint8_t, so this is currently the only way to
// see that anything went wrong at the UART hardware level at all - a missing
// byte with no corresponding flag here means the loss did not happen there.
static volatile uint32_t s_debug_sticky_rsr;

// Bring-up diagnostic only, the write-session counterpart to
// s_debug_received_checksum above: what drivewire_do_write() actually
// forwarded to UART1 TX, captured as the ROM-bus relay puts each byte on the
// wire (not what the CoCo intended to send, which this side has no
// independent way to know) - same running-sum algorithm as
// drivewire_checksum() on the FujiNet side and dwoneread.asm's DWRCODE, so it
// is directly comparable against whatever the server reports back for a
// write it complains about (e.g. the 2-byte read-checksum echo in HREAD).
// The raw bytes matter as much as the sum here: a small write (the common
// case - an opcode+subcommand, or that same 2-byte echo) can be read back
// verbatim instead of just its sum, which pins down a single corrupted byte
// exactly rather than merely detecting that the sum is off.  Fixed-size and
// deliberately small: a longer write (e.g. OPEN_DIRECTORY's 259 bytes) only
// has its first few bytes captured, which is exactly as informative for
// spotting *whether* the relay corrupts something as capturing all of it
// would be - the open question here is root cause, not a full byte dump.
#define DEBUG_WRITE_BYTES 8u
static volatile uint8_t  s_debug_write_bytes[DEBUG_WRITE_BYTES];
static volatile uint16_t s_debug_write_byte_count;
static volatile uint16_t s_debug_write_checksum;

// ---------------------------------------------------------------------------
// UART1
// ---------------------------------------------------------------------------
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

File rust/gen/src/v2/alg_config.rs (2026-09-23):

// Copyright (C) 2026 Piers Finlayson <piers@piers.rocks>
//
// MIT License

//! Build the per-slot algorithm config (`OneromAlgConfig`) from
//! already-derived address/CS-data layouts.
//!
//! `build_alg_addr`/`build_alg_data`/`build_alg_dma` build the
//! corresponding sub-configs directly from the layouts. `build_alg_cs`
//! (in `alg_cs.rs`), the CS-polarity overrides (`cs_overrides.rs`), and
//! the GPIO pull config (`gpio_pull_config.rs`) are wired together by
//! `build_alg_config` below.
//!
//! `build_alg_config` takes `&AddrLayout`/`&CsDataLayout` rather than
//! deriving them itself, since `build_rom_slot` needs the same layouts for
//! `build_rom_info`'s pin maps - deriving once and sharing avoids doing the
//! (fallible) derivation twice. As a result `build_alg_config` itself is
//! infallible.
//!
//! `bit_mode` (chip0's *effective* bit mode, from `bit_mode_for`) and
//! `force_16_bit` are both computed once by `build_rom_slot` and passed
//! in - `bit_mode` is also needed by `derive_addr_layout` (for the A-1
//! carve-out), so computing it once and sharing avoids the two
//! disagreeing.

use onerom_config::chip::ChipType;
use onerom_config::hw::Board;

use onerom_metadata::{
    BitModes, GPIO_NONE, GpioOverride, OneromAlgAddrConfig, OneromAlgConfig, OneromAlgDataConfig,
    OneromAlgDmaConfig, OneromAlgOverrideConfig,
};

use crate::image::CsConfig;
use crate::v2::cs_overrides::encode_override;

use super::addr_layout::AddrLayout;
use super::alg_cs::build_alg_cs;
use super::alg_preference::{
    AddrAlgPreference, CombinedAlgPreference, CsAlgPreference, DataAlgPreference, DmaAlgPreference,
};
use super::cs_data_layout::CsDataLayout;
use super::cs_overrides::{
    build_cs_overrides, build_gpio_x_overrides, build_unused_addr_overrides,
};
use super::gpio_pull_config::build_gpio_pull_config;
use super::slot_context::SlotContext;

/// H: clock dividers default to 1.0 for now.
pub const DEFAULT_CLKDIV_INT: u16 = 1;
pub const DEFAULT_CLKDIV_FRAC: u8 = 0;

const ALG_DATA0_NUM_DELAY_CYCLES_8_BIT: u8 = 2;
const ALG_DATA1_NUM_DELAY_CYCLES_16_BIT: u8 = 4;

/// Determine the bit mode (8 vs 16) for serving `chip_type` on `board`.
///
/// 16-bit serving needs chip support for it, plus a board /BYTE pin where the
/// chip also has an 8-bit mode.
///
/// This is independent of `force_16_bit`: for a `BitMode16`-capable chip,
/// `rom_data_buf` is always `2^num_addr_pins * 2` bytes (one 16-bit word
/// per address-PIO table index) regardless of `force_16_bit` - that flag
/// only changes *how* the chip is served (`AlgData0` vs `AlgData1`, see
/// `build_alg_data`), not the table layout/contents.
pub fn bit_mode_for(chip_type: ChipType, board: Board) -> BitModes {
    let word_only = !chip_type.supports_bit_mode(8);
    if chip_type.supports_bit_mode(16) && (word_only || board.pin_byte() != GPIO_NONE) {
        BitModes::BitMode16
    } else {
        BitModes::BitMode8
    }
}

/// Whether serving reads the chip's /BYTE line (`AlgData1`), switching
/// between 8 and 16 bits as the host drives it.
///
/// False under `force_16_bit`, and for a chip with no 8-bit mode, which has
/// no /BYTE line: the 27C400Pin31A17 carries A17 on that pin, and reading it
/// as /BYTE would serve half the ROM 8-bit.
pub fn reads_byte_pin(chip_type: ChipType, bit_mode: BitModes, force_16_bit: bool) -> bool {
    matches!(bit_mode, BitModes::BitMode16) && chip_type.supports_bit_mode(8) && !force_16_bit
}
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

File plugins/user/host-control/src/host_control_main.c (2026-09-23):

// Copyright (C) 2026 Piers Finlayson <piers@piers.rocks>
//
// MIT License
//
// RBCP (ROM Bus Control Protocol) device-side plugin for One ROM.
//
// Implements the full RBCP device role, supporting both Command mode and
// Command-Response mode as defined by the RBCP specification.
//
// Knock sequence: "!RBCP!" (6 bytes, matched against A0-A7 only).
//
// In Command mode each knock initiates a single-command session with no
// back-channel.  In Command-Response mode a session spans from the knock
// through ENTER_CMD_RESP to an explicit exit command, with all responses
// written into the configured back-channel region of the active RAM slot.

// IMPORTANT NOTE: When running with PLUGIN_LOGGING enabled in the core
// firmware, the optimisation level of this plugin MUST be reduced.  It is
// though that -O2/-O3 causes more stack usage and hence blowing of the stack.

#include <stdint.h>
#include <stdbool.h>
#include "plugin.h"
#include "flash_erase.h"

#define RP235X
#define MCU_FLASH_SIZE_KB 2048
#define MCU_RAM_SIZE_KB 520
#define RP2350A
#include "onerom_metadata.h"
#include "reg-rp235x.h"

// ---------------------------------------------------------------------------
// Plugin header
// ---------------------------------------------------------------------------

// We do _not_ support yielding, as that would interfere with knock/byte detection.

// Define this plugin's attribues
void rbcp_main(
    ora_lookup_fn_t ora_lookup_fn,
    ora_plugin_type_t plugin_type,
    const ora_entry_args_t *entry_args
);
ORA_SECTION(".plugin_header")
const ora_plugin_header_t ora_plugin_header = {
    .magic    = ORA_PLUGIN_MAGIC,
    .api_version  = ORA_PLUGIN_VERSION_1,
    .major_version = MAJOR_VERSION,
    .minor_version = MINOR_VERSION,
    .patch_version = PATCH_VERSION,
    .build_version = BUILD_VERSION,
    .entry  = rbcp_main,
    .plugin_type = ORA_PLUGIN_TYPE_USER,
    .sam_usage = 255,
    .overrides1 = 0,
    .properties1 = 0,
    .min_fw_major_version = 0,
    .min_fw_minor_version = 7,
    .min_fw_patch_version = 1,
    .reserved = {0},
};

// ---------------------------------------------------------------------------
// Ring buffer
//
// To change between 8, 16 and 32 bit ring buffer entries change:
// - RING_DATA_SIZE
// - RING_BUF_TYPE
// - ORA_RING_BUF_DECLARE_*BIT to match RING_DATA_SIZE
// ---------------------------------------------------------------------------

#define RING_ENTRIES_LOG2   6u                               // 64 entries
#define RING_DATA_SIZE      32u                              // 32 bits per entry
#define RING_MASK           ((1u << RING_ENTRIES_LOG2) - 1u)
#define RING_BUF_TYPE       uint32_t                         // 32 bit entries
_Static_assert(sizeof(RING_BUF_TYPE) * 8 == RING_DATA_SIZE, "RING_BUF_TYPE must match RING_DATA_SIZE");

// Put the ring buffer in its own section, so it can be aligned at the start
// of the data region, meaning we maximise the stack space.
ORA_SECTION(".ring_buf")
ORA_RING_BUF_DECLARE_32BIT(ring_buf, RING_ENTRIES_LOG2);

#define RING_BUF_CUR_READ_INDEX()   s_read_idx
#define RING_BUF_ADV_READ_INDEX()   s_read_idx = (s_read_idx + 1u) & RING_MASK
#define RING_BUF_UPDATE_READ_INDEX(X) \
    s_read_idx = (uint32_t)((volatile RING_BUF_TYPE *)(X) - \
                            (volatile RING_BUF_TYPE *)ring_buf) & RING_MASK
#define RING_BUF_RESET_READ_INDEX() RING_BUF_UPDATE_READ_INDEX(*s_write_pos_ptr)
#define RING_BUF_CUR_WRITE_INDEX() \
    ((uint32_t)((volatile RING_BUF_TYPE *)*s_write_pos_ptr - \
                (volatile RING_BUF_TYPE *)ring_buf) & RING_MASK)
#define RING_BUF_GET_ENTRY(X) ((volatile RING_BUF_TYPE *)ring_buf)[(X)]

// Statics used to track ring buffer state.
static volatile uint32_t * volatile *s_write_pos_ptr; // pointer to DMA write pointer (volatile: DMA hardware updates the register)
static uint32_t            s_read_idx;      // our read index, kept masked

// ---------------------------------------------------------------------------
// Knock sequence: "!RBCP!"
// ---------------------------------------------------------------------------

#define KNOCK_LEN  6u
static const uint32_t s_knock_seq[KNOCK_LEN] = {
    '!', 'R', 'B', 'C', 'P', '!'
};

// ---------------------------------------------------------------------------
// Protocol constants
// ---------------------------------------------------------------------------

#define RBCP_PROTOCOL_VERSION_MAJOR 0u
#define RBCP_PROTOCOL_VERSION_MINOR 1u
#define RBCP_PROTOCOL_VERSION_PATCH 2u
const uint8_t protocol_version[4] = {
    RBCP_PROTOCOL_VERSION_MAJOR,
    RBCP_PROTOCOL_VERSION_MINOR,
    RBCP_PROTOCOL_VERSION_PATCH,
    0u
};

#define RBCP_DEFAULT_COMPLETE   ((uint8_t)0xBBu)
#define RBCP_DEFAULT_STATUS_OK  ((uint8_t)0xCCu)

// Response header byte offsets within the back-channel region
#define HDR_LAST_CMD_GROUP  0u
#define HDR_LAST_CMD_CMD    1u
#define HDR_TOKEN_LSB       2u
#define HDR_TOKEN_MSB       3u
#define HDR_PROGRESS        4u
#define HDR_RESPONSE        5u
#define HDR_RESERVED_0      6u
#define HDR_RESERVED_1      7u
#define HDR_SIZE            8u

// Command groups
#define GRP_CONTROL     0x00u
#define GRP_READ        0x01u
#define GRP_MODIFY      0x02u
#define GRP_NV_STORAGE  0x03u
#define GRP_PIPES       0x04u
#define GRP_AUX         0x05u
#define GRP_LED         0x06u
#define GRP_RESET       0xAAu

// Control commands
#define CMD_NOP                         0x00u
#define CMD_ENTER_CMD_RESP              0x01u
#define CMD_EXIT_CMD_RESP_ACK           0x02u
#define CMD_EXIT_CMD_RESP_SILENT        0x03u
#define CMD_SWITCH_AND_EXIT             0x04u
#define CMD_LOAD_AND_EXIT               0x05u
#define CMD_EXIT_CMD_RESP_RESTORE       0x06u

// Most bytes EXIT_CMD_RESP_RESTORE can put back, and so the largest valid
// count.  Fixed by the protocol at eight, the size of the response header,
// which is the part of the region the device always writes.
#define RESTORE_MAX_BYTES               8u

// Read commands
#define CMD_GET_FLASH_FLASH_SLOT_COUNT  0x00u
#define CMD_GET_FLASH_SLOT_INFO         0x01u
#define CMD_GET_FLASH_SLOT_INFO_ALL     0x02u
#define CMD_GET_RAM_SLOT_INFO_ALL       0x03u
#define CMD_GET_DEVICE_TYPE             0x04u
#define CMD_GET_DEVICE_VERSION          0x05u
#define CMD_GET_PROTOCOL_VERSION        0x06u
#define CMD_SLOT_PEEK                   0x07u
#define CMD_GET_BOOT_SLOT_INFO          0x08u

// Modify commands
#define CMD_SLOT_POKE                   0x00u
#define CMD_SWITCH_SLOT                 0x01u
#define CMD_LOAD_SLOT                   0x02u
#define CMD_SLOT_POKE_ALL_BYTE          0x03u

// NV Storage commands
#define CMD_GET_NV_CAPABILITY             0x00u
#define CMD_NV_PEEK                     0x01u
#define CMD_NV_POKE_BEGIN               0x02u
#define CMD_NV_POKE                     0x03u
#define CMD_NV_POKE_COMMIT              0x04u
#define CMD_NV_POKE_DISCARD             0x05u
#define CMD_NV_POKE_COMMIT_BYTE         0x06u
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

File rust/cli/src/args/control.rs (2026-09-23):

// Copyright (C) 2026 Piers Finlayson <piers@piers.rocks>
//
// MIT License

//! Argument definitions for `onerom control`.

use crate::args::CommandTrait;
use crate::utils::{
    parse_beacon_period, parse_blink_period, parse_breathe_period, parse_brightness,
    parse_cycle_period, parse_flame_period, parse_gpio_hold_ms, parse_hold_ms, parse_u8, parse_u32,
};
use clap::{ArgGroup, Args, Subcommand, ValueEnum};
use enum_dispatch::enum_dispatch;

use onerom_cli::colour::{RgbColour, parse_colour};
use onerom_cli::pin::{Pin, parse_pin};
use onerom_cli::usb::{GpioState as WireGpioState, RebootArgs};
use onerom_metadata::GPIO_RESET_DEFAULT_HOLD_MS;

#[derive(Debug, Args)]
pub struct ControlArgs {
    #[command(subcommand)]
    pub command: ControlCommands,
}

impl CommandTrait for ControlArgs {
    fn requires_device(&self) -> bool {
        self.command.requires_device()
    }
}

#[enum_dispatch(CommandTrait)]
#[derive(Debug, Subcommand)]
pub enum ControlCommands {
    /// Reboot the One ROM.
    ///
    /// Restarts the One ROM firmware. The device will re-initialise and
    /// resume serving ROM images after the reboot.
    ///
    /// By default, this command pauses after a reboot to give the device time
    /// to re-enumerate.
    ///
    /// Example:
    ///
    ///   onerom control reboot
    Reboot(ControlRebootArgs),

    /// Control the status LED on a One ROM.
    ///
    /// Examples:
    ///
    ///   onerom control led on
    ///
    ///   onerom control led off
    #[command(
        subcommand_value_name = "COMMAND",
        subcommand_help_heading = "Commands"
    )]
    Led(ControlLedArgs),
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

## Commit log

2026-08-27 Mark the address monitor's DMA channel high priority
    Guards against a sustained burst of ROM reads elsewhere - e.g. a
    target CPU's own boot sequence - starving it of AHB grants long
    enough to overflow its 4-deep RX FIFO and silently drop captures.
2026-08-27 Add DriveWire bridge plugin
    Bridges a CoCo/Dragon DriveWire session to a real DriveWire server
    over One ROM's RP2350 UART1, signalling knock/count/data over the
    ROM address bus. Companion hdbdos changes live in the separate
    hdbdos repository.
2026-08-28 Add fault-handler UART diagnostics and a UART1 bring-up test
    HardFault/BusFault/UsageFault/Default handlers now dump CFSR/HFSR/
    MMFAR/BFAR (plus PC and callee-saved registers for HardFault) over
    UART1 before blinking.
    UART_BOOT_TEST=1 isolates UART1 bring-up from ROM serving and plugin
    launch, for bring-up debugging with a scope.
2026-09-06 Add UART1 receive diagnostics to the DriveWire plugin
    - Sticky per-256-byte-read snapshot (checksum, RSR, pre-drain count)
    that survives the small follow-up sessions HREAD issues after a
    checksum error, plus a write-session byte/checksum capture
    - Drops the now-unused knock bring-up fields to make room in the
    plugin's ~1KB RAM budget
    [drivewire_main.c]
2026-09-06 Give the DriveWire plugin a receive timeout and a 16-bit session count
    - drivewire_uart_getc() now times out instead of blocking core 1
    forever when FujiNet stops responding, which previously needed a
    full One ROM power cycle to recover from
    - The knock's count field is now 16-bit (high byte first), fixing
    OPEN_DIRECTORY's 259-byte payload silently truncating to a 3-byte
    count and permanently desyncing the session; reads stay capped at
    sizeof(s_read_buf), which can't grow to match the new range
    [drivewire_main.c]
2026-09-11 Add a "!LDCART!" knock to load and boot a cart image via DriveWire
    - CoCo/Dragon-side callers send "!LDCART!" over the ROM bus; this plugin
    asks FujiNet to push the mounted cart image over a SLIP-framed DBC
    side channel on UART1, into a dedicated RAM slot, then atomically
    switches to it.
    - Fix a UART1 init hang at non-stock clock speeds: settle clk_peri
    before waiting on UART1's RESET_DONE, which synchronises through it.
    [drivewire_main.c]
2026-09-23 Fix DriveWire's UART1 pad names: SEL_C/SEL_D, not SEL_A/SEL_B
    Verified against the fire-28-c schematic/PCB netlist and a working
    cable: GPIO40/41 are the SEL_C/SEL_D pads, not SEL_A/SEL_B.
    [drivewire_main.c]
2026-09-23 Add copyright line for modifications to the DriveWire plugin
    Both files carry substantial changes on top of Piers Finlayson's
    original authorship - per his note on issue #311.
    [drivewire_main.c]
2026-10-09 Update FujiNet/Centipede ROM protocol handoff: ESP32 side done
2026-10-09 Update FujiNet/Centipede ROM protocol handoff: first end-to-end test results
    Found and fixed a checksum regression in drivewire_do_write() (ack-byte
    restore was delayed past the push-check peek). Found, not yet fixed: the
    push itself never arrives when triggered by a mount command - the
    companion's push-detection window doesn't cover the file-open latency
    between the mount command and the push actually starting.
2026-10-26 DriveWire 1.2.1: fix CoCo 3 cart loading, faster cold boot
    Cap the read heartbeat at 1.5s without ESP32 traffic, and drop the
    bring-up instrumentation from the checksum investigation.
    Verified on a CoCo 2 and a CoCo 3: cold boot, cart load, disk load.
2026-10-29 DriveWire: block reads, and recovery from lost reply bytes
    Hand each read reply to the CoCo as one 256-byte window it copies with
    PULU/PSHS, replacing the per-byte handshake. Drain the whole UART FIFO
    each pass, record UART receive errors, retry a reply that stalls part
    way, and settle an open cart-push probe before a read starts.
    Needs the matching HDB-DOS ONEROM dwoneread.asm.
    Verified on a CoCo 3 at 5 Mbps: Config app switching, weather.dsk from a remote TNFS server.
2026-10-29 DriveWire 1.3.0: block reads at 5 Mbps
    Default UART1 to 5 Mbps, and drop the TEST_PATTERN bring-up build,
    which no longer compiled.
    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

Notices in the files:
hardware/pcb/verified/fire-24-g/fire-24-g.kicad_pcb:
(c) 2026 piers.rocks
